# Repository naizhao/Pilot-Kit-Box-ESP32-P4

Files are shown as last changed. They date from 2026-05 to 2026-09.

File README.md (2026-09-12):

# Pilot Kit Box (ESP32-P4 Edition)

<p align="center">
  <strong>开源低成本飞行数据盒子与态势感知设备 | Open-source low-cost flight data box and situational-awareness device</strong><br>
  官方网站 / Official website: <a href="https://air.club">air.club</a><br>
  网页刷机 / Web flasher: <a href="https://updater.pilotkit.app">updater.pilotkit.app</a>
</p>

> ## ⚠️ 免责声明 / Disclaimer
>
> 本设备及其固件为**辅助信息工具**，未取得任何适航认证，**不得用作主用或备用
> 导航设备**，也不得用于正式的飞行活动。所显示的位置、高度、航向、交通、
> 导航台和气象等信息可能延迟、错误或缺失，且随时可能中断。一切飞行决策必须
> 以认证机载设备、官方航图与空管指令为准。使用者自行承担全部风险。
>
> This device and its firmware are an **auxiliary information tool only**.
> They are not airworthiness certified and **must not be used as a primary or
> backup navigation source**, nor in any operational flight activity. Position,
> altitude, heading, traffic, navaid and weather information may be delayed,
> incorrect, or missing, and may stop without warning. All flight decisions
> must be based on certified avionics, official charts, and ATC instructions.
> Use entirely at your own risk.

> **分支 `v4`。** 主机是 **Waveshare ESP32-P4-WIFI6-Touch-LCD-4.3** 一体板：
> ST7701 480×800 MIPI-DSI 面板以 PPA 旋转成 800×480 横屏，GT911 触摸，
> P4NRW32 + ESP32-C6。硬件目标是
> [`hardware/expansion-board-v4/`](hardware/expansion-board-v4/) 的 6 层集成
> 扩展板——以 HAT 方式直插载板 2×20 排母，把 1090/978 接收链、GNSS、IMU、
> 气压计和电源整合到一块板上，**自带 1090 接收链，不再需要 RTL-SDR dongle**。
> 每个硬件版本一个分支；`docs/jlc/lcd-2.4in-8pin/` 与下文 2.4 寸载板内容
> 保留为 v0.8.0 历史 PCB 参考，不代表本分支的当前接线。
>
> **Branch `v4`.** Host board: **Waveshare ESP32-P4-WIFI6-Touch-LCD-4.3**.
> The hardware target is the 6-layer integrated expansion board in
> [`hardware/expansion-board-v4/`](hardware/expansion-board-v4/), which stacks
> onto the carrier's 2×20 header and folds the 1090/978 receive chains, GNSS,
> IMU, barometer, and power onto one board — **no RTL-SDR dongle required**.
> One branch per hardware revision.

## 硬件版本与分支 / Hardware Versions & Branches

项目包含**硬件（扩展板）**与**软件（固件）**两条相互独立的版本线：

- **硬件**按板代走分支：`v1` → `v2` → `v3` → `v4`，每代一个分支；
- **固件**按发布标签走：`v0.5.0` / `v0.6.0` / `v0.8.0`（见 Releases），
  在任何硬件分支上发布，与板代无关。

The project has **two independent version lines**: the **hardware (expansion
boards)** evolves through branches `v1` → `v2` → `v3` → `v4` (one branch per
board generation), while the **firmware** releases via tags `v0.5.0` /
`v0.6.0` / `v0.8.0` (see Releases), cut from whichever hardware branch.

### 四代扩展板 / Four Generations

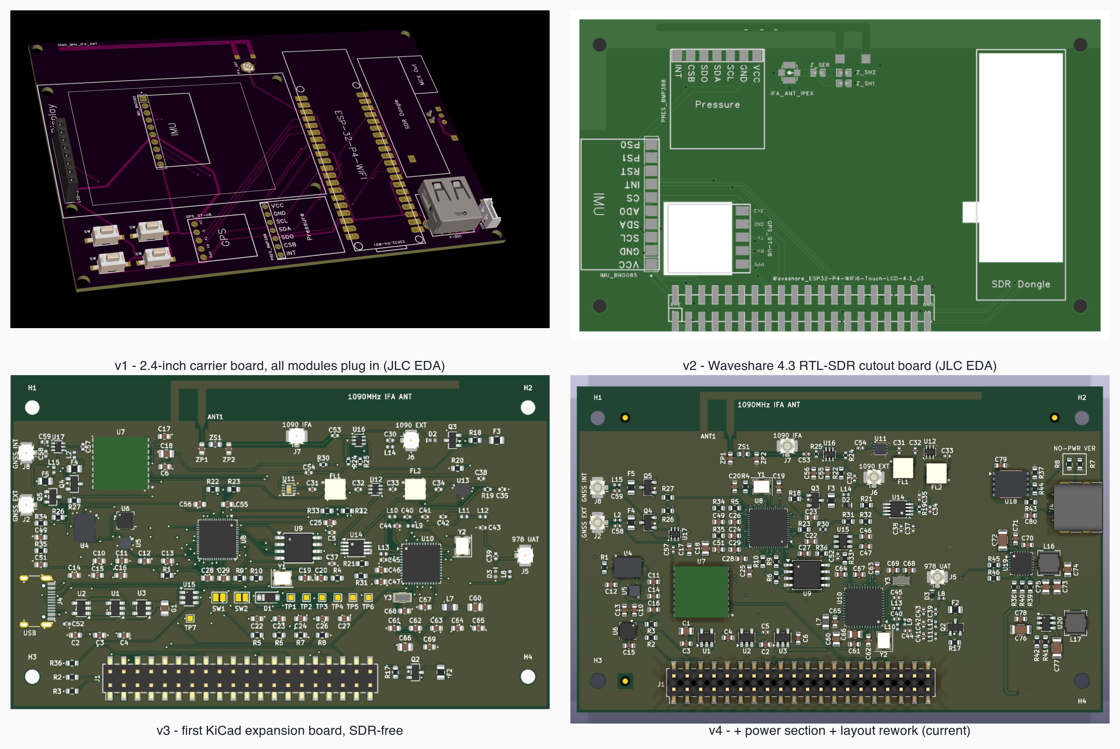
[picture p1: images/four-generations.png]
Pilot Kit Box 扩展板四代同堂：v1 2.4寸大板、v2 Waveshare 4.3 SDR RTL 镂空板、v3 首个 KiCad 完整扩展板、v4 加电源版


每个硬件版本一个分支，从旧到新 / One branch per hardware revision, oldest first:

| 分支 Branch | 板子 / Board | EDA | 说明 / Notes |
|---|---|---|---|
| [`v1`](https://github.com/naizhao/Pilot-Kit-Box-ESP32-P4/tree/v1) | 2.4 寸大板：所有模块插在板上，含板载 1090 天线版 / 2.4-inch carrier, all modules plug in, on-board 1090 antenna revision | 嘉立创 EDA | 与 `main` 同源（v0.8.0 时代）/ same lineage as `main` (v0.8.0 era) |
| [`v2`](https://github.com/naizhao/Pilot-Kit-Box-ESP32-P4/tree/v2) | 微雪 4.3 屏配套的 SDR RTL 镂空板 / RTL-SDR cutout board for the Waveshare 4.3 | 嘉立创 EDA | 归档：仅打样 Gerber + 说明，EDA 源不在 git / archive: fabrication Gerbers only, EDA sources not in git |
| [`v3`](https://github.com/naizhao/Pilot-Kit-Box-ESP32-P4/tree/v3) | 脱离 SDR 的完整扩展板（KiCad、expansion-board 命名起点）/ SDR-free integrated expansion board (KiCad, where the expansion-board naming starts) | KiCad | 归档：只维护 v3 硬件，不携带 v4 / archived: v3 hardware only |
| [`v4`](https://github.com/naizhao/Pilot-Kit-Box-ESP32-P4/tree/v4) | v3 + 电源部分 + 布局优化（当前硬件目标）/ v3 plus power section and layout rework (current target) | KiCad | **本分支 / this branch**；公开区只留最终结果 / public tree keeps final results only |

## 项目概览 / Overview

**Pilot Kit Box** 是一个开源、低成本、便携式的飞行数据盒子和航空态势感知设备，可与 [Pilot Kit](https://air.club) 深度结合使用，也可以作为独立设备运行。

如果你熟悉 Stratux、Sentry、Garmin GDL 系列或 uAvionix ping 这类便携式 ADS-B / 飞行数据盒子，可以把 Pilot Kit Box 理解成一个更开放、更低成本、可自己搭建和二次开发的替代方案。它面向飞行员、飞行学员、飞行爱好者以及通航开发者，用常见硬件完成飞行记录、姿态显示、周边交通接收和后续数据分析。

它的核心价值不是单纯“看天上有哪些飞机”，而是帮助用户低成本记录、理解和管理自己的飞行数据。它可以随飞机一起使用，记录每一次飞行中的关键数据，用于飞行日志、回放、分享和分析；也可以接收附近飞机公开广播的 ADS-B / Mode-S 信号，在本机屏幕上显示周边交通信息。

你可以把它理解成一个“飞行员自己的小型数据记录与接收盒子”：它既能独立工作，也能和 Pilot Kit 紧密结合；并已支持通过标准航空数据格式（GDL90 over BLE）与 Garmin Pilot、ForeFlight 等第三方 EFB 软件配合使用。

Pilot Kit Box can work as a standalone device or integrate closely with [Pilot Kit](https://air.club). If you know products such as Stratux, Sentry, Garmin GDL, or uAvionix ping, Pilot Kit Box is best understood as a more open, lower-cost, builder-friendly flight data and ADS-B box. It is intended for pilots, student pilots, aviation enthusiasts, and general-aviation developers who want local flight recording, attitude display, nearby traffic reception, and data they can later review or share.

The main point is not just watching aircraft overhead. Pilot Kit Box is meant to help users record, understand, and manage their own flying at a much lower cost. It can record each flight for logs, replay, sharing, and analysis; it can also receive public ADS-B / Mode-S broadcasts from nearby aircraft and show surrounding traffic on the built-in display.

Think of it as a pilot's own small flight data recorder and receiver: it can run independently, integrate tightly with Pilot Kit, and already speaks standard aviation data (GDL90 over BLE) for third-party EFB apps such as Garmin Pilot and ForeFlight.

## 使用场景 / Use Cases

Pilot Kit Box 的核心用途是：让普通飞行员、飞行学员和飞行爱好者，也能用较低成本拥有一个自己的飞行记录和态势感知盒子。

Pilot Kit Box is designed to give pilots, student pilots, and aviation enthusiasts an affordable personal flight recording and situational-awareness box.

- 记录自己的每一次飞行，为飞行日志、回放、分享和分析提供数据基础。<br>Record each flight as source data for logs, replay, sharing, and analysis.
- 在本机屏幕上显示姿态、航向、高度、速度、垂直速度等飞行状态信息。<br>Display flight state such as attitude, heading, altitude, speed, and vertical speed on the local screen.
- 接收附近飞机的 ADS-B / Mode-S 广播，显示周边交通、航班号、国家、航司、机型和注册号等信息。<br>Receive nearby ADS-B / Mode-S traffic and show callsign, country, airline, aircraft type, and registration when known.
- 在没有互联网的情况下，本地接收和记录航空数据，而不是依赖在线航班网站。<br>Receive and record aviation data locally without relying on online flight-tracking websites.
- 与 Pilot Kit 软件结合，把硬件采集到的数据用于更完整的飞行记录、回放、分析和分享体验。<br>Use captured device data with Pilot Kit for richer flight records, replay, analysis, and sharing.
- 作为通用飞行数据盒子继续扩展；GDL90 已通过 BLE 输出（Ownship / Traffic / Heartbeat / Raw），Wi-Fi GDL90 在路线图中，目标是连接 Garmin Pilot、ForeFlight 等 EFB。<br>Continue evolving as a general-purpose flight data box; GDL90 already ships over BLE (ownship / traffic / heartbeat / raw), with Wi-Fi GDL90 on the roadmap targeting EFBs such as Garmin Pilot and ForeFlight.
- 给通航、航电、嵌入式和 SDR 爱好者提供一个完整、开源、可学习的参考实现。<br>Provide a complete open-source reference for general aviation, avionics, embedded systems, and SDR builders.

## 为什么要做这个设备 / Why Build This

市面上已经有 Stratux、Sentry、Garmin GDL、uAvionix ping 等便携式 ADS-B 接收器、飞行记录盒子和通航辅助设备，但很多产品要么价格较高，要么生态相对封闭，要么不方便用户理解、修改和扩展内部的数据链路。

Pilot Kit Box 想解决的是这个问题：

- **低成本**：用 ESP32-P4、v3/v4 扩展板（自带 1090 接收链，无需 RTL-SDR dongle）、屏幕、IMU 和常见电源模块，做出一个普通用户也能负担的飞行数据盒子。
- **通用性**：它不是只能配合某一个 App 使用的封闭硬件；它可以独立使用，也可以面向标准航空数据接口继续扩展。
- **与 Pilot Kit 紧密结合**：Pilot Kit 可以充分利用 Box 采集的数据，提供更完整的飞行记录、回放、分析和分享能力。
- **本地记录**：飞行数据可以在设备本地记录，为飞行复盘和个人飞行档案提供基础。
- **态势感知**：除了记录自己的飞行，也能接收附近 ADS-B / Mode-S 交通，帮助理解周边空域情况。
- **开源透明**：从 SDR 接收、ADS-B 解码、状态聚合、屏幕显示到数据库维护，整个链路都可以检查、修改和复现。
- **可继续扩展**：它可以是一个低成本替代方案，也可以作为移动端、云端分析、EFB 集成、Wi-Fi GDL90 输出和硬件外壳迭代的平台。

Portable ADS-B receivers and flight data boxes already exist, including Stratux, Sentry, Garmin GDL, and uAvionix ping. Many of them are effective products, but they can be expensive, relatively closed, or hard for users to inspect, modify, and extend.

Pilot Kit Box focuses on:

- **Low cost**: ESP32-P4, the v3/v4 expansion board (its own 1090 MHz receive chain — no RTL-SDR dongle), display, IMU, and common power modules keep the hardware approachable.
- **General-purpose use**: it is not locked to one app; it can run on its own and already speaks standard aviation data interfaces (GDL90).
- **Tight Pilot Kit integration**: Pilot Kit can use Box data for richer flight records, replay, analysis, and sharing.
- **Local recording**: flight data can be recorded on the device for review and personal archives.
- **Situational awareness**: the same box can receive nearby ADS-B / Mode-S traffic and help users understand surrounding airspace.
- **Open implementation**: SDR reception, ADS-B decoding, state fusion, display rendering, and database maintenance are all inspectable and reproducible.
- **Room to grow**: it can be a low-cost alternative today and a platform for mobile apps, cloud analysis, EFB integration, Wi-Fi GDL90 output, and enclosure iterations later.

## 技术概览 / Technical Overview

当前 ESP32-P4 版本把传统依赖 Linux 板卡的 ADS-B 接收链路压缩到单片机 + RTOS 架构。1090 MHz 接收由 **v3/v4 扩展板**完成：板载接收链（QPL9547 LNA + TA0970A SAW + AD8313 对数检波 + TLV3501 比较器）把脉冲馈给 RP2040，RP2040 以 PIO+DMA 捕获双沿、重建 56/112-bit Mode-S 帧，再经 921600 UART 送 ESP32-P4 做 CRC 过滤、CPR 定位融合、飞机状态聚合，并通过 BLE GATT、串口以及 LittleFS / MicroSD 文件输出给移动端或调试工具。（早期 v1/v2 载板走 P4 原生 USB 2.0 HS 驱动 RTL-SDR dongle 的路径已退役，固件与组件树均不再包含该代码。）

The ESP32-P4 edition removes the Linux SBC from the ADS-B path. The 1090 MHz receive chain lives on the **v3/v4 expansion boards**: the onboard chain (QPL9547 LNA + TA0970A SAW + AD8313 log detector + TLV3501 comparator) feeds pulses to an RP2040, which captures dual edges via PIO+DMA, rebuilds 56/112-bit Mode S frames, and ships them to the ESP32-P4 over a 921600-baud UART for CRC filtering, CPR position fusion, and per-aircraft state aggregation, published over BLE GATT, serial output, and LittleFS or MicroSD logs. (The early v1/v2-carrier path — the P4 driving an RTL-SDR dongle over native USB 2.0 HS — is retired; neither the firmware nor the component tree still carries it.)

## 安全与适航边界 / Safety And Certification Boundary

Pilot Kit Box 是开源原型和态势感知设备，当前仓库没有 FAA、EASA、CAAC 或其他适航/TSO 认证。它不能作为主飞行仪表、备用飞行仪表、导航源或防撞系统使用；任何飞行决策必须以认证航电、机载仪表、目视观察和适用法规为准。

Pilot Kit Box is an open-source prototype and situational-awareness device. This repository does not represent FAA, EASA, CAAC, TSO, or other airworthiness certification. Do not use it as a primary flight instrument, backup flight instrument, navigation source, or collision-avoidance system; flight decisions must remain based on certified avionics, installed instruments, visual scan, and applicable regulations.

## 当前状态 / Current Status

截至 **2026-07-29**，当前 4.3 寸固件已经覆盖 ADS-B 接收与解码、BLE
GDL90 分发、GPS 定位与 RMC 授时、BMP388 气压高度、LittleFS/MicroSD
记录、ST7701 MIPI-DSI 横屏显示、GT911 触摸导航、交通雷达、ADS-B 列表、
实时诊断、本地航空识别数据库和 BNO085 姿态融合。

As of **2026-07-29**, the current 4.3-inch firmware includes ADS-B reception
and decode, BLE GDL90 distribution, GPS positioning and RMC time sync,
BMP388 barometric altitude, LittleFS/MicroSD recording, an ST7701 MIPI-DSI
landscape display, GT911 touch navigation, traffic radar, ADS-B list, live
diagnostics, local aviation identity databases, and BNO085 attitude fusion.

### `v0.8.0` 发布重点 / Release Highlights

- 新增 360° 交通雷达、PFD HSI 前方交通叠加和统一 own-ship 航向决策。<br>Adds the 360-degree traffic radar, forward-traffic HSI overlay, and unified own-ship heading selection.
- 新增 BMP388 气压高度/升降率、可调 QNH，以及可滚动实时 DIAG 页面。<br>Adds BMP388 altitude/vertical speed, adjustable QNH, and the scrollable live DIAG page.
- 增强 GT-U8 GPS/北斗诊断和 RMC 授时，并通过 BLE 输出 GDL90 Ownship Report；GPIO50 PPS 已被固件消费，用于时间锁定判定（fix 有效 + PPS <2 s + NMEA <5 s）；把该新鲜度接入生产时间服务仍是后续任务。<br>Expands GT-U8 GPS/BeiDou diagnostics, RMC time sync, and BLE GDL90 Ownship Report output; GPIO50 PPS is now consumed for the time-lock status (valid fix + PPS <2 s + NMEA <5 s); wiring that freshness into the production time service remains a follow-up.
- 新增 MicroSD 探测、Flash/MicroSD 日志切换、约 1 GiB 轮转保留和受保护格式化。<br>Adds MicroSD detection, Flash/MicroSD log selection, about 1 GiB rotation retention, and guarded formatting.
- 完成 2.4 寸载板、板载 1090 MHz IFA 天线、3D 打印外壳和面板原型实物验证。<br>Documents the fabricated 2.4-inch carrier, on-board 1090 MHz IFA antenna, printed enclosure, and faceplate prototype.

## 核心特性 / Features

| 功能 | Feature | 状态 / Status |
|---|---|---|
| ESP32-P4 + FreeRTOS 固件，无 Linux 启动链路 | ESP32-P4 + FreeRTOS firmware, no Linux boot chain | 已实现 / Implemented |
| RP2040 拓展板双沿捕获 1090 MHz ADS-B，921600 UART 送 P4 解码（USB RTL-SDR 路径已退役） | RP2040 add-on dual-edge capture of 1090 MHz ADS-B, raw frames to the P4 over 921600-baud UART (USB RTL-SDR path retired) | 已实现 / Implemented |
| `adsb_lnk` 任务：921600 UART 收 RP2040 帧、CRC 过滤后进 CPR/融合与记录链 | `adsb_lnk` task: RP2040 frames over 921600-baud UART, CRC-filtered into the CPR/fusion and recording chain | 已实现 / Implemented |
| dump1090 派生 Mode-S 解码、CRC 过滤、CPR 全球定位 | dump1090-derived Mode-S decode, CRC filtering, CPR global position decode | 已实现 / Implemented |
| 最多同时跟踪 64 个 ADS-B / Mode-S 目标，并聚合呼号、高度、位置、速度、垂直速度、应答机码和机型信息 | Tracks up to 64 ADS-B / Mode-S targets at once, aggregating callsign, altitude, position, velocity, vertical rate, squawk, and aircraft type | 已实现 / Implemented |
| UART、LittleFS / MicroSD 轮转文件、BLE raw ts-line 三路记录输出 | UART, rotating LittleFS/MicroSD files, and BLE raw ts-line output | 已实现 / Implemented |
| BLE GATT：GDL90 Ownship、Traffic、Heartbeat、Raw、Time Sync | BLE GATT: GDL90 Ownship, Traffic, Heartbeat, Raw, and Time Sync | 已实现 / Implemented |
| iOS Current Time Service 自动校时，Android/跨平台可写 Time Sync | iOS Current Time Service auto-sync, Android/cross-platform Time Sync writes | 已实现 / Implemented |
| GT-U8 GPS / 北斗定位、RMC 授时、GPS own-ship 兜底 | GT-U8 GPS/BeiDou positioning, RMC time sync, GPS own-ship fallback | 已实现；PPS 已接入时间锁定 / Implemented; PPS consumed for time-lock status |
| BMP388 气压高度和升降率，QNH 可调 | BMP388 barometric altitude and vertical speed with adjustable QNH | 已实现 / Implemented |
| ST7701 480×800 MIPI-DSI 面板，PPA 转为 800×480 横屏，双 DPI buffer | ST7701 480×800 MIPI-DSI panel, PPA-transformed to 800×480 landscape with dual DPI buffers | 已实现 / Implemented |
| G1000 风格 PFD：姿态、航向/HSI、高度带、GS/VS、ADS-B 数量 | G1000-style PFD: attitude, heading/HSI, altitude tape, GS/VS, ADS-B count | 已实现 / Implemented |
| 360° 交通雷达：航向朝上/北向上、2/5/10/20 NM、目标选择和相对高度 | 360° traffic radar: heading-up/north-up, 2/5/10/20 NM, target selection, relative altitude | 已实现 / Implemented |
| PFD HSI 前方交通叠加和后方目标计数 | Forward-traffic overlay and aft-target count on the PFD HSI | 已实现 / Implemented |
| ADS-B 列表页：ICAO、呼号、国家、ALT、SPD、HDG、VS、SQK、TYPE 和详情面板 | ADS-B list page: ICAO, callsign, country, ALT, SPD, HDG, VS, SQK, TYPE, and detail pane | 已实现 / Implemented |
| 本地航空识别数据库：航司 ICAO/IATA、运营人名称、ICAO24 国家、注册号、机型和型号 | Local aviation identity databases: airline ICAO/IATA, operator name, ICAO24 country, registration, type, and model | 已实现 / Implemented |
| BNO085 100 Hz 姿态融合、校准向导和导航网格长按“调平”持久化 | BNO085 100 Hz attitude fusion, calibration wizard, and persistent nav-grid Level action | 已实现 / Implemented |
| Settings / About / Diagnostics / Compass Calibration 中英文 UI，配置写入 NVS | English/Chinese Settings, About, Diagnostics, and Compass Calibration UI with NVS persistence | 已实现 / Implemented |
| Noto Sans SC 字形生成、中文 LCD 锐化曲线、英文硬像素路径 | Noto Sans SC glyph generation, sharpened CJK LCD alpha curve, crisp English bitmap path | 已实现 / Implemented |
| GT911 触摸 FAB 打开全屏导航网格直接切页（两页 10 项可翻页），FAB 可拖动记忆，详情页三路返回 | GT911 touch FAB opens a full-screen nav grid (10 items on two swipeable pages), remembers FAB position, and provides three detail-page back paths | 已实现 / Implemented |
| RP2040 链路健康监测：HELLO 心跳、链路停滞检测，诊断页显示收帧/坏 CRC | RP2040 link health: HELLO heartbeat and stalled-link detection; the diag page shows link rx/bad-CRC | 已实现 / Implemented |

## 硬件清单 / Hardware Bill of Materials

### 硬件预览 / Hardware Preview

| PFD / Primary Flight Display | ADS-B LIST / Aircraft List |
|---|---|
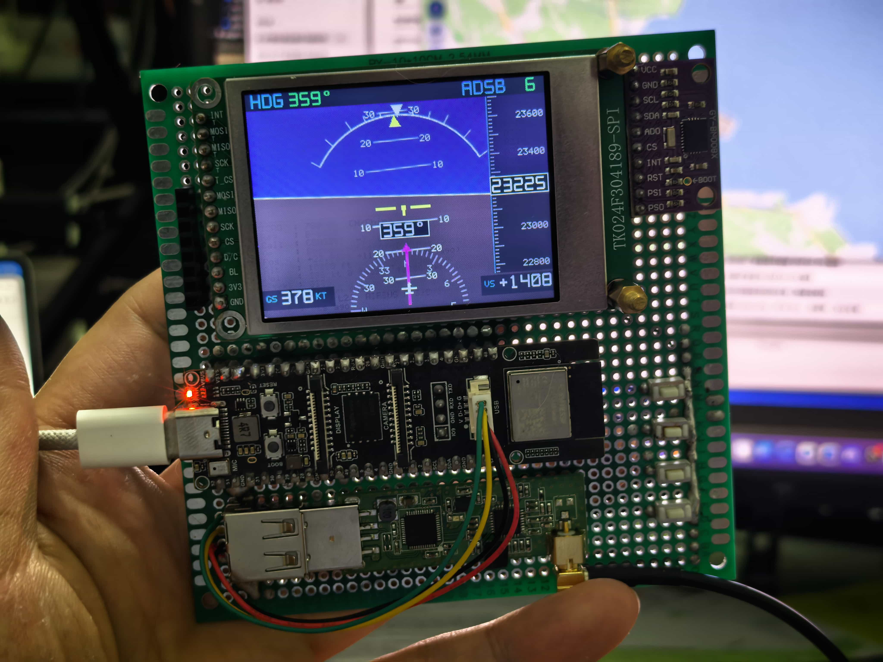
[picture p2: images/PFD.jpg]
Pilot Kit Box PFD hardware preview
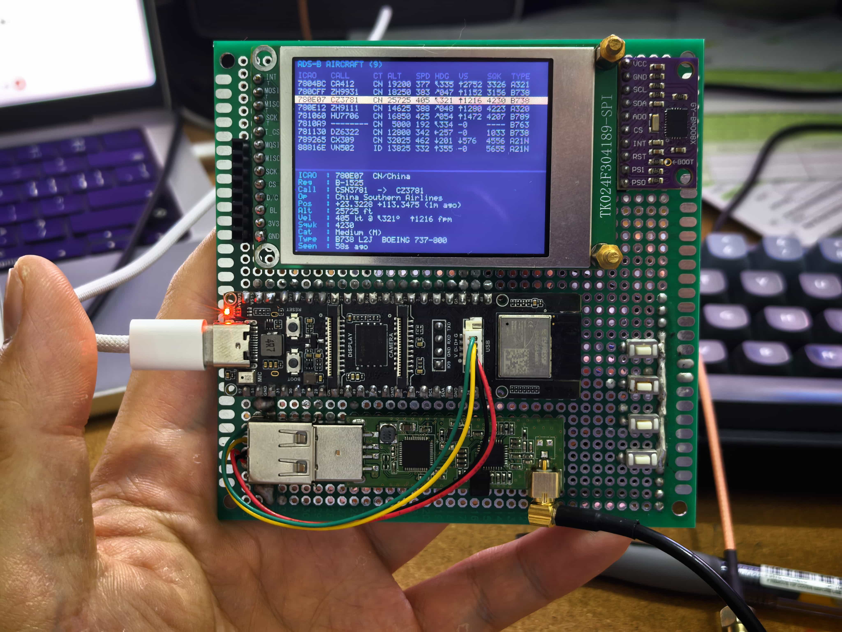
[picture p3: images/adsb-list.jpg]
Pilot Kit Box ADS-B list hardware preview
|  |  |

| 交通雷达 / Traffic Radar | 完整原型 / Finished Prototype |
|---|---|
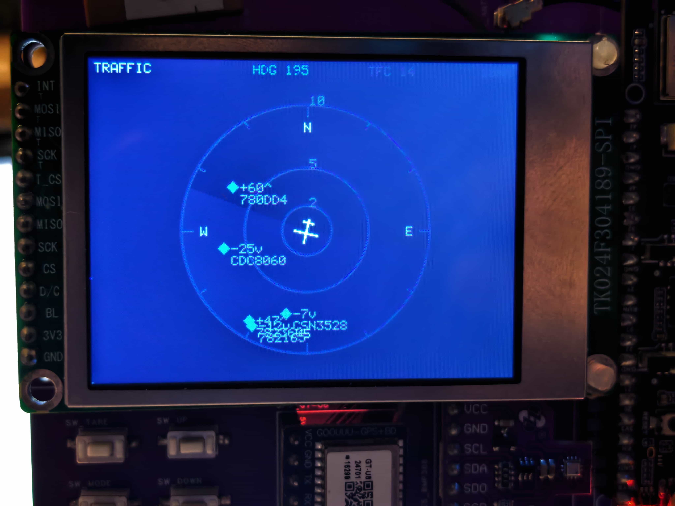
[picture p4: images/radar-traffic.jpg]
Pilot Kit Box traffic radar running on hardware
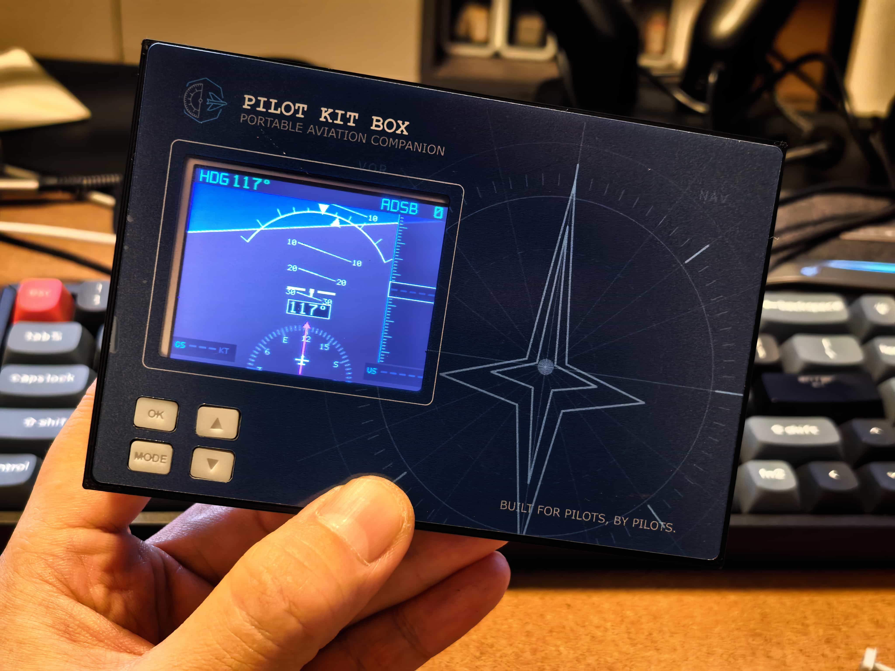
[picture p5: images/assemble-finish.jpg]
Finished Pilot Kit Box prototype with printed faceplate
|  |  |

### v1 载板与外壳实物 / v1 Carrier Board & Enclosure

以下 2.4 寸载板（**v1 大板**，嘉立创 EDA 绘制，见
[`v1` 分支](https://github.com/naizhao/Pilot-Kit-Box-ESP32-P4/tree/v1)）照片
与设计文件记录的是 v0.8.0 历史原型。它们不是当前 Rev1.2 4.3 寸板的装配或
接线指南。历史立创EDA 工程见
[`docs/jlc/lcd-2.4in-8pin/`](docs/jlc/lcd-2.4in-8pin/)。

The following 2.4-inch carrier photos and design files document the
**v1 board** (the legacy v0.8.0 prototype, drawn in JLC EDA — see the
[`v1` branch](https://github.com/naizhao/Pilot-Kit-Box-ESP32-P4/tree/v1)).
They are not assembly or wiring instructions for the current Rev1.2 4.3-inch
board. Legacy EasyEDA sources:
[`docs/jlc/lcd-2.4in-8pin/`](docs/jlc/lcd-2.4in-8pin/).

| 载板 3D · 正面 / PCB 3D Front | 载板 3D · 背面（电池面）/ PCB 3D Back (battery side) |
|---|---|
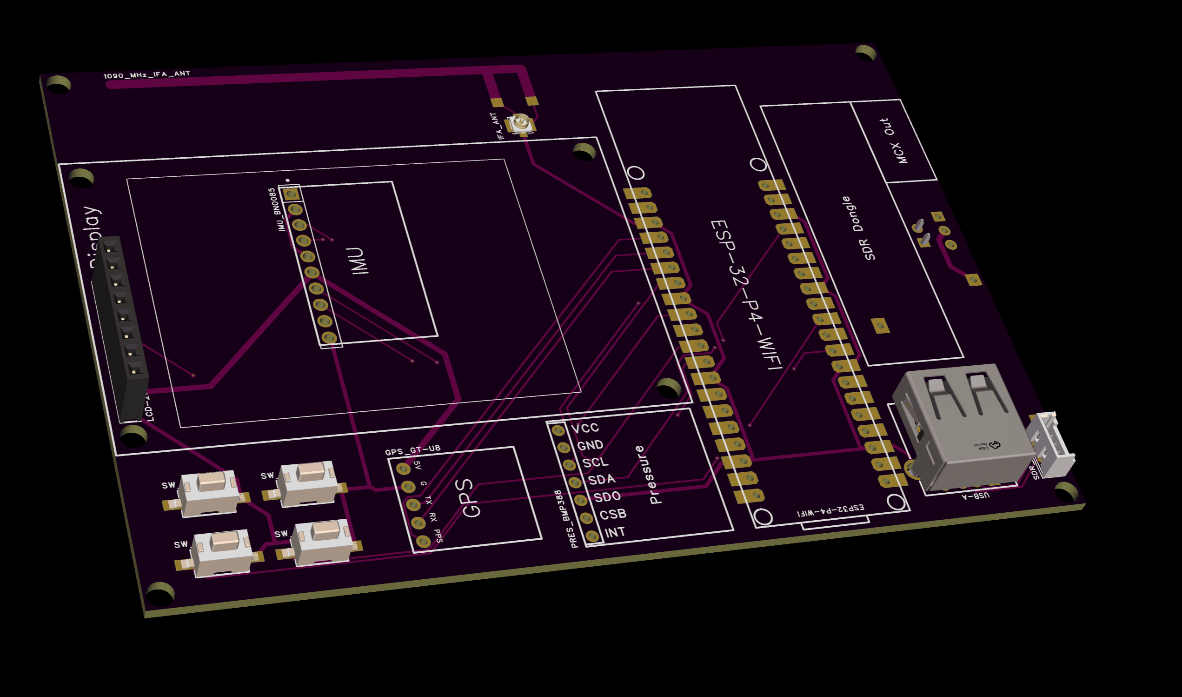
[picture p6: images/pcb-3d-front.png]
Pilot Kit Box carrier board 3D front
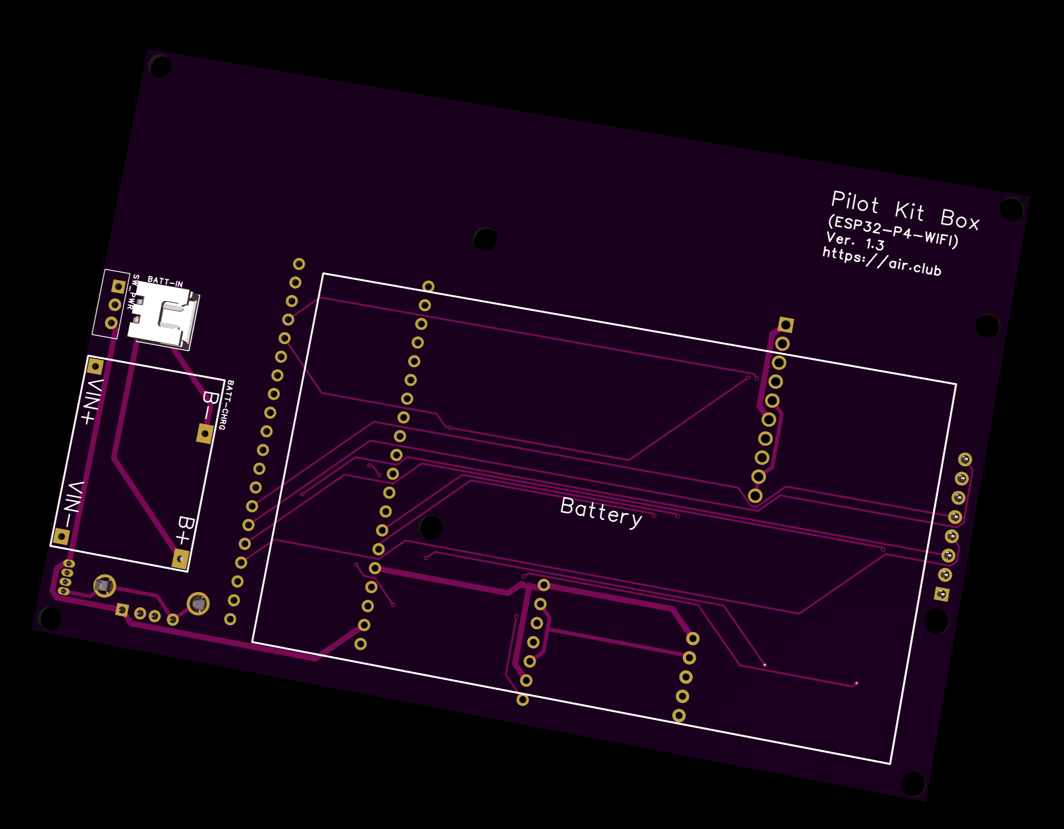
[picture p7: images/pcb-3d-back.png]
Pilot Kit Box carrier board 3D back, battery side
|  |  |

| 布线 · 顶层 / Routing Top | 布线 · 底层 / Routing Bottom |
|---|---|
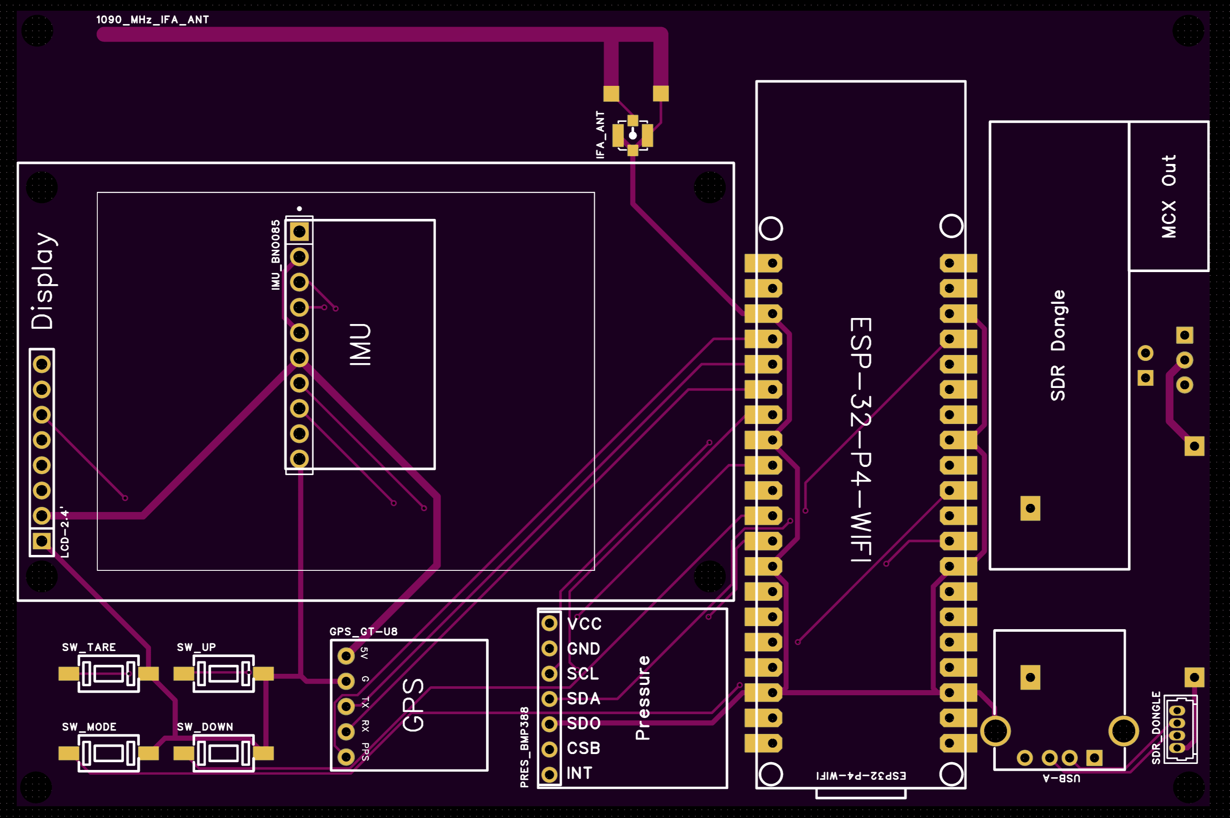
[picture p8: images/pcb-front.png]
Pilot Kit Box carrier board routing top
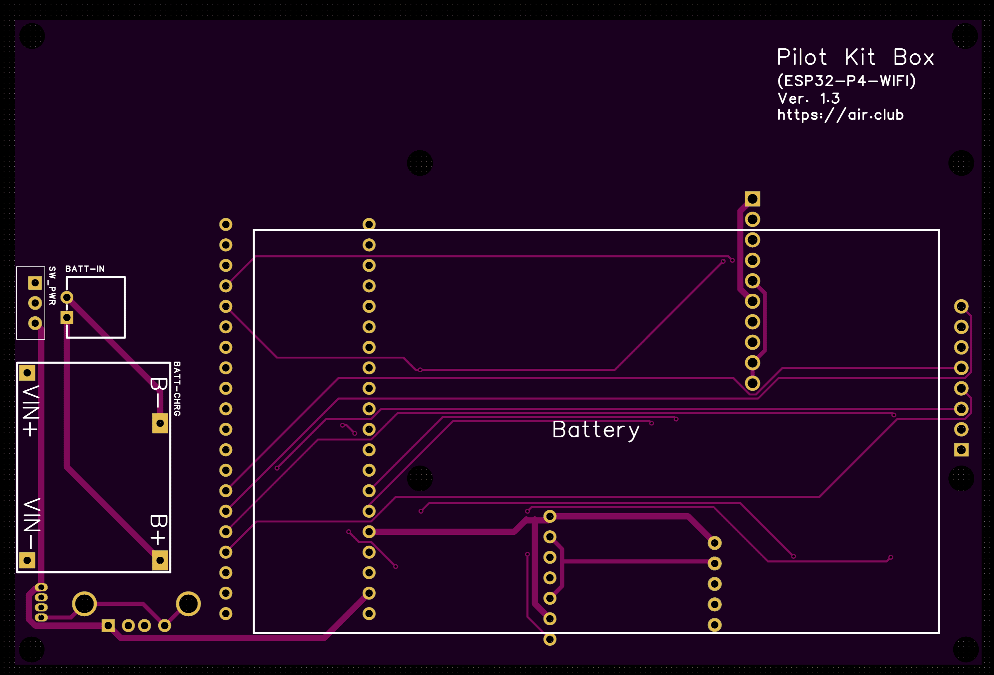
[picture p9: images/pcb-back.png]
Pilot Kit Box carrier board routing bottom
|  |  |

| 外壳面板 / Enclosure Faceplate | 外壳成品 / Enclosure |
|---|---|
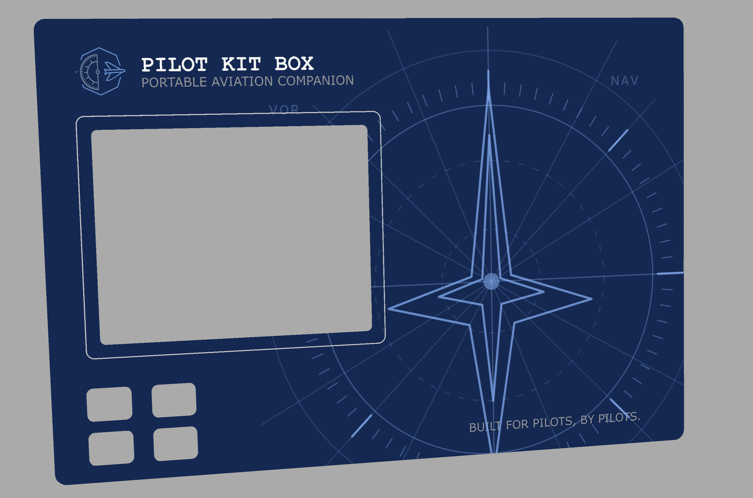
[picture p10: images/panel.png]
Pilot Kit Box enclosure faceplate
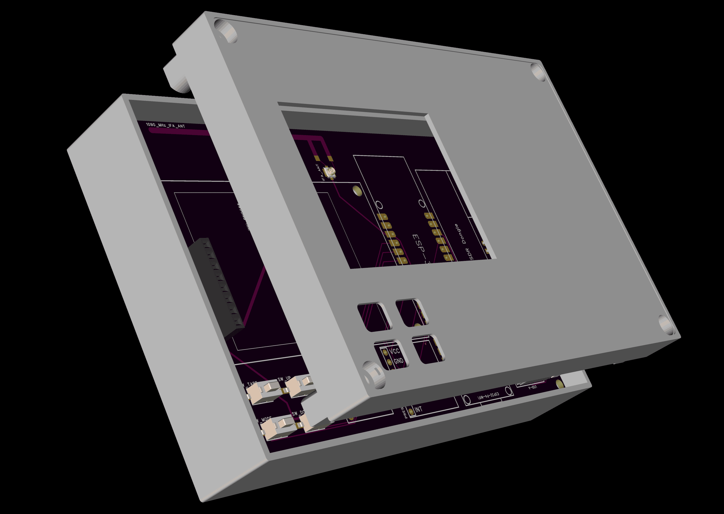
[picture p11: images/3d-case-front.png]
Pilot Kit Box enclosure with carrier board
|  |  |

### 实物打样与装配 / Fabrication & Assembly

| 载板实物 / Fabricated Carrier PCB | 载板装配 / Assembled Carrier |
|---|---|
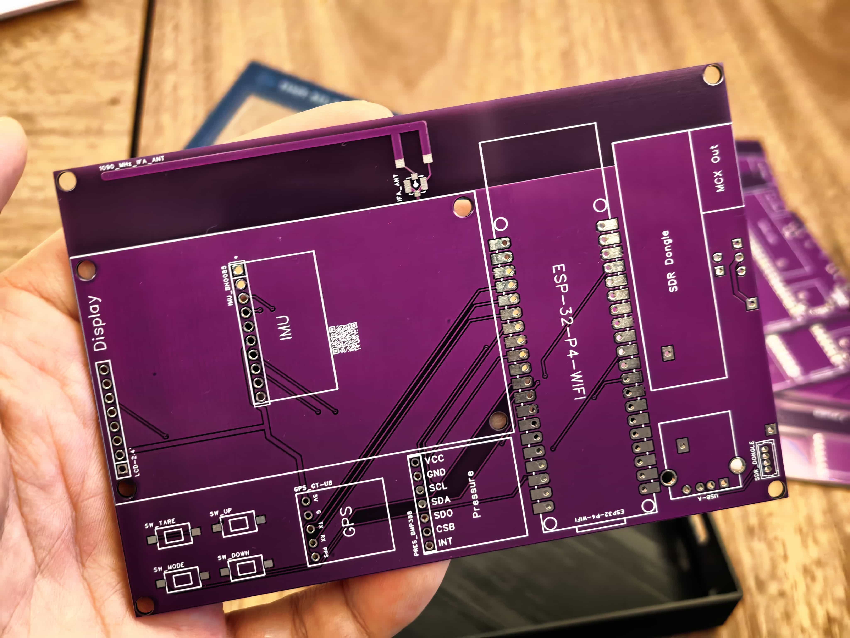
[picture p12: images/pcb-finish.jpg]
Fabricated Pilot Kit Box carrier PCB
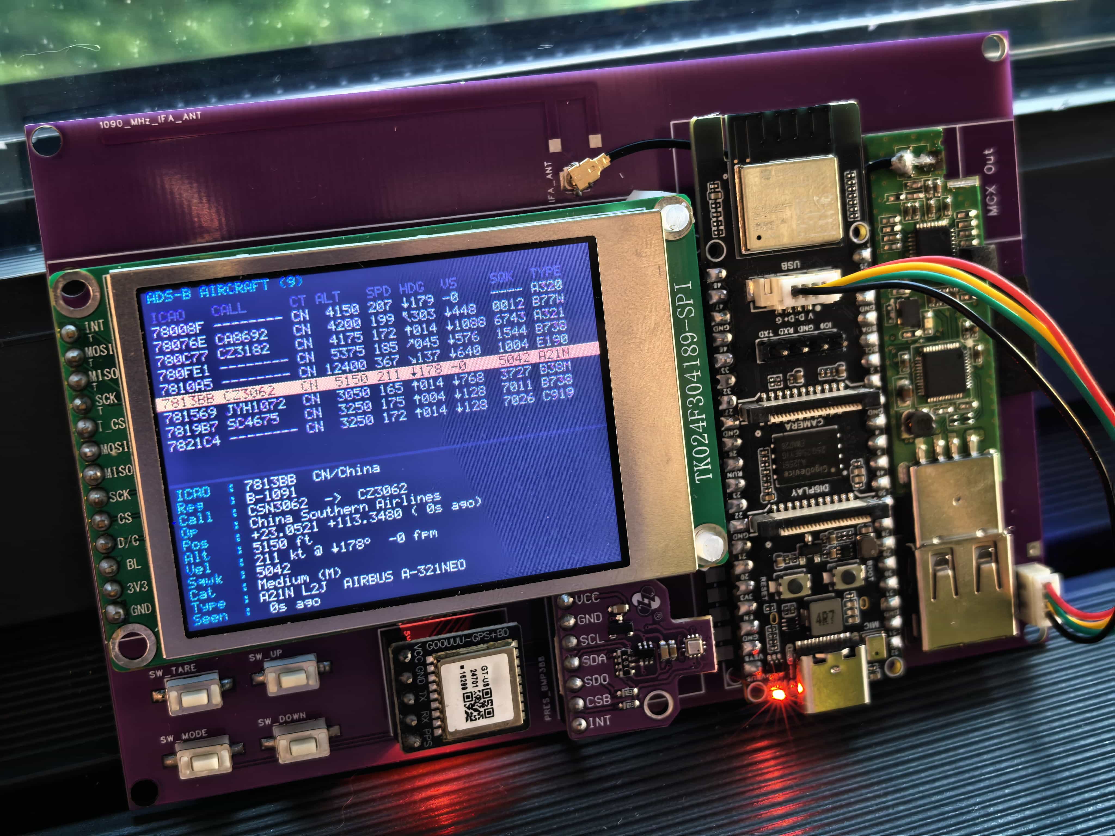
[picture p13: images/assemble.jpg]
Assembled Pilot Kit Box carrier with display and modules
|  |  |

| 3D 打印外壳 / Printed Enclosure | 面板装配完成 / Finished Faceplate Assembly |
|---|---|
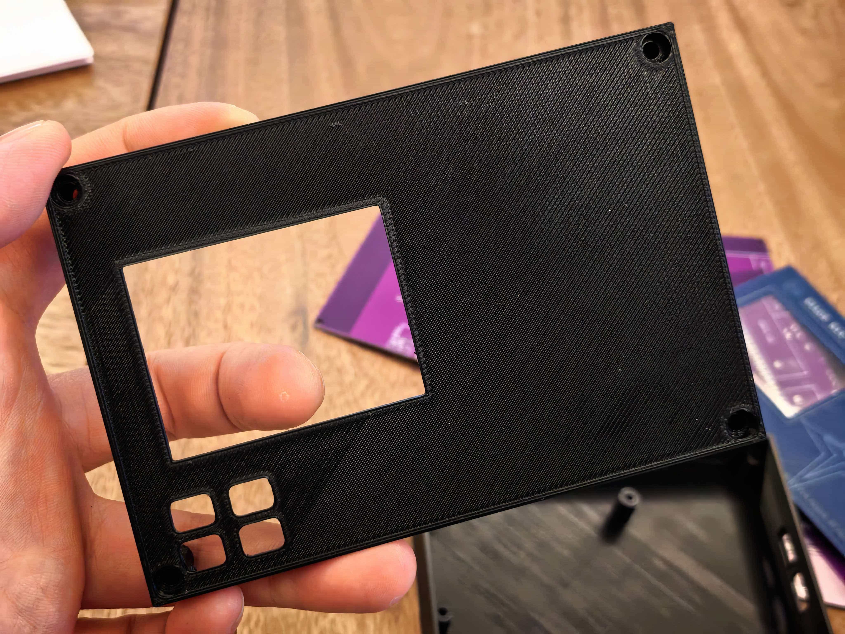
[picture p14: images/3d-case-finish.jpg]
3D printed Pilot Kit Box enclosure
|  | Completed Pilot Kit Box prototype |

### 必备硬件 / Required

| 硬件 | Hardware | 说明 / Notes |
|---|---|---|
| Waveshare ESP32-P4-WIFI6-Touch-LCD-4.3 | Waveshare ESP32-P4-WIFI6-Touch-LCD-4.3 | Rev1.2 一体板：ESP32-P4NRW32、32 MB NOR、32 MB PSRAM、ESP32-C6、ST7701 和 GT911。<br>Rev1.2 integrated board with ESP32-P4NRW32, 32 MB NOR, 32 MB PSRAM, ESP32-C6, ST7701, and GT911. |
| USB-C 数据线 | USB-C data cable | 用于 P4 烧录、串口监视和供电；必须是数据线。<br>Used for P4 flashing, serial monitoring, and power; it must support data, not charge-only. |
| 1090 MHz 前端：v3/v4 RP2040 扩展板 | 1090 MHz front-end: v3/v4 RP2040 expansion board | 板载接收链（QPL9547 LNA + TA0970A SAW + AD8313 + TLV3501）与 RP2040 解码，天线接扩展板天线接口（V4 为板载 ANT1）。<br>Onboard receive chain (QPL9547 LNA + TA0970A SAW + AD8313 + TLV3501) with RP2040 decode; the antenna connects to the expansion board's antenna port (V4: onboard ANT1). |
| RTL-SDR FC0013 USB Dongle + OTG 转接头（仅 v1/v2 历史） | RTL-SDR FC0013 USB dongle + OTG adapter (v1/v2 historical only) | 已退役路径的遗留硬件：USB RTL-SDR 支持已从固件与组件树移除，仅旧载板存量用户参考。<br>Legacy hardware of a retired path: USB RTL-SDR support has been removed from the firmware and component tree; kept for reference by legacy v1/v2-carrier users only. |
| 1090 MHz ADS-B 天线 | 1090 MHz ADS-B antenna | 接扩展板天线接口；实际接收距离强依赖天线位置和供电噪声。<br>Connects to the expansion board's antenna port; real-world range depends strongly on antenna placement and power noise. |
| GY-BN008X / BNO085 IMU 模块 | GY-BN008X / BNO085 IMU module | I2C0：SDA GPIO7、SCL GPIO8；RST GPIO28；INT GPIO34（轮询）；AD0 接 GND，地址 `0x4A`。<br>I2C0: SDA GPIO7, SCL GPIO8, RST GPIO28, INT GPIO34 (polled), AD0 grounded for `0x4A`. |
| GT-U8（ATGM336H）GPS/北斗模块 | GT-U8 (ATGM336H) GPS/BeiDou module | UART1 115200 8N1：P4 TX GPIO49 → 模块 RXD，模块 TXD → P4 RX GPIO51；GPIO50 PPS 已被固件消费（1 Hz 快照用于时间锁定状态，授时服务接线为后续任务）。<br>UART1 at 115200 8N1: P4 TX GPIO49 to module RXD, module TXD to P4 RX GPIO51; the GPIO50 PPS input is consumed by firmware (1 Hz snapshot feeds the time-lock status; time-service wiring remains a follow-up). |
| BMP388 气压计模块 | BMP388 barometer module | I2C0：SDA GPIO7、SCL GPIO8；SDO 接 GND，地址 `0x76`；INT 接 GPIO31 但固件轮询。提供气压高度与升降率。<br>I2C0: SDA GPIO7, SCL GPIO8, SDO grounded for `0x76`; INT wired to GPIO31 but the driver polls. Supplies pressure altitude and vertical speed. |

### 集成扩展板 V4.0（研发中）/ Integrated Expansion Board V4.0 (In Development)

| 正面 / Top | 背面 / Bottom |
|---|---|
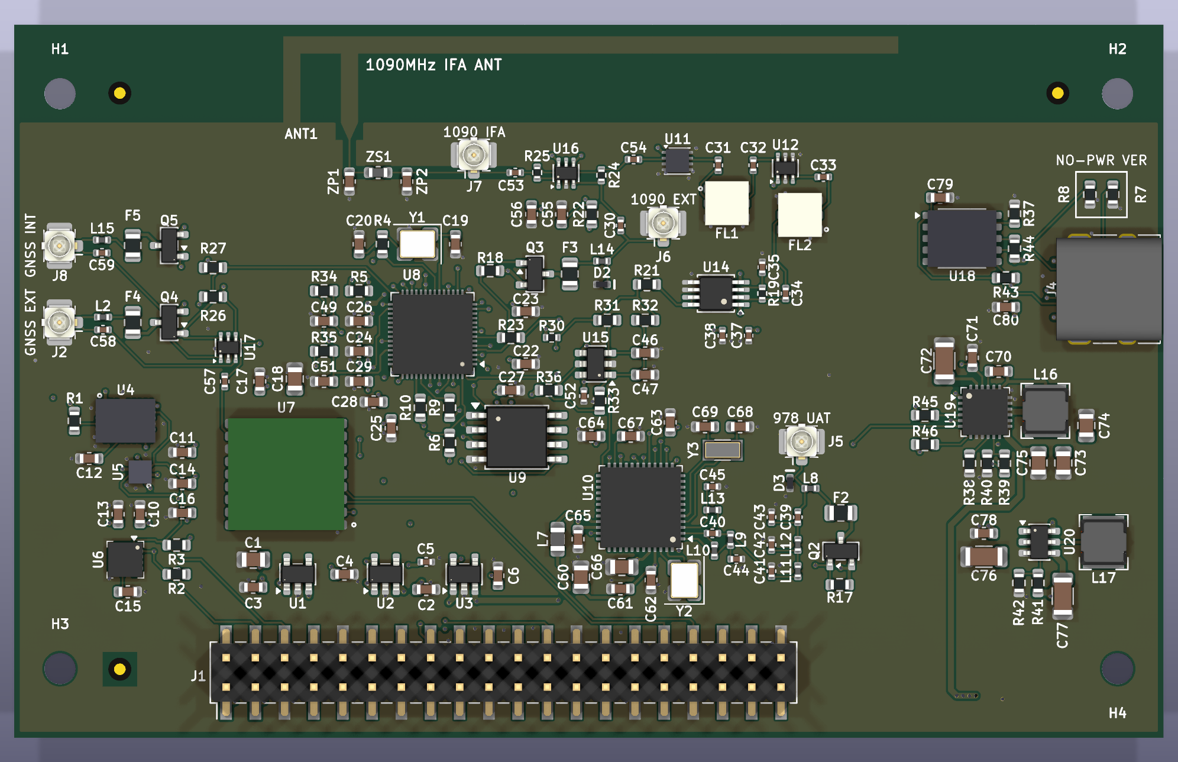
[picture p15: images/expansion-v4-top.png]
Pilot Kit avionics expansion board V4.0, top side
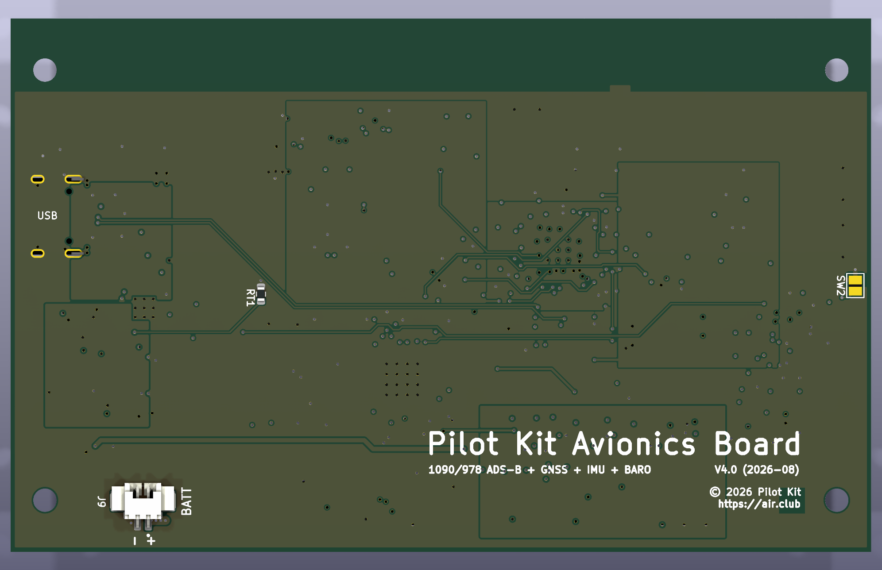
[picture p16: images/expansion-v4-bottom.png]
Pilot Kit avionics expansion board V4.0, bottom side
|  |  |

上面「必备硬件」里的 BNO085、GT-U8 和 BMP388 三个分立模块，正在被一块
**集成扩展板**取代。它以 HAT 方式直插 Waveshare 载板的 2×20 排母，
把接收链、传感器和电源整合到一块 6 层板上，并**自带 1090 MHz 接收链，
不再需要 RTL-SDR dongle**（该 USB 路径已随 v1/v2 载板退役，固件与组件树
均不再包含）。工程、文档与制造包在
[`hardware/expansion-board-v4/`](hardware/expansion-board-v4/)（该目录的
[README](hardware/expansion-board-v4/README.md) 是双语的）。

The three discrete modules listed under Required Hardware above (BNO085,
GT-U8, BMP388) are being replaced by a single **integrated expansion
board**. It stacks onto the Waveshare carrier's 2×20 header as a HAT and folds
the receive chains, sensors, and power into one 6-layer PCB — including its own
**1090 MHz receive chain, so no RTL-SDR dongle is needed** (that USB path is
retired along with the v1/v2 carriers; neither the firmware nor the component
tree still carries it).

| 项目 | Item | 规格 / Specification |
|---|---|---|
| 板框 / 层数 | Outline / layers | 100.1 × 62.1 mm，6 层（JLC06161H-3313），L1→In1 介质 0.0994 mm，50Ω 微带 0.15 mm<br>100.1 × 62.1 mm, 6 layers; 0.0994 mm L1→In1 dielectric, 0.15 mm 50Ω microstrip |
| 1090 MHz 接收 | 1090 MHz receive | QPL9547 LNA + TA0970A SAW + BGA2817 + AD8313 对数检波 + TLV3501 比较器 → RP2040 PIO 解码<br>QPL9547 LNA, TA0970A SAW, BGA2817, AD8313 log detector, TLV3501 comparator into an RP2040 PIO decoder |
| 978 MHz UAT | 978 MHz UAT | CC1312R1F3RGZR Sub-GHz 收发器 + 差分 LC 匹配<br>CC1312R1F3RGZR sub-GHz transceiver with differential LC matching |
| 天线 | Antennas | 板载 1090 IFA（PCB 铜箔，π 网络可调）+ 三个 U.FL 外接口（1090 / 978 / GNSS）<br>On-board 1090 IFA (PCB copper, tunable π network) plus three U.FL ports (1090 / 978 / GNSS) |
| 传感器 | Sensors | ATGM336H-6N-74 GNSS、BNO085 IMU、BMP388 气压计、QMC5883P 磁力计<br>ATGM336H-6N-74 GNSS, BNO085 IMU, BMP388 barometer, QMC5883P magnetometer |
| 电源（选贴）| Power (optional) | CH224K PD 诱骗 9V + SY6970 充电/电量计 + SY7069 升压 5V + 单节锂电<br>CH224K PD sink at 9V, SY6970 charger/fuel gauge, SY7069 5V boost, single-cell Li-po |
| 规模 | Scale | 177 个位置、386 个过孔（全部 ≥0.3 mm 钻孔）<br>177 placements, 386 vias (all ≥0.3 mm drill) |

**状态**：布局布线完成，DRC 零违例、未连通 0，Gerber/钻孔可导出；**尚未打样**。
板载 IFA 天线已落板但**未经实测调谐**，必须装盒后用 VNA 校准，
见 [`BOM_IFA_TUNING.md`](hardware/expansion-board-v4/BOM_IFA_TUNING.md)。

**Status**: layout and routing complete with zero DRC violations and zero
unconnected nets; Gerbers and drill files export cleanly. **Not yet fabricated.**
The on-board IFA antenna is laid out but **not empirically tuned** — it requires
VNA calibration in the final enclosure.

| 文档 | Document | 内容 / Contents |
|---|---|---|
| [`PINMAP.md`](hardware/expansion-board-v4/PINMAP.md) | 权威引脚/网络映射 / Authoritative pin and net map |
| [`ASSEMBLY.md`](hardware/expansion-board-v4/ASSEMBLY.md) | 手工贴片点位清单（脚本从板子生成）/ Hand-assembly placement list, generated from the board |
| [`CHECKLIST.md`](hardware/expansion-board-v4/CHECKLIST.md) | 按位号贴片核对表（另附 .xlsx/.pdf 打印版）/ Per-reference placement checklist (with printable .xlsx/.pdf) |
| [`VARIANTS.md`](hardware/expansion-board-v4/VARIANTS.md) | 带电源 / 不带电源两个选贴版本 / Powered and unpowered assembly variants |
| [`SELECTIVE_PLACEMENT.md`](hardware/expansion-board-v4/SELECTIVE_PLACEMENT.md) | 贴装分组与互斥规则（贴错会烧板）/ Placement groups and mutex rules |
| [`BOM_PURCHASE-zh_CN.md`](hardware/expansion-board-v4/BOM_PURCHASE-zh_CN.md) | 权威采购清单（脚本从网表生成）/ Authoritative purchasing list, generated from the netlist |
| [`BOM_IFA_TUNING.md`](hardware/expansion-board-v4/BOM_IFA_TUNING.md) | IFA 调谐备料与装盒 VNA 调试流程 / Antenna tuning kit and the in-enclosure VNA procedure |
| [`BASEBOARD_REF.md`](hardware/expansion-board-v4/BASEBOARD_REF.md) | 载板机械参数基准 / Mechanical reference for the Waveshare carrier |

以上文档均提供英文正名版与 `-zh_CN.md` 简体中文版；完整索引见
[`hardware/expansion-board-v4/README.md`](hardware/expansion-board-v4/README.md)。
Each ships as an English canonical file plus a `-zh_CN.md` Simplified-Chinese
counterpart; see the v4 README for the full index.

### 硬件成本参考 / Hardware Cost Reference

以 **v4 扩展板**为准（两片用量、含备损；完整料号与选型依据见
[`BOM_PURCHASE-zh_CN.md`](hardware/expansion-board-v4/BOM_PURCHASE-zh_CN.md)）：

| 项目 / Item | 金额 / Cost | 说明 / Notes |
|---|---:|---|
| 嘉立创 SMT 贴装（`full` 方案，2 片）<br>JLC SMT assembly (`full` profile, 2 boards) | **实付 ¥51.06**<br>**¥51.06 paid** | 46 种 / 126 件 / 252 焊点；工程费、焊盘费、换料费优惠券后为 0<br>46 parts / 126 placements; setup & fees waived by coupons |
| 手贴件：贵价射频 IC、电源 IC、B 面件等<br>Hand-placed: pricier RF/Power ICs, B-side parts | 另计<br>extra | 数量与料号见 `BOM_PURCHASE.md` 中未列入嘉立创 SMT 贴装（手贴）的行；按 `VARIANTS.md` 的选贴规则取用<br>see the hand-placed (non-SMT) rows in `BOM_PURCHASE.md`; quantities per `VARIANTS.md` |
| 6 层 PCB 打样（JLC06161H-3313，含盘中孔工艺）<br>6-layer PCB fab (JLC06161H-3313, via-in-pad) | 另计<br>extra | 叠层与阻抗依据 [`PCB_STACKUP_IMPEDANCE.md`](hardware/PCB_STACKUP_IMPEDANCE.md) / see stackup doc |
| 外壳 / Enclosure | 另计<br>extra | 3D 打印（嘉立创） / 3D printed (JLC) |

> 2026-07-31 之前的 2.4 寸载板（v1）时代旧成本表已随 **`v1` 分支**归档，可在
> 该分支的本文件历史中查阅。The legacy v1-era cost table is archived with the
> `v1` branch (see that branch's history of this file).

### 首次设置或选配 / Setup And Optional

| 硬件 | Hardware | 说明 / Notes |
|---|---|---|
| USB-UART 转接器 | USB-UART adapter | 每块新 Waveshare 板首次烧 ESP32-C6 hosted slave 固件时需要；详见 [`docs/hardware/c6_slave_firmware.md`](docs/hardware/c6_slave_firmware.md)。<br>Required once per fresh Waveshare board to flash the ESP32-C6 hosted slave firmware; see [`docs/hardware/c6_slave_firmware.md`](docs/hardware/c6_slave_firmware.md). |
| 杜邦线 / 短接线 | Jumper wires / shorting wire | 连接 IMU/GPS/BMP388，以及 C6 首次烧录时把 P1-3 IO9 短接到 GND。<br>Used for IMU/GPS/BMP388 wiring and shorting P1-3 IO9 to GND during first-time C6 flashing. |
| 5V 2A / 2.4A Type-C 口充电模块 | 5V 2A / 2.4A Type-C charging module | 电池供电版本使用；给系统提供稳定 5V 输入。<br>Used in battery-powered builds to provide a stable 5V system input. |
| 3.7V 10000mAh 锂电池 | 3.7V 10000mAh lithium battery | 便携版本的电源选项；容量可按外壳和续航目标调整。<br>Portable power option; capacity can be adjusted for enclosure size and endurance target. |
| 5 V 外部供电 | External 5 V power | 1090 MHz 接收链（LNA 偏置 + RP2040 扩展板）功耗数百 mA，电脑 USB 口供电不稳时建议使用更可靠供电。<br>The 1090 MHz receive chain (LNA bias + RP2040 expansion board) draws a few hundred mA; use a reliable 5V supply if a computer USB port is unstable. |
| 外壳、支架、屏蔽和固定件 | Enclosure, mounts, shielding, fixtures | 当前仓库主要维护固件和接线文档，机械结构可按实际安装补充。<br>This repository mainly maintains firmware and wiring docs; mechanical parts should be adapted to the actual installation. |

### 板载资源 / On-board Resources

- ESP32-C6-MINI-1 通过 SDIO 作为 Wi-Fi 6 / BLE 5 协处理器；当前固件使用 BLE。
- MicroSD 卡座已启用；设置页可在 10 MiB LittleFS 与 MicroSD 记录之间切换，并支持卡状态诊断和二次确认格式化。
- CH343P USB-UART 桥用于 P4 烧录和串口监视。
- ES8311 音频 codec、麦克风、扬声器功放为板载资源，当前航电路径尚未使用。

- The ESP32-C6-MINI-1 is connected over SDIO as the Wi-Fi 6 / BLE 5 co-processor; the current firmware uses BLE.
- The MicroSD slot is active; Settings can select 10 MiB LittleFS or MicroSD recording, with card diagnostics and guarded formatting.
- The CH343P USB-UART bridge handles P4 flashing and serial monitoring.
- The ES8311 codec, microphone, and speaker amplifier are on-board resources, not currently used by the avionics path.

## 目录结构 / Repository Structure

| 路径 | Path | 内容 / Contents |
|---|---|---|
| `firmware/` | `firmware/` | ESP-IDF v6.0.1 固件工程 / ESP-IDF v6.0.1 firmware project |
| `firmware/main/` | `firmware/main/` | 应用层 C 源码和编进固件的识别数据表（航司代码、ICAO24 国家段） / Application C sources and the identity tables compiled into the firmware (airline codes, ICAO24 countries) |
| `firmware/components/` | `firmware/components/` | 工程内组件（adsb_link 编解码、LCD 驱动等） / In-tree components (adsb_link codec, LCD drivers, …) |
| `firmware/scripts/` | `firmware/scripts/` | 字体、数据库和测试脚本 / Font, database, and test scripts |
| `hardware/expansion-board-v4/` | `hardware/expansion-board-v4/` | **当前硬件目标**：6 层集成扩展板 KiCad 工程、生成/校验脚本与装配文档 / **Current hardware target**: 6-layer integrated expansion board — KiCad project, generator/verification scripts, and assembly docs |
| `hardware/expansion-board-v3/` | `hardware/expansion-board-v3/` | 上一版 4 层扩展板（v3.2 已打样，已归档；仍用于固件调试）——见其 [README](hardware/expansion-board-v3/README.md) / Previous 4-layer expansion board (v3.2 fabricated, **archived**; still used for firmware debugging) — see its [README](hardware/expansion-board-v3/README.md) |
| `datafiles/` | `datafiles/` | SD 卡离线数据工作区：`data/` 机型库与航空数据 bin、`maps/` 底图包（内容不进 git，见 `datafiles/README.md`） / microSD offline data workspace: `data/` aircraft and aeronautical binaries, `maps/` basemap packs (contents gitignored, see `datafiles/README.md`) |
| `docs/` | `docs/` | 构建、协议、架构、用户和硬件文档 / Build, protocol, architecture, user, and hardware docs |
| `web/flasher/` | `web/flasher/` | ESP Web Tools 网页刷机页面 / ESP Web Tools web flasher |
| `tools/firmware_release/` | `tools/firmware_release/` | 固件发布打包工具 / Firmware release packaging tools |

## 航空识别数据库 / Aviation Identity Databases

盒子用三类本地识别数据库，把 ADS-B / Mode-S 中收到的 ICAO24 地址和呼号显示为更容易核对的航空信息。它们不是航班计划、航线、时刻表或实时联网数据。机型库放在 microSD 卡上（`/sdcard/aero/pk_actdb.bin`），更新只需把新文件拷进卡里，不用刷固件；航司代码表和 ICAO24 国家地址段仍编进固件镜像，随固件更新。

The box uses three local identity databases so ICAO24 addresses and ADS-B callsigns can be rendered as operationally useful aviation information. These are not flight-plan, route, timetable, or live network databases. The aircraft database lives on the microSD card (`/sdcard/aero/pk_actdb.bin`) and is refreshed by copying a new file onto the card — no reflash. The airline code table and ICAO24 country ranges are still compiled into the firmware image and ship with firmware updates.

| 数据库 | Database | 用途 / Purpose | 仓库位置 / Repository Location | 更新脚本 / Update Script |
|---|---|---|---|---|
| 飞机 ICAO24 数据库 | Aircraft ICAO24 database | ICAO24 -> 注册号、ICAO 机型代码、型号名称、Doc 8643 技术描述；当前快照约 574k 条记录、8.21 MB，随 SD 卡分发（`/sdcard/aero/pk_actdb.bin`），不再嵌入固件，开机后懒加载进 PSRAM，无卡时相关字段显示 `---`。<br>ICAO24 -> registration, ICAO type code, model name, and Doc 8643 descriptor; the current snapshot is about 574k records / 8.21 MB, shipped on the SD card (`/sdcard/aero/pk_actdb.bin`) rather than embedded in the firmware, and lazily loaded into PSRAM after boot; without a card those fields render as `---`. | `datafiles/data/pk_actdb.bin`（见 `datafiles/README.md`）, `firmware/main/aircraft_db.c`, `firmware/main/aircraft_db_reader.c`, `firmware/main/aircraft_db.h` | `firmware/scripts/gen_aircraft_db.py` |
| 航司代码表 | Airline code table | ADS-B 呼号前三位 ICAO 航司代码 -> IATA 代码和运营人名称，用于把 `CSN1234` 等显示为更常见的航班号形式。<br>ADS-B callsign ICAO prefix -> IATA code and operator name, used to render callsigns such as `CSN1234` in a more familiar form. | `firmware/main/airline_codes.c`, `firmware/main/airline_codes.h` | `firmware/scripts/gen_airline_codes.py --update-source` |
| ICAO24 国家地址段 | ICAO24 country ranges | ICAO24 地址段 -> ISO 3166-1 alpha-2 国家/地区代码和名称，用于 ADS-B LIST 的 CT 列和详情面板。<br>ICAO24 address range -> ISO 3166-1 alpha-2 country/region code and name for the ADS-B LIST CT column and detail pane. | `firmware/main/icao_country.c`, `firmware/main/icao_country.h` | `firmware/scripts/gen_icao_country.py` |

维护流程详见 / Maintenance workflow: [`docs/database_maintenance.md`](docs/database_maintenance.md) / [`docs/database_maintenance-zh_CN.md`](docs/database_maintenance-zh_CN.md)。

## 快速开始 / Quick Start

| 我想做什么 | What I want | English | 中文 |
|---|---|---|---|
| 从零安装、编译、烧录 | Set up, build, and flash from scratch | [`docs/BUILD.md`](docs/BUILD.md) | [`docs/BUILD-zh_CN.md`](docs/BUILD-zh_CN.md) |
| 用网页更新 ESP32-P4 固件 | Update ESP32-P4 firmware from browser | [updater.pilotkit.app](https://updater.pilotkit.app) | [updater.pilotkit.app](https://updater.pilotkit.app) |
| 发布维护者固件包 | Publish a maintainer firmware release | [`docs/firmware_update.md`](docs/firmware_update.md) | [`docs/firmware_update-zh_CN.md`](docs/firmware_update-zh_CN.md) |
| 更新扩展板 RP2040 固件（Release 附 UF2） | Update the RP2040 expansion-board firmware (UF2 shipped with releases) | [`docs/firmware_update.md`](docs/firmware_update.md) | [`docs/firmware_update-zh_CN.md`](docs/firmware_update-zh_CN.md) |
| 看运行时任务和数据流 | Understand runtime tasks and data flow | [`docs/architecture.md`](docs/architecture.md) | [`docs/architecture-zh_CN.md`](docs/architecture-zh_CN.md) |
| 调整 sdkconfig | Tune sdkconfig options | [`docs/configuration.md`](docs/configuration.md) | [`docs/configuration-zh_CN.md`](docs/configuration-zh_CN.md) |
| 集成移动端 BLE | Integrate a mobile BLE client | [`docs/ble_protocol.md`](docs/ble_protocol.md) | [`docs/ble_protocol-zh_CN.md`](docs/ble_protocol-zh_CN.md) |
| 维护航空识别数据库 | Maintain the aviation identity databases | [`docs/database_maintenance.md`](docs/database_maintenance.md) | [`docs/database_maintenance-zh_CN.md`](docs/database_maintenance-zh_CN.md) |
| 使用 4.3 寸触摸 UI 和 PFD | Use the 4.3-inch touch UI and PFD | [`docs/user_guide.md`](docs/user_guide.md) | [`docs/user_guide-zh_CN.md`](docs/user_guide-zh_CN.md) |
| 接 IMU、GPS、BMP388 或 J3 扩展（v1/v2 的 RTL-SDR 路径已退役） | Wire IMU, GPS, BMP388, or J3 expansion (v1/v2 RTL-SDR path retired) | [`docs/hardware/board_pinout.md`](docs/hardware/board_pinout.md) | [`docs/hardware/board_pinout-zh_CN.md`](docs/hardware/board_pinout-zh_CN.md) |
| 装配 / 复刻 V4 扩展板 | Assemble or replicate the V4 expansion board | [`hardware/expansion-board-v4/README.md`](hardware/expansion-board-v4/README.md) | 同左（各文档附 `-zh_CN.md` 中文版）/ same (each doc has a `-zh_CN.md` counterpart) |
| 首次烧 ESP32-C6 slave 固件 | Flash ESP32-C6 slave firmware once | [`docs/hardware/c6_slave_firmware.md`](docs/hardware/c6_slave_firmware.md) | [`docs/hardware/c6_slave_firmware-zh_CN.md`](docs/hardware/c6_slave_firmware-zh_CN.md) |
| 浏览全部文档语言覆盖 | Browse all docs and language coverage | [`docs/README.md`](docs/README.md) | [`docs/README-zh_CN.md`](docs/README-zh_CN.md) |

最短上手路径 / Minimal path:

```bash
# 1. 安装 ESP-IDF v6.0.1 / Install ESP-IDF v6.0.1
curl -L https://dl.espressif.com/dl/eim/eim-installer.sh | bash

# 2. 拉代码 / Clone the repository
git clone --recursive https://github.com/naizhao/Pilot-Kit-Box-ESP32-P4.git
cd Pilot-Kit-Box-ESP32-P4/firmware

# 3. 激活 IDF 并构建 / Activate IDF and build
source ~/.espressif/tools/activate_idf_v6.0.1.sh
./build.sh set-target esp32p4

# 3b. 选扩展板板系（默认 v4；v3 板必须改。小版本只是修订，看板号第一位）
#     Select the expansion board family (default v4; switch it for a v3 board)
#     ./build.sh menuconfig  ->  Pilot Kit Box  ->  Expansion board profile
./build.sh build

# 4. 烧录并监视 / Flash and monitor
./build.sh -p /dev/cu.usbmodem* flash monitor
```

> ⚠️ **板系默认是 v4。** 手上是 v3 板（V3.x）就必须在 `menuconfig` 里改过来——两个板系的传感器贴片角度不同，选错了 PFD 照样有姿态，只是横滚整体偏 90°，桌上看不出来。板号小版本只是修订，看第一位即可。切换与确认步骤见 [`docs/configuration.md`](docs/configuration.md) 第 1 节。
> The board profile defaults to the **v4** family. Switch it for a v3 board: the sensor mounting angles differ, and the wrong profile still renders a live attitude that is simply rolled by 90 degrees.

> 新板如果要启用 BLE，必须先给板载 ESP32-C6 烧一次 hosted slave 固件。If BLE is needed on a fresh board, flash the on-board ESP32-C6 hosted slave firmware once first. See [`docs/BUILD.md`](docs/BUILD.md) section 3.

## 已知限制 / Known Limits

- 当前 GT911 固件只使用第一个触点，未启用五点手势。
- BLE Device Information Service 尚未暴露固件版本；版本目前显示在 boot splash 和 ABOUT 页。
- GDL90 Heartbeat 的 `utc_ok` 位尚未随 GPS/BLE 校时状态更新；客户端应以时间戳值为准。
- Wi-Fi 分发、BLE 配置写特征和 OTA A/B 分区仍是后续工作。
- GDL90 Ownship Report 需要有效 GPS fix 或编译期配置的本机 ICAO；无有效位置时不会发送可信本机位置。
- GPIO50 PPS 已由固件消费：PPS GPIO 中断（1 Hz 快照）与时间锁定状态已实现；授时（settimeofday 级）接线仍为后续任务。
- 当前触摸 UI 没有旧 TARE 十秒工厂重置/DCD 擦除入口。

- The current GT911 firmware consumes only the first contact; five-point gestures are not enabled.
- BLE Device Information Service does not yet expose firmware version; the version is shown on the boot splash and ABOUT page.
- The GDL90 Heartbeat `utc_ok` bit does not yet follow GPS/BLE clock discipline; clients should use the timestamp value.
- Wi-Fi distribution, BLE configuration-write characteristics, and OTA A/B partitions remain future work.
- GDL90 Ownship Report requires a valid GPS fix or a compile-time own-ship ICAO; the firmware does not advertise a trustworthy own position without one.
- The GPIO50 PPS input is now consumed by firmware: a PPS GPIO interrupt (1 Hz snapshot) and the time-lock status are in place; time discipline at the settimeofday level remains a follow-up.
- The touch UI has no equivalent of the former ten-second TARE factory-reset/DCD-wipe gesture.

## 致谢 / Credits

- [`kvhnuke/esp32-rtl-sdr`](https://github.com/kvhnuke/esp32-rtl-sdr) — librtlsdr API 封装参考（历史：该路径已于 2026-09 移除）/ librtlsdr API wrapper reference (historical: that path was removed in 2026-09)
- [`XTR1984/xtrsdr`](https://github.com/XTR1984/xtrsdr) — ESP32 USB DMA 分包与吞吐调优参考（历史：该路径已于 2026-09 移除）/ ESP32 USB DMA transfer tuning reference (historical: that path was removed in 2026-09)
- dump1090 社区实现 — ADS-B / Mode-S 解码算法基础 / ADS-B / Mode-S decode algorithm foundation

## 开源协议 / License

MIT License — 完整条款见 [`LICENSE`](LICENSE)。
Full terms in [`LICENSE`](LICENSE).

硬件设计（`hardware/`）同样以 MIT 发布。其中的 KiCad 工程内嵌了 KiCad 官方库的
封装，那些库是 CC-BY-SA 4.0，但其例外条款明确允许由此制造的板子不受限制使用，
不会传染到你的硬件。

The hardware designs under `hardware/` are released under the same MIT terms.
The KiCad projects embed footprints from the KiCad standard libraries, which are
CC-BY-SA 4.0 with an exception explicitly permitting unrestricted use of boards
produced from them.

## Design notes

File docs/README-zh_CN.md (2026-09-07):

# Pilot Kit Box 文档索引

本目录采用统一语言约定：

- 默认 `*.md` 文档为英文。
- 简体中文译文使用 `-zh_CN.md` 后缀。

项目根目录 README 仍保留中英双语，因为它是公开入口页。`docs/` 下的详细文档按语言拆分，方便读者和工具稳定链接。这个约定适用于公开文档、内部说明和放在 `docs/` 下的计划文件。

## 快速入口

| 主题 | 英文 | 简体中文 | 适用读者 |
|---|---|---|---|
| 构建与烧录 | [`BUILD.md`](BUILD.md) | [`BUILD-zh_CN.md`](BUILD-zh_CN.md) | 首次构建固件的开发者 |
| 配置参考 | [`configuration.md`](configuration.md) | [`configuration-zh_CN.md`](configuration-zh_CN.md) | 固件定制 |
| 固件架构 | [`architecture.md`](architecture.md) | [`architecture-zh_CN.md`](architecture-zh_CN.md) | 固件开发者 |
| BLE 协议 | [`ble_protocol.md`](ble_protocol.md) | [`ble_protocol-zh_CN.md`](ble_protocol-zh_CN.md) | 移动端 / EFB 客户端开发者 |
| 数据库维护 | [`database_maintenance.md`](database_maintenance.md) | [`database_maintenance-zh_CN.md`](database_maintenance-zh_CN.md) | 固件维护者 |
| 用户指南 | [`user_guide.md`](user_guide.md) | [`user_guide-zh_CN.md`](user_guide-zh_CN.md) | 设备使用者 |
| 固件发布与网页刷写 | [`firmware_update.md`](firmware_update.md) | [`firmware_update-zh_CN.md`](firmware_update-zh_CN.md) | 维护者和终端用户 |
| 硬件资料索引 | [`hardware/README.md`](hardware/README.md) | [`hardware/README-zh_CN.md`](hardware/README-zh_CN.md) | 硬件搭建者 |
| 板卡引脚 | [`hardware/board_pinout.md`](hardware/board_pinout.md) | [`hardware/board_pinout-zh_CN.md`](hardware/board_pinout-zh_CN.md) | 硬件开发者 |
| ESP32-C6 slave 烧录 | [`hardware/c6_slave_firmware.md`](hardware/c6_slave_firmware.md) | [`hardware/c6_slave_firmware-zh_CN.md`](hardware/c6_slave_firmware-zh_CN.md) | BLE bring-up |
| 4.3 寸触摸 UX 规格 | [`ux/box-4.3-ux-spec.md`](ux/box-4.3-ux-spec.md) | [`ux/box-4.3-ux-spec-zh_CN.md`](ux/box-4.3-ux-spec-zh_CN.md) | UI / 固件界面实现者 |
| 扩展板 V4（当前硬件目标） | [`../hardware/expansion-board-v4/README.md`](../hardware/expansion-board-v4/README.md) | 同一文件（双语） | 装板 / 复刻者 |

## 当前功能基线

所有公开文档应与以下事实保持一致：

- 安全边界：Pilot Kit Box 不是经过适航认证的航电设备，文档不得把它写成主飞行仪表、备用仪表、导航源或防撞系统。
- 目标开发板是 **Waveshare ESP32-P4-WIFI6-Touch-LCD-4.3**。P4 负责 UI 和存储；
  1090 MHz 解码在扩展板的 RP2040 上；C6 负责 BLE。
- ADS-B 接收：**v3/v4 扩展板**自带 1090 MHz 接收链、由 RP2040 解码。v1/v2 时代
  的 USB RTL-SDR dongle 路径已于 2026-09 移除（历史细节见 git 历史）：当前固件
  只支持扩展板接收链。
- 识别数据库：ICAO24 飞机数据库随 microSD 卡分发，路径 `/sdcard/aero/pk_actdb.bin`（仓库内产物 `datafiles/data/pk_actdb.bin`，读取端 `firmware/main/aircraft_db.c`），更新是拷文件、不是刷固件；`firmware/main/airline_codes.c` 的航司代码表和 `firmware/main/icao_country.c` 的 ICAO24 国家地址段表仍编进固件。
- LCD 是 **4.3 寸 ST7701 480×800 MIPI-DSI 屏**，通过 PPA 作为 800×480 横屏使用；背光 GPIO26、复位 GPIO27、BL_EN GPIO33。
- GT911 触摸与其他设备共用 GPIO7/8 的 I²C0，复位 GPIO23；旧四实体键任务（`button_task.c`）已移出编译。
- IMU 是 **BNO085 / GY-BN008X**，I2C0 使用 GPIO7 / GPIO8，RST GPIO28，地址 `0x4A`；INT 接 GPIO34（J3 pin 28）但驱动轮询。GPIO20 是板载 BAT_ADC。
- 4.3 寸触摸 FAB 打开**全屏导航网格**直接切页：第 1 页 **PFD、交通、地图、
  列表、搜索、记录、工具**，第 2 页 **诊断、设置、关于**；网格底部动作条承载
  长按「调平」。旧的横向 dock 已废弃。
- GT-U8 GPS/北斗、BMP388 气压高度/升降率、交通雷达和 DIAG 实时诊断均已接入运行时；GPIO50 PPS 由固件消费于 GPS「时间锁定」状态（ISR 计数 + 1 Hz 快照判定），接入系统授时为后续任务。
- Settings 可调整语言、QNH、地图朝向、雷达量程和日志后端；MicroSD 支持插拔探测、容量状态和受保护格式化。
- Settings、About、Diagnostics、Compass Calibration 页面已有中英文固件 UI 字符串，配置保存到 NVS。

## 翻译维护规则

新增或更新 `docs/` 下的文档时：

1. 先写或更新英文默认文件。
2. 再新增或更新同路径、同文件名加 `-zh_CN.md` 后缀的简体中文版本。
3. 除非存在语言特定说明，否则两个版本的章节结构和命令示例保持对齐。
4. 面向用户的文档新增后，同步更新本文档索引和根目录 README。
5. 描述座舱相关行为时，必须明确安全和适航认证边界。

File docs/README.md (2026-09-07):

# Pilot Kit Box Documentation Index

This directory uses one language convention:

- The default `*.md` documents are English.
- Simplified Chinese translations use the `-zh_CN.md` suffix.

The root project README remains bilingual because it is the public landing page. Detailed documents under `docs/` are split by language so links are predictable for both readers and tooling. This convention applies to public docs, internal notes, and plan files that live under `docs/`.

## Quick Navigation

| Topic | English | Simplified Chinese | Audience |
|---|---|---|---|
| Build and flash | [`BUILD.md`](BUILD.md) | [`BUILD-zh_CN.md`](BUILD-zh_CN.md) | First-time firmware builders |
| Configuration | [`configuration.md`](configuration.md) | [`configuration-zh_CN.md`](configuration-zh_CN.md) | Firmware customisation |
| Firmware architecture | [`architecture.md`](architecture.md) | [`architecture-zh_CN.md`](architecture-zh_CN.md) | Firmware developers |
| BLE protocol | [`ble_protocol.md`](ble_protocol.md) | [`ble_protocol-zh_CN.md`](ble_protocol-zh_CN.md) | Mobile / EFB client developers |
| Database maintenance | [`database_maintenance.md`](database_maintenance.md) | [`database_maintenance-zh_CN.md`](database_maintenance-zh_CN.md) | Firmware maintainers |
| User guide | [`user_guide.md`](user_guide.md) | [`user_guide-zh_CN.md`](user_guide-zh_CN.md) | Device users |
| Firmware release and web flashing | [`firmware_update.md`](firmware_update.md) | [`firmware_update-zh_CN.md`](firmware_update-zh_CN.md) | Maintainers and end users |
| Hardware reference index | [`hardware/README.md`](hardware/README.md) | [`hardware/README-zh_CN.md`](hardware/README-zh_CN.md) | Hardware builders |
| Board pinout | [`hardware/board_pinout.md`](hardware/board_pinout.md) | [`hardware/board_pinout-zh_CN.md`](hardware/board_pinout-zh_CN.md) | Hardware developers |
| ESP32-C6 slave flashing | [`hardware/c6_slave_firmware.md`](hardware/c6_slave_firmware.md) | [`hardware/c6_slave_firmware-zh_CN.md`](hardware/c6_slave_firmware-zh_CN.md) | BLE bring-up |
| 4.3″ touch UX spec | [`ux/box-4.3-ux-spec.md`](ux/box-4.3-ux-spec.md) | [`ux/box-4.3-ux-spec-zh_CN.md`](ux/box-4.3-ux-spec-zh_CN.md) | UI / firmware UI implementers |
| Expansion board V4 (hardware target) | [`../hardware/expansion-board-v4/README.md`](../hardware/expansion-board-v4/README.md) | same file (bilingual) | Board builders / replicators |

## Current Feature Baseline

All public docs should match this baseline:

- Safety boundary: Pilot Kit Box is not certified avionics and must
  not be documented as a primary instrument, backup instrument,
  navigation source, or collision-avoidance system.
- Target board: **Waveshare ESP32-P4-WIFI6-Touch-LCD-4.3**. The P4 handles UI
  and storage; 1090 MHz decoding runs on the expansion board's RP2040; the C6
  handles BLE.
- ADS-B reception: the **v3/v4 expansion boards** carry an onboard 1090 MHz
  chain decoded by an RP2040. The v1/v2-era USB RTL-SDR dongle path was
  removed (2026-09); see git history for details — current firmware supports
  only the expansion-board chain.
- Identity databases: the ICAO24 aircraft database ships on the microSD card at `/sdcard/aero/pk_actdb.bin` (built into `datafiles/data/pk_actdb.bin`, read by `firmware/main/aircraft_db.c`) and is updated by copying a file, not by reflashing; the airline code table at `firmware/main/airline_codes.c` and the ICAO24 country table at `firmware/main/icao_country.c` are still compiled into the firmware.
- LCD: **4.3-inch ST7701 480x800 MIPI-DSI**, presented as 800x480 landscape through PPA rotation; backlight PWM GPIO26, reset GPIO27, BL_EN GPIO33.
- GT911 touch shares I2C0 on GPIO7/8 and uses GPIO23 reset. The legacy four-button task (`button_task.c`) is excluded from the build.
- IMU: **BNO085 / GY-BN008X**, I2C0 on GPIO7 / GPIO8, RST on GPIO28, address `0x4A`; INT is wired to GPIO34 (J3 pin 28) but the driver polls. GPIO20 is board-fixed BAT_ADC.
- The touch FAB opens the **full-screen nav grid** that directly selects
  **PFD, TRAFFIC, MAP, LIST, SEARCH, LOG, TOOLS** (page 1) and
  **DIAG, SETTINGS, ABOUT** (page 2); the grid's action bar carries the
  long-press Level action. The earlier horizontal dock is retired.
- Navigation and tare actions are exposed through the 4.3-inch touch UI; references to MODE/TARE tact buttons describe the legacy 2.4-inch carrier only.
- GT-U8 GPS/BeiDou, BMP388 altitude/vertical speed, the traffic radar, and live DIAG page are active runtime paths. GPIO50 PPS is consumed by firmware for the `time_locked` status (ISR count + 1 Hz snapshot); wiring it into the production time service remains a follow-up.
- Settings controls language, QNH, map orientation, radar range, and log backend; MicroSD supports insertion/removal detection, capacity status, and guarded formatting.
- Settings, About, Diagnostics, and Compass Calibration have English/Chinese firmware UI strings with configuration persisted through NVS.

## Translation Policy

When adding or updating a document under `docs/`:

1. Write or update the English default file first.
2. Add or update the Simplified Chinese counterpart with the same relative path and `-zh_CN.md` suffix.
3. Keep section names and command snippets aligned unless a language-specific note is necessary.
4. Update this index and the root README if the document is meant for users.
5. Keep safety and certification language explicit when documenting cockpit-facing behavior.

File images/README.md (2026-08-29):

# Image Assets

Chinese version: [`README-zh_CN.md`](README-zh_CN.md)

## 4.3″ Touchscreen UI (`ui-4.3-*.png`)

Rendered by the simulator, **pixel-identical to the real device** — the simulator compiles the very same drawing
modules used in the firmware (`firmware/main/pfd_*.c`, `pk_ui_nav.c`), not a separately drawn mock-up.

All are 800×480, the same as the panel's logical resolution, and can be used directly in the README and on the website.

| Image | Scene |
|---|---|
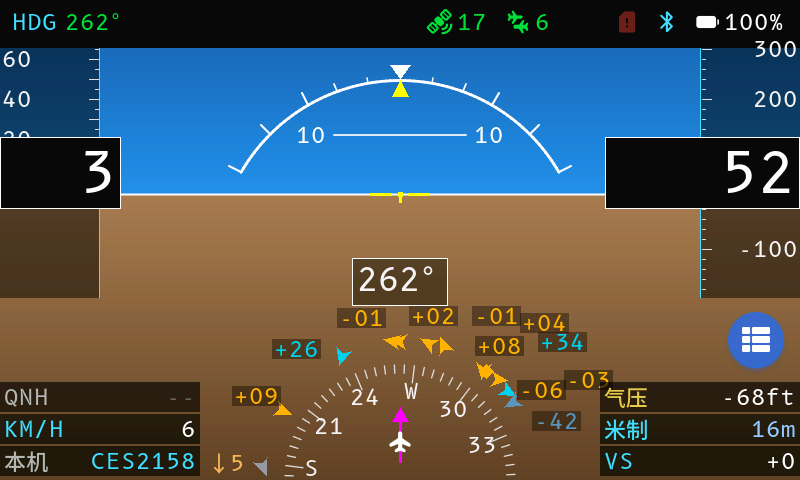
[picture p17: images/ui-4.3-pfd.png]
PFD home
|  | **PFD home**. Attitude indicator, left/right speed/altitude tapes, bottom HSI compass with traffic overlay, three info lines on each side |
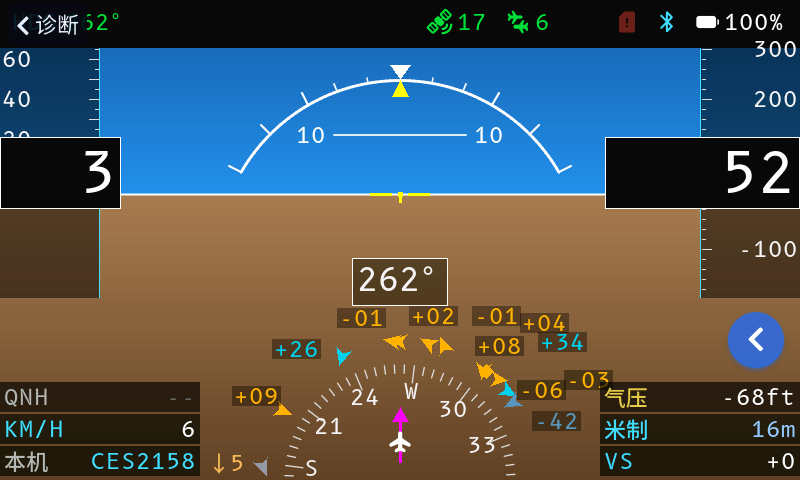
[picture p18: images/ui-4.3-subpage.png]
Subpage
|  | **Subpage**: top bar "← Diagnostics", FAB changes to ← as well |
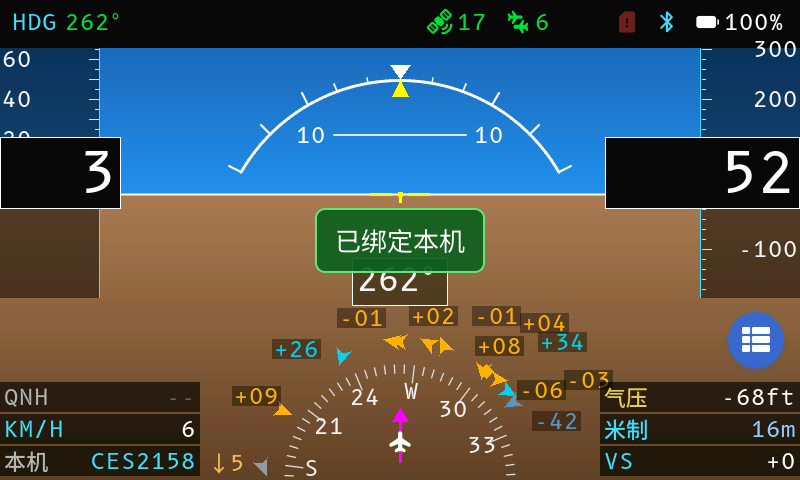
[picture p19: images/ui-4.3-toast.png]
Toast
|  | **Toast** notification, layered above all controls |
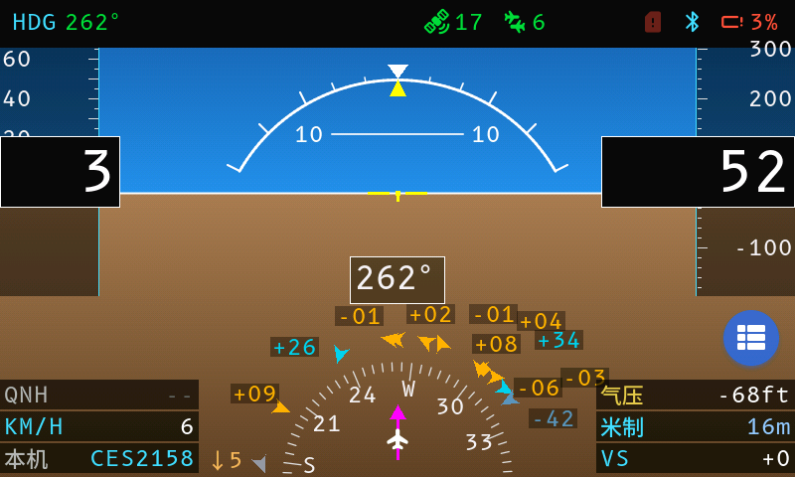
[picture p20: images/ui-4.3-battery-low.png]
Low battery
|  | **Low battery**: battery icon switches to alert and turns red along with the value |
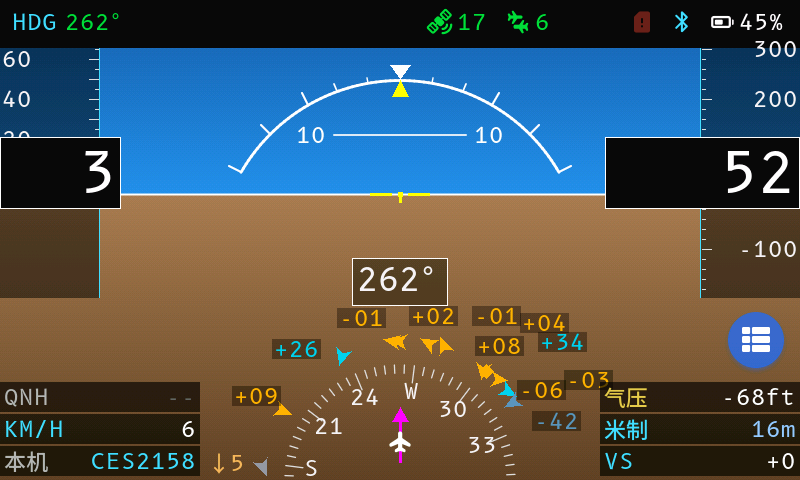
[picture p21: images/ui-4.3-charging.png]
Charging
|  | **Charging**: battery plays a frame-by-frame animation |
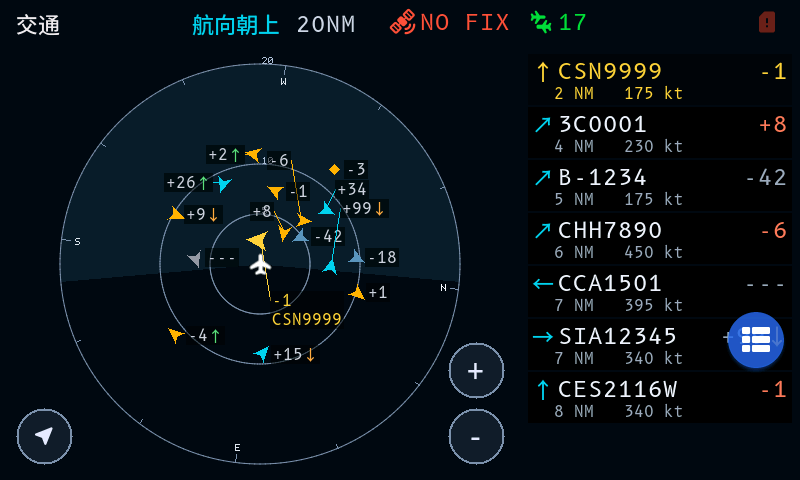
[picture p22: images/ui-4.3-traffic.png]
Traffic page
|  | **Traffic page normal state**: 360° radar + target list on the right |
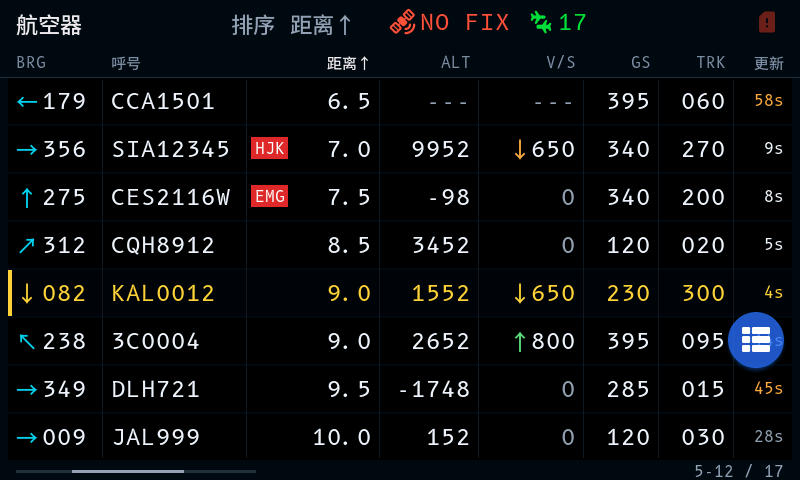
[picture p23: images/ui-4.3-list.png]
List board
|  | **List board normal state**: eight-column table, with threat-row highlighting and badges |
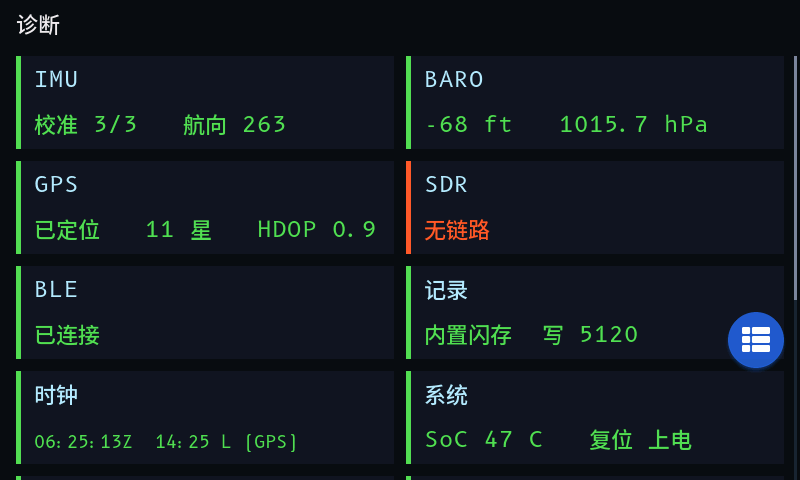
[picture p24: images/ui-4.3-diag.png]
|  | **Diagnostics overview normal state**: all eight subsystem cards green |
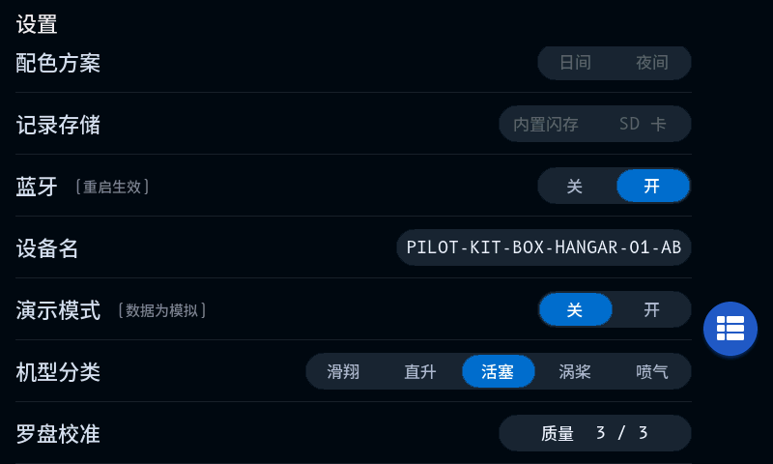
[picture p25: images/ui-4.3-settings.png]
Settings
|  | **Settings page bottom**: the demo mode row (off) |
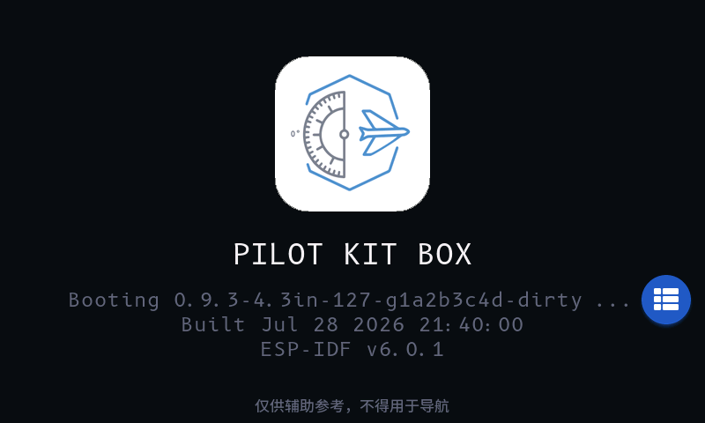
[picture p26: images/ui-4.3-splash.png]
Splash
|  | **Splash screen** (demo mode off) |

## Demo Mode (`demo-4.3-*.png`)

Demo mode swaps all four data sources for synthetic values, so the normal state can be verified on the real device
without peripherals attached. Its safety baseline is "if it is on, it must be visible", and the badge is drawn at the
control layer, independent of each page's drawing code — **the only way to prove the badge is on every page is to
capture every page**. Miss one page, and that page may lack the badge without anyone knowing. One set each for Chinese
and English: the badge is squeezed into the right end of the top bar, and each page has to yield width for it, while
English copy is much longer than Chinese.

| Image | Scene |
|---|---|
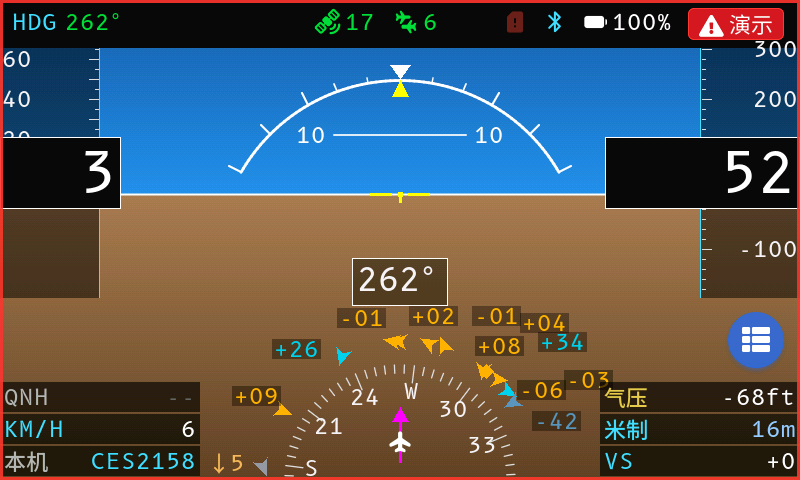
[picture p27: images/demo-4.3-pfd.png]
PFD
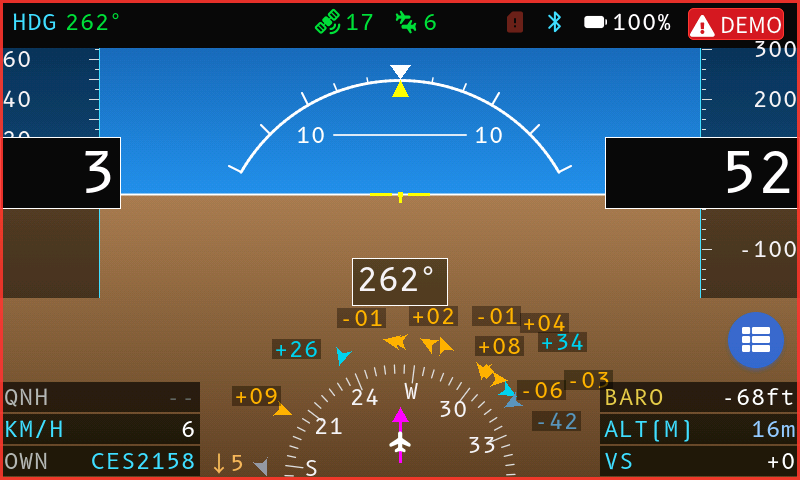
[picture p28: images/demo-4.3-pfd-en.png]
PFD English
|   | **PFD**: red-background ⚠ demo badge at the right end of the top bar + red frame around the whole screen; the status group shifts left to make room |
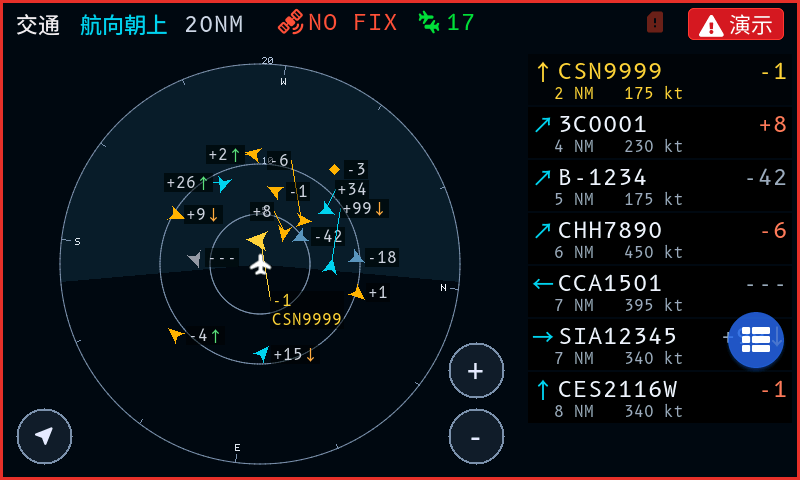
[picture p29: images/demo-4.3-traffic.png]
Traffic
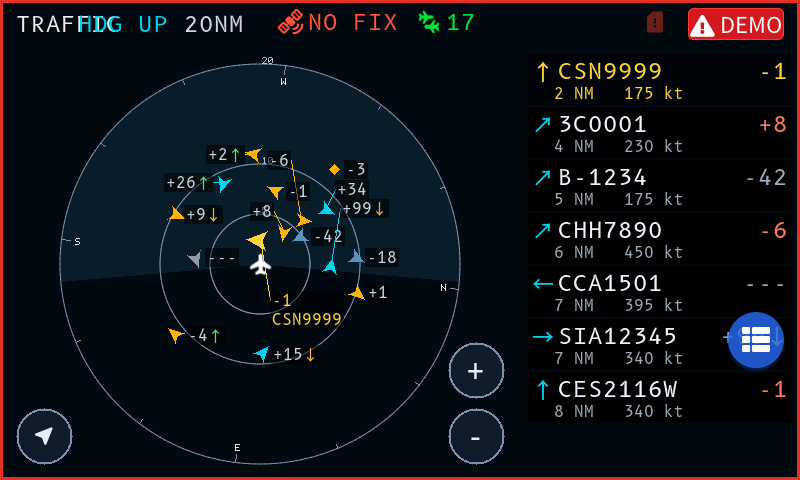
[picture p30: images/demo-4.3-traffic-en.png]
Traffic English
|   | **Traffic page**: heading/range shift left |
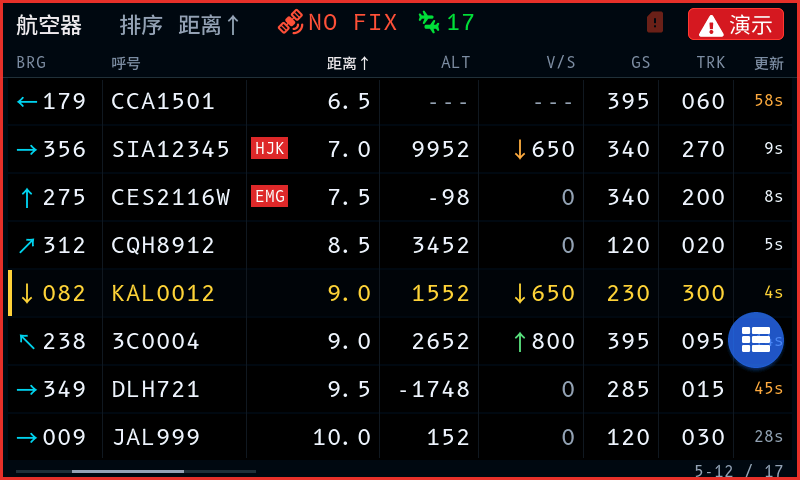
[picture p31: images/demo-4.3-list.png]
List board
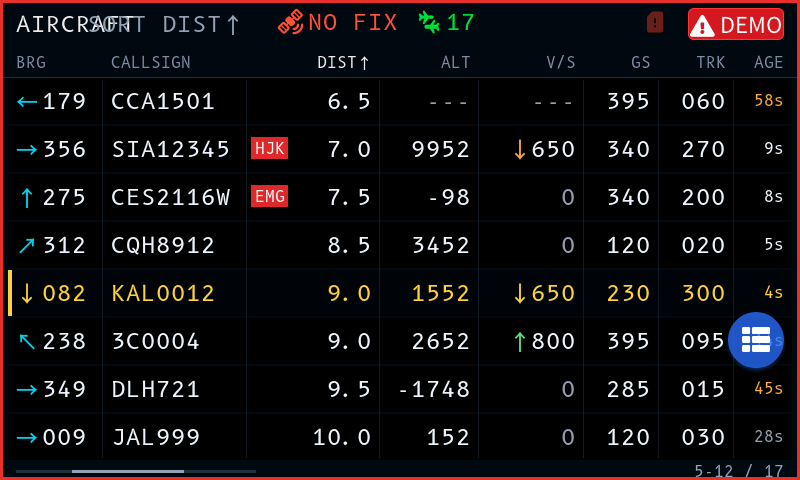
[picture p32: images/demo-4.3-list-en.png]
List English
|   | **List board**: sort hint and RESET shift left |
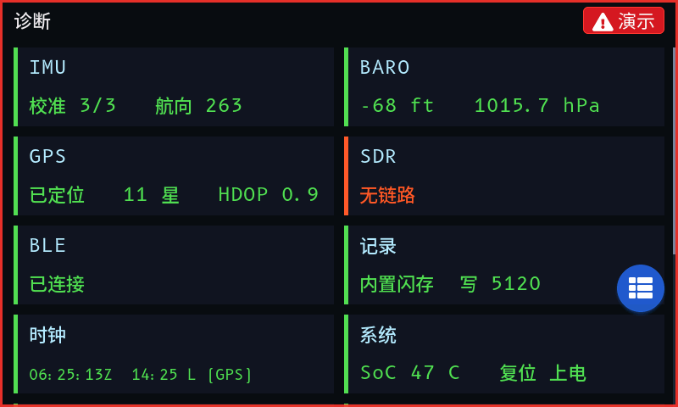
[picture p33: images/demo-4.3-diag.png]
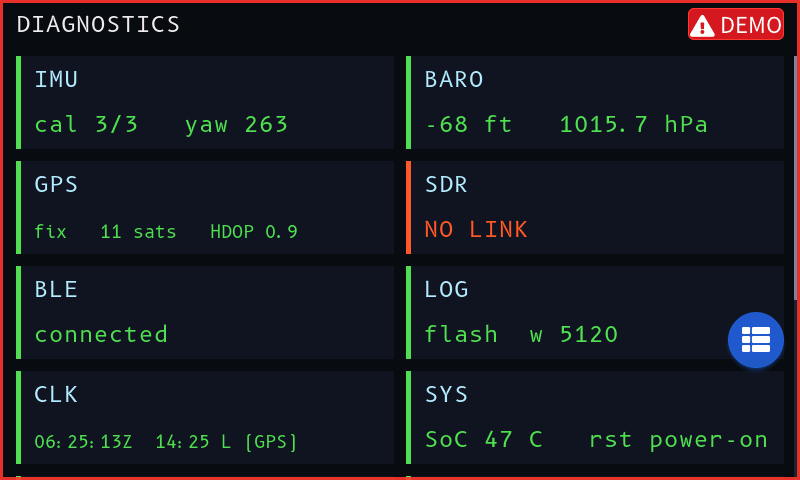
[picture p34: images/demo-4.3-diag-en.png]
Diagnostics English
|   | **Diagnostics**: the top bar only has the title at the top left; no yielding needed |
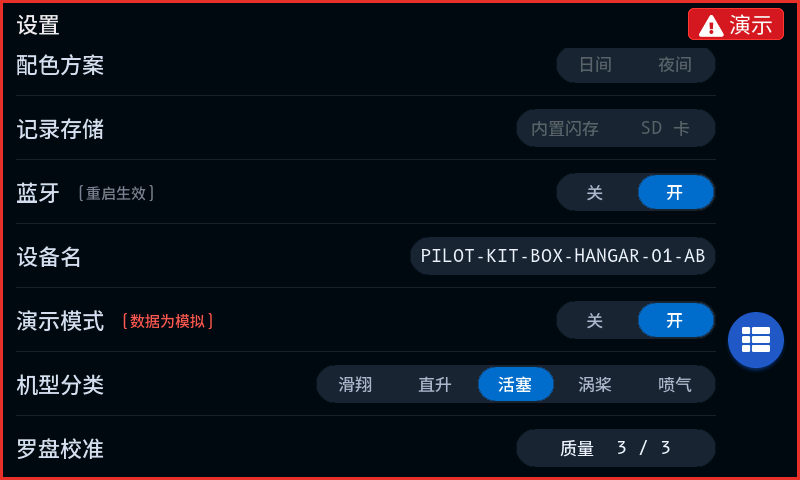
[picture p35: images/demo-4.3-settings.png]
Settings
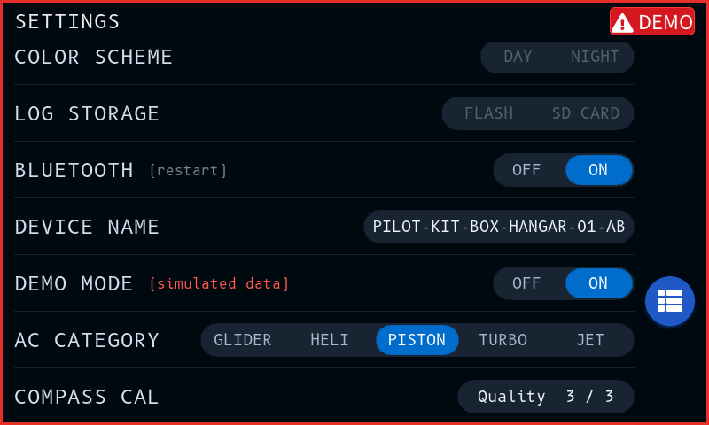
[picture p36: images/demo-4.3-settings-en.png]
Settings English
|   | **Settings page**: demo mode switch is "on", the small hint text turns red |
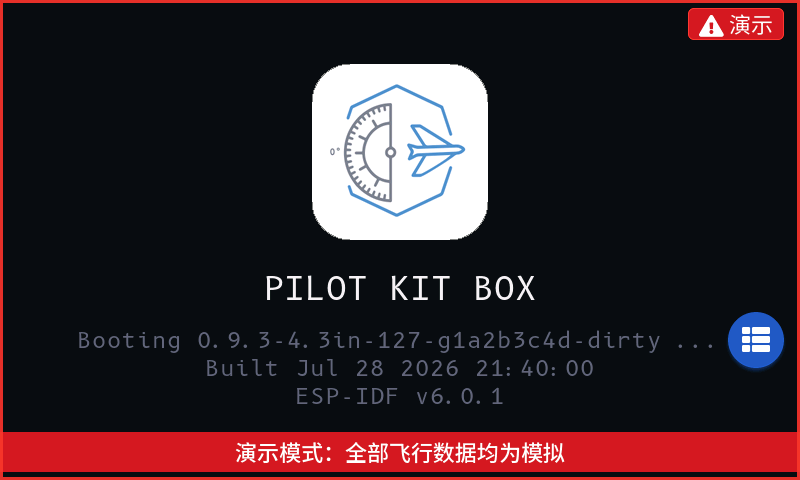
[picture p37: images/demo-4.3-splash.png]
Splash
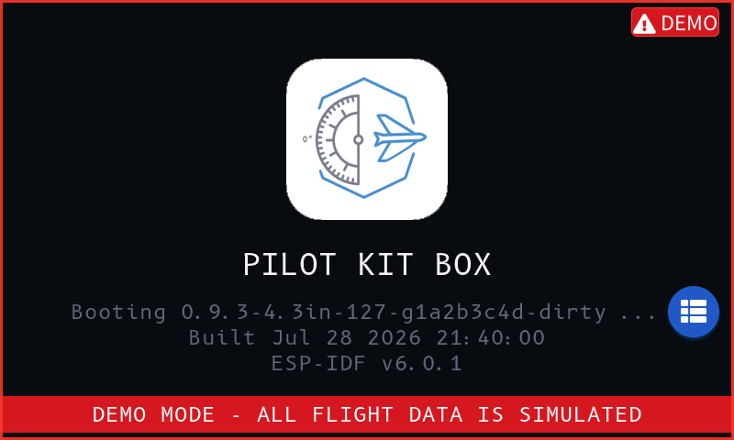
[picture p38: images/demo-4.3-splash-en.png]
Splash English
|   | **Splash screen**: red banner at the bottom. On the real device this screen renders before LVGL, so it has only the banner, no badge; the simulator draws both |

### Regenerating

```bash
python3 sim/capture.py            # all
python3 sim/capture.py --only dock  # dock-related only
```

After a UI change, re-run it once, then use `git diff --stat images/` to see which scenes were affected — unchanged
images are not recorded by git, while changed ones are obvious at a glance; it amounts to a lightweight visual
regression suite.

Scene definitions live in the `SCENES` table of `sim/capture.py`; each entry is just a set of simulator environment
variables.

> **The PFD home has no Chinese/English pair**: that screen consists entirely of internationally standardized
> symbols, numbers, and fixed abbreviations (HDG / KM/H / ALT / VS) — not a single i18n string — so both languages
> render byte-for-byte identical. This matches how ICAO standard instruments are not localized — language only
> affects text-driven screens such as navigation and settings.

## 2.4″ Version and Hardware (Remaining Files)

`PFD.jpg` / `radar-traffic.jpg` / `adsb-list.jpg` are **real photos** of the 2.4″ version;
`pcb-*` / `3d-case-*` / `assemble*` are hardware and assembly images.

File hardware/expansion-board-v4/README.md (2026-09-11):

# Pilot Kit Avionics Board V4.5

**Integrated ADS-B / GNSS / IMU expansion board for the Pilot Kit Box**
集成 ADS-B / GNSS / IMU 扩展板

<p align="center">
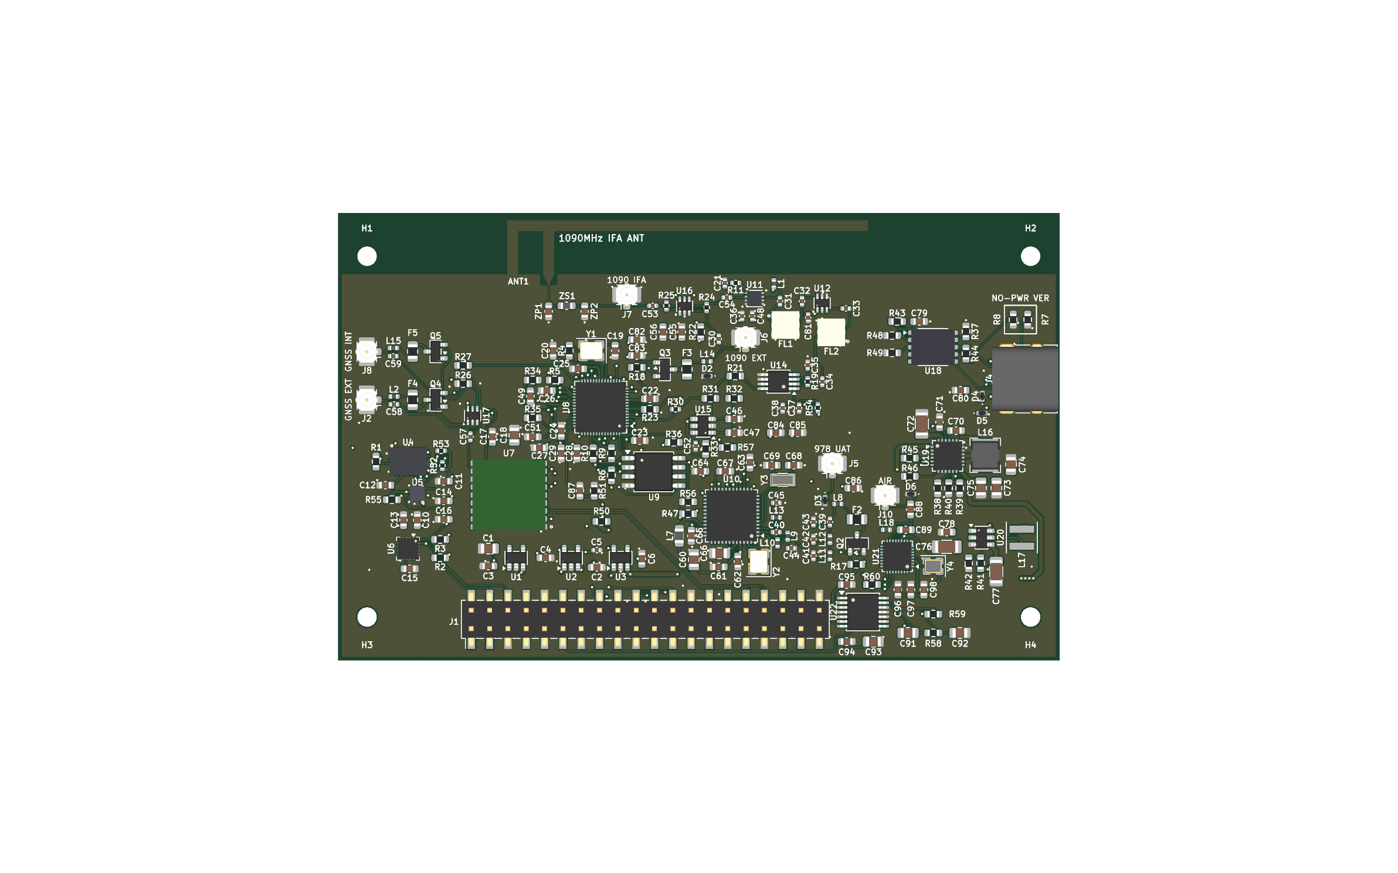
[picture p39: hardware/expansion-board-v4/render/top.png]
Expansion board V4.5 top side
  
</p>

A 6-layer, 100.1 × 62.1 mm HAT that stacks onto the Waveshare
ESP32-P4-WIFI6-Touch-LCD-4.3 carrier's 2×20 header. It replaces the four
discrete modules used by the current prototype (RTL-SDR dongle, BNO085,
GT-U8 GNSS, BMP388) with a single board — **including its own 1090 MHz
receive chain, so no RTL-SDR dongle is required.**

6 层、100.1 × 62.1 mm，以 HAT 方式直插微雪 ESP32-P4-WIFI6-Touch-LCD-4.3
载板的 2×20 排母，把现有原型的四个分立模块（RTL-SDR dongle、BNO085、
GT-U8 GNSS、BMP388）整合成一块板，**自带 1090 MHz 接收链，不再需要 dongle**。

---

## ⚠️ Status / 当前状态

> **V4.0 has been fabricated; V4.5 is the current manufacturing revision.**
> V4.5 carries forward the V4.3 electrical corrections and the V4.0 measured
> 50.0mm IFA geometry, and fixes GNSS active-antenna detection: the module's
> `VCC_RF` (U7.14) now feeds the two bias-tee PMOS sources instead of being
> left unconnected, so `$GPTXT` can report `ANTENNA OK/OPEN/SHORT`. It passes
> the automated schematic/PCB checks below, but this revision itself still
> requires physical bring-up. Owners of V4.0 boards must follow the internal
> rework record before powering the 1090 MHz chain.
>
> **V4.0 已经打样；V4.5 是当前制造版本。** V4.5 继承 V4.3 的电气修正和 V4.0
> 逐刀实测定型的 50.0mm IFA 几何，并修复 GNSS 有源天线检测：模块 `VCC_RF`(U7.14)
> 不再悬空，改为两路偏置 Tee PMOS 的源极电源，模块据此才能输出
> `ANTENNA OK/OPEN/SHORT`。V4.5 已通过下列原理图与 PCB 自动检查，但本版仍待
> 实物 bring-up。V4.0 实物在开启 1090 MHz 链路前必须先按
> 内部返修记录处理。

| | Status / 状态 |
|---|---|
| Schematic / 原理图 | ✅ Complete / 完成 |
| Layout & routing / 布局布线 | ✅ Complete — 0 DRC violations, 0 unconnected nets / 零违例、未连通 0 |
| Manufacturing files / 制造文件 | ✅ Gerber + drill export cleanly / 可正常导出 |
| **Fabrication / 打样** | ⚠️ V4.0 fabricated; V4.5 not yet fabricated / V4.0 已打样，V4.5 待打样 |
| **Bring-up / 上电验证** | ⚠️ V4.0 rework procedure prepared; V4.5 pending / V4.0 返修流程已就绪，V4.5 待验证 |
| **On-board IFA antenna / 板载 IFA 天线** | ✅ V4.0 per-cut measured 50.0mm geometry transferred / V4.0 逐刀实测 50.0mm 几何已回灌 |

**About the IFA antenna** — V4.5 uses the V4.0 physical-board result: a
**50.0mm copper outer envelope** (48.5mm radiating-arm centerline span), with
the matching network straight-through (`ZS1`=0R, `ZP1`/`ZP2`=DNP). The V4.0
board was trimmed cut-by-cut from 53.5mm and stopped at 50.0mm, where it
measured **1082.5MHz, SWR 1.09, 45+j0.5Ω** in the case with the battery
fitted. The same series yields a slope of **24–25 MHz/mm**. These values
validate the transferred geometry, but each new enclosure/material batch
still needs a VNA spot check. See [`BOM_IFA_TUNING.md`](BOM_IFA_TUNING.md).

板载 1090MHz 倒 F 天线采用 V4.0 实板逐刀定型结果：**铜箔外包络 50.0mm**（辐射臂
中心线跨度 48.5mm），匹配网络直通（`ZS1`=0R、`ZP1`/`ZP2`=DNP）。该板由 53.5mm
逐刀切短并在 50.0mm 停刀，装盒且装电池实测 **1082.5MHz、SWR 1.09、45+j0.5Ω**；
同一组序列给出斜率 **24–25MHz/mm**。
该结果用于 V4.5 回灌，但新外壳或板材批次仍应抽样用 VNA 复核。

---

## Specifications / 规格

| | |
|---|---|
| **Outline / Layers** | 100.1 × 62.1 mm, 6 layers |
| **Stackup** | Designed for 0.0994 mm L1→In1 (single-ply 3313); any 0.085–0.115 mm works as-is — see below |
| **Layer usage** | F.Cu signal · In1 solid GND (RF reference) · In2 signal · In3 3V3 plane · In4 solid GND · B.Cu signal |
| **1090 MHz RX** | QPL9547 LNA → TA0970A SAW → BGA2817 → AD8313 log detector → TLV3501 comparator → RP2040 PIO decoder |
| **978 MHz UAT** | CC1312R1F3RGZR sub-GHz transceiver, differential LC match |
| **Antennas** | On-board 1090 IFA + 3 × U.FL (1090 ext / 978 / GNSS), PMOS-switched bias tees |
| **GNSS** | ATGM336H-6N-74, switchable internal patch / external antenna; module `VCC_RF` (U7.14) feeds the bias tees for active-antenna detection |
| **Sensors** | BNO085 IMU (100 Hz fusion), BMP388 barometer, QMC5883P magnetometer |
| **Power** (optional) | CH224K USB-PD sink @9 V → SY6970 charger + fuel gauge → SY7069 5 V boost, single-cell Li-po |
| **Host interface** | 2×20 SMD header, HAT-style stacking onto the carrier |
| **Scale** | 207 placements, 436 vias (all ≥0.30 mm drill), 1599 track segments |

Two assembly variants — with and without the on-board power section.
See [`VARIANTS.md`](VARIANTS.md).
两个装配变体（带/不带板载电源），选贴规则见该文档。

<p align="center">
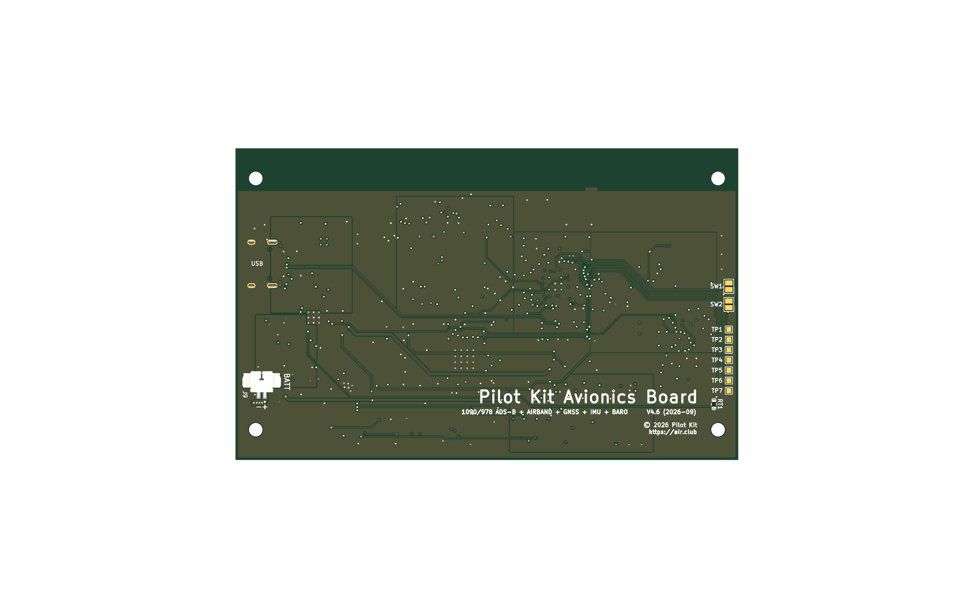
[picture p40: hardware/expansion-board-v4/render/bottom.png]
Expansion board V4.5 bottom side
  
</p>

---

## Documentation / 文档

Every board document ships in two languages: the English original
(`*.md`) and the Simplified-Chinese working notes (`*-zh_CN.md`) it was
authored in. Tables, part numbers, and net names are identical in both.

| Document | Contents | Lang |
|---|---|---|
| [`PINMAP.md`](PINMAP.md) | Authoritative pin and net map — the single source of truth for the schematic | EN / 中文 |
| [`VARIANTS.md`](VARIANTS.md) | Powered vs. unpowered assembly variants (inverted logic — read before ordering) | EN / 中文 |
| [`ASSEMBLY.md`](ASSEMBLY.md) | Hand-assembly placement list, generated from the board | EN / 中文 |
| [`ASSEMBLY_MAP-V4.6.pdf`](ASSEMBLY_MAP-V4.6.pdf) / [`ASSEMBLY_MAP-V4.6-zh_CN.pdf`](ASSEMBLY_MAP-V4.6-zh_CN.pdf) | Color-coded full-board assembly maps (placement semantics, three pages each) | PDF |
| [`SELECTIVE_PLACEMENT.md`](SELECTIVE_PLACEMENT.md) | Selective-placement groups and **mutex rules** — which parts must never be populated together | EN / 中文 |
| [`CHECKLIST.md`](CHECKLIST.md) | Per-reference BOM checklist for hand placement (also [.xlsx](CHECKLIST-V4.6.xlsx) / [.pdf](CHECKLIST-V4.6.pdf)) | EN / 中文 |
| [`BOM_PURCHASE-zh_CN.md`](BOM_PURCHASE-zh_CN.md) | Authoritative purchasing list, generated from the netlist | 中文 |
| [`BOM_IFA_TUNING.md`](BOM_IFA_TUNING.md) | Antenna tuning kit and the VNA procedure | EN / 中文 |
| [`BASEBOARD_REF.md`](BASEBOARD_REF.md) | Mechanical reference for the Waveshare carrier | EN / 中文 |

---

## Manufacturing package / 制造包

Pre-built packages live in [`release/`](release/):

| File | Use |
|---|---|
| `expansion-board-v4-gerber-JLC-V4.5-20260911.zip` | **Use this to order** — V4.4 plus the GNSS active-antenna detection fix (U7.14 VCC_RF feeds the bias tee), RS-274-X, 15 files |
| `expansion-board-v4-kicad-V4.5-20260911.zip` | Matching V4.5 source archive / further development. **Not accepted by the fab** |
| `expansion-board-v4-gerber-JLC-V4.4-20260904.zip` | ⚠️ Superseded by V4.5 — V4.4 did not wire U7.14 (VCC_RF), so the module always reported `ANTENNA OPEN`. Do not order |
| `expansion-board-v4-kicad-V4.4-20260904.zip` | ⚠️ Matching superseded V4.4 source archive — do not use |
| `expansion-board-v4-gerber-JLC-V4.3-20260902.zip` | ⚠️ Superseded by V4.4 before fabrication — old 53.5mm IFA outer envelope, do not order |
| `expansion-board-v4-kicad-V4.3-20260902.zip` | ⚠️ Matching superseded V4.3 source archive — do not use |
| `expansion-board-v4-gerber-JLC-V4.1-20260830.zip` | ⚠️ Superseded before the QPL9547 bias and power corrections — do not order |
| `expansion-board-v4-kicad-V4.1-20260830.zip` | ⚠️ Matching superseded V4.1 source archive — do not use |
| `expansion-board-v4-gerber-JLC-20260830.zip` | ⚠️ Superseded: electrically includes the ECO but carries the stale V4.0 silkscreen — do not order |
| `expansion-board-v4-kicad-20260830.zip` | ⚠️ Matching stale-V4.0 source archive — do not use as the release source |
| `expansion-board-v4-gerber-JLC-20260828.zip` | ⚠️ Superseded baseline — do not use for a new order. The GNSS antenna/bias topology itself was later verified correct and was not rewired |
| `expansion-board-v4-gerber-20260828.zip` | ⚠️ Older export in Gerber **X2** format — do not use |

### ⚠️ Three things that will ruin the board if set wrong

1. **Gerbers must be RS-274-X, not X2.** JLCPCB accepts neither KiCad project
   files nor Gerber X2. KiCad exports X2 by default, so the release package is
   regenerated with `--no-x2 --no-netlist`.
2. **Via solder-mask state comes from the file, not the order form.** JLCPCB,
   HQPCB and JiePei all state the same thing: *"if the file is Gerber, we
   process strictly per the file; this option has no effect"* — Gerber cannot
   tell a via from a component hole. This board ships 437 vias: 401 tented,
   36 exposed (all 36 inside pad mask openings, 28 of them thermal via-in-pad).
3. **`J4`'s four `SH` holes must NOT be resin-plugged.** They are ⌀0.60 mm
   plated *slots* (Excellon `G85`) that mechanically anchor the USB-C
   receptacle. Plug them and the connector will tear off after a few
   insertions. If you order resin-filled via-in-pad, exclude these explicitly
   in the order notes.

### Stackup: preferred, not mandatory

The 28 controlled-impedance RF nets are 0.15 mm wide, derived from an L1→In1
dielectric of **0.0994 mm (single-ply 3313 prepreg)**. You do **not** need that
exact stackup:

| Your fab's L1→In1 | Result | Action |
|---|---|---|
| **0.085 – 0.115 mm** | 45–55 Ω | Send as-is. Verified: JLCPCB `JLC06161H-3313`, JiePei `JP06161H-3313B2` |
| ~0.125 mm (single-ply 2116) | ≈57 Ω | Still fine — 0.02 dB mismatch loss |
| ~0.19 mm (single-ply 7628) | ≈70 Ω | Buildable — 0.12 dB mismatch loss, slightly lower 1090 sensitivity |

The longest RF run is 11.7 mm ≈ λ/13 at 1090 MHz, so mismatch never builds a
standing wave — every case above costs less than the 0.51 dB that an SWR of 2.0
would.

> 🔴 **The on-board IFA antenna, however, does need retuning for your laminate.**
> The 50.0 mm copper length is tied to JLCPCB's 3313 material. Measured on
> 2026-09-11: the same Gerber built by JiePei on `JP06161H-7628A1` resonated at
> **1062.5 MHz instead of 1085 MHz**, with SWR rising from 1.06 to 1.72 — the
> laminate's εr sets antenna resonance, and clearing all six copper layers removes
> the *copper*, not the 1.6 mm of FR-4 underneath. Trim 0.1–0.2 mm at a time using
> 11.5 MHz/mm as the slope, and judge in the enclosure. Irrelevant if you only use
> the external U.FL/SMA antenna.

Full numbers, per-vendor stackup tables and the mismatch-loss derivation:
[`PCB_STACKUP_IMPEDANCE.md`](../PCB_STACKUP_IMPEDANCE.md).

---

## What ships here / 这里交付什么

This directory carries the **results**: the KiCad project, the fabrication
package, and the assembly documents. Open `kicad/` in KiCad 10 to inspect or
modify the design; send `release/` straight to a board house.

本目录交付的是**结果**：KiCad 工程、制造文件包、装配文档。
要看或改设计，用 KiCad 10 打开 `kicad/`；要打板，把 `release/` 直接发板厂。

| Path | What it is |
|---|---|
| `kicad/` | Schematic + PCB source, openable and editable in KiCad 10 |
| `release/` | Gerber, drill, BOM and CPL — ready to send to a fab |
| `ASSEMBLY_MAP-V4.6.pdf` | Per-designator placement map with orientation and polarity |
| `CHECKLIST.md` | Line-by-line check sheet for hand assembly |
| `SELECTIVE_PLACEMENT.md` | Which designators must **not** simply be populated from the BOM |
| `BOM_PURCHASE-zh_CN.md` | Parts list with values, packages and selection constraints |

The board was generated and verified by an internal script chain rather than
hand-maintained, which is why the schematic, placement, routing, zones and
silkscreen are all internally consistent. Those generators are part of our
build process, not part of what this board is — they are not published.

板子由内部脚本链生成和校验，不是手工维护的，所以原理图、布局、布线、覆铜
和丝印彼此严格一致。那套生成器属于我们的构建过程，不是这块板本身，
因此不在公开范围内。

Requires KiCad 10 to open the project (it uses KiCad 10 file formats).
打开工程需要 KiCad 10（文件格式为 KiCad 10）。

---

## License / 许可

MIT, same as the parent repository — see the
[main README](../../README.md#开源协议--license).
与主仓库一致（MIT）。

The KiCad project embeds footprints from the KiCad standard libraries, which
are CC-BY-SA 4.0 with an exception explicitly permitting unrestricted use of
boards produced from them — so this does not impose copyleft on your hardware.
本工程内嵌了 KiCad 官方库的封装（CC-BY-SA 4.0，但其例外条款明确允许
由此制造的板子不受限制使用，不会传染到你的硬件）。

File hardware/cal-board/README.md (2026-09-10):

# VNA 校准 / 转接板（2 层 · 华秋免费打样档）

一块给 NanoVNA 用的板载 SOL 校准件 + U.FL/SMA 转接板。

    生成：~/Applications/KiCad/KiCad.app/Contents/Frameworks/Python.framework/Versions/Current/bin/python3 tools/gen_cal_board.py
    产物：kicad/cal-board.kicad_pcb        95 × 92 mm，2 层，1.6mm

## 为什么要做它

U.FL 没有现成的 SOL 校准件，校准面只能停在 VNA 的 SMA 口，**尾线（pigtail）
留在测量链路里**。2026-09-04 实测：V4.4 板 J6 读到 11.45pF，理论只有 1.6pF，
差 7 倍，一度以为板子坏了 —— 实际是尾线没被校准掉。

尾线对读数做**两件**事，只记住第一件就会误判：

| | 后果 |
|---|---|
| **相位旋转** | R/X 重新分配，X 过零的频率被挪动 |
| **损耗衰减** | \|Γ\| 被拉向圆心，**SWR 被压得偏乐观** |

同一根尾线（往返 0.55dB）：天线（|Γ|=0.04）SWR 1.083→1.089 可忽略；
开路线（|Γ|=0.885）SWR 10.84→**16.40**，压低了三分之一。

有了这块板，就能把尾线**真正校准进 VNA**，而不是事后补偿。
（软件补偿仍可用：`hardware/tools/vna_deembed.py`，只需一次尾线空接读数。）

## 板上有什么

```
┌─ 1) U.FL SOL ─────────────────────┬─ 3) THRU / adapters ─┐
│  J1 OPEN   J2 SHORT   J3 LOAD     │  J7─J8  UFL-SMA 7.5mm│
├─ 2) SMA SOL ──────────────────────┴──────────────────────┤
│  J4 OPEN   J5 SHORT   J6 LOAD                            │
│  J9─J10 UFL-UFL 3.5mm      J11─J12 SMA-SMA 14.0mm        │
└──────────────────────────────────────────────────────────┘
```

| 区 | 用途 |
|---|---|
| **① U.FL SOL** | **核心**。校准 `SMA母–IPEX` 这类尾线，校准面落在 U.FL 接触面上，与实际插 J6/J7 时完全一致 |
| **② SMA SOL** | 校准 `SMA母–SMA母` 尾线。**如果 NanoVNA 自带 SMA 校准件，这三组可以不焊** |
| **③ THRU / 转接** | U.FL↔SMA 转接、S21 归一化、验证线缆损耗 |

## 设计上的三个硬约束

**① 参考面必须一致 —— 这是校准板的命根子。**
Short/Open/Load 到连接器焊盘的距离必须相同，否则三者不在同一参考面，
解出来的误差模型是错的。本板做法是**零长度**：标准件直接贴在信号焊盘边上。

    OPEN   信号焊盘悬空（只有焊盘自身的边缘电容）
    SHORT  紧邻打 3 个过孔到底层地（多孔并联压低短路电感）
    LOAD   紧邻贴 2×100Ω 0402 并联（并联把寄生电感减半）

**② 走线长度分两档处理。**
1090MHz 在这个叠层上的波导波长是 150.4mm，**λ/20 = 7.5mm** 是分界：

| 组 | 走线 | 线宽 | 依据 |
|---|---|---|---|
| UFL-UFL | 3.45mm | 1.20mm | 电长度不足 9°，阻抗偏差可忽略 |
| UFL-SMA | 7.47mm | 1.20mm | 刚好卡进 λ/20 |
| SMA-SMA | 14.0mm | **2.40mm** | 超过 λ/20，须按 50Ω 走 |

⚠️ 2 层 1.6mm 板的 50Ω 线宽是 **2.692mm**（由嘉立创 2 层官方数据点
h=1.43/W=2.6916/50Ω 反标定 Dk=4.423 算得）。但 **SMA 垂直座四个地脚之间
只有 2.83mm 净空**，留 0.2mm 间距后最宽只能走 **2.43mm**。取 2.40mm（53.0Ω）
是这个几何硬限与阻抗之间的折中，不是随手写的数。

**③ 走线端点不能落在 U.FL 焊盘中心。**
U.FL 封装自带 `top_keepout` 规则区，其右边界离信号焊盘中心只有 0.535mm，
而走线端帽是圆的（半径 = 线宽/2）会伸进去。端点内缩 0.35mm，
既仍与焊盘重叠导通，又让端帽退出禁布区。

## 元件

| 位号 | 件 | 数量 | 备注 |
|---|---|---|---|
| J1–J3, J7, J9, J10 | U.FL 座 Hirose U.FL-R-SMT-1 | 6 | 与主板 J2/J5–J8 同款 |
| J4–J6, J8, J11, J12 | SMA 垂直四脚方法兰 | 6 | Amphenol 132134 兼容封装 |
| R1–R4 | 0402 100Ω ±1% | 4 | 每个 LOAD 用 2 个并联 = 50Ω |

⚠️ **没有采用那款「外螺内孔·偏脚·间距 1.7mm」板边座**：它的地脚间距与 KiCad
现成的 `SMA_Amphenol_132289_EdgeMount`（±4.25mm）对不上，仅凭商品图自制封装会
踩「换料必查焊盘图」那个坑。要加这款，需要先拿到**规格书或实测**法兰尺寸 /
脚宽 / 脚长 / 中心针直径。四脚方法兰款货源足、封装确定，先用它。

## 怎么用

**校准 U.FL 尾线**（把尾线纳入校准面）：

1. VNA 设好频段（如 950–1200MHz）
2. 尾线 SMA 端接 VNA PORT1，U.FL 端依次插 **J1(OPEN) → J2(SHORT) → J3(LOAD)**
3. 每插一个，在 NanoVNA 的 CAL 菜单里点对应项，最后 DONE + SAVE
4. 之后直接插主板的 J6/J7，读数就是板上真实值，**不用再 de-embed**

**验证**：校准后插 J1(OPEN)，Smith 图应落在最右（开路）；插 J2 落最左（短路）；
插 J3 落圆心（50Ω）。三者都对，校准才算成功。

## 已知误差源（不追求实验室级精度时可忽略）

自制标准件的寄生量未知，NanoVNA 会按理想件处理，因此存在残余误差：

| | 量级 @1090MHz | 影响 |
|---|---|---|
| OPEN 的焊盘边缘电容 | ~0.1pF → −j1460Ω | 相对理想开路（∞）偏一点 |
| SHORT 的过孔电感 | 3 孔并联约 0.3nH → +j2Ω | 相对理想短路（0Ω）偏一点 |
| LOAD 的电阻寄生 | 2×100Ω 并联后约 0.2nH | 高频略偏感性 |

对 1090MHz 单频点的用途足够。要更准就得买带 ADAPTER 定义的商用校准件。

## 制造

    2 层 · 1.6mm · 1oz · 绿油白字 · 最小线宽 1.20mm · 最小孔径 0.4mm
    尺寸 95 × 92mm（华秋免费档 10×10cm 以内）

工艺余量很大（最小线宽 1.2mm 远超 5/5mil 档），任何板厂的免费档都能做。

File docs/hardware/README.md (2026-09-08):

# Hardware reference — Waveshare ESP32-P4-WIFI6-Touch-LCD-4.3

Chinese version: [`README-zh_CN.md`](README-zh_CN.md)

This directory contains the authoritative local hardware references for the
current Pilot Kit Box target.

## Current board

| Item | Value |
|---|---|
| Board | Waveshare ESP32-P4-WIFI6-Touch-LCD-4.3, Rev1.2, SKU 33874 |
| Main SoC | ESP32-P4NRW32, 768 KB SRAM and 32 MB in-package PSRAM |
| External flash | GD25Q256EYIGR, 256 Mbit / 32 MB NOR |
| Wireless | ESP32-C6-MINI-1-N4 over 4-bit ESP-Hosted SDIO |
| Display | ST7701, 4.3-inch 480×800 IPS, 2-lane MIPI-DSI; 800×480 landscape UI |
| Touch | GT911, I²C GPIO7/8, reset GPIO23, interrupt resistor not fitted |
| P4 console | H1 USB-C `USB TO UART`, through CH343P |
| Native USB HS | Same nets on H2 USB-C `USB` and J3-27/25; the v1/v2-era RTL-SDR dongle path used these nets (retired in current firmware) |
| C6 download | P1 1×4 header `TX RX IO9 GND` |
| Expansion | J3 2×20 header; check the project pinout before wiring |

ESP32-P4 has no integrated radio. The current firmware starts ESP-Hosted on
the C6 before display initialization, then uses the C6 Bluetooth controller.

Official links:

- Documentation: <https://docs.waveshare.com/ESP32-P4-WIFI6-Touch-LCD-4.3>
- Resources: <https://docs.waveshare.com/ESP32-P4-WIFI6-Touch-LCD-4.3/Resources-And-Documents>
- Examples: <https://github.com/waveshareteam/ESP32-P4-WIFI6-Touch-LCD-4.3>

## Current Pilot Kit connections

| Module | Connection | Firmware status |
|---|---|---|
| RTL-SDR FC0013 | Carrier USB-A plug on J3-27/25 (native USB 2.0 HS), H2 left empty; on a bare board use H2 with a USB-C OTG adapter/hub instead | **Retired** (v1/v2 dongle path): firmware support removed — 1090 MHz receive now lives on the v3/v4 expansion board |
| ST7701 display | Board-fixed MIPI-DSI, 2 lanes at 500 Mbit/s | Integrated |
| GT911 touch | Board-fixed GPIO7/8, reset GPIO23; polled | Integrated, first contact only |
| BNO085 IMU | GPIO7/8, reset GPIO28, INT GPIO34, address 0x4A | Integrated, polled |
| BMP388 | GPIO7/8, INT wired to GPIO31 (carrier net `BARO_INT`) | Integrated, polled |
| GPS | P4 TX GPIO49, P4 RX GPIO51; optional PPS GPIO50 | UART/RMC integrated; PPS not implemented |
| ESP32-C6 | P4 GPIO14–19 SDIO, GPIO54 EN | Wi-Fi/BLE transport integrated |
| Audio / camera | Board hardware present | Not initialized by Pilot firmware |

## Documents

| File | Purpose |
|---|---|
| [`board_pinout.md`](board_pinout.md) / [`board_pinout-zh_CN.md`](board_pinout-zh_CN.md) | Complete J3, GPIO0–54, connector and Pilot wiring reference |
| [`pinmap_978.md`](pinmap_978.md) | RP2040 ↔ CC1312R Sub-GHz (978 MHz) pin fact sheet: SUBG_* nets, SPI1 verdict, cJTAG boundary, v3/v4 diff |
| [`c6_slave_firmware.md`](c6_slave_firmware.md) / [`c6_slave_firmware-zh_CN.md`](c6_slave_firmware-zh_CN.md) | One-time C6 slave flashing guide using P1 |
| [`ESP32-P4-WIFI6-Touch-LCD-4.3-schematic.pdf`](ESP32-P4-WIFI6-Touch-LCD-4.3-schematic.pdf) | **Board authority:** Rev1.2 schematic and assembly drawing |
| [`ESP32-P4-WIFI6-Touch-LCD-4.3-wiki.md`](ESP32-P4-WIFI6-Touch-LCD-4.3-wiki.md) | Offline official-resource digest and BSP parameters |
| [`ESP32-P4-WIFI6-Touch-LCD-4.3-dimensions.pdf`](ESP32-P4-WIFI6-Touch-LCD-4.3-dimensions.pdf) | Mechanical dimensions: 114.4 × 66.8 mm, 4 × M2.5 |
| [`ST7701-datasheet.pdf`](ST7701-datasheet.pdf) | Display-controller reference |
| [`GT911-datasheet.pdf`](GT911-datasheet.pdf) | Touch electrical and addressing reference |
| [`GT911-programming-guide.pdf`](GT911-programming-guide.pdf) | Touch report and register format |

`ESP32-P4-WIFI6-datasheet.pdf` is **not** the ESP32-P4 chip datasheet and is
not the 4.3-inch Rev1.2 schematic. It describes a different Waveshare
ESP32-P4-WIFI6 board and must not be used for this target's pin assignments.

## Expansion boards

| Board | Status | Entry point |
|---|---|---|
| Expansion board **V4** (6-layer integrated) | Current hardware target — layout complete, not yet fabricated | [`../../hardware/expansion-board-v4/README.md`](../../hardware/expansion-board-v4/README.md) (bilingual; every doc ships as EN + `-zh_CN.md`) |
| Expansion board **V3** (4-layer) | Archived (v3.2 fabricated; still used for firmware debugging) | [`../../hardware/expansion-board-v3/README.md`](../../hardware/expansion-board-v3/README.md) |

The previous 2.4-inch carrier and its four-button wiring remain historical
design sources under `docs/jlc/`; they are not the active board.

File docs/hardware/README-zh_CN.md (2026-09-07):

# 硬件参考 — 微雪 ESP32-P4-WIFI6-Touch-LCD-4.3

英文版：[`README.md`](README.md)

本目录保存 Pilot Kit Box 当前硬件目标的权威本地资料。

## 当前开发板

| 项目 | 值 |
|---|---|
| 开发板 | 微雪 ESP32-P4-WIFI6-Touch-LCD-4.3，Rev1.2，SKU 33874 |
| 主控 | ESP32-P4NRW32，768 KB SRAM、封装内 32 MB PSRAM |
| 外置 Flash | GD25Q256EYIGR，256 Mbit / 32 MB NOR |
| 无线 | ESP32-C6-MINI-1-N4，通过 4-bit ESP-Hosted SDIO 连接 |
| 显示 | ST7701，4.3 寸 480×800 IPS，2-lane MIPI-DSI；横屏 UI 800×480 |
| 触摸 | GT911，I²C GPIO7/8，复位 GPIO23，中断电阻默认未贴 |
| P4 调试口 | H1 USB-C `USB TO UART`，经 CH343P |
| 原生 USB HS | H2 USB-C `USB` 与 J3-27/25 同网；v1/v2 时代的 RTL-SDR dongle 路径走这组信号（当前固件已退役） |
| C6 下载口 | P1 1×4 排针 `TX RX IO9 GND` |
| 扩展口 | J3 2×20 排针；接线前必须核对项目 pinout |

ESP32-P4 本身没有无线电。当前固件先启动 C6 上的 ESP-Hosted，再初始化
显示，并通过 C6 使用蓝牙 controller。

官方链接：

- 文档：<https://docs.waveshare.com/ESP32-P4-WIFI6-Touch-LCD-4.3>
- 资料：<https://docs.waveshare.com/ESP32-P4-WIFI6-Touch-LCD-4.3/Resources-And-Documents>
- 例程：<https://github.com/waveshareteam/ESP32-P4-WIFI6-Touch-LCD-4.3>

## 当前 Pilot Kit 接线

| 模块 | 连接 | 固件状态 |
|---|---|---|
| RTL-SDR FC0013 | 载板 USB-A 插头走 J3-27/25（原生 USB 2.0 HS），H2 空置；裸板调试时改接 H2 加 USB-C OTG 转接头或 Hub | **已退役**（v1/v2 dongle 路径）：固件支持已移除——1090 MHz 接收现位于 v3/v4 扩展板 |
| ST7701 显示 | 板载固定 MIPI-DSI，2 lane @ 500 Mbit/s | 已集成 |
| GT911 触摸 | 板载 GPIO7/8、复位 GPIO23；轮询 | 已集成，当前只取第一触点 |
| BNO085 IMU | GPIO7/8、复位 GPIO28、INT GPIO34、地址 0x4A | 已集成，轮询 |
| BMP388 | GPIO7/8、INT 接 GPIO31（载板网络 `BARO_INT`） | 已集成，轮询 |
| GPS | P4 TX GPIO49、P4 RX GPIO51；可选 PPS GPIO50 | UART/RMC 已集成；PPS 未实现 |
| ESP32-C6 | P4 GPIO14–19 SDIO、GPIO54 EN | Wi-Fi/BLE 传输已集成 |
| 音频 / 摄像头 | 板上硬件具备 | Pilot 固件未初始化 |

## 文档

| 文件 | 用途 |
|---|---|
| [`board_pinout.md`](board_pinout.md) / [`board_pinout-zh_CN.md`](board_pinout-zh_CN.md) | 完整 J3、GPIO0–54、接口及 Pilot 接线参考 |
| [`c6_slave_firmware.md`](c6_slave_firmware.md) / [`c6_slave_firmware-zh_CN.md`](c6_slave_firmware-zh_CN.md) | 使用 P1 首次烧录 C6 slave |
| [`ESP32-P4-WIFI6-Touch-LCD-4.3-schematic.pdf`](ESP32-P4-WIFI6-Touch-LCD-4.3-schematic.pdf) | **板级最高依据：**Rev1.2 原理图和装配图 |
| [`ESP32-P4-WIFI6-Touch-LCD-4.3-wiki.md`](ESP32-P4-WIFI6-Touch-LCD-4.3-wiki.md) | 官方资料离线摘要及 BSP 参数 |
| [`ESP32-P4-WIFI6-Touch-LCD-4.3-dimensions.pdf`](ESP32-P4-WIFI6-Touch-LCD-4.3-dimensions.pdf) | 机械尺寸：114.4 × 66.8 mm，4 × M2.5 |
| [`ST7701-datasheet.pdf`](ST7701-datasheet.pdf) | 显示控制器参考 |
| [`GT911-datasheet.pdf`](GT911-datasheet.pdf) | 触摸电气和地址参考 |
| [`GT911-programming-guide.pdf`](GT911-programming-guide.pdf) | 触摸上报及寄存器格式 |

`ESP32-P4-WIFI6-datasheet.pdf` **不是** ESP32-P4 芯片 datasheet，也不是
4.3 寸 Rev1.2 原理图；它描述另一款微雪 ESP32-P4-WIFI6 板，不能用于本
目标的引脚分配。

## 扩展板

| 板卡 | 状态 | 入口 |
|---|---|---|
| 扩展板 **V4**（6 层集成） | 当前硬件目标——布局布线完成，尚未打样 | [`../../hardware/expansion-board-v4/README.md`](../../hardware/expansion-board-v4/README.md)（双语；每份文档均有 EN + `-zh_CN.md`） |
| 扩展板 **V3**（4 层） | 已归档（v3.2 已打样；仍用于固件调试） | [`../../hardware/expansion-board-v3/README.md`](../../hardware/expansion-board-v3/README.md) |

旧 2.4 寸载板及其四按键接线仅作为历史设计源保存在 `docs/jlc/`，不是当前
硬件。

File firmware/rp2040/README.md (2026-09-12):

# firmware/rp2040 — RP2040 扩展板固件（adsb1090）

1090 MHz 解调协处理器固件：PIO 沿捕获 + Mode-S 帧成形 + 与 P4 的 UART
链路。产物 `build/adsb1090.uf2`（实测 82432 B ≈ 80.5 KiB，BOOTSEL 拖放
烧录），烧录步骤见 `docs/firmware_update.md`。

## 构建

```bash
./build.sh
```

无参数全量构建；产物落在 `build/adsb1090.uf2`，末尾打印 sha256。要求：

- cmake >= 3.16、宿主 C/C++ 编译器（编译 picotool、pioasm 等宿主工具）；
- `arm-none-eabi-gcc` 在 PATH，**必须含 newlib**（pico-sdk 硬编码
  `--specs=nosys.specs`）：
  - 本机（macOS）：`brew install --cask gcc-arm-embedded`
    （实测 15.3.Rel1；brew formula 版不含 newlib，必编不过）；
  - CI（ubuntu-latest）：`apt-get install gcc-arm-none-eabi
    libnewlib-arm-none-eabi libstdc++-arm-none-eabi-newlib`
    （runner 镜像自带 cmake/python3）。
    注意版本偏移：apt 装的是 13.x，本机实测构建用的是 15.3.Rel1——
    首个 tag 构建后核对一次 CI 日志（UF2 大小/sha256 与本地产物对拍）。
- 首次构建需联网（tarball 均带 URL_HASH 完整性校验，取回后缓存在
  `build/` 下）。

## 依赖 pin（全部钉死在 CMakeLists.txt，唯一事实源）

| 依赖 | pin | 原因 |
|---|---|---|
| pico-sdk | 2.1.1 release tarball + URL_HASH | 版本可复现 |
| tinyusb | commit `86ad6e56`（pico-sdk 2.1.1 官方 submodule pin）tarball + URL_HASH | SDK 的 **tarball 不含 submodule**，SDK 2.1.1 亦不会自取；必须显式取回并钉在官方 submodule SHA 上 |
| picotool | 2.1.1 release tarball + URL_HASH | SDK 找不到已装 picotool 时会从 git **develop 分支**自取（GIT_TAG 不可 pin）；提前自建同版本并注册同名目标，把 SDK 的自取短路掉 |

注意：

- 本工程**不读** `PICO_SDK_PATH`（build.sh 会主动 unset 残留值）；
- `set_target_properties(... SUFFIX ".elf")` 是 picotool 2.1.1 的兼容
  quirk：它按扩展名识别输入文件，无后缀的默认产物名会被拒。

## 发布链

`build.sh` 同时服务于本地与 CI
（`.github/workflows/release-esp32p4-firmware.yml`）：tag 发布时把
`build/adsb1090.uf2` 拷到 `dist/site/firmware/rp2040/latest/`（刷机页
"latest" 直链）与 `dist/release/pilot-kit-box-rp2040-<version>.uf2`
（Release 资产）。RP2040 镜像与 P4 板型无关，只在完整构建
（`BUILD_IS_COMPLETE == 'true'`）时产出。

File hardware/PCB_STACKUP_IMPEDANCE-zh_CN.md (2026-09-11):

# PCB 叠层与阻抗速查（多厂对照 · 板级通用参考）

英文版：[`PCB_STACKUP_IMPEDANCE.md`](PCB_STACKUP_IMPEDANCE.md)

> 数据来源：各厂**官方阻抗计算器**的一手数据（嘉立创 2026-08-23、华秋与捷配
> 2026-09-04）。本文只记官方数据和从它反标定出来的量，公式推算值一律标注出处。
> 适用范围：`expansion-board-v3` / `v4` 以及后续所有板子。
>
> **本文原名 `JLC_STACKUP_IMPEDANCE`，2026-09-04 改为厂商中立的现名** ——
> 这是个开源工程，别人会拿去任意板厂打，只记一家的参数没有意义。

---

## 0. 四条规则（先看这个）

1. **外层微带阻抗只由 L1–L2 介质厚 h 和线宽决定**，跟总板厚、层数都没关系。
   同一根 0.34mm 线，4 层板上 51.5Ω，6 层板上只有 31.8Ω。
2. **线宽以官方计算器为准，不要用裸微带公式下结论。** 手算公式不含阻焊层，绿油拉高
   有效介电常数，算出来的线一律偏粗（本板这个量级偏 4.6%）。
3. **该锁的是「单张 3313」这个规格，不是某一家厂。**
   玻璃布型号（3313 / 2116 / 1080 / 7628）是行业标准，各家都有；
   变的是压合后的厚度。**换厂时按玻璃布型号找，比按厂名找有效。**
4. 🔴 **阻抗失配的代价比直觉小得多，先算再决定要不要为它花钱。**
   本板射频走线最长 11.7mm ≈ λ/13，短线上失配形不成驻波。
   偏 40% 的失配损耗只有 **0.12dB**——见 §5。
   **不要一看到"阻抗不匹配"就判定板子不能用。**

---

## 1. 50Ω 外层微带线宽速查

外层铜厚 1oz。**h = L1–L2 介质厚**。

| 叠层 | 层数 | 成品板厚 | 收费 | L1–L2 介质 | **h (mm)** | **官方 50Ω 线宽** |
|---|---|---|---|---|---|---|
| `JLC0216A` | 2 | 1.34~1.64mm | 通用 | 芯板 1.5mm 1/1OZ | **1.4300** | **2.6916mm** |
| `JLC04161H-7628` | 4 | 1.59mm ±10% | 通用 | 7628 RC49% 8.6mil | **0.2104** | **0.3586mm** |
| `JLC06161H-3313` | 6 | 1.54mm ±10% | **免费** | 3313 RC57% 4.2mil | **0.0994** | **0.1509mm** |
| `JLC06161H-1080C` | 6 | 1.56mm ±10% | 特殊加钱 | 1080 RC67% 3.3mil | **0.0764** | **0.1072mm** |

四行全部是官方计算器直接给出的正算结果（阻抗模式：单端阻抗·外层，L1 为阻抗层、
L2 为下参考层，阻值公差 0.5）。前三行来自本次三张截图，1080C 那行来自 `51849d0`。

### 1.1 六层 1.6mm：三家横向对照（2026-09-04 实测）

本板用的是**六层 1.6mm、外层 1oz、内层 0.5oz**。三家在这个规格下的全部叠层：

| 厂 | 叠层 | L1–L2 玻璃布 | **h (mm)** | 官方 50Ω 线宽 | 本板 0.15mm 实得 |
|---|---|---|---|---|---|
| 嘉立创 | `JLC06161H-3313`（免费） | 3313 ×1 | **0.0994** | 0.1509mm | **50.1Ω** ✅ |
| 捷配 | `JP06161H-3313B2`（+¥200 起） | 3313 ×1 | **0.091** | 0.136mm | **47.7Ω** ✅ |
| 华秋 | `06161HA3-1080` | 1080 ×1 | 0.077 | 4.26mil | 42.4Ω |
| 华秋 | `06161HA4-1080` | 1080 ×1 | 0.077 | 4.26mil | 42.4Ω |
| 华秋 | `06161HA5-2116` | 2116 ×1 | 0.125 | 7.78mil | 57.0Ω |
| 捷配 | `JP06161H-7628A1`（**免费**） | 7628 ×1 | 0.186 | ≈12.5mil | 70.1Ω |
| 华秋 | `06161HA2-7628H` | 7628H ×1 | 0.230 | 15.68mil | 77.2Ω |

华秋/捷配的数值取自各自官方阻抗计算器（华秋"阻抗匹配叠层工具"、捷配层压结构表）；
"本板 0.15mm 实得"一列是用 `tools/microstrip_z0.py` 按各家官方数据点反标定 Dk 后正算的，
与华秋计算器互校吻合（2116 档我们算 7.78mil，官方也是 7.78mil）。

> **同为「单张 3313」的两家，h 只差 8.5%（0.0994 vs 0.091）。**
> 这就是规则 3 的依据：按玻璃布型号找厂，比按厂名找有效。

### 1.2 本板的「叠层窗口」

固定 0.15mm 线宽时，阻抗落在 ±10%（45–55Ω）所需的 h 范围：

    h = 0.085 ~ 0.115 mm      ← 直接投，不用改任何文件

窗口外也**不是不能做**，只是阻抗偏离，代价见 §5。

    h < 0.085     阻抗偏低（1080 单张 0.077 → 42Ω）
    h > 0.115     阻抗偏高（2116 0.125 → 57Ω；7628 0.19 → 70Ω）

> 🔴 **勘误（2026-08-23，本次）**：`JLC06161H-3313` 这格此前记的是 **≈0.158mm**，
> 那是用等效 Dk 4.5 推算的，不是官方值。官方正算是 **0.1509mm**，推算值偏粗 4.6%。
> 详见 §3。

---

## 2. 三份叠层的完整层结构

### 2.1 JLC04161H-7628（4 层，通用，成品板厚 1.59mm ±10%）

内层铜厚 0.5oz，外层铜厚 1oz，总厚度范围 **1.43 ~ 1.74mm**。

| 层 | 材料 | 参数 | 厚度 (mil) | 厚度 (mm) |
|---|---|---|---|---|
| L1 | 铜箔 | 1oz | 1.38 | 0.0350 |
| | 半固化片 | 7628 RC49% 8.6mil | 8.28 | **0.2104** |
| L2 | 芯板铜 | 1.1mm H/HOZ 含铜 | 0.60 | 0.0152 |
| | 芯板介质 | | 41.93 | 1.0650 |
| L3 | 芯板铜 | | 0.60 | 0.0152 |
| | 半固化片 | 7628 RC49% 8.6mil | 8.28 | 0.2104 |
| L4 | 铜箔 | 1oz | 1.38 | 0.0350 |

求和 = 1.5862mm ✅ 与标称 1.59mm 一致。

### 2.2 JLC0216A（2 层，成品板厚 1.6mm 档）

外层铜厚 1oz，总厚度范围 **1.34 ~ 1.64mm**。

| 层 | 材料 | 参数 | 厚度 (mil) | 厚度 (mm) |
|---|---|---|---|---|
| L1 | 芯板铜 | 1.5mm 1/1OZ 含铜 | 1.18 | 0.0300 |
| | 芯板介质 | | 56.30 | **1.4300** |
| L2 | 芯板铜 | | 1.18 | 0.0300 |

求和 = 1.49mm ✅ 正好是厚度范围中值。

> ⚠️ 2 层的外层铜是芯板自带的 **0.0300mm**，不是另外三个叠层的 0.0350mm。
> 反标定 Dk 时别混用。

### 2.3 JLC06161H-3313（6 层，免费叠层，成品板厚 1.54mm ±10%）

**v3 / v4 当前在用的就是这个。** 内层 0.5oz，外层 1oz，总厚度范围 **1.38 ~ 1.69mm**。

| 层 | 材料 | 参数 | 厚度 (mil) | 厚度 (mm) |
|---|---|---|---|---|
| L1 | 铜箔 | 1oz | 1.38 | 0.0350 |
| | 半固化片 | 3313 RC57% 4.2mil | 3.91 | **0.0994** |
| L2 | 芯板铜 | 0.55mm H/H 不含铜 | 0.60 | 0.0152 |
| | 芯板介质 | | 21.65 | 0.5500 |
| L3 | 芯板铜 | | 0.60 | 0.0152 |
| | 半固化片 | 2116 RC54% 4.9mil | 4.28 | 0.1088 |
| L4 | 芯板铜 | 0.55mm H/H 不含铜 | 0.60 | 0.0152 |
| | 芯板介质 | | 21.65 | 0.5500 |
| L5 | 芯板铜 | | 0.60 | 0.0152 |
| | 半固化片 | 3313 RC57% 4.2mil | 3.91 | 0.0994 |
| L6 | 铜箔 | 1oz | 1.38 | 0.0350 |

求和 = 1.5384mm ✅ 与标称 1.54mm 一致。

> 这个叠层是**对称**的：L1–L2 和 L5–L6 都是 0.0994mm。所以底层（L6）走 50Ω 微带，
> 参考面取 L5，线宽同样是 0.1509mm。

---

## 3. 等效 Dk：为什么不能只记一个 4.5

材料标称 Dk 是 **4.1**，但官方计算器的行为等价于一个更高的 Dk——差值来自**阻焊层**
（绿油拉高有效介电常数，同阻抗需要更细的线）。用 Hammerstad-Jensen 裸微带公式
（`tools/microstrip_z0.py`）从每个官方数据点反解：

```
叠层                           h        W     官方Z0     反标定Dk
JLC0216A        2层      1.4300   2.6916  50.0000     4.423
JLC04161H-7628  4层      0.2104   0.3586  50.0000     4.517
JLC06161H-3313  6层      0.0994   0.1509  50.0000     4.725
JLC06161H-3313  6层      0.0994   0.3400  31.8238     4.540
JLC06161H-1080C 6层      0.0764   0.1072  50.0000     4.936
```

**等效 Dk 不是常数，它随介质变薄而升高**：4.42 → 4.52 → 4.73 → 4.94。

物理上讲得通：阻焊厚度是固定的（约 0.02mm），h 越薄，绿油在总介质里占的比重越大，
等效 Dk 就越高。同一叠层内也一样——6 层 3313 上宽线（0.34mm）反标定 4.54，窄线
（0.1509mm）反标定 4.73，因为窄线的边缘场更多走表面的绿油。

> 🔴 **这推翻了「等效 Dk 4.5 全局自洽」的旧结论。**
> 4.5 只在 h ≥ 0.2mm 时准（4 层误差 0.3%）。在 h ≈ 0.1mm 的薄介质上，它会把 50Ω
> 线算成 0.158mm，而官方是 0.1509mm——**偏粗 4.6%**。
> 用法修正为：**每个叠层单独反标定一次，跨叠层不要外推。**

### 3.1 板上实际用的 0.15mm 是多少欧

按本叠层自己的标定值 Dk = 4.725：

| 线宽 | Z₀ | 说明 |
|---|---|---|
| **0.1509mm** | **50.0Ω** | 官方严格解 |
| **0.15mm（板上实际值）** | **≈50.1Ω** | 偏差 0.3%，远在 ±10% 公差内 |
| 0.34mm | 31.8Ω | 4 层板的旧值，6 层上严重失配 |

**0.15mm 是对的，不用改。** 顺带更正一处：IFA 文档早期写的「50Ω → 0.1509mm」
本来就是官方值，昨天按 Dk 4.5 推的 0.158 才是偏的。

---

## 5. 阻抗失配到底值多少 dB（先算这个，再决定要不要花钱）

这一节是 2026-09-04 补的。在此之前本文把"阻抗控制"写成硬约束，
**但从来没人算过偏了到底损失多少**，导致一路把它当成换厂的拦路虎。

本板射频走线**最长 11.7mm**，1090MHz 在微带上 λ ≈ 152mm，所以最长的线也才
**λ/13（28° 电长度）**。短线上的失配来不及形成驻波：

| 线阻抗 | 偏差 | 反射系数 \|Γ\| | 失配损耗 |
|---|---|---|---|
| 42Ω | −16% | 0.087 | **0.033 dB** |
| 47.7Ω | −5% | 0.024 | 0.002 dB |
| 57Ω | +14% | 0.065 | **0.019 dB** |
| 70Ω | +40% | 0.167 | **0.12 dB** |
| 77Ω | +54% | 0.213 | **0.20 dB** |

对照：本项目反复引用的判据是「SWR 2.0 的失配损耗只有 0.51dB，从来不是主要矛盾」。
**上表所有数字都比它小。**

### 5.1 那真正该担心什么

不是传输线损耗，是**两个对端接阻抗敏感的器件**：

- **SAW 滤波器**（`FL1`/`FL2`）：通带形状、插损、带外抑制都依赖源/负载阻抗
- **LNA**（`U11`）：噪声匹配与稳定性看输入阻抗

但这两处的匹配是由它们**周围的匹配元件**（`C40`–`C44`、`L9`–`L15` 等）做的，
不是靠传输线特征阻抗。传输线只负责把信号从 A 送到 B。

### 5.2 🔴 板载 IFA 天线**会**受板材影响 —— 换厂必须重调

> **本节此前写的是「IFA 天线不受叠层影响」，那是错的，2026-09-11 被实测推翻。**
> 原来的理由是「天线区全 6 铜层镂空，下方没有参考面，谐振只由顶层铜箔几何决定」。
> **错在把「镂空」当成了「没有介质」——镂掉的是铜，板材还在。**
> 天线铜箔下面仍压着 1.6mm 的 FR4，**板材的 εr 直接决定谐振频率**。

**同一份 Gerber、两家厂、实测对照**（V4.4，全板只贴 ZS1+J7+J6 三件，从 J7 测）：

| 厂 / 叠层 | SWR 谷底频率 | 谷底 SWR | 板上阻抗（已 de-embed）|
|---|---|---|---|
| 嘉立创 `JLC06161H-3313` | **1085.0 MHz** | **1.055** | 51.47 + j2.28 Ω |
| 捷配 `JP06161H-7628A1` | **1062.5 MHz** | **1.717** | 39.28 + j21.75 Ω |

**频率低了 22.5MHz（2.07%），而且匹配也变差了。** 反推 εeff 高出 **4.28%**，
与「7628 玻璃布含量高于 3313 → 复合 εr 更高」完全一致
（玻璃纤维 εr≈6.1，树脂 εr≈3.2，布含量越高整体 εr 越高）。

**换算成天线长度：按 `board_meta.py` 那组切铜实测的 11.5 MHz/mm 斜率，
等效于天线长了约 2.0mm。** 要在捷配板上把它拉回 1085MHz，得再切掉约 2mm。

> 🔴 **给开源用户：`ARM_OUT = 50.000mm` 这个值绑定的是嘉立创 3313 板材，不是普适常数。**
> 换厂打板，IFA 大概率需要重新调。方法见
> `expansion-board-v4/BOM_IFA_TUNING-zh_CN.md`：每次切 0.1–0.2mm，
> 用 11.5 MHz/mm 估算切多少，**以装盒后的 VNA 实测为准**。
>
> 注意这跟 §5 讲的传输线失配是**两件独立的事**：传输线失配只值 0.1dB，
> 而天线失谐 22.5MHz 会让 SWR 从 1.06 掉到 1.72（失配损耗 0.55dB），
> 且偏离了 1090MHz 这个非调不可的工作频点。

---

## 6. 给开源用户：拿这个工程去别的板厂打

本工程是开源的，任何人可以在任意板厂制造。**不需要凑齐本文列的某一家叠层。**

**必需项**（不满足就做不出来）：

    6 层，成品板厚 1.6mm，外层铜厚 1oz，内层铜厚 0.5oz
    最小线宽/线距 5/5 mil，最小孔径 0.30mm
    叠层顺序 F.Cu / In1(GND) / In2(信号) / In3(3V3) / In4(GND) / B.Cu
    🔴 树脂塞孔 + 电镀盖帽（POFV / 盘中孔工艺）

🔴 **POFV 是必需项，不是可选项，而且 Gerber 表达不了它。**

板上 **108 个过孔落在焊盘内**，其中 EP 散热盘中孔最要命：
`U10`×16、`U19`×9、`U8`×7、`U18`×4。这些孔所在的焊盘**必须开阻焊窗**（要焊接），
所以「过孔塞油」那道工序根本碰不到它们 —— 只有盘中孔工艺能把它们填实镀平。
不做的话，回流时锡膏顺孔漏到背面，EP 焊不牢。

    阻焊状态（盖不盖油）   由 Gerber 的阻焊层决定   ← 「按文件生产」管的是这个
    填孔（塞不塞实）       由下单时勾的工序决定     ← Gerber 里没有对应图层

2026-09-11 两家实板对照证实了这个分界：嘉立创订单勾了「盘中孔=需要」，
EP 是整片可焊的金面；捷配只勾了「过孔塞油」，EP 上 16 个孔全是裸通孔。
**两家都没做错，是我们以为「Gerber 决定一切」。**

> **肉眼判据**：金属色（连续、可焊）= POFV 合格；油墨色 = 只盖了油；
> 看得见孔壁 = 什么都没做。

**关于板材 TG**：本项目不设 TG 要求，各厂默认值即可。实测两家默认给的是
**捷配 TG150（建滔）/ 嘉立创 TG135** —— 注意**免费档不一定给低 TG**，
以订单详情页的实际值为准，别照抄别人的经验。TG 影响的是制造与返修时的耐热
（无铅回流 255℃、多次返修），**不影响射频性能**；本板孔径比仅 5.33:1，
TG135 也在安全范围。

**可选项 —— 阻抗控制**（影响 1090MHz 灵敏度，不影响能否工作）：

    顶层 50Ω 单端，L1 参考 L2。本设计按 L1–L2 介质 0.0994mm
    （单张 3313 半固化片）反算，走线宽 0.15mm。

    · 板厂能提供 L1–L2 = 0.085~0.115mm 的叠层
      → 直接投，无需改动。已验证：嘉立创 JLC06161H-3313、捷配 JP06161H-3313B2
    · 只能提供更厚的介质（如单张 7628 ≈ 0.19mm）
      → 仍可制造。射频走线阻抗约 70Ω，失配损耗约 0.12dB，
        1090 灵敏度略降，其余功能不受影响
    · 🔴 **板载 IFA 天线需要按你的板材重调**（见 §5.2）。
      50.0mm 这个铜箔长度绑定的是嘉立创 3313 板材，不是普适常数。
      实测：同一份 Gerber 在捷配 7628A1 上谐振低了 22.5MHz、SWR 从 1.06 掉到 1.72。
      调法：每次切 0.1–0.2mm，按 11.5MHz/mm 估算，以装盒后 VNA 实测为准。
      只用外接天线（U.FL/SMA）的话可以忽略这条。

**海外用户速查**（详见 §8）：**没有一家海外厂的默认叠层落在窗口内**，
但这不重要——**PCBWay（0.1195 / 55Ω / 0.011dB）和 OSH Park（0.1107 / 约 57Ω /
0.022dB）直接投就行**。欧洲两家主流（Aisler / Multi-CB）统一是 0.230mm / 77Ω /
0.20dB，能用但明显偏离，其中只有 Multi-CB 可以走自定义叠层修正。
🔴 **ALLPCB 官网已停运，不要用。**

**换厂时真正会害死板子的不是阻抗，是下面这些**：

    ① 层序：内层靠文件名 In1..In4 表达。若 CAM 倒序识别，
       In2(信号) 与 In3(3V3 平面) 对调 = 整板报废。
       In1/In4 都是 GND，认反无害。**只有 In2/In3 这一对是致命的。**
    ② 表面处理：必须沉金 ENIG，不能选喷锡 HASL。判据是 pitch 不是"射频板"：
       本板 U8 = QFN-56 / 0.4mm pitch / 焊盘 0.200mm，另有三个 LGA
       （U4 BNO085、U5 BMP388、U6）。HASL 共面度 ±5~15µm，业界公认
       0.5mm pitch 以下不可用；ENIG 在 0.5µm~±2µm 量级。
       QFN 还有个特有失效：大 EP 上堆出的锡丘会把周边引脚顶离板面。
       ⚠️「无铅喷锡」比有铅更差（SAC305 表面张力更高），别因为免费就选。
    ③ 槽孔：J4 的 4 个 SH 是 0.60mm 槽宽 × 1.70/1.20mm 的**电镀槽孔**
       （Excellon G85），不是圆孔。做树脂塞孔时必须排除它们。
    ④ 盘中孔：28 个 EP 散热过孔落在锡膏开窗内，不塞孔就是 28 个漏斗，
       回流时锡膏顺孔流走。要么加钱塞孔，要么重出避让过孔的 F.Paste。

这四项的失败概率，**远高于 0.1dB 失配的任何风险**。别为了省几百块砍掉它们。

**关于「过孔盖油/开窗」**：嘉立创、华秋、捷配三家的下单页都写着同一句话——
**「若是 Gerber 文件格式一律按文件加工，此选项无效」**。原因是 Gerber
分不清过孔和插件孔。所以过孔的阻焊状态**完全由文件决定**，下单页那几个选项
（盖油/开窗）对我们无效。本工程文件中：437 个过孔，401 个盖油、36 个裸露
（36 个全部落在焊盘开窗内，其中 28 个是 EP 散热盘中孔）。

---

## 7. 玻璃布是跨厂的共同语言（2026-09-04 调研）

四种半固化片玻璃布型号是 IPC 标准，**家家都有**；变的只是压合后的厚度。
三家官方数据实测（6 层 / 1.6mm 规格）：

| 玻璃布 | 各厂实测 h (mm) | 出处 |
|---|---|---|
| **1080** | 0.077 / 0.070(料厚) | 华秋 HA3 / HA4；Eurocircuits PR1080 |
| **3313** | 0.091 / **0.0994** | 捷配 3313B2 / **嘉立创（免费档）** |
| **2116** | 0.1055 / 0.1088 / 0.1195 / 0.120(料厚) / 0.125 / 0.230(×2 张) | PCBWay 30%残铜 / 嘉立创 4 层用 / PCBWay 70%残铜 / Eurocircuits PR2116 / 华秋 HA5 / **Aisler 与 Multi-CB** |
| **7628** | 0.1785 / **0.186** / 0.180(料厚) / 0.195(料厚) / 0.2104 / 0.230 | PCBWay 50%残铜 / **捷配 7628A1（免费档）** / Eurocircuits PR7628 / 捷配 / 嘉立创 4 层 / 华秋 7628H |
| FR408HR | 0.1107 | OSH Park（**非 FR4**，Dk≈3.66） |

**同型号跨厂差 8~24%**，2116 甚至能差到 118%（有人压一张、有人压两张）。
所以"按玻璃布型号找厂"可行，但仍需逐家核对**实际压合厚度**，
而且要问清楚**压几张**——这是最容易翻车的一处。

> 有意思的是两家的**免费档正好分居两端**：
> 嘉立创免费 = 3313（0.0994），捷配免费 = 7628（0.186）。

### 7.1 以各玻璃布为设计基准时的容差窗口

`tools/microstrip_z0.py` 算，判据是阻抗落在 45–55Ω：

| 基准 | 典型 h | 50Ω 线宽 | h 容差窗口 | 窗口宽度 | 能覆盖 |
|---|---|---|---|---|---|
| 1080 | 0.077 | 0.108mm | 0.064–0.090 | 0.027 | 华秋 |
| **3313** | 0.095 | **0.142mm** | 0.081–0.111 | 0.030 | 嘉立创 + 捷配 |
| 2116 | 0.118 | 0.189mm | 0.101–0.136 | 0.035 | 嘉立创4层 + 华秋 |
| **7628** | 0.190 | **0.331mm** | 0.160–0.225 | **0.065** | 捷配免费 + 嘉立创4层 + 华秋 |

**相对窗口都是 ±15~17%，但绝对窗口随 h 变大。**
7628 基准的窗口有 0.065mm 宽，是 3313 的两倍多——**厚介质基准的厂商兼容性更好**。

### 7.2 当前板子没有加宽余量（实测）

想做"一份布局、按厂切换线宽"，前提是布局能容下更宽的线。**实测结论是不能。**

做法：在板文件副本上把 RF50 的 106 段真改宽，**重灌覆铜**，再跑 `kicad-cli pcb drc`
（真 DRC，不是估算）：

| RF 线宽 | 铜层违例 |
|---|---|
| **0.15mm（现状）** | **0** |
| 0.166mm | 0（理论极限） |
| 0.17mm | 3 |
| 0.19mm | 4 |
| 0.25mm | 21 |
| 0.32mm | 24 |
| 0.331mm（7628 真 50Ω） | 28 |

**加 0.02mm 就开始违例。** 三处卡点（KiCad 碰撞几何实测）：

    U11 pad6 (GND) ↔ LNA1_OUT   两段，现有间距 0.1580mm（规则 0.15）
    C41 pad2 (GND) ↔ SUBG_N3    一段，现有间距 0.1569mm

总余量只有 0.008mm，加宽时两侧各吃一半 → **线宽极限 ≈0.166mm**，与上表吻合。

> 🔴 **勘误（2026-09-04）**：这两个数此前记的是 0.1430 / 0.1419，**错了**。
> 自相矛盾之处很明显：小于间距规则 0.15mm 的话，现状就该报违例，而现状是 0 违例。
> 复核用 `SHAPE::Collide()` 二分求最小净间距，得 0.1580 / 0.1569。
> 旧值系统性偏小 0.0150mm。**结论方向不变**（余量仍然极小），但极限线宽从
> "0.164"改为 0.166mm。

技术实现本身不难——线宽是逐段存在 `internal/tools/ROUTES.json` 的第 7 个字段
（`[net, layer, x1,y1, x2,y2, width]`），脚本改一行即可。
**瓶颈在布局，不在工具。**

到 0.331mm 时故障已经是**全域性**的，不再是"三处卡点"：28 处违例散落在
FL1 / FL2 / U11 / U16 / U14 / U7 / C41 / L1 / D3 / L10 共 10 个器件上，
覆盖 1090、978、GNSS 三条链的每一级，最窄处压到 0.060mm。
根因是 0.5mm pitch 封装的相邻焊盘间隙本来就只有 0.22–0.25mm，
而一条 0.331mm 的线要出脚需要 0.331+0.15 = **0.481mm 通道，比引脚间隙还宽一倍**。

> ⚠️ **改线宽/改间距后跑 DRC，必须先重灌覆铜（`ZONE_FILLER.Fill()`）。**
> 不重灌的话走线是新的、铜皮是旧的，会凭空多出几十条假违例。
> 典型特征：大量数值相同、且正好等于 `原间距 − 单边加宽量`。
> 实测：0.17mm 不重灌 82 条 / 重灌后 3 条；0.331mm 不重灌 112 条 / 重灌后 28 条。

### 7.3 下一版建议：双基准设计

若要让这块板"一份设计投任意厂"，下一版重新布线时按下面两个基准来：

    基准 A（薄）3313  h≈0.095  线宽 0.142mm  → 嘉立创免费档、捷配指定档
    基准 B（厚）7628  h≈0.190  线宽 0.331mm  → 捷配免费档、华秋、多数海外厂

**射频走廊与 keepout 按基准 B 的 0.331mm 画**，两种宽度就都不违规，
出 Gerber 时切一个参数即可。代价：射频区占地比现在大一倍多。

---

## 8. 海外板厂（2026-09-04 调研）

开源工程的现实：国外用户会拿 Gerber 去他们本地的厂打。下表是各厂**官网一手数据**，
数值全部标注出处；未取得的一律写"未取得"，不用行业经验填。

| 厂 | 叠层 | 玻璃布 | **h (mm)** | 本板 0.15mm | 失配损耗 | 判断 |
|---|---|---|---|---|---|---|
| **PCBWay** | 6L/1.6mm **30% 残铜** | 2116 | **0.1055** | **51.8Ω** ✅ | 0.001dB | 窗口内 |
| **OSH Park** | 6-Layer（唯一） | **FR408HR** | **0.1107** | 53.2 ~ **57.6Ω** | 0.004~0.022dB | 可直接投 |
| **PCBWay** | 6L/1.6mm **70% 残铜**（本板默认落这档） | 2116 | **0.1195** | **55.3Ω** | 0.011dB | 可直接投 |
| **PCBWay** | 6L/1.6mm 50% 残铜 | 7628 | 0.1785 | 68.5Ω | 0.107dB | 可用 |
| **Aisler** | 6 Layer 1.6mm 35µm（唯一） | **2116 ×2** | **0.230** | **76.8Ω** | 0.198dB | 可用，改不了 |
| **Multi-CB** | Defined buildup `6L-01` | **2116 ×2** | **0.230** | **76.8Ω** | 0.198dB | 可用，可自定义规避 |
| **Multi-CB** | Variable buildup（默认） | 不固定 | **不保证** | 不可预测 | — | 🔴 射频板别用 |
| **Eurocircuits** | 6L 拼板（唯一预定义档） | 未取得 | **未取得** | — | — | 需询价 |
| **Seeed Fusion** | 6L/1.6mm | 未公开 | **未取得** | — | — | 需询价 |
| **NextPCB** | 6L 阻抗控制 | 备 7628/1080/**2313**/2116 | **未取得** | — | — | 需询价 |
| **ALLPCB** | — | — | — | — | — | 🔴 官网已停运 |

阻抗一列的算法与 §1.1 一致（`tools/microstrip_z0.py` 按官方数据点反标定 Dk 后正算），
**不是**按 h 插值。Aisler / Multi-CB 那两行是用它们**自己公布的"50Ω 需 395µm"**
反标定出等效 Dk 4.512 再正算的，与华秋在同一 h 上反标定的 4.467 只差 1%——
两条互不相干的路径互相印证。

### 8.1 三个必须单独说明的坑

**① PCBWay 的 h 跟着「内层残铜率」变，还会跳玻璃布。** 同一个
6L/1.6mm 规格下三套叠层，L1–L2 从 0.1055 到 0.1785 差近一倍，
玻璃布从 2116 跳到 7628。本板 L2 是完整地平面 → 残铜率高 → **默认落 70% 那档
（0.1195 / 55.3Ω）**，直接投即可。想更准就在备注里点名 30% 那档。
另外 PCBWay 6 层 **内层铜最薄只有 1oz，没有 0.5oz 选项**——§6 必需项里写的
"内层 0.5oz"在 PCBWay 不成立。

**② OSH Park 用的不是 FR4，别套本文的 Dk。** 板材是 ISOLA
FR408-HR（Dk≈3.66，本文其余各厂等效 Dk 在 4.47~4.73）。介质薄本该压低阻抗、
Dk 低又推高阻抗，两者反向抵消：按 FR4 等效 Dk 算是 53.2Ω，按 Dk 比例修正
（×√(4.3/3.66)=1.084）是 57.6Ω。**真值在这两个数之间，都在可接受区间内。**
OSH Park 不提供阻抗控制、不接受自定义叠层、**不做贴片**，只出裸板。

**③ Aisler 和 Multi-CB 的 6 层叠层完全相同**（2×2116 = 230µm、εr 4.25、
50Ω 需 395µm 线宽），数据来自两个互相独立的官网。这说明**欧洲小批量厂共用同一套
FR4 叠层规范**——欧洲用户直接投，拿到的基本都是 ~77Ω / 0.2dB。
其中只有 Multi-CB 允许走 Custom buildup 修正。

### 8.2 各厂的阻抗控制 / 自定义叠层 / 贴片

| 厂 | 阻抗控制 | 自定义叠层 | SMT | 备注 |
|---|---|---|---|---|
| PCBWay | 有（±10%，50Ω 及以下 ±5Ω） | **允许** | 有 | 6 层 74 个标准叠层 |
| OSH Park | **无** | **不允许** | **无** | $15/in²，含 3 片，12–21 日历日 |
| Aisler | 无正式服务，但公开叠层与 50Ω 线宽 | 不允许 | 有 | 6L/100×100mm 12 片 $360，13 工作日 |
| Multi-CB | 有，**额外收费** | **允许**（Custom） | 未见 | Defined buildup **免费**；⚠️ 只卖给企业/机构 |
| Eurocircuits | **有专门的 DEFINED IMPEDANCE pool**（1 片起、±10%） | 允许（Special，不在线出价） | 有 | 欧洲唯一有正规阻抗服务的 |
| Seeed Fusion | 报价器有勾选项 | 报价页无 | 有 | 6L/100×100mm 10 片 $336.51 |
| NextPCB | 有（4~20 层） | **允许** | 未取得 | 备料含 2313（注意不是 3313） |

### 8.3 未取得的数据，以及该问什么

Eurocircuits 的叠层数据在 Buildup Editor 里，**需注册登录**才看得到。
但从它官网公布的备料清单可以定下界：只有 **PR1080(70µm) / PR2116(120µm) /
PR7628(180µm)** 三种，且官网明写"我们几乎总是压两张 prepreg"。
**它没有 3313**，做不出 0.0994 那一档；最薄组合 2×PR1080 ≈ 0.140mm。
（这段是从备料清单推导，非实测，下单前必须问。）

问客服的原话，三家通用：

> For 6 layers / 1.6mm / 1oz outer: **what is the pressed dielectric thickness
> between L1 and L2, and which prepreg construction is used (how many plies)?**
> We need 50Ω single-ended microstrip on the outer layer at 0.15mm track width.

---

## 9. 复算工具

```bash
python3 hardware/tools/microstrip_z0.py                    # 官方数据点 + 反标定 Dk
python3 hardware/tools/microstrip_z0.py 0.15 0.0994 4.725  # W h Dk -> Z0
```

换厂/换叠层时的正确流程：

1. **先查该厂叠层的 L1–L2 厚度**，看落不落在 §1.2 的窗口（0.085~0.115mm）内。
   在窗口内 → 到此为止，文件不用动。
2. 不在窗口内 → **先按 §5 算失配代价**，再决定要不要改。
   0.1~0.2dB 的损失通常不值得为它重布整个射频区。
3. 真要改线宽：在该厂官方计算器上**正算**一次 50Ω 线宽（这个值直接用），
   不要拿别家的 Dk 外推。想在同一叠层里推别的阻抗，用 `solve_er()`
   从官方数据点反标定 Dk 再插值。
4. 改完线宽，**全仓库 grep 一遍旧值**——写死的副本已经害过我们五次
   （见 v3/v4 内部工程记录中的布线约束文件）。

> 🔴 **换叠层时最阴的一类隐患：以 h 为来历、但写死成数字的常量。**
> 它们不会报错，会**静默通过**，因为断言比的是那个写死的数字，不是 h。
>
> 已知一处：`route_ifa_feed.py` 的 `NO_CU_FLOOR = 0.30`，注释写明来历是
> **3 × 0.0994（3313 的三倍介质厚，微带边缘场衰减距离）**。换到 7628
> （h=0.186）后正确下限是 **0.558mm**，而当前 `NO_CU = 0.50` 已经不够——
> 断言却照样通过。后果是 IFA 馈线从纯微带变成半共面波导（地铜落在 2.7h 而非 5h）。
>
> 影响方向是**良性的**（共面地把 Z₀ 往下拉，反而更靠近 50Ω），
> 所以这不构成"不能投"，但抽检时别因为读数比纯微带模型好就怀疑测错了。
>
> **换叠层时，把所有"来历是 h 的倍数"的常量都找出来重算一遍。**

各厂官方计算器：

| 厂 | 入口 |
|---|---|
| 嘉立创 | <https://tools.jlc.com/#/impedanceCalculation> |
| 华秋 | <https://www.hqpcb.com/quote/impedance>（下单页「阻抗匹配叠层计算」同一个） |
| 捷配 | 计价页 →「叠层结构」→「更多层压结构」，点开每档看压合厚度 |

> ⚠️ 华秋计算器的「计算结果」一列是**调整线宽之后**达到的阻抗，
> 不是你输入的线宽的阻抗。要看的是**「线宽」**那一列（它给出的 50Ω 所需宽度）。
> 这一列容易看反。

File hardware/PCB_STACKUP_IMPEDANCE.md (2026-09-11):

# PCB Stackup & Impedance Quick Reference (Multi-Vendor · Board-Level General Reference)

Chinese version: [`PCB_STACKUP_IMPEDANCE-zh_CN.md`](PCB_STACKUP_IMPEDANCE-zh_CN.md)

> Data source: first-hand data from each vendor's **official impedance calculator**
> (JLCPCB 2026-08-23; HQPCB and JiePei 2026-09-04).
> This document records only official data and quantities back-solved from it; any formula-derived value is labeled with its source.
> Applies to: `expansion-board-v3` / `v4` and all subsequent boards.
>
> **This file was named `JLC_STACKUP_IMPEDANCE` until 2026-09-04, when it was renamed to be vendor-neutral** —
> this is an open-source project, people will fab it anywhere, and recording only one vendor's parameters is useless.

---

## 0. Four Rules (Read This First)

1. **Outer-layer microstrip impedance is set only by the L1–L2 dielectric thickness h and the trace width** —
   total board thickness and layer count are irrelevant. The same 0.34mm trace is 51.5Ω on a 4-layer board but only 31.8Ω on a 6-layer board.
2. **Take trace widths from the official calculator; never settle a value with the bare microstrip formula.** Hand-calc formulas omit the solder mask, and solder mask raises the
   effective Dk, so formula-derived traces always come out too wide (4.6% too wide at this board's scale).
3. **What you must pin down is the "single-ply 3313" spec, not a particular vendor.**
   Glass styles (3313 / 2116 / 1080 / 7628) are industry standards that every vendor carries;
   what differs is the pressed thickness. **When switching vendors, search by glass style, not by vendor name.**
4. 🔴 **Impedance mismatch costs far less than intuition suggests — do the math before spending money on it.**
   The longest RF trace on this board is 11.7mm ≈ λ/13; a mismatch on such a short line never builds a standing wave.
   A 40% impedance error costs only **0.12dB** — see §5.
   **Do not declare a board unusable just because the impedance does not match.**

---

## 1. 50Ω Outer-Layer Microstrip Trace Width Quick Reference

Outer-layer copper is 1oz. **h = L1–L2 dielectric thickness**.

| Stackup | Layers | Finished thickness | Fee | L1–L2 dielectric | **h (mm)** | **Official 50Ω trace width** |
|---|---|---|---|---|---|---|
| `JLC0216A` | 2 | 1.34~1.64mm | Standard | Core 1.5mm 1/1OZ | **1.4300** | **2.6916mm** |
| `JLC04161H-7628` | 4 | 1.59mm ±10% | Standard | 7628 RC49% 8.6mil | **0.2104** | **0.3586mm** |
| `JLC06161H-3313` | 6 | 1.54mm ±10% | **Free** | 3313 RC57% 4.2mil | **0.0994** | **0.1509mm** |
| `JLC06161H-1080C` | 6 | 1.56mm ±10% | Extra fee | 1080 RC67% 3.3mil | **0.0764** | **0.1072mm** |

All four rows are forward-calculation results given directly by the official calculator (impedance mode: single-ended impedance · outer layer, with L1 as the impedance layer and
L2 as the lower reference layer, impedance tolerance 0.5). The first three rows come from this batch of three screenshots; the 1080C row comes from `51849d0`.

> 🔴 **Erratum (2026-08-23, this update)**: the `JLC06161H-3313` cell previously recorded **≈0.158mm**,
> which was derived from an equivalent Dk of 4.5, not an official value. The official forward calculation gives **0.1509mm**; the derived value is 4.6% too wide.
> See §3 for details.

---

### 1.1 Six-layer 1.6mm: three vendors side by side (measured 2026-09-04)

This board is **6 layers, 1.6mm, 1oz outer, 0.5oz inner**. Every stackup the three vendors offer at that spec:

| Vendor | Stackup | L1–L2 glass | **h (mm)** | Official 50Ω width | This board's 0.15mm gives |
|---|---|---|---|---|---|
| JLCPCB | `JLC06161H-3313` (free) | 3313 ×1 | **0.0994** | 0.1509mm | **50.1Ω** ✅ |
| JiePei | `JP06161H-3313B2` (from ¥200) | 3313 ×1 | **0.091** | 0.136mm | **47.7Ω** ✅ |
| HQPCB | `06161HA3-1080` | 1080 ×1 | 0.077 | 4.26mil | 42.4Ω |
| HQPCB | `06161HA4-1080` | 1080 ×1 | 0.077 | 4.26mil | 42.4Ω |
| HQPCB | `06161HA5-2116` | 2116 ×1 | 0.125 | 7.78mil | 57.0Ω |
| JiePei | `JP06161H-7628A1` (**free**) | 7628 ×1 | 0.186 | ~12.5mil | 70.1Ω |
| HQPCB | `06161HA2-7628H` | 7628H ×1 | 0.230 | 15.68mil | 77.2Ω |

HQPCB/JiePei figures come from their own official calculators. The "0.15mm gives" column was
computed with `tools/microstrip_z0.py` after back-solving Dk from each vendor's official data
point, and cross-checks against HQPCB's calculator (we get 7.78mil for the 2116 case; so does theirs).

> **Two vendors, both "single-ply 3313", and h differs by only 8.5% (0.0994 vs 0.091).**
> That is the basis for Rule 3: search by glass style, not by vendor name.

### 1.2 This board's "stackup window"

With the trace width fixed at 0.15mm, the h range that keeps impedance within ±10% (45–55Ω):

    h = 0.085 ~ 0.115 mm      <- send as-is, no file changes

Outside the window is **not** unbuildable, the impedance just drifts; see §5 for the cost.

    h < 0.085     impedance low  (single-ply 1080, 0.077 -> 42Ω)
    h > 0.115     impedance high (2116 0.125 -> 57Ω; 7628 0.19 -> 70Ω)

---

## 2. Full Layer Structure of the Three Stackups

### 2.1 JLC04161H-7628 (4 layers, standard, finished thickness 1.59mm ±10%)

Inner-layer copper is 0.5oz and outer-layer copper is 1oz; total thickness range **1.43 ~ 1.74mm**.

| Layer | Material | Spec | Thickness (mil) | Thickness (mm) |
|---|---|---|---|---|
| L1 | Copper foil | 1oz | 1.38 | 0.0350 |
| | Prepreg | 7628 RC49% 8.6mil | 8.28 | **0.2104** |
| L2 | Core copper | 1.1mm H/HOZ with copper | 0.60 | 0.0152 |
| | Core dielectric | | 41.93 | 1.0650 |
| L3 | Core copper | | 0.60 | 0.0152 |
| | Prepreg | 7628 RC49% 8.6mil | 8.28 | 0.2104 |
| L4 | Copper foil | 1oz | 1.38 | 0.0350 |

Sum = 1.5862mm ✅ Matches the nominal 1.59mm.

### 2.2 JLC0216A (2 layers, finished thickness 1.6mm class)

Outer-layer copper is 1oz; total thickness range **1.34 ~ 1.64mm**.

| Layer | Material | Spec | Thickness (mil) | Thickness (mm) |
|---|---|---|---|---|
| L1 | Core copper | 1.5mm 1/1OZ with copper | 1.18 | 0.0300 |
| | Core dielectric | | 56.30 | **1.4300** |
| L2 | Core copper | | 1.18 | 0.0300 |

Sum = 1.49mm ✅ Exactly the midpoint of the thickness range.

> ⚠️ On the 2-layer board, the outer copper is the core's own **0.0300mm**, not the 0.0350mm of the other three stackups.
> Don't mix them when back-solving Dk.

### 2.3 JLC06161H-3313 (6 layers, the free stackup, finished thickness 1.54mm ±10%)

**This is the one v3 / v4 currently use.** Inner layers 0.5oz, outer layers 1oz; total thickness range **1.38 ~ 1.69mm**.

| Layer | Material | Spec | Thickness (mil) | Thickness (mm) |
|---|---|---|---|---|
| L1 | Copper foil | 1oz | 1.38 | 0.0350 |
| | Prepreg | 3313 RC57% 4.2mil | 3.91 | **0.0994** |
| L2 | Core copper | 0.55mm H/H without copper | 0.60 | 0.0152 |
| | Core dielectric | | 21.65 | 0.5500 |
| L3 | Core copper | | 0.60 | 0.0152 |
| | Prepreg | 2116 RC54% 4.9mil | 4.28 | 0.1088 |
| L4 | Core copper | 0.55mm H/H without copper | 0.60 | 0.0152 |
| | Core dielectric | | 21.65 | 0.5500 |
| L5 | Core copper | | 0.60 | 0.0152 |
| | Prepreg | 3313 RC57% 4.2mil | 3.91 | 0.0994 |
| L6 | Copper foil | 1oz | 1.38 | 0.0350 |

Sum = 1.5384mm ✅ Matches the nominal 1.54mm.

> This stackup is **symmetric**: both L1–L2 and L5–L6 are 0.0994mm. So a 50Ω microstrip on the bottom layer (L6),
> referencing L5, likewise uses a 0.1509mm trace width.

---

## 3. Equivalent Dk: Why a Single 4.5 Won't Do

The materials' nominal Dk is **4.1**, yet the official calculator behaves as if the Dk were higher — the difference comes from the **solder mask**
(solder mask raises the effective Dk, so the same impedance requires a narrower trace). Back-solving each official data point with the Hammerstad-Jensen bare microstrip formula
(`tools/microstrip_z0.py`):

```
叠层                           h        W     官方Z0     反标定Dk
JLC0216A        2层      1.4300   2.6916  50.0000     4.423
JLC04161H-7628  4层      0.2104   0.3586  50.0000     4.517
JLC06161H-3313  6层      0.0994   0.1509  50.0000     4.725
JLC06161H-3313  6层      0.0994   0.3400  31.8238     4.540
JLC06161H-1080C 6层      0.0764   0.1072  50.0000     4.936
```

**The equivalent Dk is not a constant — it rises as the dielectric gets thinner**: 4.42 → 4.52 → 4.73 → 4.94.

This is physically sound: solder mask thickness is fixed (about 0.02mm), so the thinner h is, the larger a share of the total dielectric the solder mask becomes,
and the higher the equivalent Dk. The same holds within one stackup — on the 6-layer 3313, a wide trace (0.34mm) back-solves to 4.54 while a narrow trace
(0.1509mm) back-solves to 4.73, because a narrow trace's fringe fields travel more through the surface solder mask.

> 🔴 **This overturns the old conclusion that "an equivalent Dk of 4.5 is globally self-consistent."**
> 4.5 is accurate only when h ≥ 0.2mm (0.3% error on the 4-layer). On a thin dielectric with h ≈ 0.1mm, it computes the 50Ω
> trace as 0.158mm while the official value is 0.1509mm — **4.6% too wide**.
> Corrected usage: **back-solve once per stackup, and never extrapolate across stackups.**

### 3.1 How Many Ohms Is the 0.15mm Actually Used on the Board

Using this stackup's own calibration value, Dk = 4.725:

| Trace width | Z₀ | Notes |
|---|---|---|
| **0.1509mm** | **50.0Ω** | Official exact solution |
| **0.15mm (actual board value)** | **≈50.1Ω** | 0.3% off, well within the ±10% tolerance |
| 0.34mm | 31.8Ω | Old 4-layer value; badly mismatched on 6 layers |

**0.15mm is correct — no change needed.** One related correction: the "50Ω → 0.1509mm" written early in the archived v3 antenna study (internal engineering notes)
was the official value all along; it was yesterday's 0.158, derived from Dk 4.5, that was off.

---

## 5. What an Impedance Mismatch Actually Costs (do this math first)

Added 2026-09-04. Before that, this document treated "impedance control" as a hard
constraint **without anyone ever computing how much a mismatch actually costs**, which
turned it into a phantom blocker whenever a vendor change came up.

The longest RF trace on this board is **11.7mm**; at 1090MHz, λ ≈ 152mm on microstrip,
so even the longest run is only **λ/13 (28° electrical length)**. A mismatch on a line
that short never builds a standing wave:

| Trace Z0 | Error | \|Γ\| | Mismatch loss |
|---|---|---|---|
| 42Ω | −16% | 0.087 | **0.033 dB** |
| 47.7Ω | −5% | 0.024 | 0.002 dB |
| 57Ω | +14% | 0.065 | **0.019 dB** |
| 70Ω | +40% | 0.167 | **0.12 dB** |
| 77Ω | +54% | 0.213 | **0.20 dB** |

For comparison, the criterion this project quotes repeatedly is "an SWR of 2.0 costs only
0.51dB of mismatch loss, it has never been the main problem." **Every number above is smaller than that.**

### 5.1 What actually deserves attention

Not transmission-line loss, but the **two devices that are sensitive to termination impedance**:

- **SAW filters** (`FL1`/`FL2`): passband shape, insertion loss and out-of-band rejection all depend on source/load impedance
- **LNA** (`U11`): noise match and stability depend on input impedance

But both are matched by their **surrounding matching components** (`C40`–`C44`, `L9`–`L15`),
not by the characteristic impedance of the trace. The trace only carries the signal from A to B.

### 5.2 🔴 The on-board IFA antenna **is** affected by the laminate — retune when changing fabs

> **This section previously claimed "the IFA antenna is unaffected by the stackup". That was
> wrong, and was disproven by measurement on 2026-09-11.** The old reasoning was "the antenna
> area is cleared on all 6 copper layers, so there is no reference plane and resonance depends
> only on top-layer geometry." **The error: "cleared" meant cleared of *copper*, not of
> *dielectric*.** There is still 1.6mm of FR-4 under the antenna trace, and **the laminate's
> εr sets the resonant frequency directly.**

**Same Gerber, two fabs, measured side by side** (V4.4, only ZS1+J7+J6 populated, probed at J7):

| Fab / stackup | SWR minimum | SWR at minimum | Impedance at board (de-embedded) |
|---|---|---|---|
| JLCPCB `JLC06161H-3313` | **1085.0 MHz** | **1.055** | 51.47 + j2.28 Ω |
| JiePei `JP06161H-7628A1` | **1062.5 MHz** | **1.717** | 39.28 + j21.75 Ω |

**22.5MHz lower (2.07%), and the match degraded too.** Back-solving gives an εeff **4.28%
higher**, consistent with 7628 carrying more glass than 3313 (glass εr≈6.1 vs resin εr≈3.2 —
more glass means higher composite εr).

**In trace length: using the 11.5 MHz/mm slope measured during the trim experiments in
`board_meta.py`, that is equivalent to the antenna being ~2.0mm too long.** Pulling it back
to 1085MHz on the JiePei board would require trimming roughly 2mm more.

> 🔴 **For open-source users: `ARM_OUT = 50.000mm` is tied to JLCPCB's 3313 laminate. It is
> not a universal constant.** Fabbing elsewhere will most likely require retuning the IFA.
> Procedure is in `expansion-board-v4/BOM_IFA_TUNING-zh_CN.md`: trim 0.1–0.2mm at a time,
> use 11.5 MHz/mm to estimate how much, and **judge by VNA measurement in the enclosure**.
>
> Note this is **independent of** the transmission-line mismatch discussed in §5: that
> mismatch costs only ~0.1dB, whereas a 22.5MHz antenna detune takes SWR from 1.06 to 1.72
> (0.55dB mismatch loss) and moves off 1090MHz, which is not a negotiable frequency.

---

## 6. For Open-Source Users: Fabbing This at Another Vendor

This project is open source and can be manufactured anywhere.
**You do not need to source one of the exact stackups listed here.**

**Required** (otherwise the board cannot be built):

    6 layers, 1.6mm finished thickness, 1oz outer copper, 0.5oz inner copper
    Minimum trace/space 5/5 mil, minimum hole 0.30mm
    Layer order: F.Cu / In1(GND) / In2(signal) / In3(3V3) / In4(GND) / B.Cu
    🔴 Resin-filled and plated-over vias (POFV / via-in-pad process)

🔴 **POFV is mandatory, not optional — and the Gerber cannot express it.**

**108 vias land inside pads** on this board; the thermal via-in-pads are the critical
ones: `U10`×16, `U19`×9, `U8`×7, `U18`×4. Those pads **must have solder-mask openings**
(they get soldered), so the "via tenting/plugging" step never touches them — only the
via-in-pad process can fill and plate them flat. Skip it and reflow paste drains through
the holes, leaving the exposed pads unsoldered.

    Solder-mask state (tented or not)   set by the Gerber's mask layer   <- "per file" covers this
    Hole fill (plugged or not)          set by the process you order     <- no Gerber layer exists

Confirmed 2026-09-11 by two real boards from the same Gerber: the JLCPCB order had
"via-in-pad: required" ticked and its exposed pads came back as continuous solderable
gold; the JiePei order only had "via plugging (ink)" and its 16 holes came back bare and
open. **Neither fab did anything wrong — we assumed the Gerber decided everything.**

> **Visual check:** metallic and continuous = POFV, good; ink-coloured (green/black) =
> tented only; barrel visible = nothing was done.

**On laminate Tg:** this project sets no Tg requirement — each fab's default is fine.
Measured defaults from the two orders: **JiePei Tg150 (KB) / JLCPCB Tg135**. Note that
**a free-tier order does not necessarily mean low Tg**; go by the actual value on your
order page rather than by someone else's experience. Tg governs heat resistance during
manufacturing and rework (255℃ lead-free reflow, repeated rework), **not RF
performance**; with an aspect ratio of only 5.33:1 here, Tg135 is well within range.

**Optional — impedance control** (affects 1090MHz sensitivity, not whether the board works):

    50Ω single-ended on the top layer, L1 referenced to L2. This design derives a
    0.15mm trace width from an L1–L2 dielectric of 0.0994mm (single-ply 3313 prepreg).

    · Your fab offers an L1–L2 of 0.085~0.115mm
      -> Send it as-is, no changes needed.
         Verified: JLCPCB JLC06161H-3313, JiePei JP06161H-3313B2
    · Your fab only offers a thicker dielectric (e.g. single-ply 7628 ~= 0.19mm)
      -> Still manufacturable. RF traces land around 70Ω, mismatch loss ~0.12dB,
         1090 sensitivity drops slightly, everything else is unaffected
    · 🔴 **The on-board IFA antenna must be retuned for your laminate** (see §5.2).
      The 50.0mm copper length is tied to JLCPCB's 3313 laminate, not a universal constant.
      Measured: the same Gerber on JiePei's 7628A1 resonated 22.5MHz lower, SWR 1.06 -> 1.72.
      Procedure: trim 0.1-0.2mm at a time, estimate with 11.5MHz/mm, judge by VNA
      measurement in the enclosure. Ignore this if you only use the external U.FL/SMA antenna.

**Quick guide for users outside China** (details in §8): **no overseas fab's default stackup
lands inside the window**, and that turns out not to matter — **PCBWay (0.1195 / 55Ω / 0.011dB)
and OSH Park (0.1107 / ~57Ω / 0.022dB) can simply be ordered as-is**. The two mainstream European
fabs (Aisler / Multi-CB) both press 0.230mm → 77Ω → 0.20dB: usable but clearly off, and only
Multi-CB can correct it via a custom buildup. 🔴 **ALLPCB's website is suspended — do not use.**

**What will actually ruin the board when changing vendors is not impedance:**

    (1) Layer order: inner layers are identified only by the In1..In4 filenames.
        If a CAM operator reverses them, In2 (signal) and In3 (3V3 plane) swap
        and the board is scrap. In1/In4 are both GND, so swapping those is harmless.
        **Only the In2/In3 pair is fatal.**
    (2) Surface finish: ENIG is mandatory, not HASL. The criterion is pitch,
        not "it's an RF board": U8 is a QFN-56 at 0.4mm pitch with 0.200mm
        pads, plus three LGAs (U4 BNO085, U5 BMP388, U6). HASL coplanarity
        is ±5–15µm and is widely held to be unusable below 0.5mm pitch;
        ENIG sits in the 0.5µm–±2µm range. QFNs have an extra failure mode:
        the solder dome on the large exposed pad lifts the perimeter leads
        off the board.
        ⚠️ Lead-free HASL is *worse* than leaded (SAC305 has higher surface
        tension) — don't pick it just because it's free.
    (3) Slots: J4's four SH holes are **plated slots** 0.60mm wide ×
        1.70/1.20mm long (Excellon G85), not round holes. Exclude them from
        any resin plugging.
    (4) Via-in-pad: 28 thermal vias sit inside paste apertures. Unplugged, they
        are 28 funnels that drain paste during reflow. Either pay for plugging,
        or re-issue an F.Paste that avoids the vias.

Each of these fails far more often than a 0.1dB mismatch ever will. Don't cut them to save money.

**On "via tenting / via opening"**: JLCPCB, HQPCB and JiePei all print the same sentence on
their order pages — **"if the file is Gerber format, we process strictly per the file; this
option has no effect"** — because Gerber cannot distinguish vias from component through-holes.
So via solder-mask state is **entirely determined by the file**. In this project: 437 vias,
401 tented and 36 exposed (all 36 fall inside pad mask openings; 28 of them are thermal
via-in-pad under exposed pads).

---

## 7. Glass Style Is the Cross-Vendor Common Language (surveyed 2026-09-04)

The four prepreg glass styles are IPC standards that **every vendor carries**; only the
pressed thickness differs. Measured from three vendors' official data (6-layer / 1.6mm):

| Glass style | Measured h per vendor (mm) | Source |
|---|---|---|
| **1080** | 0.077 / 0.070 (raw) | HQPCB HA3 / HA4; Eurocircuits PR1080 |
| **3313** | 0.091 / **0.0994** | JiePei 3313B2 / **JLCPCB (free tier)** |
| **2116** | 0.1055 / 0.1088 / 0.1195 / 0.120 (raw) / 0.125 / 0.230 (×2 plies) | PCBWay 30% residual / JLCPCB 4-layer / PCBWay 70% residual / Eurocircuits PR2116 / HQPCB HA5 / **Aisler and Multi-CB** |
| **7628** | 0.1785 / **0.186** / 0.180 (raw) / 0.195 (raw) / 0.2104 / 0.230 | PCBWay 50% residual / **JiePei 7628A1 (free tier)** / Eurocircuits PR7628 / JiePei / JLCPCB 4-layer / HQPCB 7628H |
| FR408HR | 0.1107 | OSH Park (**not FR4**, Dk≈3.66) |

**The same glass style varies 8–24% between vendors** — and 2116 spans 118%, because some
vendors press one ply and others press two. Searching by glass style works, but you still have
to check each vendor's actual pressed thickness **and ask how many plies** — that last part is
the easiest way to get burned.

> Note the two free tiers sit at opposite ends:
> JLCPCB free = 3313 (0.0994), JiePei free = 7628 (0.186).

### 7.1 Tolerance window for each glass style used as the design basis

Computed with `tools/microstrip_z0.py`; criterion is impedance landing in 45–55Ω:

| Basis | Typical h | 50Ω width | h tolerance window | Window width | Covers |
|---|---|---|---|---|---|
| 1080 | 0.077 | 0.108mm | 0.064–0.090 | 0.027 | HQPCB |
| **3313** | 0.095 | **0.142mm** | 0.081–0.111 | 0.030 | JLCPCB + JiePei |
| 2116 | 0.118 | 0.189mm | 0.101–0.136 | 0.035 | JLCPCB 4L + HQPCB |
| **7628** | 0.190 | **0.331mm** | 0.160–0.225 | **0.065** | JiePei free + JLCPCB 4L + HQPCB |

**Relative windows are all ±15–17%, but the absolute window grows with h.**
The 7628 basis gives a 0.065mm window — more than twice the 3313 basis.
**A thicker-dielectric basis is more vendor-portable.**

### 7.2 The current board has no widening headroom (measured)

"One layout, switch trace width per vendor" requires the layout to accommodate wider traces.
**Measured answer: it cannot.**

Method: on a copy of the board, actually widen all 106 RF50 segments, **refill the zones**,
then run `kicad-cli pcb drc` (real DRC, not an estimate):

| RF trace width | Copper violations |
|---|---|
| **0.15mm (current)** | **0** |
| 0.166mm | 0 (theoretical limit) |
| 0.17mm | 3 |
| 0.19mm | 4 |
| 0.25mm | 21 |
| 0.32mm | 24 |
| 0.331mm (true 50Ω on 7628) | 28 |

**Adding 0.02mm already produces violations.** Three blocking spots (measured with KiCad's
collision geometry):

    U11 pad6 (GND) <-> LNA1_OUT   two segments, current gap 0.1580mm (rule 0.15)
    C41 pad2 (GND) <-> SUBG_N3    one segment, current gap 0.1569mm

Total headroom is only 0.008mm, and widening consumes half of it on each side, so the
**width ceiling is ≈0.166mm** — consistent with the table above.

> 🔴 **Correction (2026-09-04):** these two gaps were previously recorded as 0.1430 / 0.1419.
> That was **wrong**, and self-contradictory: a gap below the 0.15mm clearance rule would make
> the current board report violations, yet the current board is clean. Re-measured by bisecting
> `SHAPE::Collide()` for the minimum clearance: 0.1580 / 0.1569. The old values were
> systematically 0.0150mm low. **The conclusion is unchanged** (headroom is still tiny), but the
> width ceiling moves from "0.164" to 0.166mm.

The implementation itself is trivial — width is stored per segment as field 7 of
`internal/tools/ROUTES.json` (`[net, layer, x1,y1, x2,y2, width]`), so a script can rewrite it.
**The bottleneck is the layout, not the tooling.**

At 0.331mm the failure is no longer three spots but **board-wide**: 28 violations spread across
ten components — FL1 / FL2 / U11 / U16 / U14 / U7 / C41 / L1 / D3 / L10 — hitting every stage of
all three chains (1090, 978, GNSS), with the tightest gap squeezed to 0.060mm. The root cause is
that 0.5mm-pitch packages only have 0.22–0.25mm between adjacent pads, while a 0.331mm trace
needs a 0.331 + 0.15 = **0.481mm channel to escape a pin — wider than the pin gap itself**.

> ⚠️ **After changing trace widths or clearances, refill the zones (`ZONE_FILLER.Fill()`)
> before running DRC.** Otherwise the traces are new but the copper pours are stale, and dozens
> of phantom violations appear. Telltale sign: many identical values, each exactly
> `original gap − half the width increase`. Measured: 0.17mm gives 82 violations without a
> refill vs 3 with; 0.331mm gives 112 vs 28.

### 7.3 Proposal for the next revision: dual-basis design

To make this board "one design, any fab", route the next revision against both:

    Basis A (thin)  3313  h~0.095  width 0.142mm  -> JLCPCB free tier, JiePei paid tier
    Basis B (thick) 7628  h~0.190  width 0.331mm  -> JiePei free tier, HQPCB, most overseas fabs

**Draw the RF corridors and keepouts to Basis B's 0.331mm**, and both widths become legal;
switching is then a single parameter at Gerber-export time. Cost: the RF area grows to roughly
twice its current footprint.

---

## 8. Overseas Fabs (surveyed 2026-09-04)

The reality of an open-source project: users abroad will take these Gerbers to their local fab.
Everything below is **first-party data from vendor documentation**, with sources cited. Anything
not obtained is marked "not obtained" rather than filled in from industry experience.

| Fab | Stackup | Glass | **h (mm)** | This board @0.15mm | Mismatch loss | Verdict |
|---|---|---|---|---|---|---|
| **PCBWay** | 6L/1.6mm, **30% residual copper** | 2116 | **0.1055** | **51.8Ω** ✅ | 0.001dB | in window |
| **OSH Park** | 6-Layer (only one) | **FR408HR** | **0.1107** | 53.2 – **57.6Ω** | 0.004–0.022dB | just order it |
| **PCBWay** | 6L/1.6mm, **70% residual** (this board's default) | 2116 | **0.1195** | **55.3Ω** | 0.011dB | just order it |
| **PCBWay** | 6L/1.6mm, 50% residual | 7628 | 0.1785 | 68.5Ω | 0.107dB | usable |
| **Aisler** | 6 Layer 1.6mm 35µm (only one) | **2116 ×2** | **0.230** | **76.8Ω** | 0.198dB | usable, not changeable |
| **Multi-CB** | Defined buildup `6L-01` | **2116 ×2** | **0.230** | **76.8Ω** | 0.198dB | usable, custom available |
| **Multi-CB** | Variable buildup (default) | varies | **not guaranteed** | unpredictable | — | 🔴 not for RF boards |
| **Eurocircuits** | 6L pooled (single predefined) | not obtained | **not obtained** | — | — | ask first |
| **Seeed Fusion** | 6L/1.6mm | not published | **not obtained** | — | — | ask first |
| **NextPCB** | 6L impedance-controlled | stocks 7628/1080/**2313**/2116 | **not obtained** | — | — | ask first |
| **ALLPCB** | — | — | — | — | — | 🔴 site suspended |

Impedances are computed the same way as §1.1 (`tools/microstrip_z0.py`, Dk back-solved from an
official data point, then forward-calculated) — **not** interpolated from h. The Aisler /
Multi-CB rows use **their own published "50Ω needs 395µm"** to back-solve an equivalent Dk of
4.512; HQPCB's independently back-solved Dk at the same h is 4.467, within 1%. Two unrelated
paths corroborating each other.

### 8.1 Three things that need calling out separately

**① PCBWay's h tracks the inner-layer residual copper ratio, and even switches glass style.**
Three stackups exist for the same 6L/1.6mm spec, with L1–L2 from 0.1055 to 0.1785 — nearly
double — and the glass jumping from 2116 to 7628. Layer 2 on this board is a solid ground plane,
so the residual ratio is high and it lands on the **70% tier (0.1195 / 55.3Ω)**. Just order it.
For precision, name the 30% tier in the order notes. Note also that PCBWay's 6-layer boards have
**1oz minimum inner copper — no 0.5oz option**, so the "0.5oz inner" listed under §6 mandatory
items does not hold at PCBWay.

**② OSH Park is not FR4; don't apply this document's Dk values.** The laminate is ISOLA FR408-HR
(Dk≈3.66, versus 4.47–4.73 equivalent Dk for every other vendor here). The thin dielectric pushes
impedance down while the low Dk pushes it up, partially cancelling: 53.2Ω using an FR4 equivalent
Dk, 57.6Ω after scaling by √(4.3/3.66) = 1.084. **The true value lies between, and both ends are
acceptable.** OSH Park offers no impedance control, no custom stackups, and **no assembly** —
bare boards only.

**③ Aisler and Multi-CB have identical 6-layer stackups** (2×2116 = 230µm, εr 4.25, 395µm for
50Ω), per two mutually independent vendor sites. European small-batch fabs evidently share one
FR4 stackup convention — so European users ordering as-is will land around 77Ω / 0.2dB. Only
Multi-CB lets you correct it via a Custom buildup.

### 8.2 Impedance control / custom stackup / assembly

| Fab | Impedance control | Custom stackup | SMT | Notes |
|---|---|---|---|---|
| PCBWay | Yes (±10%, ±5Ω at 50Ω and below) | **Yes** | Yes | 74 standard 6-layer stackups |
| OSH Park | **No** | **No** | **No** | $15/in², 3 copies, 12–21 calendar days |
| Aisler | No formal service, but publishes stackup and 50Ω width | No | Yes | 6L/100×100mm, 12 pcs $360, 13 working days |
| Multi-CB | Yes, **surcharge** | **Yes** (Custom) | Not offered | Defined buildup is **free**; ⚠️ sells to companies/institutions only |
| Eurocircuits | **Dedicated DEFINED IMPEDANCE pool** (from 1 pc, ±10%) | Yes (Special, not priced online) | Yes | The only European option with a proper impedance service |
| Seeed Fusion | Checkbox in the quoting tool | Not on the order page | Yes | 6L/100×100mm, 10 pcs $336.51 |
| NextPCB | Yes (4–20 layers) | **Yes** | Not obtained | Stocks 2313 (note: not 3313) |

### 8.3 What wasn't obtained, and what to ask

Eurocircuits' stackup data lives in their Buildup Editor, which **requires registration**. Their
published material list does bound it, though: only **PR1080 (70µm) / PR2116 (120µm) /
PR7628 (180µm)**, and their own documentation states they "almost always use two prepreg sheets".
**They stock no 3313** and cannot produce the 0.0994mm tier; the thinnest combination,
2×PR1080, is about 0.140mm. (That is derived from the material list, not measured — confirm
before ordering.)

The question to send, valid for all three:

> For 6 layers / 1.6mm / 1oz outer: **what is the pressed dielectric thickness between L1 and L2,
> and which prepreg construction is used (how many plies)?** We need 50Ω single-ended microstrip
> on the outer layer at 0.15mm track width.

---

## 9. Recalculation Tool

```bash
python3 hardware/tools/microstrip_z0.py                    # official data points + back-solved Dk
python3 hardware/tools/microstrip_z0.py 0.15 0.0994 4.725  # W h Dk -> Z0
```

Correct procedure when changing vendors or stackups:

1. **Look up that vendor's L1–L2 thickness first** and check it against the §1.2 window
   (0.085–0.115mm). Inside the window → stop here, no files change.
2. Outside the window → **compute the mismatch cost per §5 before deciding**. A 0.1–0.2dB loss
   is rarely worth re-routing an entire RF section.
3. If you really are changing trace width: **forward-calculate** the 50Ω width once in that
   vendor's own calculator and use that value directly. Don't extrapolate another vendor's Dk.
   To derive other impedances within the same stackup, back-solve Dk from an official data point
   with `solve_er()` and interpolate.
4. After changing trace widths, **grep the entire repo for the old value** — hardcoded copies
   have burned us five times already (see the v3/v4 internal layout-constraint notes).

> 🔴 **The nastiest class of hazard when changing stackups: constants whose provenance is h, but
> which are written down as a number.** They don't fail loudly — they pass silently, because the
> assertion compares against the hardcoded number rather than against h.
>
> One known instance: `NO_CU_FLOOR = 0.30` in `route_ifa_feed.py`, whose comment states its
> origin as **3 × 0.0994 (three dielectric thicknesses on 3313, the microstrip fringing-field
> decay distance)**. On 7628 (h=0.186) the correct floor is **0.558mm**, and the current
> `NO_CU = 0.50` is already insufficient — yet the assertion still passes. The effect is that the
> IFA feedline becomes a semi-coplanar waveguide rather than pure microstrip (ground copper at
> 2.7h instead of 5h).
>
> The direction of that effect is **benign** — coplanar ground pulls Z₀ down, i.e. closer to 50Ω
> — so it is not a reason to avoid ordering. But when spot-checking, don't be suspicious of a
> reading that beats the pure-microstrip model.
>
> **When changing stackups, find every constant whose provenance is a multiple of h and redo it.**

Official calculators:

| Fab | Entry point |
|---|---|
| JLCPCB | <https://tools.jlc.com/#/impedanceCalculation> |
| HQPCB | <https://www.hqpcb.com/quote/impedance> (same tool as the order page's stackup calculator) |
| JiePei | Quote page → "Stackup" → "More laminated structures", open each tier for pressed thickness |

> ⚠️ HQPCB's calculator shows, in the "result" column, the impedance achieved **after** it adjusts
> the trace width — not the impedance of the width you typed. Read the **"trace width"** column
> (the width it says you need for 50Ω). That column is easy to misread.

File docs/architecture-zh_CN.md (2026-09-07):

# Pilot Kit Box — 固件架构

英文版：[`architecture.md`](architecture.md)

本文描述当前 4.3 寸触摸版 ESP32-P4 固件的运行拓扑，包括 RP2040 UART
1090 链路、LittleFS / MicroSD / UART / BLE 输出、GT-U8
GPS NMEA/RMC、BMP388、BNO085，以及 PFD、交通、列表、设置、关于和诊断页面。

> 范围说明：当前接收路径是 **v3/v4 扩展板的 RP2040 UART 数据源**——1090 MHz
> 包络经 TLV3501 比较器整形，RP2040 以 PIO+DMA **双沿**捕获（双沿是 R11
> 融合串重建的前提：0→1 融合脉冲对只能靠沿对+脉宽重建），重建
> 56/112-bit Mode-S 帧，经 921600 波特 UART（UART2，P4 RX=46 / TX=32）
> 送入 `adsb_lnk` 任务，进入板上处理管线。捕获/解码细节见
> `firmware/rp2040`。早期的 RTL-SDR USB 数据源（v1/v2 载板与裸板方案）已于
> 2026-09 移除，不再画入拓扑图；历史细节见 git 历史。

## 总览

```mermaid
flowchart LR
    subgraph HW["硬件"]
        direction TB
        RP2040["RP2040（v3/v4 扩展板）\nTLV3501 比较器 → PULSES\nPIO 双沿捕获 + DMA 块队列\nmodes_edge：前导同步 + PPM 重建\n56/112-bit（不做 CRC——P4 裁决）"]
        C6["ESP32-C6-MINI-1\nWi-Fi 6 / BLE 5"]
        SDIO_C6["SDIO\nCLK=18 CMD=19\nD0..3=14..17\nRESET=54"]
        FLASH["32 MB Nor Flash\nfactory app 12 MiB"]
        SD["MicroSD slot\nSDMMC 4-bit\nCLK=43 CMD=44\nD0..3=39..42"]
        GPS["GT-U8 GPS/BDS\nUART1 P4 TX=49 P4 RX=51\nRMC 授时；PPS(50) 已消费（时间锁定状态）"]
        BARO["BMP388\nI²C0 addr 0x76\n轮询，INT=31 未用"]
        BNO["BNO085 IMU\nSDA=7 SCL=8\n轮询，RST=28 INT=34"]
        SCREEN["ST7701 MIPI-DSI\n原生 480×800\nPPA → 800×480\nRST=27 BL=26"]
        TOUCH["GT911 触摸\nI²C0 7/8\nRST=23"]
        BLE_PEER["iPad / iPhone\nPilot Kit app"]
    end

    subgraph P4["ESP32-P4NRW32"]
        direction TB
        subgraph T_LINK["adsb_lnk 任务 — CPU1 优先级 5"]
            UART_IN["UART2 RX=46 TX=32\n921600 8N1，adsb_link 协议 v1\n（256 字节分片读；对每个 HELLO 回帧，\n1 Hz HEALTH 上报）"]
            INGEST["modes_ingest\nMode-S 24-bit 校验和门（mode_s.c；\ncheck_crc=1，不做纠错；链路外层 CRC-16\n由 codec 负责）\nICAO / 高度 / CPR 提取"]
        end
        CPR["cpr_decode 全局定位\n（64 机 CPR 表）"]
        STATE["aircraft_state\n64 slots / 60 s 窗口\n（呼号/高度/位置/速度融合）"]
        DASH["1 Hz 看板\n（报文率/架数/链路态）"]
        DISPATCH["record_dispatch\n同步 fan-out"]
        UART["UART sink\nType-C CDC log"]
        FILE["file sink\nFlash: 1 MiB 轮转，目标 12 文件\nMicroSD: 16 MiB × 64"]
        BLE["BLE raw sink\nqueue"]
        GDL["GDL90 encoder\nHeartbeat + Traffic"]
        GATT["NimBLE GATT notify"]
        IMU["imu task\nBNO085 100 Hz"]
        UI["pfd task\nPFD / TRAFFIC / LIST\nSETTINGS / ABOUT / DIAG"]
    end

    RP2040 -- "UART 协议 v1\n921600" --> UART_IN
    UART_IN --> INGEST
    INGEST --> CPR --> STATE
    INGEST --> DISPATCH
    INGEST --> DASH
    DISPATCH --> UART
    DISPATCH --> FILE
    DISPATCH --> BLE
    STATE --> GDL --> GATT --> SDIO_C6 --> C6 --> BLE_PEER
    BNO --> IMU --> UI
    GPS --> UI
    BARO --> UI
    TOUCH --> UI
    SCREEN --> UI
    FLASH --> FILE
    SD --> FILE
```

## 任务表

| Task | CPU | 优先级 | 栈 | 职责 |
|---|---:|---:|---:|---|
| `usb_host_lib` / `sdr` / `dsp` | — | — | — | **已退役**（2026-09 随 v1/v2 USB RTL-SDR 接收链移除）：历史细节见 git 历史；解码/分发职责现位于 RP2040（`modes_edge`）+ `adsb_lnk`/modes_ingest 链。 |
| `adsb_lnk` | 1 | 5 | 8 KiB | 运行 RP2040 UART 链路（adsb_link codec @ 921600 波特，256 字节分片读）：把 RP2040 前端送来的 CRC 前置 Mode-S 帧喂进 modes_ingest（Mode-S 24-bit 校验，mode_s.c；check_crc=1，不做纠错），对每个 HELLO 回帧，并承接原 DSP 业务链（CPR/航迹/记录/1 Hz 看板）。RP2040 侧自身经 PIO+DMA 捕获双沿、用 modes_edge 解码 56/112-bit 帧；USB RTL-SDR 任务对（`usb_host_lib`/`sdr`）已退役；`adsb_link_task.c` 沿用 `dsp` TAG 保持日志检索连续。 |
| `rec_file` | 0 | 3 | 4 KiB | 文件写入任务；启动时按 NVS 设置选择 LittleFS 或 MicroSD，缺卡时回退 LittleFS，避免 DSP hot path 被存储写入阻塞。 |
| `gps` | 0 | 4 | 4 KiB | 解析 GT-U8 UART1 NMEA（RMC/GGA/GSV/TXT），维护 GPS/北斗定位、卫星/SNR、天线状态，并从 RMC 设置系统时间；GPIO50 PPS 已被固件消费（GPIO ISR 计数 + 自旋锁快照，1 Hz 采样进入时间锁定状态），授时（settimeofday 级）接线仍是后续任务。 |
| `imu` | 0 | 5 | 4 KiB | 以 100 Hz 读取 BNO085 Rotation Vector，应用软件 tare，提供给 PFD 和校准向导。 |
| `baro` | 0 | 4 | 4 KiB | 轻量独立任务：以 ~10 Hz 经 I²C0 轮询 BMP388，运行温度补偿气压→高度换算并计算升降率，结果写入 `g_baro_state`（QNH 可调）。 |
| `sd_detect` | 0 | 2 | 4 KiB | MicroSD 插拔探测：无卡时每 3 秒尝试挂载，已挂载时每 2 秒探活并刷新容量缓存。 |
| `pwr` | 0 | 3 | 4 KiB | `power_service` 背后的 1 Hz 电源轮询任务：SY6970（v4 powered，I²C 0x6A）与 ETA6098（载板 BAT_ADC/STAT）两个 backend 汇成带 stale 判定的公共快照，SY6970 过期自动回落 ETA6098；诊断页电池卡片与状态栏消费。 |
| `buttons` | — | — | — | 保留旧源码但 4.3 寸触摸板不启动该任务。 |
| `pfd` | 0 | 4 | 6 KiB | 把 PFD 与 UI 页面渲染到 800×480 逻辑 framebuffer。 |
| `nimble_host` | 0 | 4 | 4 KiB | NimBLE host 事件循环，通过 C6 的 SDIO / VHCI controller 处理 BLE。 |
| `ble_emit` | 0 | 3 | 6 KiB | 每秒快照 `aircraft_state`，发送 GDL90 Heartbeat 和 Traffic Report，同时发送 raw ts-line 队列。 |

## 内存预算

| 区域 | 大小 | 所有者 |
|---|---:|---|
| IQ ring buffer / URB pool / DSP 工作集 | 已释放 | **已退役**（2026-09 随 v1/v2 USB RTL-SDR 接收链移除）：历史细节见 git 历史；原占用的 PSRAM 现用于地图瓦片/字体/记录等其余工作集 |
| CPR table | 约 5 KiB | `cpr_decode.c` 中 64 架飞机的 CPR pairing 状态 |
| aircraft_state | 约 7 KiB | `aircraft_state.c` 中 64 slots，保存呼号、高度、位置、速度等 |
| 应用 framebuffer | 750 KiB | 800×480×16 bpp RGB565-swapped，位于 PSRAM |
| DPI framebuffer | 1.5 MiB | 两块 480×800×16 bpp 扫描缓冲，位于 PSRAM |
| file sink queue | 约 10 KiB | 256 × `file_record_t` |
| BLE raw queue | 约 5 KiB | 64 × 80 B raw ts-line |
| NimBLE host | 约 30 KiB | GATT DB、连接状态、事件循环等 |
| aircraft DB blob | 约 8.21 MiB PSRAM | `/sdcard/aero/pk_actdb.bin`，由 `aircraft_db.c` 懒加载进 PSRAM，用于 ICAO24 -> 机型/型号/注册号查询。已不再嵌入 flash；无卡时查询为空，拔卡即释放缓冲 |
| 航司/国家表 | 约 230 KiB + 小型 flash 表 | `airline_codes.c` 和 `icao_country.c`，生成式查找数据，用于呼号和国家显示 |

大块缓冲尽量放入 PSRAM，内部 768 KiB SRAM 留给 DMA-capable 分配、FreeRTOS 栈、ESP-Hosted 队列和 USB host descriptor。

## 故障隔离

```text
RP2040 捕获     -> 环满 DMA 停机（overrun 计数 + lost 标志）。重启前先复位
overrun/重启       PIO 状态机并清空 RX FIFO，重武装的首块带断点位——core1
                   先 modes_edge_reset 再喂，断点两侧的边沿不会拼成假帧。
                   停机窗口外的单沿丢失（RXSTALL）只损坏当前一帧，由解码
                   端自然判负丢弃。以上都进入 1 Hz HEALTH 的 ovr 计数。

链路停滞        -> RP2040 侧：core1 解码停滞 >5 s 由 core0 看门狗经链路
                   上报 ERROR(code=2)。P4 侧：曾 LINKED 后 >5 s 无合法帧
                   即判 STALLED（seq 断档/resync 按协议 v1 计数）；诊断页
                   显示链路状态。

File queue full -> file sink xQueueSend 失败，记录 drop；
                    ingest path 不等待 flash。

Storage write -> LittleFS / MicroSD 的 fwrite 或 rotation fopen 失败时记录错误；
                 UART 和 BLE sink 继续工作。MicroSD 拔出后探测任务会卸载，
                 但本次启动的文件后端不会动态切换，需重启后重新选择。

BLE peer drops -> NimBLE 处理断连；没有订阅者时 notify 被跳过；
                  重新连接后自动继续。
```

## 时间同步

固件没有持久化系统墙钟，上电时系统时间从 Unix epoch 0 开始。当前有三条
校时路径，按质量保护避免低质量来源覆盖高质量来源：

1. **GT-U8 RMC**：RMC 提供 UTC 日期时间，是首选来源。GPIO50 只是未来
   PPS 的可选接线预留；当前固件没有 PPS GPIO 输入或纪律环。
2. **iOS Current Time Service**：iOS 默认暴露 SIG 标准 CTS（UUID `0x1805`）。固件在 GAP CONNECT 后作为 GATT client 读取 `0x2A2B` 当前时间并调用 `settimeofday()`。
3. **自定义 Time Sync characteristic**：UUID `...0004`，客户端写入 8 字节 little-endian Unix epoch milliseconds。Android 和跨平台客户端推荐使用这一条。

校时前输出的 Mode-S frame 仍会进入所有 sink，只是 `ts_ms` 很小（接近开机以来毫秒数）。客户端可以识别并丢弃这些 pre-sync frame。

### 载板传感器（GPS / 气压 / microSD）

Pilot Kit 通过 UART 连接 GT-U8 GPS，通过 I²C0（`0x76`）连接 BMP388，
并使用 Rev1.2 板载 microSD 卡槽。GPIO50 可为未来 PPS 预留，但当前路径
未实现。各能力如何接入上面的架构：

- **GPS 授时**（`gps_task.c`）：GPS RMC UTC 设置 `settimeofday()`。**GPS 优先**，
  BLE 作备份；有覆盖保护，低质量源不会盖掉已校准好的 GPS 时间。设备无需手机即可
  自主校时，DIAG 显示系统时间、定位和卫星状态；当前没有 PPS 边沿时间修正。
- **GPS own-ship**（`gps_task.c`）：没有启用编译期 ADS-B 本机 ICAO 时作兜底。
  接入现有 `aircraft_state` own-ship 路径 + GDL90 ownship report。
- **BMP388 气压**（`baro_task.c`）：高度/升降率仅作**参考**显示（增压座舱内失真），不作权威高度；QNH 可在 SETTINGS 中调整。
- **microSD 记录后端**：Settings 可选 Flash / MicroSD，设置写入 NVS 并在下次启动生效。
  选择 MicroSD 但启动时未挂载会回退 LittleFS。Flash 按 1 MiB 轮转，文件数目标为 12，
  实际保留量受 10 MiB 分区限制；
  MicroSD 使用 16 MiB × 64 个文件（约 1 GiB），并支持受保护的 FAT32 格式化。

## 数据格式

所有 sink 对同一条 Mode-S frame 使用相同文本形状：

```text
1715432198765 *8D4CA1BD58C386435840BA1AD7CA;
^^^^^^^^^^^^^ ^^^^^^^^^^^^^^^^^^^^^^^^^^^^^^^
    ts_ms      AVR-format Mode-S hex payload
```

这也是 Pilot Kit 离线脚本和 BLE Raw characteristic 使用的格式。GDL90 encoder 是另一路结构化输出，供 EFB / 移动端消费。

## 关键架构选择

1. **1090 MHz 时序工作全部在 RP2040**：PIO + DMA 把双沿间隔收进硬件定时的块队列，捕获路径上没有 RTOS——P4 调度抖动不触碰脉冲时序。双沿是必要条件：0→1 融合脉冲对（R11）只能靠沿对+脉宽重建。
2. **单任务拥有 UART 链路**：`adsb_lnk` 是 P4 侧唯一的 codec 读取者；RP2040 侧只有 core0 发送循环发送。协议 v1 有严格的按发送方 seq、HELLO 握手与 1 Hz HEALTH。
3. **融合链不阻塞 I/O**：每一跳的背压都是有损且被计数的——P4 滞后时 RP2040 帧环丢帧（有计数），file/BLE sink 各自持有队列。解码/ingest 的前进不受 flash、BLE 对端或操作者行为影响。
4. **wire / disk / BLE raw 格式一致**：`<ts_ms> *<HEX>;` 贯穿串口、文件和 BLE Raw，降低调试和后处理成本。

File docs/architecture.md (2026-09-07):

# Pilot Kit Box — Firmware Architecture

Chinese version: [`architecture-zh_CN.md`](architecture-zh_CN.md)

Snapshot of the current 4.3-inch touch runtime topology, including ADS-B,
BLE, GPS NMEA/RMC, barometer, dual storage backends, local traffic UI,
diagnostics, IMU and i18n.

> Scope note: the receive path is the **RP2040 front-end over UART** (v3/v4
> expansion boards). The 1090 MHz envelope is shaped by a TLV3501 comparator;
> the RP2040 captures **both** edges via PIO+DMA — dual edges are load-bearing
> because fused 0→1 pulse pairs (R11) are only rebuildable from edge pairs +
> widths — decodes Mode S, and ships raw frames to the P4's `adsb_lnk` task
> at 921600 baud for CRC filtering and the on-device fusion chain. Capture /
> decode details live in `firmware/rp2040`. The v1/v2-era USB RTL-SDR source
> was removed in 2026-09 and is no longer diagrammed; see git history for
> details.

## Big picture

```mermaid
flowchart LR
    subgraph HW["Hardware"]
        direction TB
        RP2040["RP2040 (v3/v4 expansion board)\nTLV3501 comparator → PULSES\nPIO dual-edge capture + DMA block queue\nmodes_edge: preamble sync + PPM decode\n56/112-bit (no CRC — judged on the P4)"]
        C6["ESP32-C6-MINI-1\n(Wi-Fi 6 / BLE 5)"]
        SDIO_C6["SDIO bus\nCLK=18 CMD=19\nD0..3=14..17\nRESET=54"]
        FLASH["32 MB Nor Flash\nfactory app 12 MiB"]
        SD["MicroSD slot\nSDIO 3.0\nCLK=43 CMD=44\nD0..3=39..42"]
        GPS["GT-U8 GPS/BeiDou\nUART1 P4 TX=49 P4 RX=51\nRMC time; PPS(50) consumed (time-lock status)"]
        BARO["BMP388\nI²C0 addr 0x76\npolled; INT=31 unused"]
        BNO["BNO085 IMU\nI²C 7=SDA 8=SCL\npolled; RST=28 INT=34"]
        SCREEN["ST7701 MIPI-DSI\nnative 480×800\nPPA → 800×480\nRST=27 BL=26"]
        TOUCH["GT911 touch\nI²C0 7/8\nRST=23"]
        BLE_PEER["iPad / iPhone\nPilot Kit app"]
    end

    subgraph P4["ESP32-P4NRW32"]
        direction TB
        subgraph T_LINK["adsb_lnk task — CPU 1, prio 5"]
            UART_IN["UART2 RX=46 TX=32\n921600 8N1, adsb_link protocol v1\n(256-byte reads; replies to every\nHELLO, 1 Hz HEALTH to the RP2040)"]
            INGEST["modes_ingest\nMode-S 24-bit checksum gate\n(mode_s.c; check_crc=1, no error correction;\nthe outer link CRC-16 is the codec's job)\nICAO / alt / CPR extract"]
        end

        subgraph CHAIN["fusion chain (former dsp_task business)"]
            CPR["cpr_decode global position\n(64-aircraft CPR table)"]
            STATE["aircraft_state\n64 slots, 60 s fresh window\n(callsign/alt/pos/vel fusion)"]
            DASH["1 Hz dashboard\n(msgs/s, aircraft, link state)"]
            DISPATCH["record_dispatch\n(synchronous fan-out)"]
        end

        subgraph SINKS["sinks (registered at boot)"]
            direction LR
            SINK_UART["uart sink\nprintf line\n→ Type-C USB CDC"]
            SINK_FILE["file sink\nqueue → writer task"]
            SINK_BLE["ble sink\nraw ts-line → queue"]
        end

        subgraph T_FILE["rec_file task — CPU 0, prio 3"]
            FW["file append\nFlash: 1 MiB rotation, target 12\nMicroSD: 16 MiB × 64"]
        end

        subgraph T_BLE["ble_emit task — CPU 0, prio 3"]
            GDL["GDL90 encode\n• Heartbeat (1 Hz)\n• Traffic Report per aircraft"]
            GATT["NimBLE GATT notify\non Traffic / Heartbeat / Raw chars"]
        end
    end

    RP2040 -- "UART protocol v1\n921600 baud" --> UART_IN
    UART_IN --> INGEST
    INGEST --> CPR --> STATE
    INGEST --> DISPATCH
    INGEST --> DASH
    DISPATCH --> SINK_UART
    DISPATCH --> SINK_FILE
    DISPATCH --> SINK_BLE
    SINK_UART -.serial.-> EXT_PY["Pilot Kit\nadsb_to_track.py\n→ GPX/KML"]
    SINK_FILE --> T_FILE
    FW -.write.-> FLASH
    FW -.write.-> SD
    SINK_BLE -.queue.-> T_BLE
    STATE --> GDL
    GDL --> GATT
    GATT -- HCI over SDIO --> SDIO_C6
    SDIO_C6 <--> C6
    C6 -- BLE 5 --> BLE_PEER

    SD --> SINK_FILE
    GPS --> P4
    BARO --> P4
    BNO --> P4
    SCREEN --> P4
    TOUCH --> P4

```

## ASCII view (when the SVG render is unavailable)
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

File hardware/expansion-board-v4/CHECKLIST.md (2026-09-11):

# V4.6 BOM Verification Checklist (reference-designator order)

Chinese companion: [`CHECKLIST-zh_CN.md`](CHECKLIST-zh_CN.md)

> Generated from the authoritative schematic and PCB coordinates. Do not hand-edit.
> `Not placed` is authoritative: DNP parts, test pads, solder bridges, mounting holes, and PCB antennas do not receive components.

226 designators in total.

| ✓ | Designator | Value / Model | Footprint | Position (x, y) | Stage | Notes |
|---|---|---|---|---|---|---|
| ☐ | **C1** | 10uF | C_0805_2012Metric | (70.8, 96.5) | A Power |  |
| ☐ | **C2** | 1uF | C_0603_1608Metric | (85.9, 99.1) | A Power |  |
| ☐ | **C3** | 1uF | C_0603_1608Metric | (70.8, 98.9) | A Power |  |
| ☐ | **C4** | 1uF | C_0603_1608Metric | (78.7, 97.8) | A Power |  |
| ☐ | **C5** | 1uF | C_0402_1005Metric | (85.9, 96.7) | A Power |  |
| ☐ | **C6** | 1uF | C_0603_1608Metric | (92.1, 97.9) | A Power |  |
| ☐ | **C10** | 100nF | C_0603_1608Metric | (61.0, 92.6) | C Sensors + GNSS |  |
| ☐ | **C11** | 100nF | C_0603_1608Metric | (64.6, 87.2) | C Sensors + GNSS |  |
| ☐ | **C12** | 100nF | C_0603_1608Metric | (56.5, 87.7) | C Sensors + GNSS |  |
| ☐ | **C13** | 100nF | C_0603_1608Metric | (59.1, 92.6) | C Sensors + GNSS |  |
| ☐ | **C14** | 100nF | C_0603_1608Metric | (64.6, 89.9) | C Sensors + GNSS |  |
| ☐ | **C15** | 4.7uF | C_0603_1608Metric | (59.9, 99.3) | C Sensors + GNSS |  |
| ☐ | **C16** | 100nF | C_0603_1608Metric | (64.6, 92.5) | C Sensors + GNSS |  |
| ☐ | **C17** | 100nF | C_0603_1608Metric | (71.4, 81.0) | C Sensors + GNSS |  |
| ☐ | **C18** | 10uF | C_0805_2012Metric | (74.4, 80.8) | C Sensors + GNSS |  |
| ☐ | **C19** | 15pF C0G | C_0603_1608Metric | (88.4, 69.1) | B MCU + Flash |  |
| ☐ | **C20** | 15pF C0G | C_0603_1608Metric | (79.8, 69.1) | B MCU + Flash |  |
| ☐ | **C21** | 100pF | C_0402_1005Metric | (103.6, 59.7) | E 1090 Receive Chain |  |
| ☐ | **C22** | 100nF | C_0603_1608Metric | (93.2, 75.8) | B MCU + Flash |  |
| ☐ | **C23** | 100nF | C_0603_1608Metric | (91.8, 81.5) | B MCU + Flash |  |
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

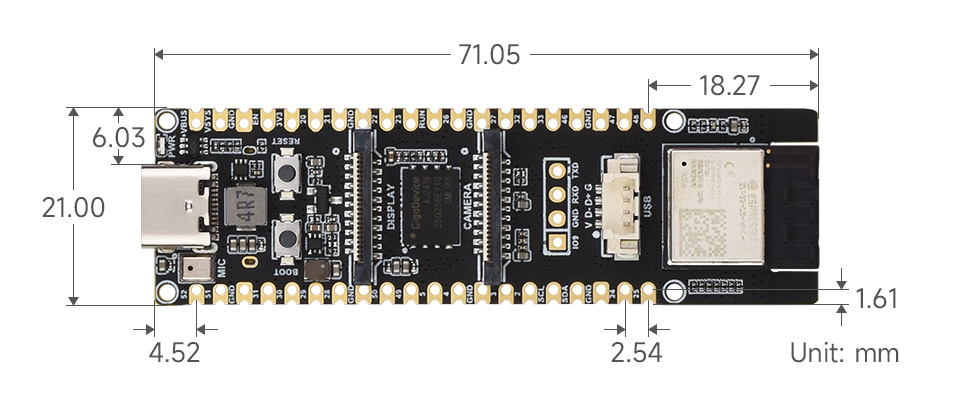
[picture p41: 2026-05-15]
docs/hardware/ESP32-P4-WIFI6-details-size.jpg

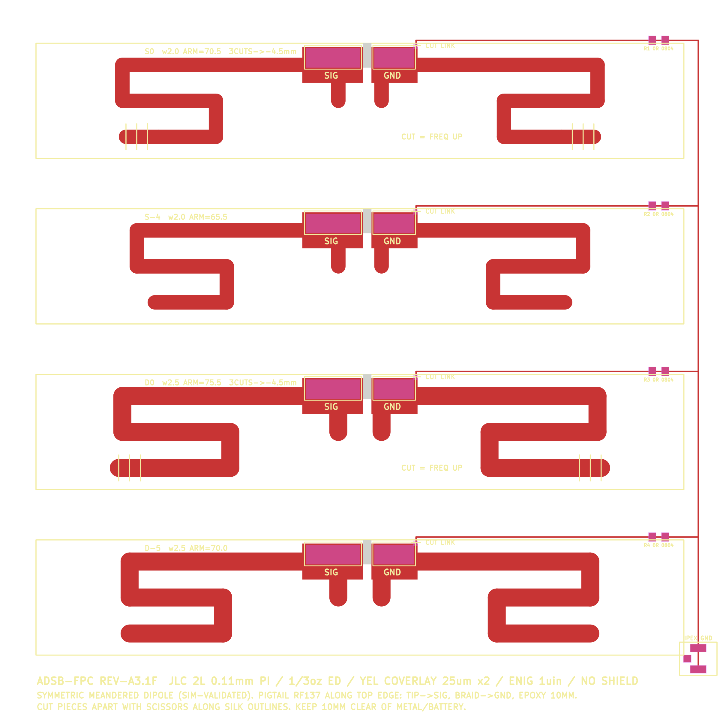
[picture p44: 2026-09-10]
hardware/fpc-antenna/connected-candidate-preview.svg.png

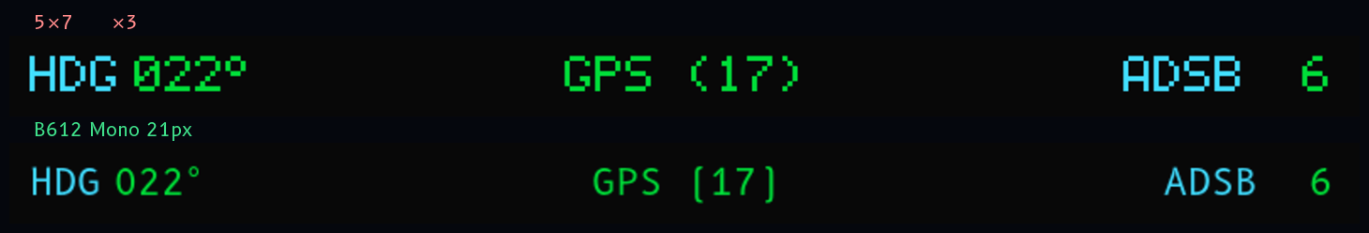
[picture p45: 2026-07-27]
docs/ux/preview-font-b612-ab.png

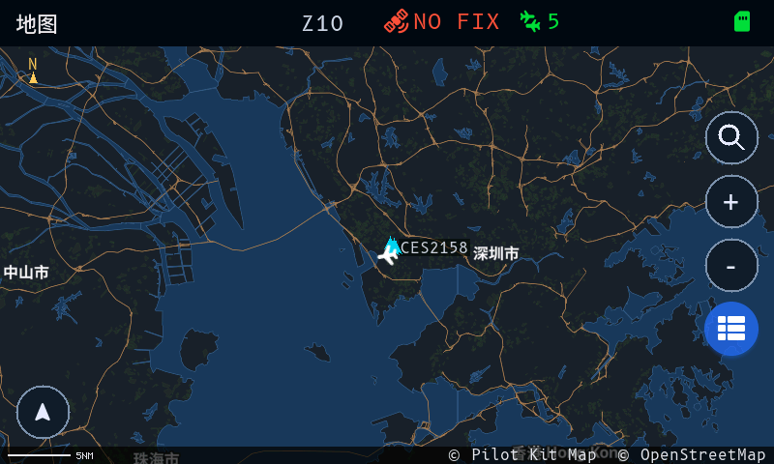
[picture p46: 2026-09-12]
images/ui-4.3-map-clump.png

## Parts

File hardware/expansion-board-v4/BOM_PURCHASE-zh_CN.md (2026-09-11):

# V4.6 采购清单（唯一权威版，从网表自动导出——不要手改）

> ⚠️ **本文件取代此前散落在设计文档 §7/§12/§13 的所有采购表格。**

> 网表变更后重跑 `gen_bom.py` 即可；脚本带断言，任何未归类的元件都会报错，不会漏项。

> **IFA**：50.0mm铜箔外包络（48.5mm中心线）已按V4.0实板装盒VNA结果定型；默认0R/DNP为本次实测直通状态。

共 222 个元件 / 102 个料号。

**库类型**：`基础✅` 免 ¥20 上机费且损耗由嘉立创承担；`扩展⚠️` 每种 ¥20（当前靠券减免，券没了就是真金白银）。本轮在用的扩展库料共 **27 种**，下次优化优先从这些里找基础库替代。`按值配料` 表示没指定料号，库类型由嘉立创匹配页当场决定——那些也要在匹配时留意。

| 采购 | 类别 | 值/规格 | 封装 | 数量 | 位号 | 推荐型号 | 立创料号 | 库 | 说明 |
|---|---|---|---|---|---|---|---|---|---|
| 🔴必买指定 | 低电容ESD | TPESD8L3.3 0.3pFtyp 0.5pFmax | D_0402_1005Metric | 5 | D2,D3,D4,D5,D6 | TECH PUBLIC TPESD8L3.3CT5G | C2830293 | 扩展⚠️ | D2/D3 天线口 + D4/D5 USB D+/D−，同一料号。Cj 0.3pF typ / 0.5pF max（TPESD8L3.3_OCR.pdf 实测表）；普通 5V ESD 管 Cj 20-50pF 会直接吃掉射频信号。双向、无极性 |
| 🔴必买指定 | 射频-978匹配 | 2.7pF | C_0402_1005Metric | 1 | C41 | 风华 0402CG2R7C500NT（C0G） | C1561 | 扩展⚠️ | ⚠️必须 C0G |
| 🔴必买指定 | 射频-978匹配 | 27nH | L_0402_1005Metric | 1 | L10 | muRata LQW15AN27NH00D（绕线 ±3% SRF3.5G） | C113111 | 扩展⚠️ | 备选 Sunltech SCW1005C27NJST C330864（±5% SRF3.5G 库存8872）、APV AHW1005C-27NJTF C6364690（±5% SRF2.48G） |
| 🔴必买指定 | 射频-978匹配 | 3.6pF | C_0402_1005Metric | 2 | C40,C44 | YAGEO AC0402CRNPO9BN3R6（C0G） | C5552081 | 扩展⚠️ | ⚠️必须 C0G/NP0，X7R 调不准匹配 |
| 🔴必买指定 | 射频-978匹配 | 6.2pF | C_0402_1005Metric | 1 | C42 | 风华 0402CG6R2C500NT（C0G） | C41744 | 扩展⚠️ | ⚠️必须 C0G |
| 🔴必买指定 | 射频-978匹配 | 6.8nH | L_0402_1005Metric | 2 | L11,L12 | muRata LQW15AN6N8G00D（绕线高Q） | C82919 | 扩展⚠️ | 国产替代 Sunltech SCW1005C6N8JST C330847 |
| 🔴必买指定 | 射频-978匹配 | 7.5nH | L_0402_1005Metric | 2 | L13,L9 | muRata LQW15AN7N5G00D（绕线高Q） | C82918 | 扩展⚠️ | 国产替代 Sunltech SCW1005C7N5JST C330848 |
| 🔴必买指定 | 射频-LNA偏置 | 3.32k | R_0402_1005Metric | 1 | R11 | 0402 3.32k ±1% | — | 按值配料 | QPL9547 pin1 Vbias；按原厂评估板值，禁止用 0Ω 直连 3V3_RF |
| 🔴必买指定 | 射频-LNA去耦 | 470pF C0G | C_0402_1005Metric | 1 | C81 | 0402 470pF C0G/NP0 ±5% | — | 按值配料 | BGA2817 pin1 专属 Cdec；贴近 U12，替代料必须锁 C0G/NP0 |
| 🔴必买指定 | 射频-LNA馈电扼流 | 18nH 0402CS-18NXGRW | L_0402_1005Metric | 1 | L1 | Coilcraft 0402CS-18NXGRW 或同等高 SRF 绕线 18nH | — | 按值配料 | QPL9547 pin7 漏极馈电；按原厂评估板 18nH，替代料必须核对 1090MHz 时仍为感性 |
| 🔴必买指定 | 射频-偏置扼流 | 100nH | L_0402_1005Metric | 3 | L14,L18,L8 | DDY WI0402IFR10KST-HF（绕线） | C18221115 | 扩展⚠️ | ⚠️SRF 1.4GHz。常见的叠层款 SRF 仅 600-700MHz，在 1090MHz 已变电容会把射频短到电源 |
| 🔴必买指定 | 射频-偏置扼流 | 33nH | L_0402_1005Metric | 2 | L15,L2 | APV AHW1005C-33NJTF（绕线） | C6807986 | 扩展⚠️ | ⚠️SRF 2.35GHz。GNSS 1575MHz 要求 SRF≥2GHz，叠层款不合格 |
| 🔴必买指定 | 射频-检波耦合 | 3pF | C_0402_1005Metric | 1 | C43 | 三环 TCC0402COG3R0C500AT（C0G） | C696883 | 扩展⚠️ | ⚠️必须 C0G |
| 🔴必买指定 | 射频-端接 | 52.3R | R_0402_1005Metric | 1 | R19 | YAGEO RC0402FR-0752R3L ±1% | C273696 | 扩展⚠️ | 必须 ±1%，不可用 51R±5% 代 |
| 🔴必买指定 | 射频-耦合/旁路 | 100pF C0G | C_0402_1005Metric | 5 | C31,C32,C33,C34,C35 | 风华 0402CG101J500NT（C0G） | C1546 | 基础✅ | C34/C35 决定 1090MHz 检波输入高通，必须锁 C0G/NP0 |
| 🔴必买指定 | 晶振 | 12MHz CL=10pF ABM8-272-T3 | Crystal_SMD_3225-4Pin_3.2x2.5mm | 1 | Y1 | Abracon ABM8-12.000MHZ-10-1-U-T3 / ABM8-272-T3 | — | 按值配料 | RP2040 主晶振，必须 CL=10pF；配 C19/C20=15pF C0G。🔴 别换成嘉立创基础库那颗 3225 的 12MHz（2026-09-04 在线核实）：封装一样、频率一样，但负载电容是本值的两倍，配上去频率会偏，而 USB 只容 ±2500ppm。换晶振必须连 C19/C20 一起重算 |
| 🔴必买指定 | 晶振负载 | 15pF C0G | C_0603_1608Metric | 2 | C19,C20 | 三星 CL10C150JB8NNNC（C0G） | C1644 | 基础✅ | 配 ABM8-272-T3(CL=10pF)，C19/C20 必须同值 |
| 🔴必买指定 | 电源-PD | CH224K | CH224K_ESSOP-10 | 1 | U18 | CH224K | C970725 | 扩展⚠️ | PD 诱骗 9V；4-22V 输入 |
| 🔴必买指定 | 电源-充电 | SY6970 | QFN-24-1EP_4x4mm_P0.5mm_EP2.6x2.6mm_ThermalVias | 1 | U19 | SY6970QCC | C5357542 | ? | 5A 充电 + I2C 电量计，1.5MHz |
| 🔴必买指定 | 电源-升压 | SY7069 | TSOT-23-6 | 1 | U20 | SY7069ADC | 淘宝（立创未见） | ? | 同步升压 5V，I_LIM 3.0A |
| 🔴必买指定 | 电源-升压电感 | 4.7uH XEL4030-472MEC | L_Coilcraft_XxL4030 | 1 | L17 | Coilcraft XEL4030-472MEC | — | 按值配料 | SY7069 功率电感；替代料必须复核 Isat、Irms、DCR、温升和封装 |
| 🔴必买指定 | 电源-电容 | 22uF 16V X5R | C_1206_3216Metric | 1 | C77 | 1206 22uF 16V X5R/X7R | — | 按值配料 | SY7069 输出储能；必须标 16V，并核对 5V DC bias 下有效容值 |
| 🔴必买指定 | 电源-电感 | 1uH | L_Bourns-SRN4018 | 1 | L16 | 1uH SRN4018 Isat>=5A | — | 按值配料 | SY6970 开关电感，配 1.5MHz |
| 🔴必买指定 | 连接器 | MX1.25WT-2P BAT | MX1.25WT-2P_1x02-1MP_P1.25mm_Horizontal | 1 | J9 | MX1.25 卧贴 1.25WT-2P | — | 按值配料 | 电池座；MP 1.8x2.4/外缘距 7.50，与 PicoBlade 不通用 |
| 🟡有推荐 | CC1312R DCDC | 6.8uH | L_0805_2012Metric | 1 | L7 | TDK MLZ2012N6R8LT000 | C82157 | 扩展⚠️ | ⚠️全站 0805 里只有它 DCR<300mΩ 且 Isat≥100mA（250mΩ/110mA，刚压线） |
| 🟡有推荐 | PD输入储能 | 1uF 25V | C_0603_1608Metric | 1 | C80 | SAMSUNG CL10A105KB8NNNC | C15849 | 基础✅ | C80 挂 USB_VBUS；PD 诱骗后是 9V，耐压必须 ≥25V。基础库，2 片总成本 ¥0.14，库存千万级 |
| 🟡有推荐 | PMOS 高边开关 | AO3401A | SOT-23 | 4 | Q2,Q3,Q4,Q5 | AOS AO3401A（原厂，基础库） | C15127 | ? | **嘉立创基础库**：损耗0/最小贴装0，买 8 颗就够，免 ¥20 上机费。有券时 UMW C347476 的料费更低（¥2.04 vs ¥4.77） |
| 🟡有推荐 | U.FL 座 | U.FL_1090_EXT(经尾线转SMA) | U.FL_Hirose_U.FL-R-SMT-1_Vertical | 1 | J6 | 聚兴泰 AIPEX-1 | C41432122 | 扩展⚠️ | IPEX1 板端内针 50Ω / DC~6GHz / VSWR1.3。**规格书标注 3 PADS TYPE**，焊盘与板上 U.FL_Hirose_U.FL-R-SMT-1_Vertical 完全匹配（跨距4.00/间距1.90/2.20×1.05）。4 个：1090外接/978/GNSS外接/GNSS内置patch。外接的两个另配 U.FL→SMA 尾线。⚠️ 换牌子必须核对焊盘数——四焊盘款（如品赞 C5299419）会多一脚悬空 |
| 🟡有推荐 | U.FL 座 | U.FL_978 | U.FL_Hirose_U.FL-R-SMT-1_Vertical | 1 | J5 | 聚兴泰 AIPEX-1 | C41432122 | 扩展⚠️ | IPEX1 板端内针 50Ω / DC~6GHz / VSWR1.3。**规格书标注 3 PADS TYPE**，焊盘与板上 U.FL_Hirose_U.FL-R-SMT-1_Vertical 完全匹配（跨距4.00/间距1.90/2.20×1.05）。4 个：1090外接/978/GNSS外接/GNSS内置patch。外接的两个另配 U.FL→SMA 尾线。⚠️ 换牌子必须核对焊盘数——四焊盘款（如品赞 C5299419）会多一脚悬空 |
| 🟡有推荐 | U.FL 座 | U.FL_GNSS_EXT(经尾线转SMA) | U.FL_Hirose_U.FL-R-SMT-1_Vertical | 1 | J2 | 聚兴泰 AIPEX-1 | C41432122 | 扩展⚠️ | IPEX1 板端内针 50Ω / DC~6GHz / VSWR1.3。**规格书标注 3 PADS TYPE**，焊盘与板上 U.FL_Hirose_U.FL-R-SMT-1_Vertical 完全匹配（跨距4.00/间距1.90/2.20×1.05）。4 个：1090外接/978/GNSS外接/GNSS内置patch。外接的两个另配 U.FL→SMA 尾线。⚠️ 换牌子必须核对焊盘数——四焊盘款（如品赞 C5299419）会多一脚悬空 |
| 🟡有推荐 | U.FL 座 | U.FL_IFA_TEST(π后调试口) | U.FL_Hirose_U.FL-R-SMT-1_Vertical | 1 | J7 | 聚兴泰 AIPEX-1 | C41432122 | 扩展⚠️ | IPEX1 板端内针 50Ω / DC~6GHz / VSWR1.3。**规格书标注 3 PADS TYPE**，焊盘与板上 U.FL_Hirose_U.FL-R-SMT-1_Vertical 完全匹配（跨距4.00/间距1.90/2.20×1.05）。4 个：1090外接/978/GNSS外接/GNSS内置patch。外接的两个另配 U.FL→SMA 尾线。⚠️ 换牌子必须核对焊盘数——四焊盘款（如品赞 C5299419）会多一脚悬空 |
| 🟡有推荐 | U.FL 座 | U.FL_VHF(经尾线转SMA) | U.FL_Hirose_U.FL-R-SMT-1_Vertical | 1 | J10 | 聚兴泰 AIPEX-1 | C41432122 | 扩展⚠️ | IPEX1 板端内针 50Ω / DC~6GHz / VSWR1.3。**规格书标注 3 PADS TYPE**，焊盘与板上 U.FL_Hirose_U.FL-R-SMT-1_Vertical 完全匹配（跨距4.00/间距1.90/2.20×1.05）。4 个：1090外接/978/GNSS外接/GNSS内置patch。外接的两个另配 U.FL→SMA 尾线。⚠️ 换牌子必须核对焊盘数——四焊盘款（如品赞 C5299419）会多一脚悬空 |
| 🟡有推荐 | U.FL 座 | U.FL→内置patch | U.FL_Hirose_U.FL-R-SMT-1_Vertical | 1 | J8 | 聚兴泰 AIPEX-1 | C41432122 | 扩展⚠️ | IPEX1 板端内针 50Ω / DC~6GHz / VSWR1.3。**规格书标注 3 PADS TYPE**，焊盘与板上 U.FL_Hirose_U.FL-R-SMT-1_Vertical 完全匹配（跨距4.00/间距1.90/2.20×1.05）。4 个：1090外接/978/GNSS外接/GNSS内置patch。外接的两个另配 U.FL→SMA 尾线。⚠️ 换牌子必须核对焊盘数——四焊盘款（如品赞 C5299419）会多一脚悬空 |
| 🟡有推荐 | USB VBUS分压 | 30k | R_0603_1608Metric | 1 | R50 | UNI-ROYAL 0603WAF3002T5E | C22984 | 基础✅ | R50 上臂。基础库，2 片总成本 ¥0.07；R51 下臂 10k 用现有元件本 |
| 🟡有推荐 | USB-C | USB-C_16P | USB_C_Receptacle_HRO_TYPE-C-31-M-12 | 1 | J4 | HRO TYPE-C-31-M-12 | — | 按值配料 | RP2040 刷机口 |
| 🟡有推荐 | VBUS分压滤波 | 10nF C0G | C_0603_1608Metric | 1 | C87 | 0603 10nF C0G/NP0 25V以上 | — | 按值配料 | C87，USB_VBUS_SENSE 对地。**自己贴**：C0G 仅扩展库有，1 颗不值 ¥20 上机费。🔴 反例：基础库 C57112 是 **X7R**（2026-09-04 在线核实），别拿它换 |
| 🟡有推荐 | 储能 | 22uF | C_0805_2012Metric | 2 | C60,C66 | Samsung CL21A226MAQNNNE（基础库） | C45783 | ? | 25V ±20% X5R。**嘉立创基础库**，免 ¥20 上机费。25V 比原设计的 16V 更高，向上兼容；±20% 对储能电容够用（X5R 在直流偏压下本就掉一半容值） |
| 🟡有推荐 | 去耦 | 100nF | C_0603_1608Metric | 27 | C10,C11,C12,C13,C14,C16…(27) | 国巨 CC0603KRX7R9BB104（基础库） | C14663 | ? | **嘉立创基础库**，买 38 颗免上机费。有券时 Venkel C3834556 料费更低（¥1.79 vs ¥3.08） |
| 🟡有推荐 | 射频开关 | XA17-G4K | SOT-363_SC-70-6 | 2 | U16,U17 | 信路达 XA17-G4K | C513494 | 扩展⚠️ | 单一料号，不列双源。SOT-363 很小，建议多备 3 颗 |
| 🟡有推荐 | 晶振 | 32.768kHz FC-135 | Crystal_SMD_3215-2Pin_3.2x1.5mm | 1 | Y3 | EPSON Q13FC13500004 | C32346 | 基础✅ |  |
| 🟡有推荐 | 晶振 | 48MHz ABM8W-7pF | Crystal_SMD_3225-4Pin_3.2x2.5mm | 1 | Y2 | Abracon ABM8W-48.0000MHZ-7-D1X-T3 | C6732653 | 扩展⚠️ | CC1312R 主晶振，7pF 负载 |
| 🟡有推荐 | 晶振负载 | 18pF | C_0603_1608Metric | 3 | C68,C69,C89 | 三星 CL10C180JB8NNNC（基础库） | C1647 | 基础✅ | 配 Y3 Q13FC13500004(FC-135) 的 CL=12.5pF → C=(12.5−3)×2=19pF 取标称 18pF。两颗必须同值，⚠️必须 C0G |
| 🟡有推荐 | 检波器电源RC | 10R | R_0402_1005Metric | 1 | R54 | UNI-ROYAL 0402WGF100JTCE（±5%） | C25077 | 基础✅ | R54，3V3_RF → AD8313 VPOS 的隔离电阻。基础库，2 片总成本 ¥0.04 |
| 🟡有推荐 | 源端阻尼 | 33R | R_0603_1608Metric | 1 | R57 | UNI-ROYAL 0603WAF330JT5E | C23140 | 基础✅ | R57，TLV3501 输出串阻（P2-10）。基础库，2 片总成本 ¥0.03 |
| 🟡有推荐 | 电源-REGN储能 | 4.7uF(带电源版) | C_0603_1608Metric | 1 | C71 | Samsung CL10A475KO8NNNC | C19666 | 基础✅ | C71：CHG_REGN 去耦，仅带电源版贴；不带电源版随 U19 整组不贴 |
| 🟡有推荐 | 电源-变体电阻 | 5.1k DNP(带电源版) | R_0603_1608Metric | 2 | R7,R8 | 0603 5.1k 1% | — | 按值配料 | R7/R8：带电源版不贴；不带电源版必须贴，两种变体不得混装 |
| 🟡有推荐 | 电源-热敏 | NCP18XH103F03RB 10k NTC | R_0603_1608Metric | 1 | RT1 | Murata NCP18XH103F03RB / TDK NTCG163JF103FT1 / 国产 0603 10K 1% | — | 按值配料 | **必须是贴片 NTC，不是普通电阻**。电池用 3M 胶直接贴 B 面、无间隙，插件玻璃头放不下。B25/85=3428K 与 datasheet 的 103AT-2(3435K) 差 0.2%，分压电阻 R39/R40 不用改 |
| 🟡有推荐 | 电源-电容 | 10uF | C_1206_3216Metric | 1 | C72 | 1206 10uF 25V X5R/X7R | — | 按值配料 | SY6970 PMID，手册明确要求 10µF；接 9V 侧**耐压必须 25V**，并核对所选料在 9V DC bias 下的有效容值 |
| 🟡有推荐 | 电源-电容 | 22uF | C_1206_3216Metric | 1 | C76 | 1206 22uF 10V X5R/X7R | — | 按值配料 | 其余 SYS/BAT 储能位；核对工作电压下有效容值 |
| 🟡有推荐 | 电源-电容 | 47nF | C_0603_1608Metric | 1 | C70 | 0603 47nF 25V X7R | — | 按值配料 | SY6970 BST 自举 |
| 🟡有推荐 | 电源-电阻 | 150k | R_0603_1608Metric | 1 | R42 | 0603 150k 1% | — | 按值配料 | FB 下分压；470k/150k → 4.96V |
| 🟡有推荐 | 电源-电阻 | 180R | R_0603_1608Metric | 1 | R38 | 0603 180R 1% | — | 按值配料 | SY6970 R_ILIM；K_ILIM=360A·Ω → 2A |
| 🟡有推荐 | 电源-电阻 | 31.6k | R_0603_1608Metric | 1 | R40 | 0603 31.6k 1% | — | 按值配料 | NTC 分压下臂（E96 最近值） |
| 🟡有推荐 | 电源-电阻 | 470k | R_0603_1608Metric | 1 | R41 | 0603 470k 1% | — | 按值配料 | SY7069 FB 上分压 |
| 🟡有推荐 | 电源-电阻 | 5.62k | R_0603_1608Metric | 1 | R39 | 0603 5.62k 1% | — | 按值配料 | NTC 分压上臂（E96 最近值） |
| 🟡有推荐 | 电阻 | 10k | R_0402_1005Metric | 2 | R52,R53 | UNI-ROYAL 0402WGF1002TCE（基础库） | C25744 | 基础✅ | R52/R53，BNO085 ENV 上拉。基础库，2 位号 2 片总成本 ¥0.08 |
| 🟡有推荐 | 磁力计储能 | 4.7uF | C_0603_1608Metric | 1 | C15 | Samsung CL10A475KO8NNNC | C19666 | 基础✅ | 低 ESR，QMC5883P 要求 |
| 🟡有推荐 | 自恢复保险丝 | 6V/200mA | Fuse_0805_2012Metric | 4 | F2,F3,F4,F5 | 金瑞 JK-SMD0805-020-30V | C516070 | 扩展⚠️ | Ih=200mA，30V 耐压，$0.031，库存 60 万 |
| 🟡有推荐 | 隔直/旁路 | 100pF | C_0402_1005Metric | 11 | C21,C30,C36,C38,C39,C45…(11) | 风华 0402CG101J500NT（C0G，基础库） | C1546 | 基础✅ | 隔直非匹配位，技术上 X7R 也够用（1090MHz 阻抗 1.46Ω，全路径实算差 0.13dB）。这里锁 C1546 是因为它属**基础库**：单价 ¥0.0271 且免 ¥20 上机费，比按值配到扩展库更省，C0G 是顺带白拿的。2026-09-04 在线核实。自己贴则用现有元件本即可 |
| 🟢通用/元件本 | IFA 匹配-串联 | 0R 串 | L_0603_1608Metric | 1 | ZS1 | 默认0R直通；调试时换值 | — | 按值配料 | 备1-30nH；HFSS首轮可从3.6nH起扫。⚠️量产件Q变化后必须复测 |
| 🟢通用/元件本 | IFA 匹配-并联 | DNP 并-天线侧 | C_0603_1608Metric | 1 | ZP1 | 调试用，值上板实测确定 | — | 按值配料 | 0603便于换值；备C0G 0.5-12pF。默认DNP，HFSS首轮也保持DNP |
| 🟢通用/元件本 | IFA 匹配-并联 | DNP 并-电台侧 | C_0603_1608Metric | 1 | ZP2 | 调试用，值上板实测确定 | — | 按值配料 | 默认DNP；按完整六层rev2 HFSS目标处约20.97Ω结果，首轮可从3.3pF起扫，并备3.6/3.9pF，最终以装盒VNA为准 |
| 🟢通用/元件本 | 储能 | 10uF | C_0805_2012Metric | 8 | C1,C18,C73,C74,C75,C91…(8) | 任意 10uF X5R 0805 | — | 按值配料 | 用元件本 |
| 🟢通用/元件本 | 去耦 | 100nF | C_0402_1005Metric | 2 | C37,C52 | 任意 100nF X7R | — | 按值配料 | 用元件本 |
| 🟢通用/元件本 | 去耦 | 1uF | C_0402_1005Metric | 2 | C48,C5 | 任意 1uF X5R | — | 按值配料 | 用元件本 |
| 🟢通用/元件本 | 实验跳线 | 0R DNP(旁路外接) | R_0402_1005Metric | 1 | R24 | 0R（默认不贴） | — | 按值配料 | 拆开关后硬跳外接支路，做「有开关 vs 无开关」灵敏度对比 |
| 🟢通用/元件本 | 实验跳线 | 0R DNP(旁路板载) | R_0402_1005Metric | 1 | R25 | 0R（默认不贴） | — | 按值配料 | 同上，硬跳板载 IFA |
| ✅已有 | DNP-检波器上拉 | 1k DNP | R_0402_1005Metric | 1 | R30 | 不采购/不贴 | — | 按值配料 | R30 必须 DNP：RF_DET_OUT 与 3V3_RF 之间不得直流相连 |
| ✅已有 | DNP-比较器输出 | 1k DNP | R_0603_1608Metric | 1 | R36 | 不采购/不贴 | — | 按值配料 | R36 必须 DNP，避免 3V3_RF 与 3V3_DIG 通过上拉直流相连 |
| ✅已有 | USB 串阻 | 27R | R_0603_1608Metric | 2 | R10,R9 | 0603 电阻本 27R | — | 按值配料 | 用现有元件本 |
| ✅已有 | 上/下拉 | 10k | R_0603_1608Metric | 19 | R1,R17,R18,R26,R27,R32…(19) | 0603 电阻本 10k | — | 按值配料 | 用现有元件本 |
| ✅已有 | 上拉 | 4.7k | R_0603_1608Metric | 2 | R2,R3 | 0603 电阻本 4.7k | — | 按值配料 | 用现有元件本 |
| ✅已有 | 主芯片 | AD8313ARMZ | MSOP-8_3x3mm_P0.65mm | 1 | U14 | AD8313ARMZ | — | 按值配料 | §7 清单已下单 |
| ✅已有 | 主芯片 | ATGM336H-6N-74 | ATGM336H_LCC-18 | 1 | U7 | ATGM336H-6N-74 | — | 按值配料 | §7 清单已下单 |
| ✅已有 | 主芯片 | BGA2817 | SOT-363_SC-70-6 | 1 | U12 | BGA2817 | — | 按值配料 | §7 清单已下单 |
| ✅已有 | 主芯片 | BMP388 | BMP388_LGA-10 | 1 | U5 | BMP388 | — | 按值配料 | §7 清单已下单 |
| ✅已有 | 主芯片 | BNO085 | BNO085_LGA-28 | 1 | U4 | BNO085 | — | 按值配料 | §7 清单已下单 |
| ✅已有 | 主芯片 | CC1312R1F3RGZR | QFN-48-1EP_7x7mm_P0.5mm_EP5.15x5.15mm | 1 | U10 | CC1312R1F3RGZR | — | 按值配料 | §7 清单已下单 |
| ✅已有 | 主芯片 | ME6211C33M5 | SOT-23-5 | 1 | U1 | ME6211C33M5 | — | 按值配料 | §7 清单已下单 |
| ✅已有 | 主芯片 | QMC5883P | LGA-16_3x3mm_P0.5mm | 1 | U6 | QMC5883P | — | 按值配料 | §7 清单已下单 |
| ✅已有 | 主芯片 | QPL9547TR7 | DFN-8-1EP_2x2mm_P0.5mm_EP0.86x1.55mm | 1 | U11 | QPL9547TR7 | — | 按值配料 | §7 清单已下单 |
| ✅已有 | 主芯片 | RP2040 | QFN-56-1EP_7x7mm_P0.4mm_EP3.2x3.2mm | 1 | U8 | RP2040 | — | 按值配料 | §7 清单已下单 |
| ✅已有 | 主芯片 | TA0970A | TA0970A_SMD3838-6 | 2 | FL1,FL2 | TA0970A | — | 按值配料 | §7 清单已下单 |
| ✅已有 | 主芯片 | TLV3501(TOKMAS) | SOT-23-6 | 1 | U15 | TLV3501(TOKMAS) | — | 按值配料 | §7 清单已下单 |
| ✅已有 | 主芯片 | TPS7A2033PDBVR | SOT-23-5 | 2 | U2,U3 | TPS7A2033PDBVR | — | 按值配料 | §7 清单已下单 |
| ✅已有 | 主芯片 | W25Q128JVSIQ | SOIC-8_5.3x5.3mm_P1.27mm | 1 | U9 | W25Q128JVSIQ | — | 按值配料 | §7 清单已下单 |
| ✅已有 | 主芯片-航空射频 | BK4819QN32SC | QFN-32-1EP_4x4mm_P0.4mm_EP2.65x2.65mm | 1 | U21 | BK4819QN32SC（博通 Beken） | 淘宝 | ? | **库存 10 颗**（每板 1 颗 → 够 10 块板，全套里最少的一种）。18–660MHz 收发器，只用接收；PAOUT 不接、PA 不使能（RX-only） |
| ✅已有 | 分压/下拉 | 100k | R_0603_1608Metric | 1 | R33 | 0603 电阻本 100k | — | 按值配料 | 用现有元件本 |
| ✅已有 | 去耦 | 1uF | C_0603_1608Metric | 11 | C2,C28,C29,C3,C4,C6…(11) | 0603 电容本 1uF X5R | — | 按值配料 | 用现有元件本 |
| ✅已有 | 对插排针 | J3_HAT_2x20_SMD排针 | PinHeader_2x20_P2.54mm_Vertical_SMD | 1 | J1 | 2×20 2.54mm 贴片排针 | — | 按值配料 | ✅用户已有（实测 51mm 长 / 贴片脚 2.85 / 配合板间距 7.0） |
| ✅已有 | 旁路 | 100pF | C_0603_1608Metric | 3 | C55,C56,C88 | 0603 电容本 100pF | — | 按值配料 | 用现有元件本 |
| ✅已有 | 晶振-航空参考 | 26MHz TCXO <=2.5ppm | Crystal_SMD_2520-4Pin_2.5x2.0mm | 1 | Y4 | Epson TG-5006CG-12H（2520） | 淘宝 | ? | **库存 20 颗**（每板 1 颗 → 够 20 块板）。BK4819 要求参考 ≤±2.5ppm；输出削峰正弦，需交流耦合进 XI |
| ✅已有 | 板载1090天线 | IFA_1090 | ANT_IFA_1090MHz | 1 | ANT1 | PCB 铜箔（无器件） | — | 按值配料 | 50.0mm铜箔外包络（48.5mm中心线）已落PCB；V4.0实板装盒1082.5MHz、SWR 1.09；不占BOM |
| ✅已有 | 测试点 | TestPoint | TestPoint_Pad_1.0x1.0mm | 7 | TP1,TP2,TP3,TP4,TP5,TP6…(7) | PCB 焊盘，无器件 | — | 按值配料 | 不采购 |
| ✅已有 | 滤波 | 1nF | C_0603_1608Metric | 1 | C51 | 0603 电容本 1nF | — | 按值配料 | 用现有元件本 |
| ✅已有 | 滤波 | 200pF | C_0603_1608Metric | 1 | C47 | 0603 电容本 200pF | — | 按值配料 | 用现有元件本 |
| ✅已有 | 滤波 | 3pF | C_0603_1608Metric | 1 | C46 | 0603 电容本 3pF | — | 按值配料 | 用现有元件本 |
| ✅已有 | 短接焊盘 | BOOTSEL短接焊盘 | SolderJumper-2_P1.3mm_Open_Pad1.0x1.5mm | 1 | SW2 | PCB 焊盘，无器件 | — | 按值配料 | 同上 |
| ✅已有 | 短接焊盘 | RESET短接焊盘 | SolderJumper-2_P1.3mm_Open_Pad1.0x1.5mm | 1 | SW1 | PCB 焊盘，无器件 | — | 按值配料 | 镊子短接，不采购 |
| ✅已有 | 跳线 | 0R | R_0603_1608Metric | 7 | R21,R22,R23,R37,R48,R49…(7) | 0603 电阻本 0R | — | 按值配料 | 用现有元件本 |
| ✅已有 | 限流/偏置 | 1k | R_0603_1608Metric | 3 | R31,R4,R43 | 0603 电阻本 1k | — | 按值配料 | 用现有元件本 |
| ✅已有 | 音频ADC | PCM1808PWR | TSSOP-14_4.4x5mm_P0.65mm | 1 | U22 | PCM1808PWR（TI） | C55513 | ? | **库存 20 颗**（每板 1 颗 → 够 20 块板）。24bit/96kHz 立体声 ADC，SNR99dB，无 I²C（避免与载板 ES7210 0x40 冲突） |

## 扩展库料清单（17 种，每种 ¥20 上机费）

> 券能减免上机费，但券不是永远有。下次优化按这张表逐个找基础库替代——
> 换掉一种就少 ¥20，比在料费上省几毛有效得多。
> 替换后必须重新核对**型号编码**（如 `1002`=10kΩ、`5102`=5.1kΩ），
> 搜索是模糊匹配，返回的第一条不一定是要的值。

| 立创料号 | 值/规格 | 位号 |
|---|---|---|
| `C113111` | 27nH | L10 |
| `C1561` | 2.7pF | C41 |
| `C18221115` | 100nH | L8,L14,L18 |
| `C273696` | 52.3R | R19 |
| `C2830293` | TPESD8L3.3 0.3pFtyp 0.5pFmax | D2,D3,D4,D5,D6 |
| `C41432122` | U.FL_1090_EXT(经尾线转SMA) / U.FL_978 / U.FL_GNSS_EXT(经尾线转SMA) / U.FL_IFA_TEST(π后调试口) / U.FL_VHF(经尾线转SMA) / U.FL→内置patch | J2,J5,J6,J7,J8,J10 |
| `C41744` | 6.2pF | C42 |
| `C513494` | XA17-G4K | U16,U17 |
| `C516070` | 6V/200mA | F2,F3,F4,F5 |
| `C5552081` | 3.6pF | C40,C44 |
| `C6732653` | 48MHz ABM8W-7pF | Y2 |
| `C6807986` | 33nH | L2,L15 |
| `C696883` | 3pF | C43 |
| `C82157` | 6.8uH | L7 |
| `C82918` | 7.5nH | L9,L13 |
| `C82919` | 6.8nH | L11,L12 |
| `C970725` | CH224K | U18 |

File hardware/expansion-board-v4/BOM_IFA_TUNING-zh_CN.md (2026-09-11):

# V4.5 板载 1090MHz IFA 复核与调试备料单

英文版：[`BOM_IFA_TUNING.md`](BOM_IFA_TUNING.md)

> 用途：复核已按50.0mm实测定型的v4板载1090MHz IFA，并为外壳或板材变化保留可选匹配备料。
> 本表是独立调试备料单，不替代整板 [`BOM_PURCHASE.md`](BOM_PURCHASE.md)。
>
> 当前工程事实：ZP1/ZP2 为 0603 并联位，ZS1 为 0603 串联位，J7 为 U.FL 调试口，
> C53 为0402 100pF。J7位于π网络之后、C53之前。VNA测量的必要条件是**后级路径断路**，
> 不是C53本身一律DNP。V4.0实测板已贴C53，但U17等后级元件未贴，因此没有形成负载通路，
> C53与本次读数无关。

## 1. 先明确装配状态

| 状态 | ZP1（天线侧并联） | ZS1（串联） | ZP2（电台侧并联） | J7 | C53 | 用途 |
|---|---:|---:|---:|---:|---:|---|
| **V4.4默认 / V4.0实测状态** | DNP | **0R** | DNP | 贴 | **100pF** | 外包络50.0mm；实测板因U17等后级未贴而保持断路，从J7测量有效 |
| **后级已贴通的校准板** | DNP | **0R** | DNP | 贴 | **DNP或以其它方式隔离** | 单独测天线前必须断开后级；不贴C53只是隔离方法之一，并非无条件要求 |
| **历史HFSS首轮起点（已被实测取代）** | DNP | 3.6nH | 3.3pF | 贴 | 后级断路 | 约50.230mm中心线长度的打板前预测；仅保留为异常批次扫值备选，不是V4.4默认值 |
| **外壳/板材变更后的复调状态** | 实测决定 | 实测决定 | 实测决定 | 可保留 | **100pF** | 仅在新量产组合相对V4.0基线出现稳定偏移时使用 |

> **DNP = 不贴。** 量产基线是直通，不是3.6nH/3.3pF。V4.0天线切到**铜箔外包络50.0mm、
> 中心线跨度48.5mm**后，1090MHz装盒实测SWR 1.09、45+j0.5Ω；出盒实测
> SWR 1.09、45+j0.5Ω。

### 实板实测 + 跨厂对照（2026-09-11）

两块板都**只贴 ZS1(0R)、J7、J6 三个件**、后级断路，从 J7 测。同一份 Gerber、
同一根 U.FL 尾线、同一次校准，**唯一变量是板厂**。IFA 几何 V4.4→V4.5 未变，
本组数据对两版都有效。

| | **嘉立创 `JLC06161H-3313`** | **捷配 `JP06161H-7628A1`** |
|---|---|---|
| L1–L2 介质 | 3313 ×1，h≈0.0994mm | 7628 ×1，h≈0.186mm |
| **SWR 谷底频率** | **1085.0 MHz** | **1062.5 MHz** |
| **谷底 SWR** | **1.055** | **1.717** |
| 谷底阻抗（含尾线）| 52.54 + j0.43 Ω | 59.90 + j26.18 Ω |
| 谷底阻抗（**de-embed 后**）| **51.47 + j2.28 Ω** | **39.28 + j21.75 Ω** |

**50.0mm 定型值在嘉立创板上复现成功** —— 谷底 1085MHz、SWR 1.055，与 V4.0 装盒
实测的 1082.5MHz / SWR 1.09 一致，53.5mm 逐刀切到 50.0mm 那轮实验闭环完成。

> 🔴 **但换到捷配就失谐了：低 22.5MHz、SWR 从 1.055 掉到 1.717。**
> 原因是板材 εr 不同（反推 εeff 高 4.28%），**不是捷配做错了**。
> 详见 `hardware/PCB_STACKUP_IMPEDANCE-zh_CN.md` §5.2 ——
> 那一节此前写「天线不受叠层影响」是错的，**镂掉的是铜，板材还在**。
>
> 要在捷配板上拉回 1085MHz，按 11.5 MHz/mm 需再切约 **2.0mm**（50.0 → 约 48.0mm）。
> **这个修正量只对捷配的板材成立，换别家要重新测。**

**这批数据踩过的四个坑，测之前先看：**

> ⚠️ **判中心频率要找 SWR 曲线的谷底，不要在目标频率上读数。** 本次就差了 5MHz：
> 把 M1 停在 1090 读到 SWR 1.083，而真正的谷底在 1085、SWR 1.051。
>
> ⚠️ **别用「Smith 图何时穿实轴」判频率** —— 那个判据被尾线污染了。
> SWR 曲线的谷底位置则不受尾线影响，是可靠的。
>
> ⚠️ **U.FL 尾线必须 de-embed**（`hardware/tools/vna_deembed.py`）。
> **先测一次尾线空接的开路读数**作为参考，换线或重新校准都要重测。
> 本次尾线：9.984 − j115.2Ω，往返损耗 0.55dB。
> 尾线不仅旋转阻抗，**对严重失配的负载还会把 SWR 压得偏乐观**
> （同批 J6 开路线：读数 SWR 10.8，实际 16.4）。
>
> ⚠️ **出盒 ≠ 装盒。** 上表是裸板值。外壳会把谐振往下拉，装盒后落到 1080 附近
> 属正常。**最终验收以装盒值为准。**
>
> 📏 **测量重复性约 2%**（同一根尾线两次测嘉立创 J6 的板上电抗：−j38.50 vs −j39.27）。
> 小于这个量的差异不要当成结论。

## 2. 首装默认料

| 采购 | 类别 | 值/规格 | 封装 | 建议采购量 | 对应位号 | 供应商/料号 | 说明 |
|---|---|---|---|---:|---|---|---|
| 🔴必买 | 默认直通 | 0R，跳线电阻 | 0603 | 20 | ZS1 | 通用0603 0R | 基线状态使用；优先选低寄生、额定值普通的厚膜0R即可 |
| 🔴必买 | HFSS 起点 | 3.6nH，RF 高 Q 电感 | 0603 | 20 | ZS1 | **Murata LQW18AN3N6C00D**；或同规格Coilcraft 0603HP-3N6XJRW | Murata该档SRF 6GHz、Q(min) 25；1090MHz余量足够。整盒换值尽量保持同一系列 |
| 🔴必买 | HFSS 起点 | 3.3pF，C0G/NP0 | 0603 | 20 | ZP2 | **Murata GRM1885C1H3R3BA01D** | 50V、C0G、±0.1pF；ZP1首轮保持DNP |
| 🔴必买 | 调试接口 | 50Ω U.FL 板端座 | U.FL_Hirose_U.FL-R-SMT-1_Vertical 兼容封装 | 3 | J7 | 聚兴泰 AIPEX-1 **C41432122**（三焊盘）；原厂 Hirose U.FL-R-SMT-1(80) C88374 亦可 | 1颗首装、2颗备损；必须用三焊盘款。品赞 C5299419 是四焊盘封装，与本板不兼容 |
| 🟢元件本 | 接收链隔直 | 100pF | 0402 | 20 | C53 | 任意100pF，**X7R即可** | 后级本来断路时VNA测量可保留；后级已贴通时需隔离。**不必买C0G**，理由见下 |

> **C53 为什么不用 C0G**（2026-08-28 与 [`BOM_PURCHASE.md`](BOM_PURCHASE.md) 对齐）：
> 本表原来把 C53 列为「🔴必买 C0G」，跟整板采购清单的「🟢通用，X7R 即可」冲突。
> 复核后按 X7R 走——**C53 是隔直电容，不是匹配元件**，被第 5 节「所有匹配电容
> 统一 C0G」那条顺手划进去了。它在 1090MHz 的阻抗只有
> `1/(2π·1090MHz·100pF) = 1.46Ω`，X7R 容值漂 ±15% 也只到 1.7Ω；
> `BOM_PURCHASE.md` 实算全路径只差 **0.13dB**。
> C53本身也不会凭空形成终端：U17等后级元件未贴时，C53后方仍是断路，这正是V4.0的实测状态。
> ZP1/ZP2/ZS1才是匹配位；ZP1/ZP2若贴电容仍必须使用C0G/NP0。

## 3. 匹配替换料

采购时尽量让同一类元件来自**同一厂商、同一 RF 系列**。不同系列即使标称值相同，Q、
SRF、焊盘寄生也可能不同；换厂或换系列后必须复测。

### 3.1 ZS1 串联电感盒

| 采购 | 值范围 | 封装 | 每档建议数量 | 供应商/料号 | 强制规格 | 说明 |
|---|---|---|---:|---|---|---|
| 🔴核心档 | 2.7 / 3.0 / 3.3 / **3.6** / 3.9 / 4.3 / 4.7 / 5.1 / 5.6 / 6.2nH | 0603 | 10 | 首选Murata **LQW18AN_00**同系列；3.6nH见上表 | RF高Q；SRF≥2.0GHz，优选≥2.5GHz；容差≤±5% | 覆盖当前3.6nH预测值及相邻换料；每一档下单前仍需按具体料号核对SRF/Q |
| 🟡扩展低档 | 1.0 / 1.2 / 1.5 / 1.8 / 2.2nH | 0603 | 10 | 待选型 | 同上 | 实测只需较小串联电抗时使用 |
| 🟡扩展高档 | 6.8 / 7.5 / 8.2 / 9.1 / 10nH | 0603 | 10 | 待选型 | 同上；逐值核对SRF，不接受只写“RF电感”而无曲线/参数 | 实测阻抗显著偏离HFSS时扩大搜索范围 |

> 不建议盲买到 30nH：电感值越大，SRF通常越低。在1090MHz附近接近或越过SRF后，器件已不再
> 表现为电感。若确实需要10nH以上，必须先核对该具体料号在1090MHz处仍为感性并有足够Q，再单独补购。

### 3.2 ZP1/ZP2 并联电容盒

| 采购 | 值范围 | 封装 | 每档建议数量 | 供应商/料号 | 强制规格 | 说明 |
|---|---|---|---:|---|---|---|
| 🔴核心档 | 2.2 / 2.4 / 2.7 / 3.0 / **3.3** / 3.6 / 3.9 / 4.3 / 4.7 / 5.1pF | 0603 | 20 | 首选Murata **GRM1885C1H…BA01D**同系列；3.3pF见上表 | **C0G/NP0**；容差优选±0.1pF或±5%；额定电压≥25V | 覆盖3.411pF理想值及相邻换料；ZP1、ZP2可共用；各电容值对应的完整料号不同，须逐项按官方选型表确认 |
| 🟡扩展低档 | 0.5 / 0.6 / 0.7 / 0.8 / 1.0 / 1.2 / 1.5 / 1.8pF | 0603 | 20 | 待选型 | **C0G/NP0**；优选±0.1pF | 小电容档寄生占比高，务必保持系列一致 |
| 🟡扩展高档 | 5.6 / 6.2 / 6.8 / 7.5 / 8.2 / 9.1 / 10 / 12pF | 0603 | 20 | 待选型 | **C0G/NP0**；容差≤±5%；额定电压≥25V | 实测显著偏离HFSS时扩大搜索范围 |

## 4. 测试连接件与耗材

| 采购 | 类别 | 规格 | 建议采购量 | 供应商/料号 | 用途/注意事项 |
|---|---|---|---:|---|---|
| 🔴必买 | VNA连接线 | 50Ω U.FL插头 → SMA公头，短柔性同轴线 | 3 | 待选型 | 1条测量、2条备损；选定长度后固定用同一条线，反复弯折会改变读数 |
| 🟡建议 | SMA转接/延长 | 50Ω SMA公母转接件或柔性测试线 | 1套 | 待选型 | 减少NanoVNA端口受力；使用后应把校准面/端口延伸纳入测量流程 |
| 🔴必买 | 助焊剂 | 免洗、适合0603/0402返修 | 1支 | 待选型 | 降低反复换料造成的焊盘损伤；调完后清洁残留并复测 |
| 🔴必买 | 焊锡丝 | 约0.3mm细锡丝 | 1卷 | 待选型 | 用于0603/0402手工换料和铜箔恢复实验 |
| 🔴必买 | 吸锡带 | 约0.8–1.0mm | 1卷 | 待选型 | 清理ZP1/ZP2/ZS1/C53焊盘，避免堆锡改变射频寄生 |
| 🟡仅返修 | 切削刀片 | 尖头刻刀/手术刀替换刀片 | 1盒 | 待选型 | V4.4已回灌50.0mm实测几何；只有外壳/板材变更后受控复调时才每次切0.1–0.2mm |
| 🟡建议 | 铜箔恢复料 | 无胶裸铜箔，厚约0.03–0.05mm，宽度≥1.5mm | 1份 | 待选型 | 仅用于切过头后的实验恢复和确认方向；最终量产长度应回写PCB铜箔，不把粘贴铜箔当量产方案 |
| 🟡建议 | 固定耗材 | 与量产一致的绝缘胶带/泡棉/螺丝 | 1套/样机 | 待选型 | 装盒位置和金属螺丝会改变谐振，调试时必须使用与量产一致的装配状态 |

## 5. 下单与分装要求

1. 0603电感、0603电容必须按数值保留原编带和标签，禁止拆成无标识散料混放。
2. 电感下单前逐个核对数据表：封装是0603、1090MHz处仍为感性、SRF满足本表要求，并有Q或阻抗曲线。
3. **匹配位**（ZP1/ZP2）的电容统一购买 C0G/NP0，不要用 X5R/X7R 替代。
   ⚠️ 这条只管 ZP1/ZP2——`C53` 是隔直不是匹配，X7R 即可（见第 2 节表下的说明）。
4. 优先下单“核心档”；预算允许再买扩展档。若只做一块样机，核心档已覆盖当前HFSS预测附近的主要换料范围。
5. 建议用带格子的防静电样品盒分装，并按“器件类型 + 标称值 + 厂商系列”标记，防止3.3pF/3.3nH混淆。

已核实的型号依据：Murata `LQW18AN3N6C00D` 为1608/0603、3.6nH、SRF 6GHz；
Murata `GRM1885C1H3R3BA01D` 为0603、3.3pF、50V、C0G、±0.1pF；
（`C53` 原列的 Murata `GRM1555C1H101JA01D` 已改为「任意 100pF X7R」，见第 2 节）；
Hirose `U.FL-R-SMT-1(80)` 为50Ω直立SMT插座、最高8GHz。若采购平台上的标题与这些参数冲突，
以制造商完整料号和数据表为准，不按商品简称替代。

## 6. 最短调试顺序

1. 核实成品铜箔外包络为50.0mm；ZS1贴0R、ZP1/ZP2不贴，J7贴U.FL。
2. 确认C53后方接收路径断路。U17等后级未贴时C53可保留；后级已贴通时再隔离该路径。
3. **先测一次尾线空接的开路读数**（U.FL 端什么都不接），记下 R/X —— 这是本次校准的
   de-embed 参考，换线或重新校准都要重测。
4. 从J7接VNA，先出盒测，再按量产状态装入屏幕、TF卡座、电池和螺丝齐全的整机测。
5. **扫频找 SWR 曲线的谷底**，记录谷底频率与该处复阻抗，同上表基线比较。
   复阻抗先跑 `hardware/tools/vna_deembed.py` 去掉尾线；
   **不要在 1090MHz 上直接读数当中心频率**（会差几 MHz），也不要用
   「Smith 图何时穿实轴」判频率（被尾线污染）。
   不要只为追最深单点谷而切铜或套用历史HFSS料值。
6. 只有外壳/板材变更造成稳定的批次偏移时，才按每次0.1–0.2mm受控切短，并视需要使用π网络。
   **换板厂属于「板材变更」**，按 11.5MHz/mm 估算切多少（捷配 7628A1 实测需约 2.0mm）。
7. 做1090报文数量、距离和噪声底A/B；VNA匹配不能代替辐射效率验证。

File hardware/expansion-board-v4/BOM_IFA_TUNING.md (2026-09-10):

# V4.5 Onboard 1090MHz IFA Verification and Tuning Spares List
Chinese version: [`BOM_IFA_TUNING-zh_CN.md`](BOM_IFA_TUNING-zh_CN.md)

> Purpose: verify the measured 50.0mm v4 onboard 1090MHz IFA, and keep optional matching-network spares for enclosure or laminate changes.
> This list is an independent tuning spares list and does not replace the full-board [`BOM_PURCHASE.md`](BOM_PURCHASE.md).
>
> Current engineering facts: ZP1/ZP2 are 0603 shunt positions, ZS1 is a 0603 series position, J7 is the U.FL tuning port,
> C53 is a 0402 100pF. J7 sits after the π network and before C53. The VNA requirement is that the **downstream path be open**,
> not that C53 itself must always be DNP. On the measured V4.0 board C53 was populated while U17 and other downstream parts
> were unpopulated, so no load path existed and C53 did not affect the result.

## 1. First, clarify the assembly states

| State | ZP1 (antenna-side shunt) | ZS1 (series) | ZP2 (radio-side shunt) | J7 | C53 | Purpose |
|---|---:|---:|---:|---:|---:|---|
| **V4.4 nominal / V4.0 measured state** | DNP | **0R** | DNP | Populated | **100pF** | 50.0mm outer envelope; valid J7 isolation on the measured board because U17 and the remaining downstream path were unpopulated/open |
| **Calibration board with populated downstream chain** | DNP | **0R** | DNP | Populated | **DNP or otherwise isolated** | Open the downstream path before measuring the antenna independently; DNP C53 is one isolation method, not an unconditional requirement |
| **Historical HFSS first-round starting point (superseded)** | DNP | 3.6nH | 3.3pF | Populated | Open downstream | Pre-board prediction for a roughly 50.230mm centerline length; retained only as a contingency sweep point, not the V4.4 default |
| **Alternative enclosure/material retune** | Decided by measurement | Decided by measurement | Decided by measurement | May keep | **100pF** | Use only if a new production stack systematically moves away from the V4.0 measured baseline |

> **DNP = not populated.** The production baseline is straight-through, not 3.6nH/3.3pF. The V4.0 antenna trimmed to a
> **50.0mm copper outer envelope / 48.5mm centerline span**, trimmed cut-by-cut from
> 53.5mm and stopped at 50.0mm. In the case with the battery fitted it measured
> **1082.5MHz, SWR 1.09, 45+j0.5Ω**; with the case open (battery still fitted) the
> reading drifts over 1080–1090MHz. The same series gives a slope of 24–25MHz/mm.

## 2. Default parts for the first build

| Purchase | Category | Value/Spec | Footprint | Suggested Qty | Ref Des | Supplier/Part No. | Notes |
|---|---|---|---|---:|---|---|---|
| 🔴Must-buy | Default pass-through | 0R jumper resistor | 0603 | 20 | ZS1 | Generic 0603 0R | Used in the baseline state; any generic thick-film 0R with low parasitics and ordinary ratings is fine |
| 🔴Must-buy | HFSS starting point | 3.6nH, RF high-Q inductor | 0603 | 20 | ZS1 | **Murata LQW18AN3N6C00D**; or same-spec Coilcraft 0603HP-3N6XJRW | For this value Murata gives SRF 6GHz, Q(min) 25; ample margin at 1090MHz. When swapping values across the whole set, keep the same series as much as possible |
| 🔴Must-buy | HFSS starting point | 3.3pF, C0G/NP0 | 0603 | 20 | ZP2 | **Murata GRM1885C1H3R3BA01D** | 50V, C0G, ±0.1pF; keep ZP1 DNP in the first round |
| 🔴Must-buy | Tuning interface | 50Ω U.FL board-end receptacle | Footprint compatible with U.FL_Hirose_U.FL-R-SMT-1_Vertical | 3 | J7 | Juxingtai AIPEX-1 **C41432122** (three-pad); original Hirose U.FL-R-SMT-1(80) C88374 also works | 1 for first build and 2 spares. Use a three-pad part; Pinzan C5299419 has four pads and does not match this PCB footprint |
| 🟢Parts bin | Receive-chain DC block | 100pF | 0402 | 20 | C53 | Any 100pF, **X7R is fine** | May remain populated during VNA measurement if the downstream path is already open; otherwise isolate the path. **No need to buy C0G**; reasoning below |

> **Why C53 does not need C0G** (aligned with [`BOM_PURCHASE.md`](BOM_PURCHASE.md) on 2026-08-28):
> This list originally marked C53 as "🔴Must-buy C0G", which conflicted with the full-board purchase list's "🟢General, X7R is fine".
> After review, X7R stands — **C53 is a DC-blocking capacitor, not a matching component**; it was swept in by §5's "all matching
> capacitors uniformly C0G" rule. Its impedance at 1090MHz is only
> `1/(2π·1090MHz·100pF) = 1.46Ω`, and even with X7R capacitance drifting ±15% it only reaches 1.7Ω;
> the `BOM_PURCHASE.md` full-path calculation shows a difference of just **0.13dB**.
> C53 also does not create a termination by itself: with U17 and the remaining downstream parts unpopulated, the line after C53 is open.
> That was the actual V4.0 measurement state. ZP1/ZP2/ZS1 are the matching positions; any capacitor used at ZP1/ZP2 must still be C0G/NP0.

## 3. Matching replacement parts

When purchasing, keep each class of component from **the same vendor and the same RF series** as much as possible. Even with identical nominal values, different series can differ in Q,
SRF and pad parasitics; after changing vendor or series, re-measurement is mandatory.

### 3.1 ZS1 series inductor set

| Purchase | Value Range | Footprint | Suggested Qty per Step | Supplier/Part No. | Mandatory Spec | Notes |
|---|---|---|---:|---|---|---|
| 🔴Core tier | 2.7 / 3.0 / 3.3 / **3.6** / 3.9 / 4.3 / 4.7 / 5.1 / 5.6 / 6.2nH | 0603 | 10 | Prefer the same Murata **LQW18AN_00** series; for 3.6nH see the table above | RF high-Q; SRF≥2.0GHz, ≥2.5GHz preferred; tolerance ≤±5% | Covers the current 3.6nH prediction and adjacent swaps; before ordering each value, still verify SRF/Q against the specific part number |
| 🟡Extended low tier | 1.0 / 1.2 / 1.5 / 1.8 / 2.2nH | 0603 | 10 | To be selected | Same as above | Used when measurements call for only a smaller series reactance |
| 🟡Extended high tier | 6.8 / 7.5 / 8.2 / 9.1 / 10nH | 0603 | 10 | To be selected | Same as above; verify SRF value by value — listings that say only "RF inductor" without curves/parameters are not accepted | Expand the search when the measured impedance deviates significantly from HFSS |

> Blind-buying up to 30nH is not advised: the larger the inductance, the lower the SRF usually is. Near or past SRF around 1090MHz, the device no longer
> behaves as an inductor. If values above 10nH are truly needed, first verify that the specific part number is still inductive at 1090MHz with sufficient Q, then buy it separately.

### 3.2 ZP1/ZP2 shunt capacitor set

| Purchase | Value Range | Footprint | Suggested Qty per Step | Supplier/Part No. | Mandatory Spec | Notes |
|---|---|---|---:|---|---|---|
| 🔴Core tier | 2.2 / 2.4 / 2.7 / 3.0 / **3.3** / 3.6 / 3.9 / 4.3 / 4.7 / 5.1pF | 0603 | 20 | Prefer the same Murata **GRM1885C1H…BA01D** series; for 3.3pF see the table above | **C0G/NP0**; tolerance ±0.1pF or ±5% preferred; rated voltage ≥25V | Covers the 3.411pF ideal value and adjacent swaps; ZP1 and ZP2 can share; the full part number differs per capacitance value and must be confirmed item by item against the official selection table |
| 🟡Extended low tier | 0.5 / 0.6 / 0.7 / 0.8 / 1.0 / 1.2 / 1.5 / 1.8pF | 0603 | 20 | To be selected | **C0G/NP0**; ±0.1pF preferred | Parasitics dominate in the small-capacitance tiers, so keeping the series consistent is essential |
| 🟡Extended high tier | 5.6 / 6.2 / 6.8 / 7.5 / 8.2 / 9.1 / 10 / 12pF | 0603 | 20 | To be selected | **C0G/NP0**; tolerance ≤±5%; rated voltage ≥25V | Expand the search when measurements deviate significantly from HFSS |

## 4. Test connectors and consumables

| Purchase | Category | Spec | Suggested Qty | Supplier/Part No. | Purpose/Cautions |
|---|---|---|---:|---|---|
| 🔴Must-buy | VNA cable | 50Ω U.FL plug → SMA male, short flexible coax | 3 | To be selected | 1 for measuring, 2 spares for damage; once a length is chosen, stick to the same cable — repeated bending changes readings |
| 🟡Advised | SMA adapter/extension | 50Ω SMA male-female adapters or flexible test leads | 1 set | To be selected | Reduces stress on the NanoVNA port; once used, fold the calibration plane/port extension into the measurement procedure |
| 🔴Must-buy | Flux | No-clean, suitable for 0603/0402 rework | 1 pc | To be selected | Reduces pad damage from repeated component swaps; after tuning, clean residues and re-measure |
| 🔴Must-buy | Solder wire | Fine solder, about 0.3mm | 1 spool | To be selected | For hand-swapping 0603/0402 parts and copper-foil restoration experiments |
| 🔴Must-buy | Solder wick | About 0.8–1.0mm | 1 spool | To be selected | Clean the ZP1/ZP2/ZS1/C53 pads; avoid solder buildup changing RF parasitics |
| 🟡Service only | Cutting blades | Pointed hobby knife/scalpel replacement blades | 1 box | To be selected | V4.4 already contains the measured 50.0mm geometry; cut only during a controlled retune for a changed enclosure/material, 0.1–0.2mm at a time |
| 🟡Advised | Copper foil restoration stock | Adhesive-free bare copper foil, about 0.03–0.05mm thick, width ≥1.5mm | 1 sheet | To be selected | Only for experimental restoration after over-cutting and for confirming direction; the final production length must be written back into the PCB copper — attached foil is not a production solution |
| 🟡Advised | Assembly consumables | Insulating tape/foam/screws identical to production | 1 set/prototype | To be selected | In-enclosure placement and metal screws change the resonance; tuning must use the same assembly state as production |

## 5. Ordering and storage requirements

1. 0603 inductors and 0603 capacitors must keep their original tape and labels sorted by value; splitting them into unlabeled loose mixes is forbidden.
2. Before ordering each inductor, check its datasheet one by one: 0603 footprint, still inductive at 1090MHz, SRF meeting this table's requirements, plus a Q or impedance curve.
3. Capacitors for the **matching positions** (ZP1/ZP2) are purchased uniformly as C0G/NP0; do not substitute X5R/X7R.
   ⚠️ This rule covers ZP1/ZP2 only — `C53` is DC blocking, not matching, so X7R is fine (see the note under the §2 table).
4. Order the "core tiers" first; buy the extended tiers if the budget allows. For a single prototype, the core tiers already cover the main swap range around the current HFSS prediction.
5. Store parts in compartmented anti-static sample boxes labeled by "component type + nominal value + vendor series" to prevent confusing 3.3pF/3.3nH.

Verified model basis: Murata `LQW18AN3N6C00D` is 1608/0603, 3.6nH, SRF 6GHz;
Murata `GRM1885C1H3R3BA01D` is 0603, 3.3pF, 50V, C0G, ±0.1pF;
(the Murata `GRM1555C1H101JA01D` originally listed for `C53` has been changed to "any 100pF X7R", see §2);
Hirose `U.FL-R-SMT-1(80)` is a 50Ω vertical SMT receptacle rated to 8GHz. If a purchasing platform's listing title conflicts with these parameters,
defer to the manufacturer's full part number and datasheet, not the abbreviated product name.

## 6. Shortest tuning sequence

1. Verify the manufactured copper outer envelope is 50.0mm and fit ZS1=0R with ZP1/ZP2 DNP; populate J7 for the VNA.
2. Confirm that the receive path after C53 is open. C53 may remain populated when the downstream parts are absent; otherwise isolate the path.
3. Measure at J7 first out of the case and then in the complete production enclosure, including the display, TF-card socket, battery and screws.
4. At 1090MHz record SWR and complex impedance and compare with the V4.0 baseline above. Do not trim or populate the historical HFSS parts merely to deepen one dip.
5. Only if a changed enclosure/material causes a repeatable batch-level shift, retune in controlled 0.1–0.2mm steps and use the π network as needed.
6. Run an over-the-air A/B on 1090 message count, range and noise floor; VNA matching alone does not verify radiation efficiency.

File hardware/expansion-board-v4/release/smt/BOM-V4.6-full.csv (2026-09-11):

Comment | Description | Designator | Footprint | LibRef | Pins | Quantity | 编号
100nF 50V X7R ±10% | 去耦 | C10,C11,C12,C13,C14,C16,C17,C22,C23,C24,C25,C26,C27,C49,C61,C62,C63,C64,C65,C82,C83,C85,C86,C94,C95,C96,C98 | 0603 |  |  |  | C14663
10kΩ ±1% 100mW | 贴片电阻 | R1,R5,R6,R17,R18,R26,R27,R32,R34,R35,R44,R45,R46,R47,R51,R55,R56,R58,R59 | 0603
100pF 50V C0G ±5% | 隔直/旁路 / 射频-耦合/旁路 | C21,C30,C31,C32,C33,C34,C35,C36,C38,C39,C45,C53,C54,C57,C58,C59 | 0402 |  |  |  | C1546
1uF 25V X7R ±10% | 贴片电容 | C2,C3,C4,C6,C28,C29,C67,C78,C79,C84,C97 | 0603
10uF 25V X5R ±10% | 贴片电容 | C1,C18,C73,C74,C75,C91,C92,C93 | 0805
0Ω 跳线电阻 1/10W | 贴片电阻 | R21,R22,R23,R37,R48,R49,R60 | 0603
IPEX1 板端内针 50Ω 6GHz | U.FL 座 | J2,J5,J6,J7,J8,J10 | SMD |  |  |  | C41432122
ESD 3.3V Cj 0.3pF typ | 低电容ESD | D2,D3,D4,D5,D6 | 0402 |  |  |  | C2830293
自恢复保险丝 6V 200mA | 自恢复保险丝 | F2,F3,F4,F5 | 0805 |  |  |  | C516070
AO3401A | PMOS 高边开关 | Q2,Q3,Q4,Q5 | SOT-23 |  |  |  | C15127
100nH | 射频-偏置扼流 | L8,L14,L18 | 0402 |  |  |  | C18221115
18pF 50V C0G ±5% | 晶振负载 | C68,C69,C89 | 0603 |  |  |  | C1647
100pF 50V C0G ±5% | 贴片电容 | C55,C56,C88 | 0603
1kΩ ±1% 100mW | 贴片电阻 | R4,R31,R43 | 0603
6.8nH | 射频-978匹配 | L11,L12 | 0402 |  |  |  | C82919
4.7uF 16V X5R ±10% | 磁力计储能 / 电源-REGN储能 | C15,C71 | 0603 |  |  |  | C19666
射频开关 SPDT 20MHz~4GHz | 射频开关 | U16,U17 | SOT-363 |  |  |  | C513494
1uF 16V X5R ±10% | 贴片电容 | C5,C48 | 0402
4.7kΩ ±1% 100mW | 贴片电阻 | R2,R3 | 0603
10k | 电阻 | R52,R53 | 0402 |  |  |  | C25744
7.5nH | 射频-978匹配 | L9,L13 | 0402 |  |  |  | C82918
100nF 25V X7R ±10% | 贴片电容 | C37,C52 | 0402
27Ω ±1% 100mW | 贴片电阻 | R9,R10 | 0603
3.6pF | 射频-978匹配 | C40,C44 | 0402 |  |  |  | C5552081
15pF 50V C0G ±5% | 晶振负载 | C19,C20 | 0603 |  |  |  | C1644
33nH | 射频-偏置扼流 | L2,L15 | 0402 |  |  |  | C6807986
3pF 50V C0G ±0.25pF | 贴片电容 | C46 | 0603
2.7pF | 射频-978匹配 | C41 | 0402 |  |  |  | C1561
33R | 源端阻尼 | R57 | 0603 |  |  |  | C23140
47nF 50V X7R ±10% | 贴片电容 | C70 | 0603
22uF 25V X5R ±10% | 贴片电容 | C76 | 1206
1nF 50V X7R ±10% | 贴片电容 | C51 | 0603
32.768kHz FC-135 无源晶振 | 无源晶振 2脚 | Y3 | SMD3215-2P |  |  |  | C32346
180Ω ±1% 100mW | 贴片电阻 | R38 | 0603
0Ω 跳线电阻 1/10W | 贴片电阻 | ZS1 | 0603
470kΩ ±1% 100mW | 贴片电阻 | R41 | 0603
6.2pF | 射频-978匹配 | C42 | 0402 |  |  |  | C41744
52.3Ω ±1% 62.5mW | 射频-端接 | R19 | 0402 |  |  |  | C273696
100kΩ ±1% 100mW | 贴片电阻 | R33 | 0603
30k | USB VBUS分压 | R50 | 0603 |  |  |  | C22984
3pF | 射频-检波耦合 | C43 | 0402 |  |  |  | C696883
1uF 25V | PD输入储能 | C80 | 0603 |  |  |  | C15849
150kΩ ±1% 100mW | 贴片电阻 | R42 | 0603
200pF 50V C0G ±5% | 贴片电容 | C47 | 0603
48MHz ABM8W-7pF 无源晶振 | 无源晶振 4脚 | Y2 | SMD3225-4P |  |  |  | C6732653
5.62kΩ ±1% 100mW | 贴片电阻 | R39 | 0603
PCM1808PWR | 音频ADC | U22 | other |  |  |  | C55513
27nH | 射频-978匹配 | L10 | 0402 |  |  |  | C113111
10R | 检波器电源RC | R54 | 0402 |  |  |  | C25077
31.6kΩ ±1% 100mW | 贴片电阻 | R40 | 0603

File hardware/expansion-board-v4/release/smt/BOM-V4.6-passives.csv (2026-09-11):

Comment | Description | Designator | Footprint | LibRef | Pins | Quantity | 编号
100nF 50V X7R ±10% | 贴片电容 | C10,C11,C12,C13,C14,C16,C17,C22,C23,C24,C25,C26,C27,C49,C61,C62,C63,C64,C65,C82,C83,C85,C86,C94,C95,C96,C98 | 0603
10kΩ ±1% 100mW | 贴片电阻 | R1,R5,R6,R17,R18,R26,R27,R32,R34,R35,R44,R45,R46,R47,R51,R55,R56,R58,R59 | 0603
1uF 25V X7R ±10% | 贴片电容 | C2,C3,C4,C6,C28,C29,C67,C78,C79,C84,C97 | 0603
100pF 50V C0G ±5% | 贴片电容 | C21,C30,C36,C38,C39,C45,C54 | 0402
1kΩ ±1% 100mW | 贴片电阻 | R4,R31,R43 | 0603
1uF 16V X5R ±10% | 贴片电容 | C5,C48 | 0402
4.7kΩ ±1% 100mW | 贴片电阻 | R2,R3 | 0603
100nF 25V X7R ±10% | 贴片电容 | C37,C52 | 0402
27Ω ±1% 100mW | 贴片电阻 | R9,R10 | 0603
4.7uF 16V X5R ±10% | 贴片电容 | C15 | 0603
47nF 50V X7R ±10% | 贴片电容 | C70 | 0603
1nF 50V X7R ±10% | 贴片电容 | C51 | 0603
180Ω ±1% 100mW | 贴片电阻 | R38 | 0603
470kΩ ±1% 100mW | 贴片电阻 | R41 | 0603
100kΩ ±1% 100mW | 贴片电阻 | R33 | 0603
150kΩ ±1% 100mW | 贴片电阻 | R42 | 0603
200pF 50V C0G ±5% | 贴片电容 | C47 | 0603
5.62kΩ ±1% 100mW | 贴片电阻 | R39 | 0603
31.6kΩ ±1% 100mW | 贴片电阻 | R40 | 0603

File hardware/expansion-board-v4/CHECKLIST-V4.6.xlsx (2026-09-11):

贴 | 位号 | 值 / 型号 | 封装 | 位置 (x, y) | 阶段 | 备注
 | C1 | 10uF | C_0805_2012Metric | 70.8, 96.5 | A 电源
 | C2 | 1uF | C_0603_1608Metric | 85.9, 99.1 | A 电源
 | C3 | 1uF | C_0603_1608Metric | 70.8, 98.9 | A 电源
 | C4 | 1uF | C_0603_1608Metric | 78.7, 97.8 | A 电源
 | C5 | 1uF | C_0402_1005Metric | 85.9, 96.7 | A 电源
 | C6 | 1uF | C_0603_1608Metric | 92.1, 97.9 | A 电源
 | C10 | 100nF | C_0603_1608Metric | 61.0, 92.6 | C 传感器 + GNSS
 | C11 | 100nF | C_0603_1608Metric | 64.6, 87.2 | C 传感器 + GNSS
 | C12 | 100nF | C_0603_1608Metric | 56.5, 87.7 | C 传感器 + GNSS
 | C13 | 100nF | C_0603_1608Metric | 59.1, 92.6 | C 传感器 + GNSS
 | C14 | 100nF | C_0603_1608Metric | 64.6, 89.9 | C 传感器 + GNSS
 | C15 | 4.7uF | C_0603_1608Metric | 59.9, 99.3 | C 传感器 + GNSS
 | C16 | 100nF | C_0603_1608Metric | 64.6, 92.5 | C 传感器 + GNSS
 | C17 | 100nF | C_0603_1608Metric | 71.4, 81.0 | C 传感器 + GNSS
 | C18 | 10uF | C_0805_2012Metric | 74.4, 80.8 | C 传感器 + GNSS
 | C19 | 15pF C0G | C_0603_1608Metric | 88.4, 69.1 | B MCU + Flash
 | C20 | 15pF C0G | C_0603_1608Metric | 79.8, 69.1 | B MCU + Flash
 | C21 | 100pF | C_0402_1005Metric | 103.6, 59.7 | E 1090 接收链
 | C22 | 100nF | C_0603_1608Metric | 93.2, 75.8 | B MCU + Flash
 | C23 | 100nF | C_0603_1608Metric | 91.8, 81.5 | B MCU + Flash
 | C24 | 100nF | C_0603_1608Metric | 80.9, 80.2 | B MCU + Flash
 | C25 | 100nF | C_0603_1608Metric | 83.2, 71.6 | B MCU + Flash
 | C26 | 100nF | C_0603_1608Metric | 78.9, 74.6 | B MCU + Flash
 | C27 | 100nF | C_0603_1608Metric | 77.9, 82.5 | B MCU + Flash
 | C28 | 1uF | C_0603_1608Metric | 83.1, 83.3 | B MCU + Flash
 | C29 | 1uF | C_0603_1608Metric | 80.9, 83.3 | B MCU + Flash
 | C30 | 100pF | C_0402_1005Metric | 102.8, 67.5 | E 1090 接收链
 | C31 | 100pF C0G | C_0402_1005Metric | 111.3, 62.2 | E 1090 接收链
 | C32 | 100pF C0G | C_0402_1005Metric | 114.3, 62.2 | E 1090 接收链
 | C33 | 100pF C0G | C_0402_1005Metric | 120.4, 63.2 | E 1090 接收链
 | C34 | 100pF C0G | C_0402_1005Metric | 117.1, 73.4 | E 1090 接收链
 | C35 | 100pF C0G | C_0402_1005Metric | 115.1, 71.1 | E 1090 接收链
 | C36 | 100pF | C_0402_1005Metric | 106.0, 64.3 | E 1090 接收链
 | C37 | 100nF | C_0402_1005Metric | 113.9, 77.0 | E 1090 接收链
 | C38 | 100pF | C_0402_1005Metric | 111.6, 77.0 | E 1090 接收链
 | C39 | 100pF | C_0402_1005Metric | 118.2, 92.8 | D 978 收发
 | C40 | 3.6pF | C_0402_1005Metric | 110.7, 94.2 | D 978 收发
 | C41 | 2.7pF | C_0402_1005Metric | 115.9, 97.5 | D 978 收发
 | C42 | 6.2pF | C_0402_1005Metric | 115.9, 95.2 | D 978 收发
 | C43 | 3pF | C_0402_1005Metric | 115.9, 92.8 | D 978 收发
 | C44 | 3.6pF | C_0402_1005Metric | 112.8, 96.5 | D 978 收发
 | C45 | 100pF | C_0402_1005Metric | 110.7, 90.2 | D 978 收发
 | C46 | 3pF | C_0603_1608Metric | 104.9, 78.5 | E 1090 接收链
 | C47 | 200pF | C_0603_1608Metric | 104.9, 80.4 | E 1090 接收链
 | C48 | 1uF | C_0402_1005Metric | 107.4, 64.3 | E 1090 接收链
 | C49 | 100nF | C_0603_1608Metric | 76.7, 75.4 | E 1090 接收链
 | C51 | 1nF | C_0603_1608Metric | 77.0, 81.0 | E 1090 接收链
 | C52 | 100nF | C_0402_1005Metric | 99.6, 82.3 | E 1090 接收链
 | C53 | 100pF | C_0402_1005Metric | 93.6, 62.9 | E 1090 接收链 | J7测IFA要求后级断路；U17等未贴时C53可保留
 | C54 | 100pF | C_0402_1005Metric | 103.9, 61.7 | E 1090 接收链
 | C55 | 100pF | C_0603_1608Metric | 97.6, 66.5 | E 1090 接收链
 | C56 | 100pF | C_0603_1608Metric | 95.0, 66.5 | E 1090 接收链
 | C57 | 100pF | C_0402_1005Metric | 68.3, 81.0 | C 传感器 + GNSS
 | C58 | 100pF | C_0402_1005Metric | 57.7, 76.5 | C 传感器 + GNSS
 | C59 | 100pF | C_0402_1005Metric | 57.6, 69.8 | C 传感器 + GNSS
 | C60 | 22uF | C_0805_2012Metric | 99.3, 98.0 | D 978 收发
 | C61 | 100nF | C_0603_1608Metric | 102.7, 99.1 | D 978 收发
 | C62 | 100nF | C_0603_1608Metric | 105.4, 98.3 | D 978 收发
 | C63 | 100nF | C_0603_1608Metric | 107.1, 84.6 | D 978 收发
 | C64 | 100nF | C_0603_1608Metric | 100.2, 85.8 | D 978 收发
 | C65 | 100nF | C_0603_1608Metric | 99.0, 94.7 | D 978 收发
 | C66 | 22uF | C_0805_2012Metric | 102.9, 97.2 | D 978 收发
 | C67 | 1uF | C_0603_1608Metric | 103.6, 85.8 | D 978 收发
 | C68 | 18pF | C_0603_1608Metric | 113.2, 85.0 | D 978 收发
 | C69 | 18pF | C_0603_1608Metric | 110.1, 85.0 | D 978 收发
 | C70 | 47nF | C_0603_1608Metric | 135.7, 80.2 | A 电源
 | C71 | 4.7uF(带电源版) | C_0603_1608Metric | 133.4, 79.0 | A 电源
 | C72 | 10uF | C_1206_3216Metric | 130.9, 79.2 | A 电源
 | C73 | 10uF | C_0805_2012Metric | 141.3, 88.1 | A 电源
 | C74 | 10uF | C_0805_2012Metric | 143.3, 84.9 | A 电源
 | C75 | 10uF | C_0805_2012Metric | 139.1, 88.1 | A 电源
 | C76 | 22uF | C_1206_3216Metric | 134.4, 96.3 | A 电源
 | C77 | 22uF 16V X5R | C_1206_3216Metric | 141.2, 99.7 | A 电源
 | C78 | 1uF | C_0603_1608Metric | 134.4, 94.2 | A 电源
 | C79 | 1uF | C_0603_1608Metric | 130.6, 65.0 | A 电源
 | C80 | 1uF 25V | C_0603_1608Metric | 136.3, 74.6 | A 电源
 | C81 | 470pF C0G | C_0402_1005Metric | 115.2, 64.5 | E 1090 接收链
 | C82 | 100nF | C_0603_1608Metric | 91.4, 67.5 | B MCU + Flash
 | C83 | 100nF | C_0603_1608Metric | 91.4, 69.8 | B MCU + Flash
 | C84 | 1uF | C_0603_1608Metric | 110.7, 80.5 | B MCU + Flash
 | C85 | 100nF | C_0603_1608Metric | 113.7, 80.5 | B MCU + Flash
 | C86 | 100nF | C_0603_1608Metric | 121.4, 88.1 | B MCU + Flash
 | C87 | 10nF C0G | C_0603_1608Metric | 83.5, 88.5 | B MCU + Flash
 | C88 | 100pF | C_0603_1608Metric | 129.3, 91.1 | G 航空波段 AIRBAND
 | C89 | 18pF | C_0603_1608Metric | 128.7, 93.9 | G 航空波段 AIRBAND
 | C91 | 10uF | C_0805_2012Metric | 129.0, 108.2 | G 航空波段 AIRBAND
 | C92 | 10uF | C_0805_2012Metric | 136.2, 108.2 | G 航空波段 AIRBAND
 | C93 | 10uF | C_0805_2012Metric | 124.2, 109.4 | G 航空波段 AIRBAND
 | C94 | 100nF | C_0603_1608Metric | 120.5, 109.4 | G 航空波段 AIRBAND
 | C95 | 100nF | C_0603_1608Metric | 120.5, 101.5 | G 航空波段 AIRBAND
 | C96 | 100nF | C_0603_1608Metric | 127.6, 102.2 | G 航空波段 AIRBAND
 | C97 | 1uF | C_0603_1608Metric | 129.4, 102.2 | G 航空波段 AIRBAND
 | C98 | 100nF | C_0603_1608Metric | 131.2, 102.2 | G 航空波段 AIRBAND
 | R1 | 10k | R_0603_1608Metric | 55.2, 84.5 | C 传感器 + GNSS
 | R2 | 4.7k | R_0603_1608Metric | 64.1, 97.8 | C 传感器 + GNSS
 | R3 | 4.7k | R_0603_1608Metric | 64.1, 95.2 | C 传感器 + GNSS
 | R4 | 1k | R_0603_1608Metric | 82.0, 69.1 | B MCU + Flash
 | R5 | 10k | R_0603_1608Metric | 80.0, 73.2 | B MCU + Flash
 | R6 | 10k | R_0603_1608Metric | 87.9, 86.4 | B MCU + Flash
 | R7 | 5.1k DNP(带电源版) | R_0603_1608Metric | 145.6, 64.8 | 不贴（DNP）
 | R8 | 5.1k DNP(带电源版) | R_0603_1608Metric | 143.6, 64.8 | 不贴（DNP）
 | R9 | 27R | R_0603_1608Metric | 87.9, 83.3 | B MCU + Flash
 | R10 | 27R | R_0603_1608Metric | 85.3, 83.3 | B MCU + Flash
 | R11 | 3.32k | R_0402_1005Metric | 105.1, 59.7 | E 1090 接收链
 | R17 | 10k | R_0603_1608Metric | 121.8, 98.7 | D 978 收发
 | R18 | 10k | R_0603_1608Metric | 91.4, 71.4 | E 1090 接收链
 | R19 | 52.3R | R_0402_1005Metric | 115.1, 73.4 | E 1090 接收链
 | R21 | 0R | R_0603_1608Metric | 105.0, 72.6 | E 1090 接收链
 | R22 | 0R | R_0603_1608Metric | 100.3, 66.5 | E 1090 接收链
 | R23 | 0R | R_0603_1608Metric | 93.2, 77.2 | E 1090 接收链
 | R24 | 0R DNP(旁路外接) | R_0402_1005Metric | 101.1, 63.1 | 不贴（DNP）
 | R25 | 0R DNP(旁路板载) | R_0402_1005Metric | 95.5, 62.9 | 不贴（DNP）
 | R26 | 10k | R_0603_1608Metric | 67.3, 73.7 | C 传感器 + GNSS
 | R27 | 10k | R_0603_1608Metric | 67.3, 71.1 | C 传感器 + GNSS
 | R30 | 1k DNP | R_0402_1005Metric | 96.8, 77.2 | 不贴（DNP）
 | R31 | 1k | R_0603_1608Metric | 101.6, 75.7 | E 1090 接收链
 | R32 | 10k | R_0603_1608Metric | 104.9, 75.7 | E 1090 接收链
 | R33 | 100k | R_0603_1608Metric | 100.9, 82.7 | E 1090 接收链
 | R34 | 10k | R_0603_1608Metric | 77.0, 73.2 | E 1090 接收链
 | R35 | 10k | R_0603_1608Metric | 77.0, 78.4 | E 1090 接收链
 | R36 | 1k DNP | R_0603_1608Metric | 96.5, 81.8 | 不贴（DNP）
 | R37 | 0R | R_0603_1608Metric | 137.0, 66.4 | A 电源
 | R38 | 180R | R_0603_1608Metric | 133.1, 88.2 | A 电源
 | R39 | 5.62k | R_0603_1608Metric | 136.2, 88.2 | A 电源
 | R40 | 31.6k | R_0603_1608Metric | 134.6, 88.2 | A 电源
 | R41 | 470k | R_0603_1608Metric | 139.1, 98.6 | A 电源
 | R42 | 150k | R_0603_1608Metric | 137.4, 98.6 | A 电源
 | R43 | 1k | R_0603_1608Metric | 127.5, 65.0 | A 电源
 | R44 | 10k | R_0603_1608Metric | 137.0, 69.5 | A 电源
 | R45 | 10k | R_0603_1608Metric | 129.2, 84.0 | A 电源
 | R46 | 10k | R_0603_1608Metric | 129.2, 86.5 | A 电源
 | R47 | 10k | R_0603_1608Metric | 98.5, 91.7 | D 978 收发
 | R48 | 0R | R_0603_1608Metric | 126.8, 67.0 | A 电源
 | R49 | 0R | R_0603_1608Metric | 126.8, 69.4 | A 电源
 | R50 | 30k | R_0603_1608Metric | 86.5, 92.8 | B MCU + Flash
 | R51 | 10k | R_0603_1608Metric | 85.5, 88.5 | B MCU + Flash
 | R52 | 10k | R_0402_1005Metric | 64.4, 85.0 | C 传感器 + GNSS
 | R53 | 10k | R_0402_1005Metric | 64.3, 83.0 | C 传感器 + GNSS
 | R54 | 10R | R_0402_1005Metric | 116.5, 77.0 | E 1090 接收链
 | R55 | 10k | R_0603_1608Metric | 57.4, 89.8 | C 传感器 + GNSS
 | R56 | 10k | R_0603_1608Metric | 98.5, 90.0 | D 978 收发
 | R57 | 33R | R_0603_1608Metric | 104.0, 82.5 | E 1090 接收链
 | R58 | 10k | R_0603_1608Metric | 132.5, 108.2 | G 航空波段 AIRBAND
 | R59 | 10k | R_0603_1608Metric | 132.5, 105.6 | G 航空波段 AIRBAND
 | R60 | 0R | R_0603_1608Metric | 124.0, 101.5 | G 航空波段 AIRBAND
 | L1 | 18nH 0402CS-18NXGRW | L_0402_1005Metric | 110.4, 59.8 | E 1090 接收链
 | L2 | 33nH | L_0402_1005Metric | 57.7, 75.4 | C 传感器 + GNSS
 | L7 | 6.8uH | L_0805_2012Metric | 97.3, 94.7 | D 978 收发
 | L8 | 100nH | L_0402_1005Metric | 119.3, 90.3 | D 978 收发
 | L9 | 7.5nH | L_0402_1005Metric | 112.3, 94.8 | D 978 收发
 | L10 | 27nH | L_0402_1005Metric | 110.9, 95.7 | D 978 收发
 | L11 | 6.8nH | L_0402_1005Metric | 118.2, 97.5 | D 978 收发
 | L12 | 6.8nH | L_0402_1005Metric | 118.2, 95.2 | D 978 收发
 | L13 | 7.5nH | L_0402_1005Metric | 110.7, 92.2 | D 978 收发
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

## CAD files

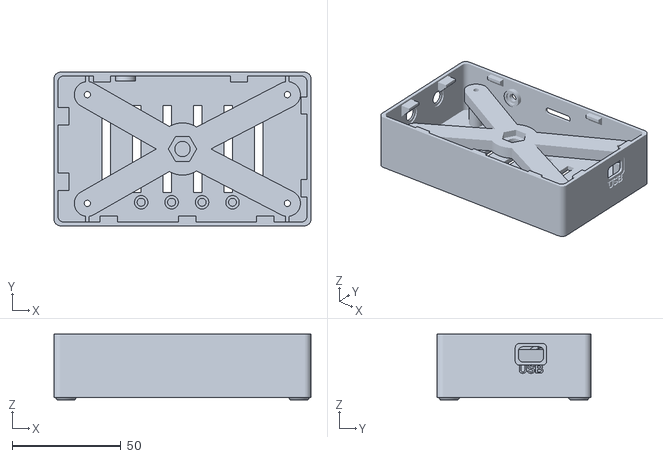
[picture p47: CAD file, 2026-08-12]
docs/jlc/lcd-4.3in/3d-case/pilot-kit-box-43-base_v2.stl
118.2 x 70.7 x 30.4

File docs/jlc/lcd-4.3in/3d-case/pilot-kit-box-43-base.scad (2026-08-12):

// =============================================================
// Pilot Kit Box — 4.3" 触摸屏版 3D 打印底座（盒体）v2
// =============================================================
// 结构：单件薄壁盒体，全部自顶部装配（无底盖）。
//
// 紧固链（自下而上，底座不埋螺母）：
//   M2.5 螺丝从底面沉孔穿入 → 打印套筒柱（φ2.9 通孔）
//   → 扩展板安装孔 → 跨过 HAT 对接造成的悬空段（stack_h−铜柱长）
//   → 锁进挂在微雪板下的 3.8 铜柱。
//   堆叠实测：微雪板 → HAT母3.5+HAT公3.5（板间距 7.0）→ 扩展板；
//   铜柱 3.8 悬空 3.2。建议螺丝上套 3.2 隔套（或换 7mm 铜柱）再锁紧，
//   否则拧紧力矩会压在 HAT 排针上。
//
// 减料设计：
//   - 内腔按【玻璃轮廓】而非 PCB 轮廓，四周到板边 ≥3.8mm，
//     SD 卡座 / SMA 线柱等板边突出物不会顶墙
//   - 玻璃仅靠周圈薄支撑舌托住（螺丝已锁死整叠，只需扣住）
//   - 底板条栅镂空，侧壁 1.8；开孔处仅外沉 0.5、余厚 1.3
//
// 打印提示：底面 4 个外凸脚（免贴胶），意味着底面悬空 foot_h，
//   切片开「仅打印板支撑」或接受底面轻微垂丝（朝下不可见）。
//   沉孔配盘头/沉头 M2.5（圆柱头太高会露出底面）。
//
// 坐标系（俯视，屏朝上，原点 = 屏板 X-/Y- 角）：
//   X+ = USB 壁（H1 Type-C，玻璃悬出 3.7）
//   X- = SMA 壁（无板载元件，玻璃悬出 8.2，内侧留 8.6 给螺母/线柱）
//   Y+ = SD 卡槽 + RESET/BOOT/POWER 按键壁
//   Y- = 40PIN 边（不开孔）
//
// 尺寸来源：
//   - 微雪 dimensions.pdf（20260411）：玻璃 114.4×66.8，
//     PCB 102.5×60，孔距 92×50 M2.5，厚 11.15（玻璃 1.6/板下净空 4）
//   - 扩展板 docs/jlc/lcd-4.3in/pcb（实读）：100×60，
//     4 孔 φ2.6 @ (4,5)/(96,5)/(4,55)/(96,55)，孔距同 92×50
//
// 实测记录（2026-07-31 卡尺，一切以玻璃为基准）：
//   - H1：座顶距玻璃顶边 20 / 座底距底边 37 → 中心 y=38.5 ✓与推导吻合
//   - SD：右缘距玻璃右(H1侧) 45 / 左缘距左 53 → 中心=玻璃左+61.2，深 9.0
//   - POWER：中心距玻璃左 31，深 8.5；BOOT +39 / RESET +47
//   - 悬出方向实测定性确认：USB 侧小、C6 侧大（量值保持图纸链
//     3.7/8.2/3.4，总和闭合 114.4/66.8；卡尺读数 2/7/2 疑似量到
//     显示模组边框，每边系统性少 ~1.4）
//   （深度=玻璃外表面到器件中心）
// ⚠ 仍待实测：
//   1. glass_ov_xm/xp —— 玻璃悬出方向。一个量法定乾坤：H1 座端面
//      距玻璃右边缘的缩进 ≈2.4 → 当前假设对；≈6.9 → 对调两参数
//   2. stack_h —— 两板对插实际间距（= 铜柱长度）
//   3. sma_y / sma_z —— 面板 SMA 孔位（自定）
// =============================================================

/* ---------- 输出选择 ---------- */
part = "print";       // "print" 盒体+按键销连筋一体（下单用这个）
                      // "box" 仅盒体 / "plungers" 仅按键销 / "section" X 剖面
align_origin = true;  // true = 输出平移到包围盒角点(0,0,0)，方便量尺；
                      // 内部坐标系不变（原点=屏板 X-/Y- 角）

/* ---------- 打印公差 ---------- */
fit_glass = 0.10;     // 玻璃四周单边间隙。9600 树脂实测：模型 115.2x67.68
                      // 印出 115.4~115.6 x 67.6~67.9，即 X 向偏大 0.2~0.4、
                      // Y 向 -0.08~+0.22。取 0.1 是让最坏一档(Y 偏小 0.08)
                      // 仍有 0.12 总间隙；取 0 会装不进去。
$fn = 64;

/* ---------- 屏组件（微雪板）---------- */
glass_l = 114.4;  glass_w = 66.88; glass_t = 1.0;  glass_r = 2.5;  // 玻璃实测 114.4×66.88，厚+背胶 1.0
scr_pcb_l = 102.5;  scr_pcb_w = 60.0;  scr_pcb_t = 1.6;
scr_under = 4.0;                       // 屏板下方元件净空
scr_glass_gap = 11.15 - glass_t - scr_pcb_t - scr_under;  // 3.95
glass_ov_xm = 8.2;    // 玻璃悬出：X-（非 USB 侧）
glass_ov_xp = 3.7;    // 玻璃悬出：X+（USB 侧）
glass_ov_y  = (glass_w - scr_pcb_w) / 2;                  // 3.4
// 方位约定（面朝屏幕，PCB 在后）：左=C6 侧(X-)，右=USB H1/H2 侧(X+)，
// 顶=SD/按键边(Y+)。开孔位一律以玻璃边缘实测值标注。
glass_left = -glass_ov_xm;     // 玻璃左边缘 x（内部坐标）
glass_bot  = -glass_ov_y;      // 玻璃下(40PIN)边缘 y

/* ---------- 扩展板 ---------- */
exp_t = 1.6;
hole_dx = 92;  hole_dy = 50;           // 安装孔距（两板一致）

/* ---------- 高度链（自内底面起）---------- */
floor_t = 2.4;        // 底板厚（含沉孔）
bat_h   = 11.0;       // 电池仓净高 = 套筒柱高（电池 9.5 + 余量 1.5，首装宽松）
stack_h    = 7.0;     // 实测：HAT 母 3.5 + HAT 公 3.5 对接 = 板间距 7.0
pillar_len = 3.8;     // 挂在微雪板下的铜柱长；悬空 = stack_h - pillar_len = 3.2

/* ---------- 壁与柱 ---------- */
wall_t     = 1.8;
boss_d     = 7.0;
screw_d    = 2.9;     // M2.5 通孔
cb_d       = 5.6;     // 底面沉孔（圆柱头/盘头）
cb_depth   = 1.4;
corner_r   = 3.0;
slot_r     = 2.0;     // 开孔圆角上限（原自动取 min(w,h)/2，孔成胶囊形）

lbl_pwr  = "PWR";
lbl_sd   = "SD";
lbl_usb  = "USB";     // H1 = USB TO UART；想标 UART 改这里
lbl_sma  = ["GPS", "ADS-B"];   // 对应 sma_y 的两个孔，顺序可对调

/* ---------- 玻璃支撑舌 ---------- */
tab_w = 8;            // 舌宽
tab_t = 1.5;          // 舌厚（垂直方向）
tab_p = 2.8;          // 自内壁面伸出量
tab_p_left = 5.0;     // 左(C6)侧加深：该侧玻璃悬出最大，多托一点

/* ---------- 电池 ----------
   955465 软包（65×54×9.5）自由平放，上被扩展板压住、周围是柱子，
   不做定位挡墙。注意躲开扩展板底面 x≥76 的 SDR 悬垂区。 */

/* ---------- USB H1（X+ 壁）---------- */
h1_y     = glass_bot + 41.25;  // 量尺 y=43.20（距玻璃下边 41.25）
usb_w    = 11.5;  usb_h = 7.0; // 直插穿墙孔：公头包胶(宽11)整体穿入，
                               // 实测插满时包胶面与玻璃边平齐，故不做外沉槽
usb_glass_d = 9.35;            // 量尺 z=19.80
usb_rec  = [14.5, 10];         // 外侧圆角浅沉槽：四周统一 1.5 边框
usb_zoff = glass_t + scr_glass_gap + scr_pcb_t - usb_glass_d;  // -2.35
rec_depth = 0.5;               // SD 外沉深度（1.8 壁余厚 1.3）

/* ---------- 按键（Y+ 壁）：只开 POWER ---------- */
// 实测：中心=玻璃左+31(POWER) / +39(BOOT) / +47(RESET)
btn_power_x = glass_left + 31;     // 22.8，离 SD 最远
btns        = [btn_power_x];       // 需要 RESET 时加 glass_left+47
btn_d       = 4.1;                 // 导孔（配打印按压销）
btn_glass_d = 8.85;                // 量尺 z=20.30
btn_rec_d   = 8.0;                 // 外侧圆形浅凹（深 rec_depth）
btn_zoff    = glass_t + scr_glass_gap + scr_pcb_t - btn_glass_d;
btn_key_depth = 3.2;               // 键帽面到玻璃边缘。两次实测标定：
                                   // ① 旧件销尾静止凸 1.95/触发 1.51 → 行程 0.44
                                   // ② 旧件销总长 7.80 预压按键，削到 7.65 正常
                                   // 回代旧几何（法兰止位 64.84）得键帽 y≈60.25，
                                   // 即距玻璃边 3.2。原假设 4.0 偏深 0.8。
// 防倾斜：原来导向孔只剩 0.8mm（壁 1.8 减去 1.0 深沉窝），销子能歪 26°。
// 改为内壁加一段导向套，导向长度 = wall_t + btn_bore_in，法兰退到套内沉腔止位。
btn_boss_d  = 9.0;                 // 导向套外径（沉腔 6.6 外留 1.2 壁厚）
btn_guide   = 2.3;                 // 导向套自内壁面伸入长度（末端离键帽 1.1）
btn_bore_in = 0.95;                // 其中做导向孔的前段（其余为法兰沉腔）
btn_pkt_d   = 6.6;                 // 法兰沉腔直径（法兰 6.2，留 0.4 活动量）
pl_shaft_d  = 3.7;                 // 按压销杆径
pl_flange_d = 6.2;  pl_flange_t = 1.0;
pl_nose     = 1.0;                 // 顶鼻：够长才不会按到底时法兰撞屏板边缘
pl_proud    = 1.2;                 // 静止时销尾高出外壁量（原 2.0 太凸）
n_plungers  = 4;                   // 一体打印的按键销数量（1 用 2 备）

/* ---------- SD 卡槽（Y+ 壁）---------- */
sd_cx    = glass_left + 59;    // 50.8。实测：卡座中心=玻璃左+59
sd_w     = 16.0;  sd_h = 3.5;
sd_glass_d = 9.35;             // 量尺 z=19.80
sd_zoff  = glass_t + scr_glass_gap + scr_pcb_t - sd_glass_d;      // -1.85
sd_rec   = [22, 8];            // 外侧圆角沉槽（深 rec_depth）
sd_notch = 10;                 // 指甲槽宽（圆角，贯穿余壁）

/* ---------- SMA ×2（X- 壁，面板式穿墙）---------- */
sma_y = [19, 41];     // 两孔中心 y
sma_z = 19;           // 孔中心高（自内部坐标系底面；盒子变矮后下调留口沿余量）
sma_d = 6.4;          // 面板 SMA 螺纹穿孔
sma_cb_d = 9.5;  sma_cb_dp = 0.6;   // 内侧沉窝：留平面好上螺母
sma_rec_d = 9.45; sma_rec_dp = 0.5;  // 外侧圆凹：卡垫片（深度按垫片厚度调）

/* ---------- 1/4"-20 云台转接板（外挂盒底，与 4 颗底部螺丝共用）----------
   载荷路径：云台螺柱自板底旋入 → 螺母坐在板内六角腔 → 腔底实体承拉。
   螺母腔开口朝上，装到盒底后被盒体外底面封住，螺母跑不掉。
   打印时用断颈筋悬在盒内，一个文件一个价；装配前掰下来。 */
mount_plate = true;
mp_t        = 6.0;    // 板厚
mp_nut_af   = 11.3;   // 1/4-20 螺母对边（标准 11.11 + 0.2 装配间隙）
mp_nut_t    = 3.4;    // 螺母腔深：配 3.2 薄螺母。换 5.56 标准螺母则改 5.8，
                      // 同时 mp_t 加到 8.5、螺丝加长 2.5
mp_stud_d   = 7.0;    // 云台螺柱过孔（φ6.35 + 间隙）
mp_arm_w    = 12;     // 臂宽
mp_pad_d    = 12;     // 螺丝端圆盘直径
mp_hub_d    = 24;     // 中央凸台直径
mp_cb_d     = 5.6;  mp_cb_dp = 1.4;   // 板底沉孔（容螺丝头）
mp_z        = 16;     // 打印时悬在盒内的高度
mp_tab      = 1.6;    // 断颈连接筋截面（斜口钳剪断）

/* ---------- 底面 ---------- */
foot_d = 8;  foot_h = 1.2;  foot_inset = 5.5;  // 外凸脚，高过螺丝头余量
lighten = true;       // 底板条栅镂空（6 条均布，兼顾透气与省料）
slat_w  = 4;
slat_xs = [14, 28, 42, 56, 70, 84];   // 关于板中心 x=51.25 大致对称
slat_y0 = 10;  slat_y1 = 50;

/* =============================================================
   派生尺寸（勿直接改）
   ============================================================= */
gx0 = -glass_ov_xm;             gx1 = scr_pcb_l + glass_ov_xp;
gy0 = -glass_ov_y;              gy1 = scr_pcb_w + glass_ov_y;

cav_x0 = gx0 - fit_glass;  cav_x1 = gx1 + fit_glass;   // 内腔=玻璃轮廓
cav_y0 = gy0 - fit_glass;  cav_y1 = gy1 + fit_glass;

box_x0 = cav_x0 - wall_t;  box_x1 = cav_x1 + wall_t;
box_y0 = cav_y0 - wall_t;  box_y1 = cav_y1 + wall_t;
box_l = box_x1 - box_x0;   box_w = box_y1 - box_y0;

z_exp_bot = floor_t + bat_h;
z_exp_top = z_exp_bot + exp_t;
z_scr_bot = z_exp_top + stack_h;          // 屏板底面
z_glass_b = z_scr_bot + scr_pcb_t + scr_glass_gap;
box_h     = z_glass_b + glass_t;          // 口沿与玻璃面齐平

hx0 = (scr_pcb_l - hole_dx) / 2;          // 5.25
hy0 = (scr_pcb_w - hole_dy) / 2;          // 5.0
boss_xy = [[hx0, hy0], [hx0 + hole_dx, hy0],
           [hx0, hy0 + hole_dy], [hx0 + hole_dx, hy0 + hole_dy]];

echo(str("盒体外形: ", box_l, " x ", box_w, " x ", box_h, " mm"));
echo(str("扩展板底面 z=", z_exp_bot, "  屏板底面 z=", z_scr_bot,
         "  玻璃底 z=", z_glass_b));
mp_cx = (box_x0 + box_x1) / 2;
mp_cy = (box_y0 + box_y1) / 2;
assert(mp_t - mp_nut_t >= 2.0, "转接板螺母腔下方肉太薄：加大 mp_t 或减小 mp_nut_t");
echo(str("云台板: ", mp_t, " 厚  1/4-20 螺母腔 对边", mp_nut_af, " 深", mp_nut_t,
         "  腔底承拉肉 ", mp_t - mp_nut_t,
         "  装板后总高 ", box_h + mp_t,
         "  螺丝需 ≈ ", mp_t - mp_cb_dp + floor_t + bat_h + exp_t
                        + (stack_h - pillar_len) + 3));
echo(str("螺丝参考长度 ≈ ",
         floor_t - cb_depth + bat_h + exp_t + (stack_h - pillar_len) + 3,
         " mm（含悬空 ", stack_h - pillar_len, " + 旋入铜柱 3）"));
assert(z_glass_b > z_scr_bot, "高度链错误");
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

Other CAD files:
docs/jlc/lcd-4.3in/3d-case/pilot-kit-box-43-base_v2.obj

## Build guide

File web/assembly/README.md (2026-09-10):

# 贴片助手

手工贴片时对着屏幕走：按料分组推进，当前位号在焊盘图上高亮，顶部显示这种料的
参数和还剩几个，空格标记已贴并跳下一个。

## 打开

页面要从 http 打开（浏览器会拦本地文件的跨源读取，直接双击 html 会看不到数据）：

```
cd <仓库根目录>
python3 -m http.server 8000
```

然后开 <http://localhost:8000/web/assembly/>。

## 操作

| 键 | 作用 |
|---|---|
| <kbd>空格</kbd> | 标记已贴 → 跳下一个 |
| <kbd>Enter</kbd> / <kbd>A</kbd> | **整组一键已贴**——这一种料剩下的全标上，然后跳下一组 |
| <kbd>Z</kbd> | 撤销上一次批量操作 |
| <kbd>←</kbd> / <kbd>Backspace</kbd> | 退回上一个，**同时取消它的已贴标记**（按错了才会退回） |
| <kbd>→</kbd> | 只往下走，不标记 |
| <kbd>S</kbd> | 跳过这个件（缺料时用），不计入已贴 |
| <kbd>F</kbd> | 翻面 |
| <kbd>0</kbd> | 复位视图 |
| <kbd>Tab</kbd> | 焊接表，逐个手动打勾／取消 |

## 整组一键已贴

一次用钢网刷完一种料、或者事后补记时用。三个入口：<kbd>Enter</kbd>、右侧
「整组已贴 N」按钮、焊接表每组组头的「整组打勾」。

**只标这一组里还没贴的**，标完弹一条绿色回执告诉你动了几个。
<kbd>Z</kbd> 撤销时也**只回滚这次标的那些**——之前手动勾过的不会被一起清掉。
一下标 23 个如果误触又回不去，代价太大，所以这条是硬要求。

鼠标滚轮缩放，拖拽平移，点板上的件或右侧位号可直接跳过去。
进度存在浏览器 localStorage 里，按版本分开，关掉再开还在。

顶部一行是**分类导航**（芯片／连接器／电感／电容／电阻…），每类带进度。
贴完电容直接点「电阻」，跳到那一类第一个还没贴的件，不用一路按空格穿过去。

## 换料卡

切到**新的一种料**时中间弹一次，告诉你去料盒拿什么：

```
        换 料
     10k   [0603]
     备料 17 颗
     C25804  电阻
```

只在换料时弹——每个位号都弹就成了噪音，而换料是唯一需要离开板子的时刻。
中途跳回贴过一半的组时按**还要贴几颗**算，不是组的总数，照总数备料会多拿。
按任意键立即消失（按键说明料已到手），否则 4.5 秒淡出；信息不会丢，
顶栏和板上 tips 一直显示着同样的内容。

## 介质

0402 的 100pF C0G 和 100pF X7R 外观完全一样，混在桌上分不回来，而 `C34`/`C35`
决定 1090MHz 检波输入高通、**必须锁 C0G/NP0**。所以介质单独做成粗体实底标签，
排在规格后面第一位，三档三色：

| | |
|---|---|
| <kbd>C0G</kbd> 青 | 含 NP0，统一显示成 C0G |
| <kbd>X7R</kbd> 蓝 | |
| <kbd>X5R</kbd> 紫 | |

介质取自 BOM 的**型号**字段，不是材质列——材质列是要求下限，型号才是实际配的料。
两者不同时会写一句「要求 X7R，配的是 C0G（向上兼容）」，因为两个介质代号并排
出现看着像数据打架。

## 一组 = 一盘料

分组键是**立创料号**，不是规格字符串。BOM 里同一个料号常按用途拆成好几行：

- `C1546` 拆成「100pF」（11 个隔直位）和「100pF C0G」（5 个射频位）→ 合成 16 个一组
- `C41432122` 那款 U.FL 座按 5 个射频口拆成 5 行 → 合成 1 组
- `C21189` 的 `ZS1` 在 PCB 上挂 `L_0603_1608Metric`（π 网络那位置可贴 0R 或电感），
  其余 0R 挂 `R_0603_1608Metric` → 同尺寸同料号，合成 7 个一组

合并后组标题只取公共前缀（`100pF`、`U.FL`），**每个位号自己的用途留在位号旁边**——
U.FL 那 5 个是不同天线口，接错就是接错天线。采购等级取最严的一档，
免得「必买指定」被合并成「已有」。

尺寸一致性用焊盘包络判断（≤1.5 倍），不用封装名——名字会因用途而不同。
把 0402 和 0603 合成一盘料是真错误，脚本和契约测试都会当场失败。

## 颜色

| | |
|---|---|
| 琥珀色 + 方框 | 当前要贴的件 |
| 蓝色 | 同一种料的其他位置（这种料还要贴哪几个） |
| 绿色 | 已贴 |
| 暗铜色 | 其他件 |
| 很淡 | 在另一面 |

B 面件会自动翻面并弹提示——不翻板照着正面图贴，会贴到镜像对称的位置上。

## 采购批次

`~/Downloads/BOM_采购清单*.xlsx` 里**一个工作表就是一批料**（采购清单 / 补 /
补2 / …）。换料卡和顶栏会显示「第 N 批」，直接去翻对应那袋。

**这是个人采购数据（含采购量、已购状态），单独输出到 `data/batches.json`
并已 gitignore，不进仓库。** 缺这个文件网页照常工作，只是不显示批次。
文件名会变成 `(2)`、`(3)`……脚本取 mtime 最新的那个，不写死。

匹配用三级判据，可靠的优先：

| 判据 | 说明 |
|---|---|
| **位号** | 采购表「规格要求」列里直接写了 `C73/C74/C75`，最强证据 |
| **料号** | 立创料号，**必须交叉验证封装**——这张表的料号列栽过跟头（2026-08-29 核出 7 处错位） |
| **规格 + 封装** | 归一化后比对 |

位号匹配也会查封装：位号是手写的，写错一个数字就会把人指到另一盘料上
（0402 和 0603 的 100pF 外观一样，拿错看不出来）。只在两边都是 4 位数字
尺寸码时才判冲突——全量比对会把电感那种「4x4mm 一体成型」vs `L_Bourns-SRN4018`
的正确匹配全部误杀。冲突时降级到下一级判据并在生成时打印警告。

匹配不上的显示「未在采购表中（多半是库存已有）」——**留白会被当成不用管**。
v4 有 28 组没匹配上，核对过：它们在采购表里根本不存在，11 个是 BOM 标注
「已有」的库存料。

## 数据从哪来

```
gen_assembly_web.py
├── .kicad_pcb                焊盘轮廓、元件外框、板框、坐标、旋转、DNP  ← 现读，永不过期
├── BOM_MASTER.csv (v4)       同料分组、材质、耐压、料号、备注
├── BOM_PURCHASE.md (v3)      同上
└── SELECTIVE_PLACEMENT.md    电源变体的选贴规则（脚本内硬编码，带断言）
```

几何一律从 PCB 当场算，不读 `render/` 下的 svg/png——那是某次导出的快照，
会比 PCB 旧，拿它当底图高亮框会指到旧位置上，而且看起来完全正常。

**改板后要重跑**（必须用 KiCad 自带的 Python，系统 python3 没有 pcbnew）：

```
~/Applications/KiCad/KiCad.app/Contents/Frameworks/Python.framework/Versions/Current/bin/python3 \
    hardware/tools/gen_assembly_web.py
```

页脚显示源 PCB 的日期，跟仓库里的 `.kicad_pcb` 对不上就是该重跑了。

产物契约由 `hardware/test_assembly_web_contract.py` 把关（跑在系统 python3 上）：
电源变体不能贴反、DNP 件不能混进列表、焊盘不能跑到板外。

```
/usr/bin/python3 -m unittest hardware.test_assembly_web_contract
```

## 排序

三级，按「找料成本 → 工艺 → 核对」排：

1. **元件大类**（芯片 → 连接器 → 滤波器 → 晶振 → 电感 → 二极管 → 晶体管 →
   保险丝 → 热敏 → 电容 → 电阻 → …）。手边一盒电容就一次贴完所有电容，
   不用贴两个就去翻电阻盒。大类之间仍守先大后小，大件先上板。
2. **段内按封装从大到小**（1206 → 0805 → 0603 → 0402）。工艺原则退到二级但
   仍然生效：大件对位要反复调整，周围先摆了 0402 会被镊子碰歪；逐个热风吹时
   吹外围也会掀翻已贴的小件。
3. **组内按位号升序**（D2 → D3 → D4 → D5），且**按数字比不按字符串比**，
   否则会排成 R1 R10 R11 R2，对着清单核对时看着像漏了一堆。

分类不能用 BOM 的「类型」列：两块板口径完全不同（v4 写元件类型、v3 写用途），
而且 v4 有 31 类、v3 有 37 类，做导航跟没有一样。改用**位号前缀**推导，
从 PCB 现读，跨板一致；认不出前缀的位号会让脚本当场失败，不会静默消失。

分类的粒度跟「一盘料」对齐——`ZS1` 是 0R 电阻用在 π 网络位，它和 `R21` 是
同一盘料（C21189），所以归在「电阻」里，特殊用途由位号旁的 use 标注表达。
按位号各自归类会让它单独成「匹配网络」，把电阻段劈成两截。

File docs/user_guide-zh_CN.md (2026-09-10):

# Pilot Kit Box — 用户指南

英文版：[`user_guide.md`](user_guide.md)

本文描述当前 **4.3 寸触摸板**。旧 2.4 寸四按键载板只是
`docs/jlc/` 下的历史硬件。

## 安全边界

Pilot Kit Box 是态势感知和开发设备，不是经过适航认证的飞行仪表、导航源、
备用仪表或防撞系统。所有飞行决策必须以批准的仪表、程序、目视观察和适用
法规为准。

## 1. 板上控制与接口

| 控制 / 接口 | 日常用途 |
|---|---|
| Key3 **POWER** | 短按开机；长按约两秒关机 |
| Key1 **RESET** | 重启 ESP32-P4 |
| Key2 **BOOT** | 进入下载模式的维护按键，不是 UI 按键 |
| H1 `USB TO UART` | P4 烧录、供电和串口日志 |
| H2 `USB` | 原生 USB 2.0 HS OTG，与 J3-27/25 同网。当前固件不使用：曾占用该口的 v1/v2 RTL-SDR dongle 路径已退役——1090 MHz 接收链现位于扩展板上 |
| 触摸屏 | 全部页面导航和用户操作 |

旧 `button_task.c` 已不参与当前固件编译。Rev1.2 板上没有 MODE、TARE、UP、
DOWN 四个应用按键。

## 2. 触摸导航

屏幕边缘常驻一个悬浮按钮（FAB）。

- 点击 **☰** 打开全屏导航网格。
- 第 1 页：**PFD、交通、地图、列表、搜索、记录、工具**；第 2 页：**诊断、
  设置、关于**。记录和工具是置灰占位（页面尚未实现），点击无响应。
- 左右滑动翻页；在第 1 页继续右滑可直接关闭网格。网格六秒无操作自动收起，
  也可点动作条的「关闭」。
- 长按 FAB 约 200 ms 后拖动；它会吸附到左/右边缘，侧边和纵向位置保存到 NVS。
- 进入诊断详情页后，FAB 变为 **←**；点击它、标题栏返回或向右滑动均可返回。
- 当前 GT911 驱动只读取第一触点，请单指操作。

### 调平姿态仪

打开导航网格，长按底部动作条的**调平**一秒。固件会捕获当前姿态基准并保存
到 NVS。短点只会提示“长按 1 秒调平地平仪”。

触摸 UI 没有旧 TARE 按钮的十秒工厂重置 / DCD 擦除入口。不要继续照旧
四按键说明操作。

## 3. 首次启动与罗盘校准

BNO085 校准质量持续为 0 时，屏幕会自动出现全屏“画 8 字”向导。

1. 远离扬声器、电机、笔记本、手机和大型钢制物体。
2. 握稳设备，缓慢画 8 字，并让设备经过多个不同姿态；不要只绕单轴旋转。
3. 持续到精度至少达到 2 且保持稳定，向导会自动退出；点“稍后再说”可跳过。
4. 把已安装设备放到正常水平姿态，打开导航网格，长按“调平”一秒。

BNO085 会在设备运动时持续修正磁场校准。调平保存的是 Pilot Kit 软件姿态
参考，与 BNO085 内部校准状态不是一回事。

安装变换由**扩展板板系**决定，不再是一个手工填的常量：v3 与 v4 两个板系把 IMU
贴在相差 90° 的角度上，固件按构建时选的板型自动使用对应变换。两版都假定盒子
竖立、屏幕面向飞行员、J1 排针边朝下。

**如果你的板子是 v3 板系（V3.x），构建时必须把板系切过去**（默认是 v4，切法见
[`docs/configuration.md`](configuration.md) 第 1 节）。选错板型的症状是地平仪
横滚整体偏 90°——照样有姿态、照样跟着动，桌上不容易看出来。开机串口日志里
`imu: board profile v3|v4` 那一行可以确认烧的是哪一版。

单靠调平无法修复错误的轴向映射：调平只是笼住地平仪，不改变轴的对应关系。

## 4. 主要页面

| 页面 | 内容与操作 |
|---|---|
| **PFD** | 姿态、俯仰/坡度、航向/HSI、地速、气压高度/升降率、GPS 和交通状态 |
| **交通** | 360° 交通雷达；点击量程/方向控件和目标查看选择或详情 |
| **地图** | 离线底图 + 航空叠加层（机场/导航台/FIX）；点符号进入详情页 |
| **列表** | 已跟踪飞机表；点击表头排序，拖动滚动，点击行展开详情抽屉 |
| **搜索** | 在本地航空数据库中检索机场、导航台和 FIX；可打开详情或在地图上显示 |
| **设置** | 语言、QNH、地图方向、量程、日志后端、演示模式和 MicroSD 格式化 |
| **关于** | 项目版本、构建信息和硬件摘要 |
| **诊断** | SDR（ADS-B 链路）、BLE、GPS、IMU、气压计、电池、存储等实时卡片；点击卡片进入详情。电池卡片按电源后端呈现：v4 powered 板报 SY6970 充电状态，其余回落载板 ETA6098 电压采样（百分比为电压估算，非电量计） |

网格中的**记录**和**工具**是置灰占位，对应页面尚未实现。网格只切换一级
页面；详情页不会再出现第二套导航网格。

### 存储设置

选择 MicroSD 日志后端后，下次启动才生效。启动时没有可用卡会在本次启动
回退到 LittleFS。格式化采用五秒内二次确认；当前日志正在写卡时会拒绝格式化。

### 演示模式（全部数据为模拟）

**设置 → 演示模式 → 开**。打开后，姿态、GPS、气压和 ADS-B 目标**全部**换成
固件内置的一套合成数据，与真实传感器是否接上无关；关掉立即恢复真实数据，
不需要重启。

用途是没接外设时在真机上核对各页的正常态版面与交互——出厂状态下 IMU、
气压计、GPS、SDR 都没装，每一页都是降级态，正常态的版面在真机上根本看不到。

> ⚠️ **屏上读到的一切都不是真的。** 演示模式与飞行无关，任何情况下都不要
> 在飞行中打开。

**怎么看出它开着**（三处，都关不掉）：

| 位置 | 表现 |
|---|---|
| 每一页顶栏右上角 | 红底白字的 **⚠ 演示** 徽标 |
| 整屏四周 | 一圈红框 |
| 开机画面 | 底部一条红色横幅「演示模式：全部飞行数据均为模拟」 |

徽标画在控件层、压在所有页面之上，没有单独的开关——**不存在「只要假数据、
不要标识」这种状态**。开机横幅是单独画的一份：演示模式会跨重启存活（存在
NVS），而开机画面早于控件层，用户重新上电时必须被单独告知一次。

**GDL90 输出**：演示模式下盒子**停发**所有 Ownship / Traffic 报文，只保留
心跳（且 GPS-valid 位强制为 0）。手机 App 上的表现是「设备在线、无 GPS、
无目标」。原因见 [`ble_protocol-zh_CN.md`](ble_protocol-zh_CN.md) §6.5：GDL90
的线上格式里没有「这是模拟数据」这一位，App 端无法区分真假目标，所以只能
不发。落盘的 ADS-B 记录同样不受影响——合成目标从来没有进过解码器和融合表。

**不会自动退出**：没有超时。让模式在用户不知情时自己变回去，比一直保持演示
态更危险（航空人因里典型的 mode confusion）。展会上连开一天是正常用法。
要退出就去设置页把它关掉。

## 5. 外接模块行为

- **ADS-B 接收：**v3/v4 扩展板自带完整 1090 MHz 接收链，板载 RP2040 以
  双沿捕获解码 Mode-S 帧，帧经 J3 排针上的 921600 波特 UART 送 P4，无需
  dongle。v1/v2 时代的 USB RTL-SDR 路径已退役：固件不再在载板 USB-A
  （J3-27/25）或 H2 上枚举 dongle；两者同网，至多只占用其一。H1 不是
  SDR 数据口，P1 也不是 USB。
- **BNO085：**当前驱动轮询地址 `0x4A`；INT 已接 GPIO34，但固件未使用。
- **BMP388：**当前驱动轮询地址 `0x76`；INT 已接 GPIO31，但固件未使用。
- **GPS：**UART1 使用 P4 TX GPIO49、P4 RX GPIO51，115200 8N1；时间来自
  NMEA RMC；GPIO50 PPS 已被固件消费、用于 `time_locked` 判定（fix 有效
  + PPS <2 s + NMEA <5 s）；把该新鲜度接入生产时间服务仍是后续任务。
- **BLE：**新板需要经 P1 一次性烧录 C6 ESP-Hosted slave。参见
  [`hardware/c6_slave_firmware-zh_CN.md`](hardware/c6_slave_firmware-zh_CN.md)。

## 6. 常见问题

| 现象 | 检查 |
|---|---|
| 无画面或无背光 | 确认供电稳定，复位后通过 H1 查看显示日志 |
| 触摸无响应 | 确认 GT911 在 `0x5D` 或 `0x14` 被识别；出厂 TP_INT 开路，固件使用轮询 |
| 触摸旋转或偏移 | 确认日志为逻辑 800×480、PPA 顺时针 90° |
| 航向响应错误 | 先核对 IMU 实际安装方向，再画 8 字校准并执行调平 |
| 交通页没有本机位置 | 把 GPS 天线移到开阔天空下等待定位 |
| 没有 ADS-B 帧 | 确认 v3/v4 扩展板已装上；在 P4 串口日志中查 `dsp`/`adsb` 标签（RP2040 UART 链路，921600 波特，J3 排针） |
| MicroSD 仍提示重启 | 保持卡插入并重启；缺卡或坏卡会回退 LittleFS |
| BLE 不广播 | 完成 C6 一次性烧录，并检查 ESP-Hosted 是否在 DSI 前启动 |

接口脚号和电气注意事项见
[`hardware/board_pinout-zh_CN.md`](hardware/board_pinout-zh_CN.md)。

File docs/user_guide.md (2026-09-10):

# Pilot Kit Box — user guide

Chinese version: [`user_guide-zh_CN.md`](user_guide-zh_CN.md)

This guide describes the current **4.3-inch touch board**. The previous
2.4-inch four-button carrier is historical hardware under `docs/jlc/`.

## Safety boundary

Pilot Kit Box is a situational-awareness and development device, not a
certified flight instrument, navigation source, backup instrument or
collision-avoidance system. Use approved instruments, procedures, visual
scan and applicable regulations for every flight decision.

## 1. Board controls and ports

| Control / port | Daily use |
|---|---|
| Key3 **POWER** | Short press to power on; hold about two seconds to power off |
| Key1 **RESET** | Restart the ESP32-P4 |
| Key2 **BOOT** | Service control for download mode; not a UI key |
| H1 `USB TO UART` | P4 flashing, power and serial monitor |
| H2 `USB` | Native USB 2.0 HS OTG, same nets as J3-27/25. Unused by the current firmware: the RTL-SDR dongle path that used this port (v1/v2 era) is retired — the 1090 MHz receive chain now lives on the expansion board |
| Touchscreen | All page navigation and user actions |

The legacy `button_task.c` is not compiled into the current firmware. There are no
MODE, TARE, UP or DOWN application buttons on the Rev1.2 board.

## 2. Touch navigation

A floating action button (FAB) stays near one screen edge.

- Tap **☰** to open the full-screen navigation grid.
- Page 1: **PFD**, **Traffic**, **Map**, **List**, **Search**, **Log**,
  **Tools**; page 2: **Diag**, **Setup**, **About**. Log and Tools are greyed
  placeholders (the pages are not implemented yet) and do not respond to taps.
- Swipe left/right to flip grid pages, or keep swiping right on page 1 to
  close the grid. The grid also closes after six seconds idle, or from the
  action bar's **Close** button.
- Hold the FAB for about 200 ms and drag it. It snaps to the left or right
  edge, and its side and vertical position are saved in NVS.
- On a diagnostic detail page, the FAB becomes **←**. Use it, the title-bar
  back control, or a right swipe to return.
- The current GT911 driver uses the first contact only. Use one finger.

### Level the attitude display

Open the navigation grid and hold **Level** in the bottom action bar for one
second. The firmware captures the current attitude reference and persists it
to NVS. A short tap only displays
“Hold 1 s to level the horizon.”

This touch UI does not expose the old ten-second factory-reset/DCD-wipe
gesture. Do not follow instructions written for the former TARE button.

## 3. First start and compass calibration

If BNO085 calibration quality remains zero, a full-screen figure-eight guide
appears automatically.

1. Move away from speakers, motors, laptops, phones and large steel objects.
2. Hold the device securely and make slow figure-eight motions through several
   orientations, rather than spinning around one axis.
3. Continue until accuracy reaches at least 2 and remains stable. The guide
   then closes automatically; **Later** dismisses it without calibrating.
4. Put the installed unit in its normal level pose, open the navigation grid
   and hold **Level** for one second.

BNO085 continuously refines its magnetic calibration while the unit moves.
Leveling stores the Pilot Kit software attitude reference; it is separate
from the BNO085 internal calibration state.

The mounting transform follows the **expansion board profile** rather than a
hand-entered constant. The v3 and v4 board families mount the IMU 90 degrees apart, and the
firmware applies the transform for whichever profile the image was built for.
Both assume the enclosure standing upright with the display facing the pilot
and the J1 header edge downward.

**If your board is in the v3 family (V3.x), select that profile at build time** — the default is
V4.3. See the first section of [`configuration.md`](configuration.md). The
symptom of a wrong profile is an artificial horizon rolled by 90 degrees: it
still moves and still looks live, which is easy to miss on a bench. The boot
log line `imu: board profile V3.9|V4.3` identifies the flashed image.

Leveling cannot correct a wrong axis mapping; it only cages the horizon.

## 4. Main pages

| Page | What it shows and how to use it |
|---|---|
| **PFD** | Attitude, pitch and bank, heading/HSI, ground speed, barometric altitude/vertical speed, GPS and traffic status |
| **Traffic** | 360° traffic radar; touch range/orientation controls and targets for selection/detail |
| **Map** | Offline basemap with an aviation overlay (airports, navaids, fixes); tap a symbol for its detail page |
| **List** | Tracked-aircraft table; tap headers to sort, drag to scroll and tap a row to open its detail drawer |
| **Search** | Search the local aviation databases for airports, navaids and fixes; open details or show one on the map |
| **Setup** | Language, QNH, map orientation, range, log backend, demo mode and MicroSD formatting controls |
| **About** | Project version, build information and hardware summary |
| **Diag** | Live SDR (ADS-B link), BLE, GPS, IMU, barometer, battery, storage and other subsystem cards; tap a card for detail. The battery card follows the power backend: SY6970 charger state on powered v4 boards, ETA6098 carrier voltage sampling otherwise (percentage is voltage-estimated, not a coulomb count) |

**Log** and **Tools** are greyed placeholders in the grid; those pages are
not implemented yet. The grid switches top-level pages only; detail pages
never show a second navigation grid.

### Storage setting

Selecting MicroSD as the log backend takes effect at the next boot. If no
usable card is present, logging falls back to LittleFS for that boot.
Formatting uses a two-step, five-second confirmation and is refused while
the active logger is writing to the card.

### Demo mode (all data is simulated)

**Setup → DEMO MODE → ON**. While it is on, attitude, GPS, barometer and
ADS-B traffic are **all** replaced by a synthetic data set built into the
firmware, whether or not the real sensors are attached. Turning it off
restores the real sensors immediately — no reboot needed.

It exists so the normal-state layout and interactions can be reviewed on a
real unit with no peripherals attached. Out of the box the IMU, barometer,
GPS and SDR are all absent, so every page renders its degraded state and the
normal-state layout is never visible on hardware.

> ⚠️ **Nothing on screen is real.** Demo mode has no in-flight use. Never
> turn it on in flight.

**How you can tell it is on** (three places, none of them defeatable):

| Where | What you see |
|---|---|
| Top-right of every page | A red **⚠ DEMO** badge |
| Screen edge | A red frame around the whole display |
| Boot splash | A red banner: "DEMO MODE - ALL FLIGHT DATA IS SIMULATED" |

The badge is drawn on the widget layer above every page and has no separate
switch — there is **no state in which you get the fake data without the
marking**. The boot banner is drawn separately because demo mode survives a
reboot (it is stored in NVS) and the splash runs before the widget layer
exists, so the user must be told again on every power-up.

**GDL90 output**: while demo mode is on the box **stops sending** all
Ownship / Traffic reports and emits only the heartbeat, with the GPS-valid
bit forced to 0. On the phone this reads as "receiver online, no GPS, no
traffic". The reasoning is in [`ble_protocol.md`](ble_protocol.md) §6.5:
GDL90 has no "this is simulated" bit on the wire, so an EFB cannot tell fake
traffic from real traffic, and the only safe option is not to send it.
On-disk ADS-B recordings are unaffected — synthetic targets never enter the
decoder or the fusion table.

**No auto-exit**: there is no timeout. Having the mode change back without
the user noticing is more dangerous than staying in demo mode (classic mode
confusion). Running all day at a trade show is a legitimate use. To leave,
turn it off in Setup.

## 5. External-module behavior

- **ADS-B receive:** the v3/v4 expansion board carries the full 1090 MHz
  receive chain and an RP2040 that captures dual edges and decodes Mode-S
  frames; frames reach the P4 over a 921600-baud UART on the J3 header. No
  dongle is needed. The v1/v2-era USB RTL-SDR path is retired: firmware no
  longer enumerates a dongle on the carrier USB-A (J3-27/25) or H2, which
  share the same nets — at most one may be occupied. H1 is not an SDR data
  path and P1 is not USB.
- **BNO085:** current driver polls address `0x4A`; INT is wired to GPIO34 but
  unused by firmware.
- **BMP388:** current driver polls address `0x76`; INT is wired to GPIO31 but
  unused by firmware.
- **GPS:** UART1 uses P4 TX GPIO49 and P4 RX GPIO51 at 115200 8N1. Time comes
  from NMEA RMC; GPIO50 PPS is consumed by firmware for the `time_locked`
  status (valid fix + PPS <2 s + NMEA <5 s) — wiring that freshness into the
  production time service remains a follow-up.
- **BLE:** a new board needs the C6 ESP-Hosted slave image flashed once through
  P1. See [`hardware/c6_slave_firmware.md`](hardware/c6_slave_firmware.md).

## 6. Troubleshooting

| Symptom | Check |
|---|---|
| No image or backlight | Confirm stable power; reset the board; inspect the display logs through H1 |
| Touch does not respond | Confirm GT911 is detected at `0x5D` or `0x14`; the factory board uses polling because TP_INT is open |
| Touch is rotated or offset | Confirm the firmware reports logical 800×480 and PPA 90° clockwise |
| Heading does not react correctly | Check the physical IMU mounting first, then run figure-eight calibration and Level |
| Traffic says no own position | Move the GPS antenna to open sky and wait for a fix |
| No ADS-B frames | Confirm the v3/v4 expansion board is fitted; check P4 serial logs for the `dsp`/`adsb` tags (RP2040 UART link, 921600 baud on J3) |
| MicroSD selection still says reboot | Leave the card inserted and reboot; absent/bad cards fall back to LittleFS |
| BLE never advertises | Complete the one-time C6 slave flash and check ESP-Hosted startup before DSI |

For connector pin numbers and electrical cautions, use
[`hardware/board_pinout.md`](hardware/board_pinout.md).

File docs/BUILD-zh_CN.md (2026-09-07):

# 构建与烧录指南

英文版：[`BUILD.md`](BUILD.md)

本文档面向**第一次接触 ESP32-P4 / Pilot Kit Box 项目**的开发者，从零开始一步步带你完成：

1. 安装编译环境 (ESP-IDF v6.0.1)
2. 拉取源码
3. 配置 + 编译固件
4. 通过 H1 `USB TO UART` 烧录到 Waveshare ESP32-P4-WIFI6-Touch-LCD-4.3
5. 第一次（可选）烧录板载 ESP32-C6 协处理器的 esp_hosted slave 固件，启用蓝牙

如果你是经验丰富的 ESP-IDF 用户，可以直接跳到第 5 节看具体 `idf.py` 命令；如果你是第一次接触这个项目，请按顺序读完。

---

## 0. 先决条件 / Prerequisites

### 硬件 / Hardware

| 必备 | 描述 |
|---|---|
| **Waveshare ESP32-P4-WIFI6-Touch-LCD-4.3** | P4NRW32 + C6 一体板，板载 4.3 寸 ST7701 DSI 屏、GT911 触摸、32 MB Flash 与 32 MB PSRAM。 |
| **USB-C 数据线** | 用于供电、烧录、串口监视。注意是数据线，不是只能充电的线。 |
| **macOS / Linux / Windows 主机** | 任何能装 ESP-IDF 的开发机。本文以 **macOS** 为主要示例，Linux 步骤几乎一样，Windows 下用 PowerShell + 安装包路径会略有差异，在每一步会标注。 |

### 选配（启用对应功能时需要）

| 选配硬件 | 用途 | 对应功能 |
|---|---|---|
| RTL-SDR FC0013 USB dongle（仅 v1/v2 历史） | 已退役路径（2026-09 移除，历史细节见 git 历史）：固件不再支持 USB dongle 接收，1090 MHz 接收链在 v3/v4 扩展板上 | —（历史） |
| BNO085 IMU 模块 | 姿态融合 | PFD 姿态显示 |
| USB-UART 转接器 (CP2102 / FTDI / CH340 任一即可) | 烧录 C6 hosted slave 固件 | BLE bring-up |

### 软件 / Software prerequisites

- **Git** 2.20+
- **Python 3.10+**（使用 [ServBay](https://servbay.com) 安装或 IDF Manager 自带）
- **CMake 3.16+**（IDF Manager 自带）
- **Ninja**（IDF Manager 自带）

---

## 1. 安装 ESP-IDF v6.0

> ⚠️ **必须用 ESP-IDF v6.0.x**。v5.x 不支持本项目用到的若干 component-manager 包；v7+（如果未来发布）我们尚未验证。

推荐用 **Espressif Installation Manager (eim)**，对新人最友好：

### macOS / Linux — Espressif Installation Manager 方式

1. **下载并运行 eim**（官方安装器）：
   ```bash
   # macOS / Linux 都可
   curl -L https://dl.espressif.com/dl/eim/eim-installer.sh | bash
   ```
   或者去 https://dl.espressif.com/dl/eim/ 下载图形化版本。

2. 安装时选择：
   - **IDF version**: `v6.0.1`
   - **Target**: `all`（或至少勾上 `esp32p4` 和 `esp32c6`）
   - **Install path**: 接受默认 `~/.espressif`

3. 安装会下载约 1.5 GB（toolchain + Python venv + 工具）。等它跑完，最后会生成一个 activation 脚本：
   ```
   ~/.espressif/tools/activate_idf_v6.0.1.sh
   ```

4. **激活环境**（每次开新终端都要做一次）：
   ```bash
   source ~/.espressif/tools/activate_idf_v6.0.1.sh
   ```
   激活后 `idf.py --version` 应输出 `ESP-IDF v6.0.1`。如果嫌每次都 source 麻烦，把这一行加到 `~/.zshrc` / `~/.bashrc`。

### Windows — Espressif IDE installer

1. 去 https://dl.espressif.com/dl/esp-idf/ 下载 ESP-IDF Windows Installer。
2. 安装时选 v6.0.1。
3. 桌面会生成 "ESP-IDF v6.0.1 PowerShell" 快捷方式。**所有 `idf.py` 命令都在这个 PowerShell 里跑**，普通 PowerShell 不行。

### 验证安装

激活环境后，跑：

```bash
idf.py --version
```

应该看到：

```
ESP-IDF v6.0.1
```

如果看到 `idf.py: command not found`，说明环境没激活，回到上面 source 那一步。

---

## 2. 拉取源码

```bash
# 选一个你喜欢的目录
cd ~/repos

git clone https://github.com/naizhao/Pilot-Kit-Box-ESP32-P4.git
cd Pilot-Kit-Box-ESP32-P4
```

### 子模块说明

仓库曾经把 RTL-SDR 驱动（`firmware/components/esp32-rtl-sdr/`，v1/v2 载板
USB 数据路径）作为 submodule 管理；该路径已退役，子模块已随退役代码一并
删除。现在仓库**没有任何 submodule**，直接 `git clone` 即可，不需要
`--recursive`。

### 目录结构速览

```
Pilot-Kit-Box-ESP32-P4/
├── docs/
│   ├── BUILD.md                        ← 你正在读的
│   ├── architecture.md                 ← 任务/数据流/内存图
│   ├── ble_protocol.md                 ← BLE GATT 服务规范（给 Pilot Kit App 团队）
│   ├── configuration.md                ← sdkconfig 配置参考
│   └── hardware/
│       ├── README.md                   ← 硬件资料索引
│       ├── board_pinout.md             ← Waveshare 板 GPIO 全表
│       ├── c6_slave_firmware.md        ← C6 hosted slave 烧录指南
│       └── ESP32-P4-WIFI6-datasheet.pdf
├── firmware/                           ← ESP-IDF 工程根
│   ├── CMakeLists.txt
│   ├── sdkconfig.defaults              ← 默认配置（项目级）
│   ├── partitions.csv                  ← 自定义分区表
│   ├── main/                           ← 应用层源码
│   └── components/                     ← （原 esp32-rtl-sdr submodule 已随退役路径删除）
└── README.md
```

---

## 3. 新板首次设置：烧 ESP32-C6 hosted slave 固件（**一次性**）

> ✅ **BLE 已经全链路跑通**（`CONFIG_PK_BLE_ENABLED=y` 是默认值）。每块全新的 Waveshare ESP32-P4-WIFI6-Touch-LCD-4.3 第一次用都要做这一步——出厂的 C6 上面跑的是工厂 AT 命令固件，跟我们 P4 上的 ESP-Hosted / NimBLE host 协议对不上。**这一步耗时 ~30 分钟、每块板只做一次**，做完之后 C6 的 hosted slave 固件**永久驻留**（除非你重新烧 AT 固件覆盖），所有后续 P4 固件迭代都不再碰 C6。
>
> **能不能跳过？** 可以，但 BLE 就不能用。如果你**确定不要 BLE**（比如只做 ADS-B 数据路径开发、没买 USB-UART 转接器、跑 CI），跳到 Section 4 之前先做：
>
> ```bash
> cd firmware
> idf.py menuconfig
> # → Pilot Kit Box → 取消 [*] Initialise BLE GATT server at boot
> ```
>
> 然后再做 Section 4 编译。**不关 BLE 又跳过这一节**的话 P4 固件第一次启动就会 `abort()`（vhci_drv 找不到 C6 时强制 abort，没有 graceful degrade）。

### 所需器材

| 必备 | 描述 |
|---|---|
| **USB-UART 转接器** | CP2102 / FTDI FT232 / CH340 / CH343 都行，输出 3V3 TTL |
| **3 根杜邦线（母对公）** | 转接器 ↔ P1 上的 TX / RX / GND |
| **1 段回形针 / 短线** | 板内短接 IO9 到任意 GND（让 C6 进 download mode）|

### 接线（板子背面的 4-pin P1 下载排针）

| P1 pin | 板上标注 | 接到 |
|---|---|---|
| 1 | C6_TXD | 转接器的 RX |
| 2 | C6_RXD | 转接器的 TX |
| 3 | C6_IO9 | **板内** 短接到任意 P4 GND 针脚（C6 download mode strap，烧完再拔） |
| 4 | GND | 转接器的 GND |

P1-3 (IO9) **不接**转接器信号 —— 它只需要在烧录期间被板内短到 GND
就行，跟 USB-UART 之间没有信号关系。

### 准备 C6 slave 固件二进制

两条路，选一条：

**(A) 最快路径 ——用 esphome 预编译好的二进制**（推荐，省 ~10 分钟，跟我们自己编译的功能完全等价）：

```bash
curl -L -o firmware/network_adapter_esp32c6.bin \
    https://esphome.github.io/esp-hosted-firmware/v2.12.7/network_adapter_esp32c6.bin
# sha256: ee7c546eb726ba92aa583448969c05f378a0deae5b3556699122761b7a595f51
```

**(B) 自己编译 slave**（如果你想改 slave config）：

```bash
# 复制本仓库 vendored 的 slave 工程到外面（slave 的 partitions.esp32c6.csv
# 会跟 P4 工程的 partitions.csv 冲突，必须在仓库外构建）
cp -R firmware/managed_components/espressif__esp_hosted/slave ~/hosts/c6_slave
cd ~/hosts/c6_slave

source ~/.espressif/tools/activate_idf_v6.0.1.sh
export PATH="$IDF_PATH/tools:$PATH"   # eim 的 activate 不会加这条
idf.py set-target esp32c6
# sdkconfig.defaults.esp32c6 已经包含正确的 SDIO + BLE controller 配置，
# 默认开 CONFIG_ESP_SDIO_HOST_INTERFACE=y + CONFIG_BT_LE_HCI_INTERFACE_USE_RAM=y，
# 不需要再 menuconfig。
idf.py build
# 产物：build/network_adapter.bin (~1.2 MB)
```

### 烧录步骤（**顺序很重要**）

**关键点**：P1 只有 UART 与 IO9，没有引出 C6 的 RESET。要进 download
mode 只能“启动时 IO9 拉低”——这要求 C6 在 IO9 已经短接到 GND 的状态下
**冷启动**。同时还得防止 P4 在烧 C6 期间通过 GPIO54 干扰 C6，所以也要
让 P4 进 download mode 站着不动。Rev1.2 上 GPIO54 经 R34 0 Ω 直连 C6
EN，没有反相器或电平转换器。

按这个顺序：

1. **断开所有电源**：拔掉 H1 `USB TO UART`，板子完全不通电。

2. **接 3 根杜邦线**（按 [§3 接线表](#接线板子背面的-4-pin-p1-下载排针)）：UART 转接器 RX→P1-1、TX→P1-2、GND→P1-4。

3. **板内短接 IO9 → GND**：回形针 / 短跳线，P1-3 短到板上任意 P4
   GND 针脚。IO9 不接 UART 控制信号。

4. **先把 UART 转接器插上电脑**。此时只有转接器通电（电脑 USB → 转接器），P4 板还没电。`ls /dev/cu.usbserial-*` 应该看到设备出现（macOS 上类似 `/dev/cu.usbserial-0001`，CP2102/CH340 各家命名不同）。

5. **按住板子正面的 BOOT 按钮不放**。

6. **保持按住 BOOT** 的同时，把 H1 插上电脑给板子上电。这一瞬间发生的事：
   - P4 看到 BOOT 是低电平 → 进 download mode、不会跑我们的固件，于是 GPIO54 浮空（不会去乱 reset C6）
   - C6 看到 IO9 是低电平（你的短接）→ 进 download mode、停在 ROM bootloader 等命令

7. **松开 BOOT 按钮**（已经上电完成、strap 已锁存，松开没影响）。

8. **运行项目烧录脚本**。它会每 1 秒自动探测串口、校验镜像，并用已经
   真机验证过的 115200 baud / no-reset 序列写入。串口出现后只启动一次
   esptool，避免 USB-UART 被反复打开时出现 macOS `termios EINVAL`：

   ```bash
   firmware/tools/flash_c6_hosted.sh --port /dev/cu.usbserial-XXXX

   # 连续烧多块：每块成功后拔出 USB-UART，脚本会自动等待下一块
   firmware/tools/flash_c6_hosted.sh --batch
   ```

   脚本等待期间不要求按 Enter；不接硬件时可先用 `--check-only` 校验
   ESP-IDF 环境与镜像。它会强制设置 `ESP_IDF_VERSION=6.0`，避免
   ESP-Hosted Kconfig 回退到 H2/SPI。

   （路径 A 只烧 app 一个 bin；路径 B 还要加上 bootloader + partition table，详见
   [`docs/hardware/c6_slave_firmware.md`](hardware/c6_slave_firmware.md) §4。）

   看到 `Hash of data verified.` 即烧录成功。

9. **断电收线**：
   - 拔掉 H1（断开整板电源）
   - 拔掉 IO9 ↔ GND 短接（不拔的话下次上电 C6 又会进 download mode）
   - 杜邦线可以留着也可以拆，下次烧 C6 还能用

10. **重新插上 H1**。C6 这次 IO9 是高电平了，正常引导执行 hosted slave 固件；P4 也正常引导执行我们的固件。验证日志里能看到：

    ```
    I (xxxx) transport: Identified slave [esp32c6]
    I (xxxx) ble_gatt: advertising as "Pilot Kit Box-XXXXXX"
    ```

详细分步说明 + 故障排查见 [`docs/hardware/c6_slave_firmware.md`](hardware/c6_slave_firmware.md)。

---

## 4. 配置（多数情况下用默认即可）

### 设置目标芯片

第一次构建前必须告诉 ESP-IDF 目标芯片：

```bash
cd Pilot-Kit-Box-ESP32-P4/firmware
idf.py set-target esp32p4
```

这一步会生成 `sdkconfig` 文件（基于 `sdkconfig.defaults`）。**如果之前已经存在 `sdkconfig`，建议先改名备份再重新生成**：

```bash
[ -f sdkconfig ] && mv sdkconfig sdkconfig.backup-$(date +%Y%m%d-%H%M)
idf.py set-target esp32p4
```

### 选扩展板板型（**唯一一个必须自己确认的选项**）

```bash
./build.sh menuconfig
#   -> Pilot Kit Box -> Expansion board profile
```

**默认是 v4 板系。** 手上是 **v3** 板就必须改过来（看板号第一位，v3.x 都用 v3 固件，小版本只是修订）——两个板系的传感器贴片角度不同
（U4 差 90°，且 U4 与 U5/U6 转向相反），选错了 PFD 照样出姿态、照样跟着动，只是横滚整体
偏 90°，桌上看不出来。

非交互改法（`sdkconfig` 不进 git，只影响你本地）：

```bash
sed -i '' 's/^# CONFIG_PK_BOARD_PROFILE_V3 is not set$/CONFIG_PK_BOARD_PROFILE_V3=y/' sdkconfig
sed -i '' 's/^CONFIG_PK_BOARD_PROFILE_V4=y$/# CONFIG_PK_BOARD_PROFILE_V4 is not set/' sdkconfig
```

编完确认编的是哪一版：`grep PK_BOARD_PROFILE build/config/sdkconfig.h`；
烧完看开机日志 `imu: board profile v3|v4: q_body_fix = …` 那一行。
细节见 [`docs/configuration.md`](configuration.md) 第 1 节。

### 关键配置项（已在 sdkconfig.defaults 写好，无需手动改）

如果你只是要把固件跑起来，**这一节可以跳过**。完整的配置参考见 [`docs/configuration.md`](configuration.md)。

- `CONFIG_IDF_TARGET="esp32p4"` — 目标芯片
- `CONFIG_ESPTOOLPY_FLASHSIZE_32MB=y` — Waveshare 板有 32 MB Nor flash
- `CONFIG_PARTITION_TABLE_CUSTOM=y` + `CONFIG_PARTITION_TABLE_CUSTOM_FILENAME="partitions.csv"` — 使用自定义分区表（含 10 MiB LittleFS 区；另支持可选 MicroSD 文件后端）
- `CONFIG_ESP32P4_SELECTS_REV_LESS_V3=y` + `CONFIG_ESP32P4_REV_MIN_100=y` — **针对 v1.x silicon 的 Waveshare 板**。IDF v6.0 默认编 v3.1+ 目标，而当前 Waveshare 出货的 P4 多是 v1.3 silicon，不打开这两个开关会出现：
  ```
  A fatal error occurred: 'bootloader/bootloader.bin' requires chip revision
  in range [v3.1 - v3.99] (this chip is revision v1.3).
  ```
- `CONFIG_BT_ENABLED=y` + `CONFIG_BT_CONTROLLER_DISABLED=y` + ESP_HOSTED SDIO 引脚 — BLE 走 C6 协处理器

### 想改配置？

```bash
idf.py menuconfig
```

会弹出终端 UI，可以浏览所有 Kconfig 选项。常见调整见 [`docs/configuration.md`](configuration.md)。

---

## 5. 编译

```bash
cd firmware
idf.py build
```

**第一次编译大约 5–15 分钟**（取决于网速 + CPU）：

- IDF Component Manager 会从 https://components.espressif.com 下载约 50 MB 依赖包
  （`espressif/usb`, `espressif/esp_hosted`, `joltwallet/littlefs` 等）
- 编译大约 1,200 个 .c 文件成 .o 文件再链接

**之后增量编译只需 5–30 秒**（取决于改了哪个文件）。

编译成功后会看到：

```
Project build complete. To flash, run:
 idf.py flash
or
 idf.py -p PORT flash
or
 ...

pilot_kit_box.bin binary size 0x2c93b0 bytes. Smallest app partition is 0xc00000 bytes. 0x936c50 bytes (76%) free.
```

产物位于 `firmware/build/`：
- `bootloader/bootloader.bin` — 二级 bootloader (~23 KiB)
- `partition_table/partition-table.bin` — 分区表 (~3 KiB)
- `pilot_kit_box.bin` — 主固件 (~2.9 MB；8 MB 机型库搬到 SD 卡之前是 ~11.5 MB)

### 扩展板 RP2040 固件（独立工程，可选）

v3/v4 扩展板上的 RP2040（1090 MHz 解码协处理器）是独立芯片、跑独立固件，
**不是** ESP-IDF 工程：进入 `firmware/rp2040/` 跑 `./build.sh` 构建。工具链
要求、依赖 pin 与注意事项见
[`../firmware/rp2040/README.md`](../firmware/rp2040/README.md)；烧录/恢复走
BOOTSEL 拖放，步骤见 [`firmware_update-zh_CN.md`](firmware_update-zh_CN.md)。

---

## 6. 连接板子 + 找到串口

### 接线

把 USB-C 数据线一端接 H1、也就是丝印为 `USB TO UART` 的 Type-C 口，
另一端接电脑。

> H1 走 CH343P USB-UART 桥。1090 MHz 数据链路走 UART 而不是 USB：v3/v4
> 扩展板的 RP2040 解码后经 UART2（P4 RX=46 / TX=32，921600 波特）送入 P4。
> 旧的 RTL-SDR USB 路径（P4 原生 USB 2.0 HS）已退役，固件不再支持。
> P1 是 C6 下载排针，不是 USB。

### 找串口

#### macOS

```bash
ls -la /dev/cu.usbmodem*
```

应该能看到类似：
```
/dev/cu.usbmodem5B7B0255751
```

后面那一串数字是设备的序列号，每块板子不一样。**记住完整路径**，下面要用。

如果什么都没看到：
- 检查 USB 线是不是数据线（不是充电线）
- 换一个 USB 端口（最好是机器直插，别经过 hub）
- macOS 弹窗问 "Allow USB device" 时点允许

#### Linux

```bash
ls -la /dev/ttyACM* /dev/ttyUSB*
```

通常是 `/dev/ttyACM0` 或 `/dev/ttyUSB0`。可能需要把当前用户加进 `dialout` 组：

```bash
sudo usermod -aG dialout $USER
# 注销后重新登录才生效
```

#### Windows

打开「设备管理器」→「端口 (COM 和 LPT)」，看到 "USB Serial Device (COMx)" 或 "CH343 (COMx)"。记下 `COMx`。

---

## 7. 烧录 P4 + 串口监视

### 一键搞定

```bash
cd Pilot-Kit-Box-ESP32-P4/firmware
source ~/.espressif/tools/activate_idf_v6.0.1.sh   # 每个新终端都要

# macOS / Linux：
idf.py -p /dev/cu.usbmodem5B7B0255751 flash monitor

# Windows：
idf.py -p COM3 flash monitor
```

这条命令做了 4 件事：
1. 把 bootloader、partition table、应用三个 bin 烧到指定串口
2. esptool 自动通过 DTR/RTS 让 P4 进入 download 模式
3. 烧完后自动复位
4. 启动串口监视，显示 boot log + 运行时日志

**首次烧录约 1-2 分钟**（写入 ~1 MB 数据 + 校验）。之后增量烧录只烧应用分区，~30 秒。

### 退出串口监视

按 `Ctrl-]`（macOS 是 `Control + ]`）。

### 如果 `Failed to connect` / 自动复位失败

某些 USB-C 数据线 / 转接器不支持 DTR/RTS 控制。手动进入 download 模式：

1. **按住** BOOT 按钮（板子上有标注，靠近 Type-C 口）
2. **短按一下** RESET 按钮
3. **松开** BOOT
4. 重新跑 `idf.py flash`

如果还是不行，看下面的「常见问题」。

### 只烧录不监视

```bash
idf.py -p <PORT> flash
```

### 只监视不烧录

```bash
idf.py -p <PORT> monitor
```

### 擦除 flash（恢复出厂）

```bash
idf.py -p <PORT> erase-flash
```

⚠️ 这会**抹掉 LittleFS 上存的所有 ADS-B 历史数据**。

---

## 8. 看到什么算成功

烧完后，串口应该有类似这样的开机日志（**没接任何外设的空板** + 已完成 Section 3 的 C6 烧录情况）：

```
I (1559) pilot_kit:   Pilot Kit Box (ESP32-P4) boot
I (1564) pilot_kit:   Free internal heap at boot: 350371 B
I (1612) record_sink: registered sink 'uart' (1 total)
I (1615) record_sink: registered sink 'ble_raw' (2 total)
I (1620) pk_sd:       no microSD card at boot (will keep probing)      ← 没插卡时正常
I (3236) rec_file:    LittleFS mounted at /storage: 32/10240 KiB used   ← 第一次启动会自动格式化 LittleFS
I (3470) record_sink: registered sink 'file_littlefs' (3 total)
I (3472) rec_file:    logging ADS-B to /storage/pilot_kit_ts_1.txt (rotate every 1024 KiB, keep 12 files)
I (3474) pilot_kit:   ADS-B sinks ready (UART + file at /storage)
I (3486) dsp:         adsb_link_task running (UART2 rx=46 tx=32 921600 baud)   ← 1090 链路 = 扩展板 RP2040 UART
I (3617) display:     ST7701 DSI ready: logical 800x480 -> PPA 90 CW -> native 480x800, 2 DPI buffers, app framebuffer 750 KiB PSRAM
E (4401) imu:         enable_rotation_vector: ESP_ERR_INVALID_RESPONSE         ← 预期（没接 BNO085）
W (4402) pilot_kit:   IMU init failed (ESP_ERR_INVALID_RESPONSE) — PFD will run without attitude
I (4405) pfd:         pfd_task running (G1000 landscape)
I (4417) pilot_kit:   PFD render task running
I (4490) transport:   Identified slave [esp32c6]
I (4510) vhci_drv:    Host BT Support: Enabled | BT Transport Type: VHCI
I (4520) ble_gatt:    NimBLE host task running
I (4530) ble_gatt:    GDL90 emitter task running
I (4540) ble_gatt:    BLE address 8c:fd:49:0b:5a:8a type=0
I (4550) ble_gatt:    advertising as "Pilot Kit Box-0B5A8A"
I (4560) main_task:   Returned from app_main()
I (5439) pfd:         PFD 32 FPS  | roll= +0.00 pitch= +0.00 yaw=  0.00 ...    ← 1Hz FPS 心跳
... (PFD FPS 心跳每秒一行；`dsp: link rx/s ...` 1Hz 链路心跳只在有帧进来时出现，空台架保持安静)
```

**关键确认点**：

| 看到这条 | 说明 |
|---|---|
| `Pilot Kit Box (ESP32-P4) boot` | 主应用启动正常 |
| `Found 32MB PSRAM device` + `Speed: 200MHz` | PSRAM 32 MB 起来了（之前在 1.5 节里看到）|
| `Reserving pool of 128K of internal memory for DMA/internal allocations` | DMA 内部内存预留 OK |
| `LittleFS mounted` | 存储分区 OK |
| `adsb_link_task running (UART2 rx=46 tx=32 921600 baud)` | 1090 MHz RP2040 UART 链路任务就绪 |
| `Returned from app_main()` | 所有初始化完成 |
| `PFD 30+ FPS` 周期出现 | 显示渲染管线 OK |
| `IMU init failed` | 预期（没接 BNO085） |
| `advertising as "Pilot Kit Box-XXXXXX"` | BLE 起来了，手机能扫到（XXXXXX = 本机 C6 MAC 后 3 字节） |

> 💡 **跳过 Section 3 的情况**（没烧 C6 hosted slave）：`PK_BLE_ENABLED` 改成 `n` 之后，上面 `advertising as ...` 那行会换成 `BLE disabled at build time (CONFIG_PK_BLE_ENABLED=n) — UART + file sinks only`。其他都一样。

### 接外设的预期

| 操作 | 预期 |
|---|---|
| 装 v3/v4 扩展板（1090 MHz） | `dsp: adsb_link_task running (UART2 rx=46 tx=32 921600 baud)`；有脉冲进来后出现 1Hz `dsp: link rx/s ...` 行，DIAG 飞机列表开始出现周边目标 |
| 给 4.3 寸一体板上电 | 800×480 全屏显示 Pilot Kit boot splash，最少停留约 3 秒 → 显示 PFD |
| 装 GT-U8 GPS | DIAG 更新 GPS/北斗卫星、SNR、天线状态和系统时间；定位后 TRAFFIC 获得本机位置 |
| 装 BMP388 | PFD / DIAG 显示压力、QNH 修正高度和升降率 |
| 插入 FAT32 MicroSD | DIAG 显示容量；Settings 把 LOG 改成 MICROSD 并重启后，日志写入 `/sdcard` |
| 接 BNO085 模块到 I²C0 + INT/RST | 串口出现 `imu: rpy = +1.23 / -0.45 / 187.66 (acc=3 valid=98)` 周期更新，晃动板子时 PFD 的 horizon 跟着翻 |
| C6 刷完 hosted slave 固件（见第 3 节） | 串口 `ble_gatt: advertising as "Pilot Kit Box-XXXXXX"`，手机 BLE 扫描器按 `Pilot Kit Box-` 前缀过滤能看到 |

---

## 9. 常见问题 / Troubleshooting

### `A fatal error occurred: 'bootloader/bootloader.bin' requires chip revision in range [v3.1 - v3.99]`

**原因**：IDF v6.0 默认编 P4 ECO5 (v3.1+) 目标，但你板上的 P4 是 v1.x silicon。

**修复**：检查 `firmware/sdkconfig.defaults` 里是否有：
```
CONFIG_ESP32P4_SELECTS_REV_LESS_V3=y
CONFIG_ESP32P4_REV_MIN_100=y
```
没有的话加上，然后：
```bash
cd firmware
[ -f sdkconfig ] && mv sdkconfig sdkconfig.bad-rev-$(date +%Y%m%d-%H%M)
idf.py build
```
重新烧。

### 启动早期 `HS_MP: mempool create failed: no mem` panic

**原因**：ESP-Hosted 在 `__libc_init_array()` 阶段（main 之前）调用 SDIO mempool 初始化，需要约 47 KiB DMA-capable 内部 RAM。如果默认 SDIO queue（20×1536）+ 默认 SPIRAM reserve（32 KiB）+ PSRAM 未启用三个条件中任一不满足，allocator 凑不出连续内存。

**修复**：sdkconfig.defaults 已经包含修复（PSRAM 启用、SDIO queue 缩到 8、reserve 增到 128 KiB）。如果你改过这些配置导致问题复发，恢复以下默认：
```
CONFIG_SPIRAM=y
CONFIG_SPIRAM_MODE_HEX=y
CONFIG_SPIRAM_SPEED_200M=y
CONFIG_SPIRAM_USE_MALLOC=y
CONFIG_SPIRAM_MALLOC_RESERVE_INTERNAL=131072
CONFIG_ESP_HOSTED_SDIO_TX_Q_SIZE=8
CONFIG_ESP_HOSTED_SDIO_RX_Q_SIZE=8
```

### 启动早期 `spi_mempool_create spi_drv.c:141 (buf_mp_g)` panic

**症状**：开机几乎立即崩溃，串口出现：
```
E (1534) HS_MP: mempool create failed: no mem
assert failed: spi_mempool_create spi_drv.c:141 (buf_mp_g)
```
然后栈展开里看到 `bus_init_internal at spi_drv.c:302` ← 注意这里是 **SPI**，跟上一节的 SDIO 看起来像但**根因完全不同**。

**根因**：ESP-Hosted 把 co-processor 当成 **ESP32-H2 走 SPI transport** 而不是预期的 **ESP32-C6 走 SDIO**。后果是 SPI 队列默认要 20×1536 B 内部 RAM，凑不出 → assert。

为什么 H2/SPI 替代了 C6/SDIO？因为 ESP-IDF v6.0.1 不再把 `ESP_IDF_VERSION` 环境变量塞进 Kconfig build env（只塞 `IDF_VERSION`），但 `managed_components/espressif__esp_wifi_remote/Kconfig` 仍然写着：

```kconfig
orsource "./Kconfig.idf_v$ESP_IDF_VERSION.in"
```

变量为空 → `Kconfig.idf_v6.0.in` silently 不加载 → `SLAVE_IDF_TARGET_ESP32C6` 选项不存在 → `ESP_HOSTED_CP_TARGET_ESP32C6` 因 `depends on SLAVE_IDF_TARGET_ESP32C6` 而隐藏 → choice 唯一未隐藏的 H2 选项被默认选中 → H2 默认走 SPI → 崩溃。

**快速识别**：看 `firmware/sdkconfig` 是否含：
```
CONFIG_ESP_HOSTED_CP_TARGET_ESP32H2=y          ← 错的
CONFIG_ESP_HOSTED_GPIO_SLAVE_RESET_SLAVE=12    ← 应该是 54
# CONFIG_ESP_HOSTED_SDIO_HOST_INTERFACE is not set
```

如果是，说明踩到了。

**修复**：

1. 备份再删 `sdkconfig`：
   ```sh
   cd firmware
   mv sdkconfig sdkconfig.broken-$(date +%Y%m%d-%H%M)
   ```

2. **设 `ESP_IDF_VERSION=6.0`** 后再 reconfigure：
   ```sh
   ESP_IDF_VERSION=6.0 idf.py reconfigure
   ```

   或更省事 —— 用项目自带的 `firmware/build.sh` wrapper，它自动设这个 env：
   ```sh
   ./build.sh reconfigure
   ./build.sh build
   ./build.sh -p /dev/cu.usbserial-XXX flash monitor
   ```

3. 检查 `sdkconfig` 现在写的是 C6/SDIO：
   ```sh
   grep -E "ESP_HOSTED_CP_TARGET_ESP32C6|ESP_HOSTED_SDIO_HOST_INTERFACE|ESP_HOSTED_GPIO_SLAVE_RESET_SLAVE=54" sdkconfig
   ```
   全部要在输出里。

**为什么不在应用层做"容错"绕过？** 这个 panic 发生在 `__libc_init_array`（C++ 全局构造器阶段），早于 `app_main()`，连 ESP_LOG 之外的应用代码都没机会跑。`CONFIG_PK_BLE_ENABLED` 那个 guard 只挡得住 `ble_gatt_init()` 这种 main-time 调用，挡不住 esp_hosted 的全局构造器。这是**配置层 bug**，应用层无解。

### `assert failed: vApplicationGetTimerTaskMemory` 启动期 panic

**原因**：内部 RAM 紧张到连 FreeRTOS timer task 的 8 KiB 栈都凑不出。通常是大型静态数组占了 `.bss` 内部段。

**修复**：把大数组（>1 KiB）的 `static` 声明加 `EXT_RAM_BSS_ATTR`（在 `esp_attr.h`）把它们丢到 PSRAM `.ext_ram.bss` 段。本仓库 `pfd.c` 和 `ble_gatt.c` 的 64 槽 `aircraft_t` 表已经这样处理。需要 `CONFIG_SPIRAM_ALLOW_BSS_SEG_EXTERNAL_MEMORY=y`。

### `assert failed: hci_h4_frame_start hci_h4.c` 启动期 panic

**原因**：NimBLE 默认走 H4 UART HCI（GPIO 4/5 @ 921600 baud）找 BT controller。我们的 controller 在 C6 上通过 SDIO 接出来，不是 UART。NimBLE 在 GPIO 4/5 上收到的全是垃圾，hci_h4 解码 assert。

**修复**：`CONFIG_BT_NIMBLE_TRANSPORT_UART=n` 已在 sdkconfig.defaults。这样 NimBLE 会自动用 esp_hosted 提供的 VHCI transport。

### `ble_transport_ll_init` 处 `ESP_ERROR_CHECK` 导致 abort

**原因**：ESP-Hosted 的 `transport_drv_reconfigure()` 在 C6 没有响应（没刷 hosted slave 固件）时返回失败；vhci_drv.c 第 154 行用 `ESP_ERROR_CHECK()` 包裹这个返回值，强制 abort。

**修复**：先按 [§3](#3-新板首次设置烧-esp32-c6-hosted-slave-固件一次性) 烧 C6 hosted slave 固件。已经烧过、还出这个错，再核对 GPIO54 / SDIO pin / 复位极性（`CONFIG_ESP_HOSTED_SDIO_RESET_ACTIVE_HIGH=y` 是实机验证过的唯一正确值）。如果暂时不想接 C6，跑：`idf.py menuconfig → Pilot Kit Box → [ ] Initialise BLE GATT server at boot`，或直接编辑 `sdkconfig` 把 `CONFIG_PK_BLE_ENABLED` 改成 `n` 再编。

### CMD5 `sdmmc_init_ocr: send_op_cond returned 0x107` 然后 reboot loop

**原因**：P4 host 发了 SDIO CMD5 但 C6 没正确响应（具体是
`INVALID_RESPONSE`，CRC 错或者根本没回）。项目实机验证要求 ESP-Hosted
使用 `RESET_ACTIVE_HIGH`；Rev1.2 原理图同时确认 P4 GPIO54 经 R34 0 Ω
直连 C6 EN，板上没有 inverter / level shifter，不能再用反相器解释该
软件选项。

**修复**：sdkconfig.defaults 已经设置 `CONFIG_ESP_HOSTED_SDIO_RESET_ACTIVE_HIGH=y`。如果你改过这一项，恢复默认即可（该板复位线为高有效，已实机验证，常见嫌疑如 SDIO 时钟、pull-up、LDO 都已排除）。

### `BLE_HS_ETIMEOUT_HCI (controller unresponsive)` 反复打印

**原因**：SDIO transport 已经起来（你能看到 `transport: Identified slave [esp32c6]`），但 C6 的 BT controller 没有 enable。ESP-Hosted-MCU 的 slave **不会**在 boot 时自动启 BT controller —— host 要先通过 RPC 显式调用 `esp_hosted_bt_controller_init()` + `esp_hosted_bt_controller_enable()`，再 `nimble_port_init()`。如果你 fork 了 `ble_gatt.c` 删掉了这两步，HCI 命令就会全部 timeout。

**修复**：恢复 `ble_gatt.c::ble_gatt_init()` 里的 connect → init → enable → nimble_port_init 顺序，参照 `managed_components/.../examples/host_nimble_bleprph_host_only_vhci/main/main.c`。

### Task "pfd" / "ble_emit" Stack protection fault

**原因**：栈太小放不下大型局部数组（`aircraft_t scratch[64]` ≈ 4.5 KiB on 4 KiB stack）。

**修复**：本仓库已经把这两个数组改成 `static EXT_RAM_BSS_ATTR`（PSRAM BSS），并把任务栈从 4 KiB 提到 6 KiB。如果你新加自己的渲染或采样任务，遵循同样的约定。

### `Failed to connect to ESP32-P4: Wrong boot mode detected`

esptool 自动复位失败。手动按 BOOT + RESET（见第 6 节末尾）。

### `nimble_port_init` 这一步串口卡住不动

C6 没有 hosted slave 固件。本仓库我们已经把 `ble_gatt_init()` 放在 `main()` 最后一步，所以**前面 LCD / PFD / 存储都会正常起来**。如果你 100% 不想用 BLE，可以临时关掉：

```bash
idf.py menuconfig
# → Component config → Bluetooth → 取消 [*] Bluetooth
```

或回到第 3 节烧 C6 slave 固件。

### `LittleFS mount failed`

99% 是分区表没烧。重跑：
```bash
idf.py -p <PORT> erase-flash
idf.py -p <PORT> flash
```

### MicroSD 已插入但日志仍写 Flash

日志后端只在启动时选择。确认卡是 FAT32，在 Settings 把 `LOG` 改为
`MICROSD` 后重启。启动时卡未挂载成功会自动回退 LittleFS；可在 DIAG
查看 MicroSD 容量和当前 `LOG` 后端。若要格式化卡，先把 LOG 切回 Flash
并重启，再在 `FORMAT SD` 行 5 秒内按两次 UP 或 DOWN 确认。

### 1090 MHz 链路没有 ADS-B 目标

RTL-SDR USB 路径已退役（仅 v1/v2 历史载板，当前固件不再枚举 dongle）。
1090 MHz 接收需要 v3/v4 扩展板：确认扩展板已插好在载板 2×20 排母上，
DIAG 的 ADS-B 链路卡片没有显示 `NO_LINK` / `PROTO_MISMATCH`。

### 编译时 `idf.py: command not found`

环境没激活。每次开新终端跑：
```bash
source ~/.espressif/tools/activate_idf_v6.0.1.sh
```

### 编译时 `Component "espressif/esp_hosted" not found`

Component manager 没下载。手动触发：
```bash
cd firmware
idf.py reconfigure
```
如果还是不行：
```bash
[ -d managed_components ] && mv managed_components managed_components.backup-$(date +%Y%m%d-%H%M)
idf.py reconfigure
```

### 想要清空中间产物重新编

```bash
idf.py fullclean
```

会清掉 `build/` 和 `managed_components/`。下次 build 又要重新下载依赖。如果只想清掉 build 缓存保留依赖：
```bash
idf.py clean
```

### 编译太慢

启用 ccache 大幅提速：
```bash
brew install ccache    # macOS
idf.py --ccache build
```

把 `--ccache` 加到环境变量：
```bash
echo 'export IDF_CCACHE_ENABLE=1' >> ~/.zshrc
```

---

## 10. 日常开发循环

修改代码 → 立即查看效果的最快流程：

```bash
# 终端 1，常驻 ESP-IDF 环境
cd firmware
source ~/.espressif/tools/activate_idf_v6.0.1.sh

# 改完代码后
idf.py -p /dev/cu.usbmodem5B7B0255751 flash monitor
```

`flash monitor` 是连写命令，编译 + 烧录 + 启监视一气呵成。增量编译 + 烧 ~30 秒一轮。

退出 monitor 用 `Ctrl-]`，重新进只 monitor 不烧：
```bash
idf.py -p <PORT> monitor
```

---

## 11. 参与贡献

- 改了 `firmware/` 下任何 `.c` / `.h` / `CMakeLists.txt` / `sdkconfig.defaults`：直接发 PR
- 加了新 doc：放 `docs/` 下，并在本文档 + `README.md` 加链接
- 加了新硬件支持：更新 `docs/hardware/board_pinout.md` + 创建对应章节

详细的代码规范见 [`docs/architecture.md`](architecture.md)。

---

## 12. 下一步

- 想了解整个系统跑起来后的数据/任务架构 → [`docs/architecture.md`](architecture.md)
- 想知道有哪些 sdkconfig 选项可调 → [`docs/configuration.md`](configuration.md)
- 想做 Pilot Kit 手机 App 的 BLE 集成 → [`docs/ble_protocol.md`](ble_protocol.md)
- 想自己改硬件接线 → [`docs/hardware/board_pinout.md`](hardware/board_pinout.md)
- 想烧 C6 启用 BLE → [`docs/hardware/c6_slave_firmware.md`](hardware/c6_slave_firmware.md)

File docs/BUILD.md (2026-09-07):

# Build And Flash Guide

Chinese version: [`BUILD-zh_CN.md`](BUILD-zh_CN.md)

This guide is for developers bringing up the Pilot Kit Box ESP32-P4 firmware from a clean machine. It covers ESP-IDF installation, repository clone, optional one-time ESP32-C6 slave flashing for BLE, ESP32-P4 build/flash, expected boot logs, and troubleshooting.

Experienced ESP-IDF users can skip to [Build](#build) after checking the prerequisites.

## Prerequisites

### Required Hardware

| Item | Notes |
|---|---|
| **Waveshare ESP32-P4-WIFI6-Touch-LCD-4.3** | Integrated P4NRW32 + C6, 4.3-inch ST7701 DSI display, GT911 touch, 32 MB flash and 32 MB PSRAM. |
| **USB-C data cable** | Used for power, flashing, and serial monitoring. Charge-only cables will not work. |
| **macOS / Linux / Windows host** | Any host that can run ESP-IDF. Commands below use macOS/Linux paths; Windows uses an ESP-IDF PowerShell and `COMx` ports. |

### Optional Hardware

| Item | Purpose |
|---|---|
| 1090 MHz source: v3/v4 RP2040 expansion board | Onboard receive chain + RP2040 decoder feeding the P4 over 921600-baud UART; the antenna connects to the expansion board's antenna port. USB RTL-SDR dongles are **not supported anymore** — that v1/v2-era path was removed from the firmware and component tree. |
| BNO085 / GY-BN008X IMU module | Attitude fusion for the PFD. |
| USB-UART adapter | Required once per fresh board to flash the ESP32-C6 hosted slave firmware for BLE. |

### Software

- Git 2.20+
- Python 3.10+
- CMake 3.16+
- Ninja
- ESP-IDF v6.0.1

## Install ESP-IDF v6.0.1

Use ESP-IDF v6.0.x. Older v5.x releases do not support the required ESP32-P4 component set, and newer major versions have not been validated for this firmware.

### macOS / Linux

The recommended path is Espressif Installation Manager:

```bash
curl -L https://dl.espressif.com/dl/eim/eim-installer.sh | bash
```

Select:

- IDF version: `v6.0.1`
- Target: `all`, or at least `esp32p4` and `esp32c6`
- Install path: the default `~/.espressif`

Activate the environment in every new shell:

```bash
source ~/.espressif/tools/activate_idf_v6.0.1.sh
```

Verify:

```bash
idf.py --version
```

Expected:

```text
ESP-IDF v6.0.1
```

### Windows

Install ESP-IDF v6.0.1 with Espressif's Windows installer, then run all `idf.py` commands inside the generated "ESP-IDF v6.0.1 PowerShell" shortcut.

## Clone The Repository

```bash
cd ~/repos
git clone --recursive https://github.com/naizhao/Pilot-Kit-Box-ESP32-P4.git
cd Pilot-Kit-Box-ESP32-P4
```

If the repository was cloned without submodules:

```bash
git submodule update --init --recursive
```

The repository currently defines no submodules. The former
`firmware/components/esp32-rtl-sdr/` submodule (the patched asynchronous
librtlsdr path used during the v1/v2 USB RTL-SDR era) was removed together
with that retired receive path; no RTL-SDR component is needed to build.

## One-Time ESP32-C6 Slave Flashing For BLE

BLE is enabled by default with `CONFIG_PK_BLE_ENABLED=y`. A new Waveshare
ESP32-P4-WIFI6-Touch-LCD-4.3 board ships with factory AT firmware on the C6,
which does not speak the ESP-Hosted / NimBLE host protocol used by the P4
firmware. Flash the C6 hosted slave image once per board before using BLE.

If you do not need BLE yet, disable it before building:

```bash
cd firmware
idf.py menuconfig
# Pilot Kit Box -> uncheck "Initialise BLE GATT server at boot"
```

For the full wiring and flashing procedure, see [`hardware/c6_slave_firmware.md`](hardware/c6_slave_firmware.md).

Required items:

- 3.3 V USB-UART adapter
- Three jumper wires for GND / RXD / TXD
- A short wire or paperclip to short C6 IO9 to board GND during boot

P1 download-header wiring:

| P1 pin | Board label | Connect to |
|---|---|---|
| 1 | C6_TXD | USB-UART RX |
| 2 | C6_RXD | USB-UART TX |
| 3 | C6_IO9 | Short to any board GND during C6 download-mode boot |
| 4 | GND | USB-UART GND |

Fast path using the prebuilt ESPHome image:

```bash
curl -L -o firmware/network_adapter_esp32c6.bin \
    https://esphome.github.io/esp-hosted-firmware/v2.12.7/network_adapter_esp32c6.bin

# Polls /dev/cu.usbserial-* once per second, validates the image,
# and flashes one board without repeatedly reopening the UART.
firmware/tools/flash_c6_hosted.sh

# For multiple boards; unplug the USB-UART after each successful write.
firmware/tools/flash_c6_hosted.sh --batch
```

The script uses the tested 115200-baud, no-reset sequence and keeps
`ESP_IDF_VERSION=6.0`. Use `--check-only` to validate the environment
and image without touching hardware.

After flashing, remove the IO9-to-GND short and power-cycle the board. A working C6 path logs:

```text
transport: Identified slave [esp32c6]
ble_gatt: advertising as "Pilot Kit Box-XXXXXX"
```

## Configure

Use the project wrapper where possible:

```bash
cd firmware
./build.sh set-target esp32p4
```

The wrapper sets the `ESP_IDF_VERSION=6.0` environment variable required by ESP-Hosted Kconfig under ESP-IDF v6.0.1 and forwards to `idf.py`.

Important defaults already live in `firmware/sdkconfig.defaults`:

- `CONFIG_IDF_TARGET="esp32p4"`
- `CONFIG_ESPTOOLPY_FLASHSIZE_32MB=y`
- custom `partitions.csv` with a 10 MiB LittleFS storage partition and optional MicroSD file backend
- ESP32-P4 v1.x silicon support for current Waveshare boards
- ESP-Hosted SDIO pins for the on-board C6
- BLE enabled by default through `CONFIG_PK_BLE_ENABLED=y`

For details, see [`configuration.md`](configuration.md).

### Select The Expansion Board Profile

This is the one option you must confirm yourself. The default is the **v4** board family;
switch it if you have a **v3** board. The choice is the family — v3.x all use the `v3`
image, v4.x all use the `v4` image; the minor number is only a revision.

```bash
./build.sh menuconfig
#   -> Pilot Kit Box -> Expansion board profile
```

Non-interactive (`sdkconfig` is gitignored, so this stays local):

```bash
sed -i '' 's/^# CONFIG_PK_BOARD_PROFILE_V3 is not set$/CONFIG_PK_BOARD_PROFILE_V3=y/' sdkconfig
sed -i '' 's/^CONFIG_PK_BOARD_PROFILE_V4=y$/# CONFIG_PK_BOARD_PROFILE_V4 is not set/' sdkconfig
```

The two families mount their sensors at different angles (U4 differs by 90 degrees, and U4 and
U5/U6 rotate in opposite directions). With the wrong profile the PFD still shows a live
attitude — rolled by 90 degrees — which is easy to miss on a bench.

Verify before flashing with `grep PK_BOARD_PROFILE build/config/sdkconfig.h`, and after
flashing with the `imu: board profile v3|v4: q_body_fix = ...` boot log line.
See [`configuration.md`](configuration.md) for the full section.

## Build

```bash
cd firmware
./build.sh build
```

The first build may take 5-15 minutes because ESP-IDF Component Manager downloads dependencies and the project compiles a large C codebase. Incremental builds are normally much faster.

Expected success output includes:

```text
Project build complete. To flash, run:
 idf.py flash
```

Main build artifacts:

| File | Purpose |
|---|---|
| `build/bootloader/bootloader.bin` | Second-stage bootloader |
| `build/partition_table/partition-table.bin` | Partition table |
| `build/pilot_kit_box.bin` | Main application |

## RP2040 Co-processor Firmware (expansion board, optional)

The RP2040 on the v3/v4 expansion boards (the 1090 MHz decoder) is a separate
chip with its own firmware — not an ESP-IDF project. Build it from
`firmware/rp2040/` with `./build.sh`; toolchain requirements, pinned
dependencies, and caveats are documented in
[`../firmware/rp2040/README.md`](../firmware/rp2040/README.md). Flashing and
recovery use BOOTSEL drag-and-drop, covered in
[`firmware_update.md`](firmware_update.md).

## Connect The Board

Use H1, the Type-C port marked `USB TO UART`. It is the CH343P bridge for P4
flashing and monitoring.

The 1090 MHz data path is UART, not USB: the v3/v4 expansion board's RP2040
decodes the pulses and feeds Mode-S frames to the P4 over UART2 at 921600
baud (P4 RX GPIO46 / TX GPIO32, J3 header). The old USB RTL-SDR path (P4
native USB 2.0 HS PHY, carrier USB-A plug or the H2 port on a bare board)
is retired — the firmware and component tree no longer carry it. P1 is the
C6 UART download header, not USB.

### Find The Serial Port

macOS:

```bash
ls -la /dev/cu.usbmodem*
```

Linux:

```bash
ls -la /dev/ttyACM* /dev/ttyUSB*
```

Windows:

Use Device Manager and look under "Ports (COM & LPT)" for the USB serial port.

## Flash And Monitor

macOS / Linux:

```bash
cd firmware
source ~/.espressif/tools/activate_idf_v6.0.1.sh
./build.sh -p /dev/cu.usbmodem5B7B0255751 flash monitor
```

Windows:

```powershell
idf.py -p COM3 flash monitor
```

Exit monitor with `Ctrl-]`.

If automatic reset fails:

1. Hold BOOT.
2. Tap RESET.
3. Release BOOT.
4. Run the flash command again.

## Expected Boot Logs

With the C6 slave already flashed and no optional peripherals attached, a healthy boot should include lines like:

```text
pilot_kit: Pilot Kit Box (ESP32-P4) boot
rec_file: LittleFS mounted at /storage
pk_sd: no microSD card at boot (will keep probing)
display: ST7701 DSI ready: logical 800x480 -> PPA 90 CW -> native 480x800, 2 DPI buffers, app framebuffer 750 KiB PSRAM
pilot_kit: IMU init failed (...) — PFD will run without attitude
pfd: pfd_task running (G1000 landscape)
transport: Identified slave [esp32c6]
ble_gatt: advertising as "Pilot Kit Box-XXXXXX"
pilot_kit: ADS-B link task spawned last (free internal heap: ...)
dsp: adsb_link_task running (UART2 rx=46 tx=32 921600 baud)
```

Optional hardware expectations:

| Action | Expected result |
|---|---|
| Fit the v3/v4 expansion board (1090 MHz) | `dsp: adsb_link_task running (UART2 rx=46 tx=32 921600 baud)` at boot; with pulses reaching the RP2040, the 1 Hz `dsp: link rx/s ...` line appears and DIAG's aircraft list populates |
| Power the integrated 4.3-inch display | 800x480 boot splash appears for at least 3 seconds, then the PFD renders |
| Wire the BNO085 IMU | `imu: rpy = ... (acc=N ...)` logs update and PFD horizon follows motion |
| Fit the GT-U8 module | GPS/BeiDou fix, satellite/SNR, antenna, and system-time rows update on DIAG |
| Fit the BMP388 | PFD and DIAG show pressure, QNH-adjusted altitude, and vertical speed |
| Insert a FAT32 MicroSD card | DIAG shows mounted capacity; select `LOG = MICROSD`, reboot, and confirm logs under `/sdcard` |
| Enable BLE with flashed C6 | BLE scanner sees `Pilot Kit Box-XXXXXX` |

## Troubleshooting

### Bootloader requires chip revision v3.1+

Current Waveshare ESP32-P4-WIFI6 boards are often ESP32-P4 v1.x silicon. Ensure `sdkconfig.defaults` includes:

```text
CONFIG_ESP32P4_SELECTS_REV_LESS_V3=y
CONFIG_ESP32P4_REV_MIN_100=y
```

Then regenerate `sdkconfig` and rebuild.

### ESP-Hosted boots as H2/SPI instead of C6/SDIO

Symptom:

```text
assert failed: spi_mempool_create spi_drv.c:141
```

Cause: ESP-IDF v6.0.1 does not export `ESP_IDF_VERSION` for ESP-Hosted Kconfig. Use `firmware/build.sh`, which sets `ESP_IDF_VERSION=6.0`.

```bash
cd firmware
./build.sh reconfigure
./build.sh build
```

### `ble_transport_ll_init` aborts

The C6 is not responding to ESP-Hosted. Flash the C6 hosted slave firmware first, or disable `CONFIG_PK_BLE_ENABLED`.

### CMD5 `sdmmc_init_ocr: send_op_cond returned 0x107`

On Waveshare ESP32-P4-WIFI6 the C6 reset polarity must be active-high from the P4 software point of view:

```text
CONFIG_ESP_HOSTED_SDIO_RESET_ACTIVE_HIGH=y
```

The C6 SDIO reset line on this board is active-high (verified on real
hardware); keep this default.

### LittleFS mount fails

The partition table may not have been flashed. Run a full erase and flash:

```bash
./build.sh -p <PORT> erase-flash
./build.sh -p <PORT> flash
```

### MicroSD is not used for logs

MicroSD selection is persisted but takes effect only at boot. Insert a
FAT32 card, set `SETTINGS -> LOG` to `MICROSD`, and reboot. If the card
is absent or cannot mount at boot, the writer falls back to LittleFS.
Use DIAG to check card capacity and the active `LOG` backend.

### No ADS-B traffic on the 1090 MHz link

The USB RTL-SDR path is retired (v1/v2-era; the firmware no longer
enumerates dongles). 1090 MHz reception requires the v3/v4 expansion
board: check that it is seated on the carrier's 2×20 header, and that
DIAG's ADS-B link card is not showing `NO_LINK` / `PROTO_MISMATCH`.

## Daily Development Loop

```bash
cd firmware
source ~/.espressif/tools/activate_idf_v6.0.1.sh
./build.sh build
./build.sh -p /dev/cu.usbmodem* flash monitor
```

For faster rebuilds, enable ccache:

```bash
export IDF_CCACHE_ENABLE=1
./build.sh build
```

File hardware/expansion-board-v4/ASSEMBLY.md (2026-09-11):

# V4.5 Manual SMT Placement List

Chinese companion: [`ASSEMBLY-zh_CN.md`](ASSEMBLY-zh_CN.md)

> Generated from the authoritative schematic sheets and PCB coordinates. Do not hand-edit.
> Place by designator and coordinate; the PCB side alone is not a variant rule.

## Assembly variant rule

- Powered variant: populate the power section, but leave R7/R8 DNP.
- Unpowered variant: omit the complete power section and populate both R7/R8.
- Never combine CH224K with R7/R8. See [VARIANTS.md](VARIANTS.md).

## Stage A: Power (39 parts)

| Designator | Value / Model | Footprint | Board position | Rotation | Manual difficulty |
|---|---|---|---|---|---|
| **L17** | 4.7uH XEL4030-472MEC | L_Coilcraft_XxL4030 | (144.8, 95.0) | -90° | ★ Routine |
| **J9** | MX1.25WT-2P BAT | MX1.25WT-2P_1x02-1MP_P1.25 | (144.8, 99.0) | 0° | ★ Routine |
| **U2** | TPS7A2033PDBVR | SOT-23-5 | (82.3, 97.8) | 90° | ★ Exposed leads; hand touch-up possible |
| **U3** | TPS7A2033PDBVR | SOT-23-5 | (89.2, 97.8) | 90° | ★ Exposed leads; hand touch-up possible |
| **RT1** | NCP18XH103F03RB 10k NTC | R_0603_1608Metric | (54.8, 100.9) | 90° | ★ Routine |
| **U1** | ME6211C33M5 | SOT-23-5 | (74.7, 97.8) | 90° | ★ Exposed leads; hand touch-up possible |
| **U18** | CH224K | CH224K_ESSOP-10 | (132.5, 68.6) | 0° | ★ Routine |
| **C77** | 22uF 16V X5R | C_1206_3216Metric | (141.2, 99.7) | -90° | ★ Routine |
| **L16** | 1uH | L_Bourns-SRN4018 | (139.7, 83.6) | -90° | ★ Routine |
| **C71** | 4.7uF(带电源版) | C_0603_1608Metric | (133.4, 79.0) | 90° | ★ Routine |
| **U19** | SY6970 | QFN-24-1EP_4x4mm_P0.5mm_EP | (134.5, 83.7) | 0° | ★★★ Exposed pad; reflow/hot air required |
| **U20** | SY7069 | TSOT-23-6 | (139.2, 95.0) | 0° | ★ Exposed leads; hand touch-up possible |
| **C80** | 1uF 25V | C_0603_1608Metric | (136.3, 74.6) | 180° | ★ Routine |
| **C76** | 22uF | C_1206_3216Metric | (134.4, 96.3) | 180° | ★ Routine |
| **C72** | 10uF | C_1206_3216Metric | (130.9, 79.2) | 90° | ★ Routine |
| **C73** | 10uF | C_0805_2012Metric | (141.3, 88.1) | -90° | ★ Routine |
| **R39** | 5.62k | R_0603_1608Metric | (136.2, 88.2) | 90° | ★ Routine |
| **R40** | 31.6k | R_0603_1608Metric | (134.6, 88.2) | -90° | ★ Routine |
| **R38** | 180R | R_0603_1608Metric | (133.1, 88.2) | -90° | ★ Routine |
| **R42** | 150k | R_0603_1608Metric | (137.4, 98.6) | -90° | ★ Routine |
| **R41** | 470k | R_0603_1608Metric | (139.1, 98.6) | 90° | ★ Routine |
| **C70** | 47nF | C_0603_1608Metric | (135.7, 80.2) | 0° | ★ Routine |
| **R48** | 0R | R_0603_1608Metric | (126.8, 67.0) | 180° | ★ Routine |
| **R49** | 0R | R_0603_1608Metric | (126.8, 69.4) | 180° | ★ Routine |
| **C1** | 10uF | C_0805_2012Metric | (70.8, 96.5) | 180° | ★ Routine |
| **C75** | 10uF | C_0805_2012Metric | (139.1, 88.1) | -90° | ★ Routine |
| **C74** | 10uF | C_0805_2012Metric | (143.3, 84.9) | 90° | ★ Routine |
| **C3** | 1uF | C_0603_1608Metric | (70.8, 98.9) | 180° | ★ Routine |
| **C79** | 1uF | C_0603_1608Metric | (130.6, 65.0) | 0° | ★ Routine |
| **C4** | 1uF | C_0603_1608Metric | (78.7, 97.8) | 0° | ★ Routine |
| **C5** | 1uF | C_0402_1005Metric | (85.9, 96.7) | 0° | ★★ 0402; use low airflow |
| **R46** | 10k | R_0603_1608Metric | (129.2, 86.5) | 180° | ★ Routine |
| **R43** | 1k | R_0603_1608Metric | (127.5, 65.0) | 180° | ★ Routine |
| **R45** | 10k | R_0603_1608Metric | (129.2, 84.0) | 180° | ★ Routine |
| **C6** | 1uF | C_0603_1608Metric | (92.1, 97.9) | 90° | ★ Routine |
| **C2** | 1uF | C_0603_1608Metric | (85.9, 99.1) | 0° | ★ Routine |
| **R37** | 0R | R_0603_1608Metric | (137.0, 66.4) | 90° | ★ Routine |
| **C78** | 1uF | C_0603_1608Metric | (134.4, 94.2) | 180° | ★ Routine |
| **R44** | 10k | R_0603_1608Metric | (137.0, 69.5) | 90° | ★ Routine |

## Stage B: MCU + Flash (29 parts)

| Designator | Value / Model | Footprint | Board position | Rotation | Manual difficulty |
|---|---|---|---|---|---|
| **J4** | USB-C_16P | USB_C_Receptacle_HRO_TYPE- | (145.8, 73.0) | 90° | ★ Routine |
| **Y1** | 12MHz CL=10pF ABM8-272-T3 | Crystal_SMD_3225-4Pin_3.2x | (85.1, 69.1) | 180° | ★ Routine |
| **U8** | RP2040 | QFN-56-1EP_7x7mm_P0.4mm_EP | (86.4, 76.9) | 180° | ★★★ Exposed pad; reflow/hot air required |
| **D4** | TPESD8L3.3 0.3pFtyp 0.5pFmax | D_0402_1005Metric | (139.3, 75.4) | 90° | ★★ 0402; use low airflow |
| **U9** | W25Q128JVSIQ | SOIC-8_5.3x5.3mm_P1.27mm | (93.7, 85.9) | 0° | ★ Exposed leads; hand touch-up possible |
| **D5** | TPESD8L3.3 0.3pFtyp 0.5pFmax | D_0402_1005Metric | (139.3, 77.8) | 0° | ★★ 0402; use low airflow |
| **C20** | 15pF C0G | C_0603_1608Metric | (79.8, 69.1) | 90° | ★ Routine |
| **C87** | 10nF C0G | C_0603_1608Metric | (83.5, 88.5) | 90° | ★ Routine |
| **C19** | 15pF C0G | C_0603_1608Metric | (88.4, 69.1) | -90° | ★ Routine |
| **C26** | 100nF | C_0603_1608Metric | (78.9, 74.6) | 180° | ★ Routine |
| **C22** | 100nF | C_0603_1608Metric | (93.2, 75.8) | 0° | ★ Routine |
| **C23** | 100nF | C_0603_1608Metric | (91.8, 81.5) | 0° | ★ Routine |
| **C27** | 100nF | C_0603_1608Metric | (77.9, 82.5) | 180° | ★ Routine |
| **C82** | 100nF | C_0603_1608Metric | (91.4, 67.5) | 0° | ★ Routine |
| **C24** | 100nF | C_0603_1608Metric | (80.9, 80.2) | 90° | ★ Routine |
| **C86** | 100nF | C_0603_1608Metric | (123.2, 89.6) | 0° | ★ Routine |
| **C85** | 100nF | C_0603_1608Metric | (113.7, 80.5) | 0° | ★ Routine |
| **C83** | 100nF | C_0603_1608Metric | (91.4, 69.8) | 0° | ★ Routine |
| **C25** | 100nF | C_0603_1608Metric | (83.2, 71.6) | 180° | ★ Routine |
| **R50** | 30k | R_0603_1608Metric | (86.5, 92.8) | 0° | ★ Routine |
| **R6** | 10k | R_0603_1608Metric | (87.9, 86.4) | 90° | ★ Routine |
| **R4** | 1k | R_0603_1608Metric | (82.0, 69.1) | 90° | ★ Routine |
| **C84** | 1uF | C_0603_1608Metric | (110.7, 80.5) | 0° | ★ Routine |
| **R9** | 27R | R_0603_1608Metric | (87.9, 83.3) | -90° | ★ Routine |
| **R10** | 27R | R_0603_1608Metric | (85.3, 83.3) | -90° | ★ Routine |
| **R51** | 10k | R_0603_1608Metric | (85.5, 88.5) | 90° | ★ Routine |
| **C28** | 1uF | C_0603_1608Metric | (83.1, 83.3) | -90° | ★ Routine |
| **R5** | 10k | R_0603_1608Metric | (80.0, 73.2) | 180° | ★ Routine |
| **C29** | 1uF | C_0603_1608Metric | (80.9, 83.3) | -90° | ★ Routine |

## Stage C: Sensors + GNSS (33 parts)

| Designator | Value / Model | Footprint | Board position | Rotation | Manual difficulty |
|---|---|---|---|---|---|
| **U7** | ATGM336H-6N-74 | ATGM336H_LCC-18 | (73.7, 89.1) | 0° | ★★★ Exposed pad; reflow/hot air required |
| **J2** | U.FL_GNSS_EXT(经尾线转SMA) | U.FL_Hirose_U.FL-R-SMT-1_V | (54.0, 75.9) | 180° | ★ Routine |
| **J8** | U.FL→内置patch | U.FL_Hirose_U.FL-R-SMT-1_V | (54.0, 69.2) | 180° | ★ Routine |
| **U4** | BNO085 | BNO085_LGA-28 | (59.7, 84.5) | 90° | ★★★ Exposed pad; reflow/hot air required |
| **U6** | QMC5883P | LGA-16_3x3mm_P0.5mm | (59.7, 96.5) | -90° | ★★★ Exposed pad; reflow/hot air required |
| **Q4** | AO3401A | SOT-23 | (63.5, 75.9) | 180° | ★ Exposed leads; hand touch-up possible |
| **Q5** | AO3401A | SOT-23 | (63.5, 69.2) | 180° | ★ Exposed leads; hand touch-up possible |
| **U17** | XA17-G4K | SOT-363_SC-70-6 | (68.6, 78.1) | 90° | ★ Exposed leads; hand touch-up possible |
| **U5** | BMP388 | BMP388_LGA-10 | (61.0, 88.9) | -90° | ★★★ Exposed pad; reflow/hot air required |
| **F5** | 6V/200mA | Fuse_0805_2012Metric | (60.3, 69.2) | -90° | ★ Routine |
| **F4** | 6V/200mA | Fuse_0805_2012Metric | (60.3, 75.9) | 90° | ★ Routine |
| **C13** | 100nF | C_0603_1608Metric | (59.1, 92.6) | 90° | ★ Routine |
| **C17** | 100nF | C_0603_1608Metric | (71.4, 81.0) | 90° | ★ Routine |
| **C11** | 100nF | C_0603_1608Metric | (64.6, 87.2) | 180° | ★ Routine |
| **C12** | 100nF | C_0603_1608Metric | (56.5, 87.7) | 180° | ★ Routine |
| **C18** | 10uF | C_0805_2012Metric | (74.4, 80.8) | 90° | ★ Routine |
| **C57** | 100pF | C_0402_1005Metric | (68.3, 81.0) | 90° | ★★ 0402; use low airflow |
| **R55** | 10k | R_0603_1608Metric | (57.4, 89.8) | 0° | ★ Routine |
| **C10** | 100nF | C_0603_1608Metric | (61.0, 92.6) | 90° | ★ Routine |
| **C14** | 100nF | C_0603_1608Metric | (64.6, 89.9) | 180° | ★ Routine |
| **C16** | 100nF | C_0603_1608Metric | (64.6, 92.5) | 180° | ★ Routine |
| **R3** | 4.7k | R_0603_1608Metric | (64.1, 95.2) | 180° | ★ Routine |
| **R2** | 4.7k | R_0603_1608Metric | (64.1, 97.8) | 180° | ★ Routine |
| **R1** | 10k | R_0603_1608Metric | (55.2, 84.5) | -90° | ★ Routine |
| **C15** | 4.7uF | C_0603_1608Metric | (59.9, 99.3) | 0° | ★ Routine |
| **R27** | 10k | R_0603_1608Metric | (67.3, 71.1) | 0° | ★ Routine |
| **R26** | 10k | R_0603_1608Metric | (67.3, 73.7) | 0° | ★ Routine |
| **C58** | 100pF | C_0402_1005Metric | (57.7, 76.5) | 0° | ★★ 0402; use low airflow |
| **C59** | 100pF | C_0402_1005Metric | (57.6, 69.8) | 0° | ★★ 0402; use low airflow |
| **R52** | 10k | R_0402_1005Metric | (64.4, 85.0) | 90° | ★★ 0402; use low airflow |
| **L15** | 33nH | L_0402_1005Metric | (57.6, 68.7) | 180° | ★★ 0402; use low airflow |
| **L2** | 33nH | L_0402_1005Metric | (57.7, 75.4) | 180° | ★★ 0402; use low airflow |
| **R53** | 10k | R_0402_1005Metric | (64.3, 83.0) | 180° | ★★ 0402; use low airflow |

## Stage D: 978 Transceiver (34 parts)

| Designator | Value / Model | Footprint | Board position | Rotation | Manual difficulty |
|---|---|---|---|---|---|
| **U10** | CC1312R1F3RGZR | QFN-48-1EP_7x7mm_P0.5mm_EP | (104.5, 92.0) | 180° | ★★★ Exposed pad; reflow/hot air required |
| **Y3** | 32.768kHz FC-135 | Crystal_SMD_3215-2Pin_3.2x | (111.6, 87.0) | 0° | ★ Routine |
| **Y2** | 48MHz ABM8W-7pF | Crystal_SMD_3225-4Pin_3.2x | (108.3, 98.3) | 90° | ★ Routine |
| **D3** | TPESD8L3.3 0.3pFtyp 0.5pFmax | D_0402_1005Metric | (117.5, 89.9) | -90° | ★★ 0402; use low airflow |
| **J5** | U.FL_978 | U.FL_Hirose_U.FL-R-SMT-1_V | (118.5, 86.3) | 90° | ★ Routine |
| **Q2** | AO3401A | SOT-23 | (121.9, 95.8) | 90° | ★ Exposed leads; hand touch-up possible |
| **F2** | 6V/200mA | Fuse_0805_2012Metric | (121.9, 92.5) | 180° | ★ Routine |
| **C61** | 100nF | C_0603_1608Metric | (102.7, 99.1) | 180° | ★ Routine |
| **C63** | 100nF | C_0603_1608Metric | (107.1, 84.6) | 90° | ★ Routine |
| **C65** | 100nF | C_0603_1608Metric | (99.0, 94.7) | -90° | ★ Routine |
| **L10** | 27nH | L_0402_1005Metric | (110.9, 95.7) | 90° | ★★ 0402; use low airflow |
| **C62** | 100nF | C_0603_1608Metric | (105.4, 98.3) | -90° | ★ Routine |
| **C60** | 22uF | C_0805_2012Metric | (99.3, 98.0) | 90° | ★ Routine |
| **C66** | 22uF | C_0805_2012Metric | (102.9, 97.2) | 180° | ★ Routine |
| **C45** | 100pF | C_0402_1005Metric | (110.7, 90.2) | 0° | ★★ 0402; use low airflow |
| **C39** | 100pF | C_0402_1005Metric | (118.2, 92.8) | 90° | ★★ 0402; use low airflow |
| **L11** | 6.8nH | L_0402_1005Metric | (118.2, 97.5) | 90° | ★★ 0402; use low airflow |
| **L12** | 6.8nH | L_0402_1005Metric | (118.2, 95.2) | 90° | ★★ 0402; use low airflow |
| **C68** | 18pF | C_0603_1608Metric | (113.2, 85.0) | 0° | ★ Routine |
| **C42** | 6.2pF | C_0402_1005Metric | (115.9, 95.2) | 90° | ★★ 0402; use low airflow |
| **C41** | 2.7pF | C_0402_1005Metric | (115.9, 97.5) | 90° | ★★ 0402; use low airflow |
| **C40** | 3.6pF | C_0402_1005Metric | (110.7, 94.2) | 0° | ★★ 0402; use low airflow |
| **R47** | 10k | R_0603_1608Metric | (98.5, 91.7) | 0° | ★ Routine |
| **L7** | 6.8uH | L_0805_2012Metric | (97.3, 94.7) | -90° | ★ Routine |
| **C64** | 100nF | C_0603_1608Metric | (100.2, 85.8) | 180° | ★ Routine |
| **L8** | 100nH | L_0402_1005Metric | (119.3, 90.3) | 180° | ★★ 0402; use low airflow |
| **R56** | 10k | R_0603_1608Metric | (98.5, 90.0) | 0° | ★ Routine |
| **C67** | 1uF | C_0603_1608Metric | (103.6, 85.8) | 0° | ★ Routine |
| **R17** | 10k | R_0603_1608Metric | (121.8, 98.7) | 180° | ★ Routine |
| **C69** | 18pF | C_0603_1608Metric | (110.1, 85.0) | 180° | ★ Routine |
| **L13** | 7.5nH | L_0402_1005Metric | (110.7, 92.2) | 180° | ★★ 0402; use low airflow |
| **L9** | 7.5nH | L_0402_1005Metric | (112.3, 94.8) | 90° | ★★ 0402; use low airflow |
| **C43** | 3pF | C_0402_1005Metric | (115.9, 92.8) | 90° | ★★ 0402; use low airflow |
| **C44** | 3.6pF | C_0402_1005Metric | (112.8, 96.5) | 0° | ★★ 0402; use low airflow |

## Stage E: 1090 Receive Chain (49 parts)

| Designator | Value / Model | Footprint | Board position | Rotation | Manual difficulty |
|---|---|---|---|---|---|
| **J6** | U.FL_1090_EXT(经尾线转SMA) | U.FL_Hirose_U.FL-R-SMT-1_V | (106.5, 67.3) | 90° | ★ Routine |
| **J7** | U.FL_IFA_TEST(π后调试口) | U.FL_Hirose_U.FL-R-SMT-1_V | (90.0, 61.3) | 90° | ★ Routine |
| **U15** | TLV3501(TOKMAS) | SOT-23-6 | (100.6, 79.5) | 180° | ★ Exposed leads; hand touch-up possible |
| **D2** | TPESD8L3.3 0.3pFtyp 0.5pFmax | D_0402_1005Metric | (101.1, 72.6) | 180° | ★★ 0402; use low airflow |
| **U11** | QPL9547TR7 | DFN-8-1EP_2x2mm_P0.5mm_EP0 | (107.7, 61.9) | 0° | ★★★ Exposed pad; reflow/hot air required |
| **U14** | AD8313ARMZ | MSOP-8_3x3mm_P0.65mm | (111.1, 73.4) | 180° | ★ Exposed leads; hand touch-up possible |
| **FL2** | TA0970A | TA0970A_SMD3838-6 | (118.4, 66.5) | 180° | ★★★ Exposed pad; reflow/hot air required |
| **L1** | 18nH 0402CS-18NXGRW | L_0402_1005Metric | (110.4, 59.8) | 90° | ★★ 0402; use low airflow |
| **FL1** | TA0970A | TA0970A_SMD3838-6 | (112.0, 65.5) | 0° | ★★★ Exposed pad; reflow/hot air required |
| **Q3** | AO3401A | SOT-23 | (95.3, 71.7) | 0° | ★ Exposed leads; hand touch-up possible |
| **C31** | 100pF C0G | C_0402_1005Metric | (111.3, 62.2) | -90° | ★★ 0402; use low airflow |
| **U16** | XA17-G4K | SOT-363_SC-70-6 | (98.0, 62.9) | 90° | ★ Exposed leads; hand touch-up possible |
| **C34** | 100pF C0G | C_0402_1005Metric | (117.1, 73.4) | -90° | ★★ 0402; use low airflow |
| **C33** | 100pF C0G | C_0402_1005Metric | (120.4, 63.2) | 0° | ★★ 0402; use low airflow |
| **C32** | 100pF C0G | C_0402_1005Metric | (114.3, 62.2) | 90° | ★★ 0402; use low airflow |
| **F3** | 6V/200mA | Fuse_0805_2012Metric | (98.3, 71.7) | 90° | ★ Routine |
| **U12** | BGA2817 | SOT-363_SC-70-6 | (117.1, 62.5) | 90° | ★ Exposed leads; hand touch-up possible |
| **C81** | 470pF C0G | C_0402_1005Metric | (115.2, 64.5) | -90° | ★★ 0402; use low airflow |
| **C35** | 100pF C0G | C_0402_1005Metric | (115.1, 71.1) | 90° | ★★ 0402; use low airflow |
| **C55** | 100pF | C_0603_1608Metric | (97.6, 66.5) | 90° | ★ Routine |
| **ZS1** | 0R 串 | L_0603_1608Metric | (81.7, 62.9) | 0° | ★ Routine |
| **L14** | 100nH | L_0402_1005Metric | (101.1, 70.6) | 0° | ★★ 0402; use low airflow |
| **C36** | 100pF | C_0402_1005Metric | (106.0, 64.3) | 90° | ★★ 0402; use low airflow |
| **C47** | 200pF | C_0603_1608Metric | (104.9, 80.4) | 0° | ★ Routine |
| **C21** | 100pF | C_0402_1005Metric | (103.6, 59.7) | 90° | ★★ 0402; use low airflow |
| **C30** | 100pF | C_0402_1005Metric | (102.8, 67.5) | 90° | ★★ 0402; use low airflow |
| **R57** | 33R | R_0603_1608Metric | (104.0, 82.5) | 0° | ★ Routine |
| **C49** | 100nF | C_0603_1608Metric | (76.7, 75.4) | -90° | ★ Routine |
| **C56** | 100pF | C_0603_1608Metric | (95.0, 66.5) | -90° | ★ Routine |
| **R18** | 10k | R_0603_1608Metric | (91.4, 71.4) | 180° | ★ Routine |
| **R31** | 1k | R_0603_1608Metric | (101.6, 75.7) | 0° | ★ Routine |
| **R34** | 10k | R_0603_1608Metric | (77.0, 73.2) | 0° | ★ Routine |
| **R35** | 10k | R_0603_1608Metric | (77.0, 78.4) | 0° | ★ Routine |
| **R22** | 0R | R_0603_1608Metric | (100.3, 66.5) | 90° | ★ Routine |
| **C46** | 3pF | C_0603_1608Metric | (104.9, 78.5) | 0° | ★ Routine |
| **R54** | 10R | R_0402_1005Metric | (116.5, 77.0) | 90° | ★★ 0402; use low airflow |
| **C52** | 100nF | C_0402_1005Metric | (99.6, 82.3) | -90° | ★★ 0402; use low airflow |
| **C54** | 100pF | C_0402_1005Metric | (103.9, 61.7) | 0° | ★★ 0402; use low airflow |
| **C38** | 100pF | C_0402_1005Metric | (111.6, 77.0) | -90° | ★★ 0402; use low airflow |
| **C53** | 100pF | C_0402_1005Metric | (93.6, 62.9) | 0° | ★★ 0402; use low airflow |
| **C37** | 100nF | C_0402_1005Metric | (113.9, 77.0) | -90° | ★★ 0402; use low airflow |
| **R33** | 100k | R_0603_1608Metric | (100.9, 82.7) | 90° | ★ Routine |
| **R19** | 52.3R | R_0402_1005Metric | (115.1, 73.4) | 90° | ★★ 0402; use low airflow |
| **R11** | 3.32k | R_0402_1005Metric | (105.1, 59.7) | 0° | ★★ 0402; use low airflow |
| **R32** | 10k | R_0603_1608Metric | (104.9, 75.7) | 180° | ★ Routine |
| **C51** | 1nF | C_0603_1608Metric | (77.0, 81.0) | 180° | ★ Routine |
| **R21** | 0R | R_0603_1608Metric | (105.0, 72.6) | 180° | ★ Routine |
| **R23** | 0R | R_0603_1608Metric | (93.2, 77.2) | 0° | ★ Routine |
| **C48** | 1uF | C_0402_1005Metric | (107.4, 64.3) | 90° | ★★ 0402; use low airflow |

## Stage F: External Interface (1 parts)

| Designator | Value / Model | Footprint | Board position | Rotation | Manual difficulty |
|---|---|---|---|---|---|
| **J1** | J3_HAT_2x20_SMD排针 | PinHeader_2x20_P2.54mm_Ver | (92.6, 106.3) | 90° | ★ Routine |

## Stage G: Airband (19 parts)

BK4819 airband receive + 26MHz TCXO + PCM1808 capture (new in V4.6, independent of the 1090/978 chains).

| Designator | Value / Model | Footprint | Board position | Rotation | Manual difficulty |
|---|---|---|---|---|---|
| **J10** | U.FL_VHF (pigtail to SMA) | U.FL_Hirose_U.FL-R-SMT-1_V | (125.8, 89.2) | 90° | ★ Routine |
| **Y4** | 26MHz TCXO <=2.5ppm | Crystal_SMD_2520-4Pin_2.5x | (132.5, 99.0) | 180° | ★ Routine |
| **U21** | BK4819QN32SC | QFN-32-1EP_4x4mm_P0.4mm_EP | (127.5, 97.6) | 180° | ★★★ Exposed pad; reflow/hot air required |
| **U22** | PCM1808PWR | TSSOP-14_4.4x5mm_P0.65mm | (122.8, 105.3) | 0° | ★ Routine |
| **D6** | TPESD8L3.3 0.3pFtyp 0.5pFmax | D_0402_1005Metric | (129.4, 89.0) | 180° | ★★ 0402 — easily blown away by hot air; lower the airflow |
| **C88** | 100pF | C_0603_1608Metric | (129.3, 91.1) | -90° | ★ Routine |
| **C95** | 100nF | C_0603_1608Metric | (120.5, 101.5) | 0° | ★ Routine |
| **C96** | 100nF | C_0603_1608Metric | (127.6, 102.2) | 90° | ★ Routine |
| **L18** | 100nH | L_0402_1005Metric | (126.0, 93.9) | 0° | ★★ 0402 — easily blown away by hot air; lower the airflow |
| **R59** | 10k | R_0603_1608Metric | (132.5, 105.6) | 0° | ★ Routine |
| **C89** | 18pF | C_0603_1608Metric | (128.7, 93.9) | 180° | ★ Routine |
| **C97** | 1uF | C_0603_1608Metric | (129.4, 102.2) | 90° | ★ Routine |
| **C98** | 100nF | C_0603_1608Metric | (131.2, 102.2) | 90° | ★ Routine |
| **C94** | 100nF | C_0603_1608Metric | (120.5, 109.4) | 0° | ★ Routine |
| **C91** | 10uF | C_0805_2012Metric | (129.0, 108.2) | 0° | ★ Routine |
| **C93** | 10uF | C_0805_2012Metric | (124.2, 109.4) | 0° | ★ Routine |
| **C92** | 10uF | C_0805_2012Metric | (136.2, 108.2) | 0° | ★ Routine |
| **R60** | 0R | R_0603_1608Metric | (124.0, 101.5) | 0° | ★ Routine |
| **R58** | 10k | R_0603_1608Metric | (132.5, 108.2) | 0° | ★ Routine |

## Not placed (22 positions)

| Designator | Reason |
|---|---|
| **ANT1** | 板载天线，PCB铜箔本身，无器件。50.0mm外包络/48.5mm中心线；V4.0装盒实测1082.5MHz、SWR 1.09 |
| **H1** | M2.5 安装孔（⌀2.7mm NPTH），不是元件 |
| **H2** | M2.5 安装孔（⌀2.7mm NPTH），不是元件 |
| **H3** | M2.5 安装孔（⌀2.7mm NPTH），不是元件 |
| **H4** | M2.5 安装孔（⌀2.7mm NPTH），不是元件 |
| **R7** | DNP，设计上默认不贴（5.1k DNP(带电源版)） |
| **R8** | DNP，设计上默认不贴（5.1k DNP(带电源版)） |
| **R24** | DNP，设计上默认不贴（0R DNP(旁路外接)） |
| **R25** | DNP，设计上默认不贴（0R DNP(旁路板载)） |
| **R30** | DNP，设计上默认不贴（1k DNP） |
| **R36** | DNP，设计上默认不贴（1k DNP） |
| **SW1** | 短接焊盘（BOOTSEL），用镊子短接，不贴件。**焊盘不占 SMT 贴装面数**，成本影响为 0 |
| **SW2** | 短接焊盘（BOOTSEL），用镊子短接，不贴件。**焊盘不占 SMT 贴装面数**，成本影响为 0 |
| **TP1** | 测试点焊盘，探针/飞线用，不贴件 |
| **TP2** | 测试点焊盘，探针/飞线用，不贴件 |
| **TP3** | 测试点焊盘，探针/飞线用，不贴件 |
| **TP4** | 测试点焊盘，探针/飞线用，不贴件 |
| **TP5** | 测试点焊盘，探针/飞线用，不贴件 |
| **TP6** | 测试点焊盘，探针/飞线用，不贴件 |
| **TP7** | 测试点焊盘，探针/飞线用，不贴件 |
| **ZP1** | DNP，设计上默认不贴（DNP 并-天线侧） |
| **ZP2** | DNP，设计上默认不贴（DNP 并-电台侧） |

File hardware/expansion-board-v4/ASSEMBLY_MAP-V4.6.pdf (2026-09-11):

# Pilot Kit Expansion Board V4.6 Assembly Map — Powered Variant (Top View)

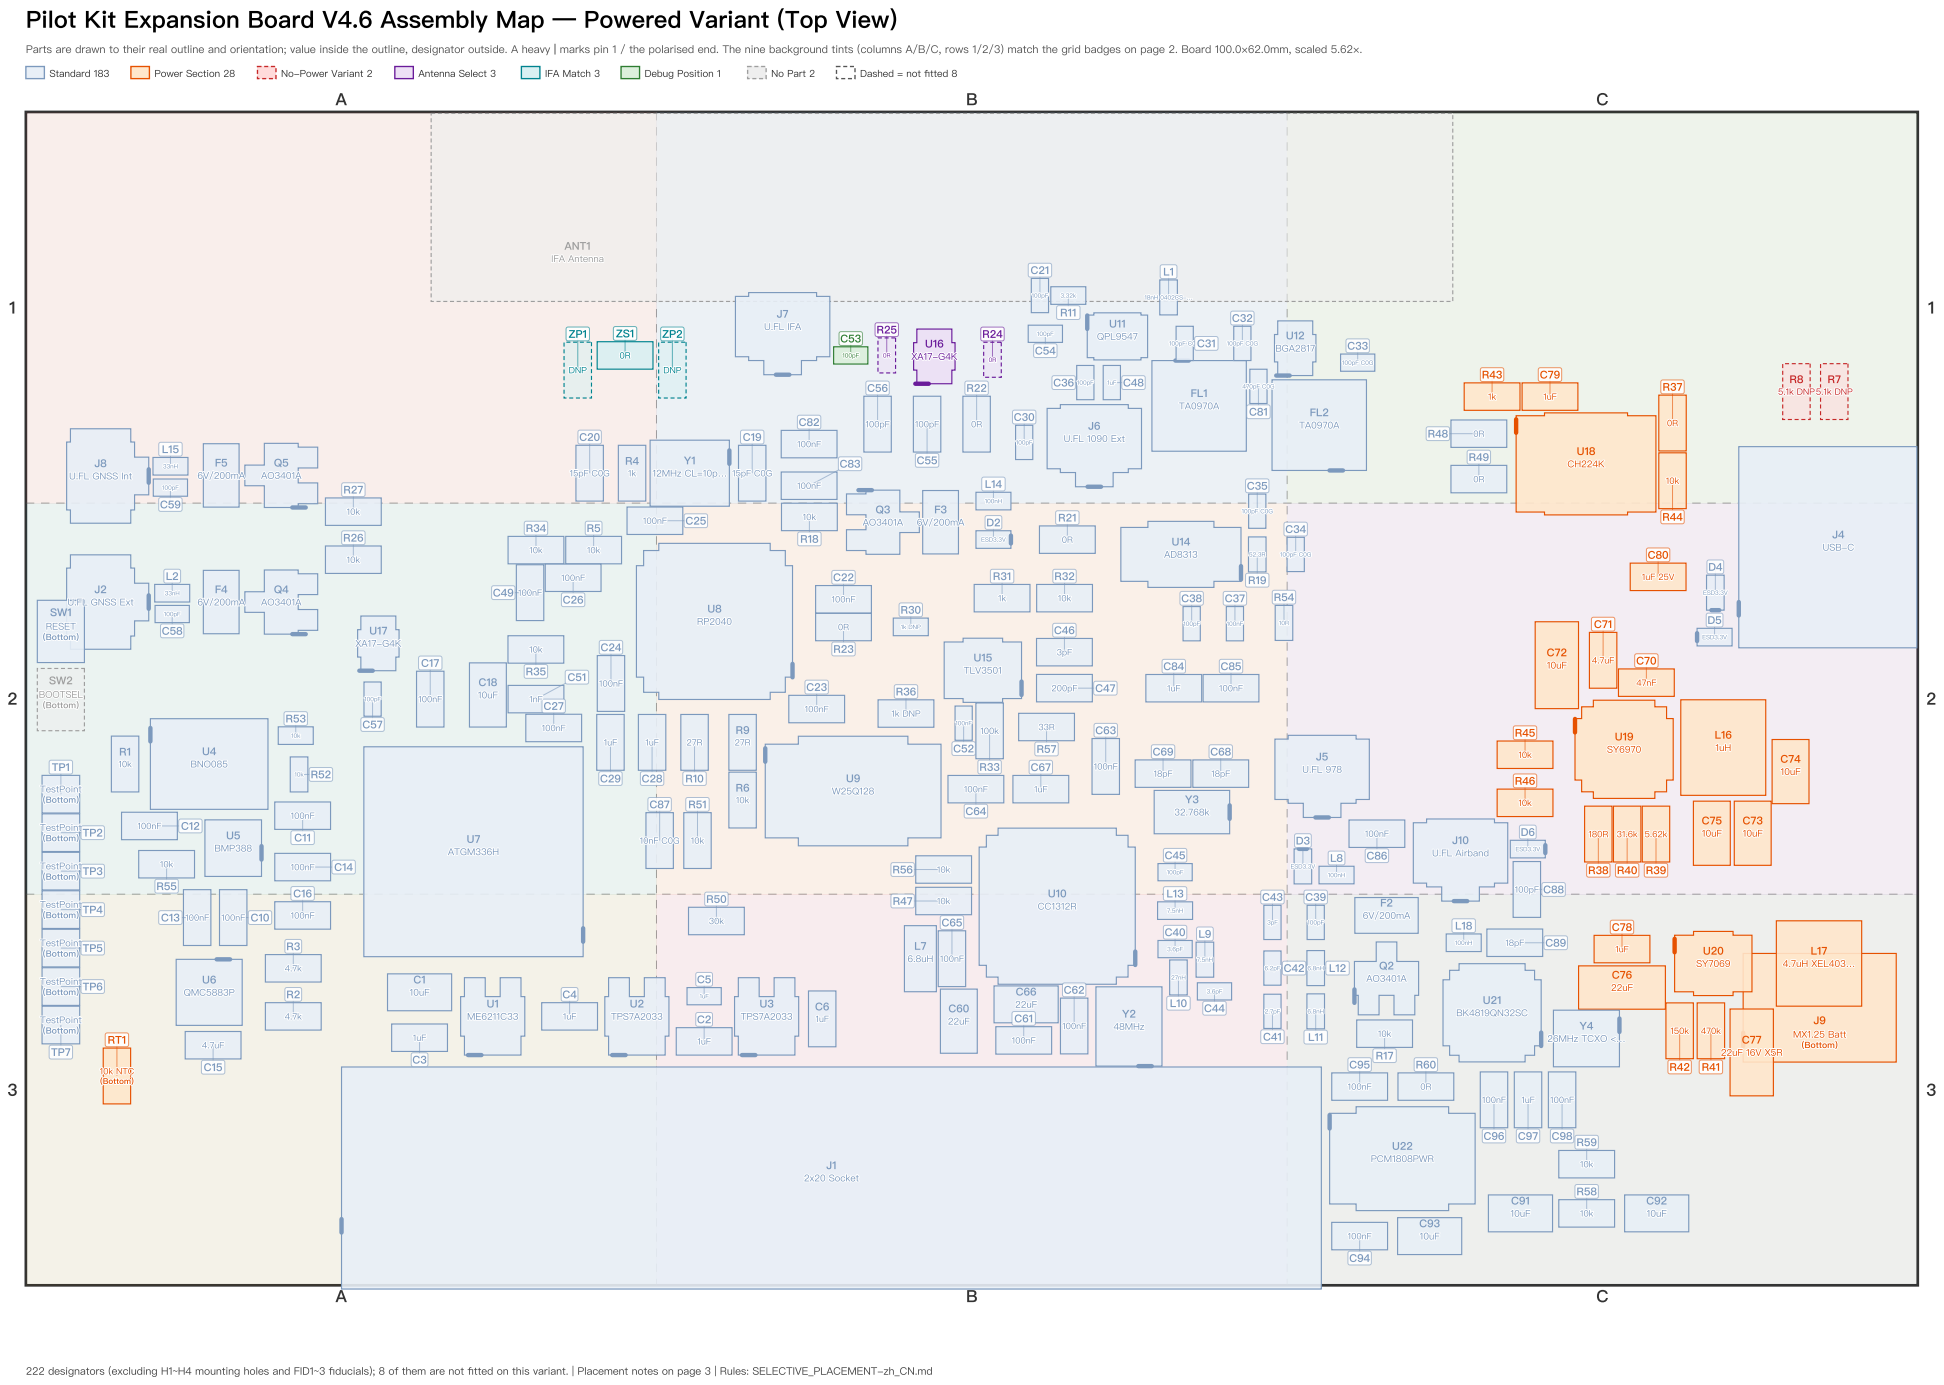
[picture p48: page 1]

Parts are drawn to their real outline and orientation; value inside the outline, designator outside. A heavy | marks pin 1 / the polarised end. The nine background tints (columns A/B/C, rows 1/2/3) match the grid badges on page 2. Board 100.0×62.0mm, scaled 5.62×.

U.FL GNSS Int

222 designators (excluding H1~H4 mounting holes and FID1~3 fiducials); 8 of them are not fitted on this variant. | Placement notes on page 3 | Rules: SELECTIVE_PLACEMENT-zh_CN.md

# Pilot Kit Expansion Board V4.6 Designator Index — Grid Reference

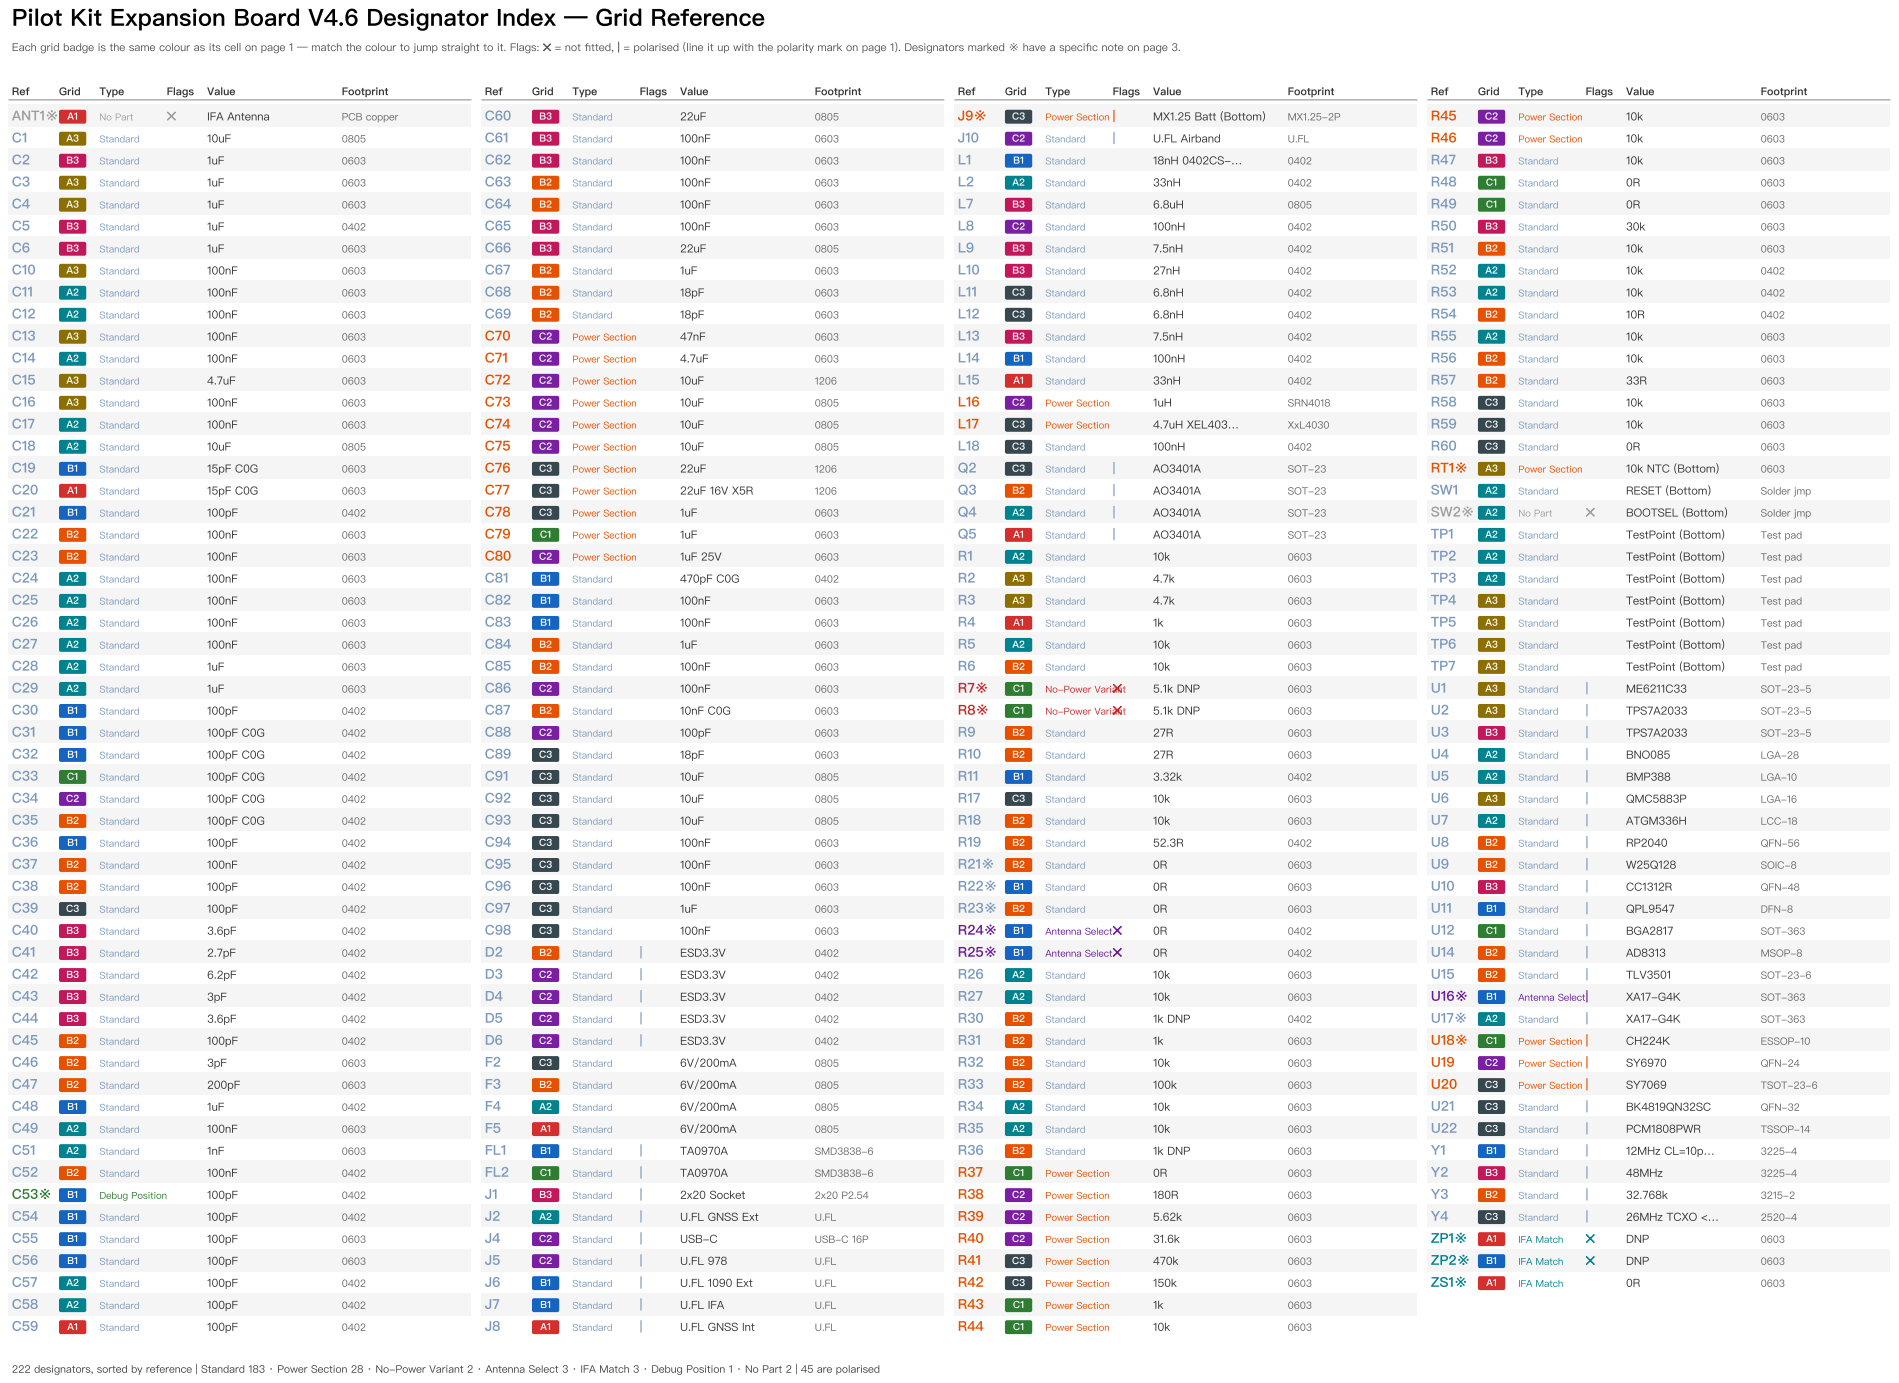
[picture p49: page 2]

Each grid badge is the same colour as its cell on page 1 — match the colour to jump straight to it. Flags: ✕ = not fitted, | = polarised (line it up with the polarity mark on page 1). Designators marked ※ have a specific note on page 3.

222 designators, sorted by reference | Standard 183 · Power Section 28 · No-Power Variant 2 · Antenna Select 3 · IFA Match 3 · Debug Position 1 · No Part 2 | 45 are polarised

# Pilot Kit Expansion Board V4.6 Selective Placement Notes

Standard parts are fitted unconditionally and are not listed here. Every class below carries a precondition; getting it wrong breaks the function or the board — full reasoning in SELECTIVE_PLACEMENT-zh_CN.md.

No-Power Variant (2 parts, default here: DNP)

5.1k CC pull-downs, fitted on the no-power variant only. Together with U18 (CH224K) they skew the CC resistance, so PD negotiation may request 9V/12V into a board designed for 5V. Both sit i nside a NO-PWR VER silkscreen box.
R7 5.1k DNP [DNP] Not fitted on this (powered) variant
R8 5.1k DNP [DNP] Not fitted on this (powered) variant

Antenna Select (3 parts, default here: See notes)

Three mutually exclusive ways to route the 1090 antenna path — fit at most one. R24+R25 together short the external antenna to the on-board IFA; U16 plus either bypass shorts a switch port. R24 0R [DNP] 0R bypass → hard-wires the external antenna; not fitted here
R25 0R [DNP] 0R bypass → hard-wires the on-board IFA; not fitted here
U16 XA17-G4K [Fit] RF switch (default option) — this is the one to fit

IFA Match (3 parts, default here: See notes)

Pi matching network for the on-board IFA. The three positions combine freely into an L or pi network and are not exclusive. The default ZS1=0R is a straight-through link, not a tuned match — final values come from a VNA sweep with the enclosure fitted.
ZP1 DNP [DNP] Shunt, antenna side; not fitted by default
ZP2 DNP [DNP] Shunt, radio side; not fitted by default. First sweep starts at 3.3pF
ZS1 0R [Fit] Series position, default 0R link; start the first sweep at 3.6nH

Debug Position (1 parts, default here: Fit)

Normally fitted; removed only for one specific measurement.
C53 100pF [Fit] Remove before sweeping the IFA through J7, otherwise the VNA sees the switch and everything behind it instead of the antenna. Refit after

Power Section (28 parts, default here: Fit)

Fitted on the powered variant only. On the no-power variant this whole group is omitted and R7/R8 are fitted instead. J9 MX1.25 Batt [Fit] Battery connector, on the bottom side
RT1 10k NTC [Fit] NTC for battery temperature sensing, on the bottom side
U18 CH224K [Fit] CH224K USB-C PD sink controller; it provides the CC pull-down internally
Others in this class: C70, C71, C72, C73, C74, C75, C76, C77, C78, C79, C80, L16, L17, R37, R38, R39, R40, R41, R42, R43, R44, R45, R46, U19, U20

No Part (2 parts, default here: —)

Bare copper or a solder-bridge jumper — there is no part to fit.
ANT1 IFA Antenna [DNP] The on-board IFA — it is the PCB copper itself
SW2 BOOTSEL [DNP] BOOTSEL solder bridge, short it with tweezers; on the bottom side

Standard (183 parts, default here: Fit)

This whole class is fitted unconditionally; only the few with an extra caveat are listed. The remaining 179 just get fitted. R21 0R [Fit] 0R link; open it to probe the AD8313 detector output on its own
R22 0R [Fit] 0R link; open it to drive the 1090 switch A pin by hand
R23 0R [Fit] 0R link; open it to drive the 1090 switch B pin by hand
U17 XA17-G4K [Fit] GNSS-side RF switch. There is no bypass resistor on this side, so leaving it out means no signal path at all
Rules: SELECTIVE_PLACEMENT-zh_CN.md | This board: powered variant

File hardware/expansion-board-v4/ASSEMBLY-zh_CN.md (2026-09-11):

# V4.6 手工贴片点位清单
> 由内部工具从原理图分页 + PCB 坐标自动生成——**不要手改这份文件**，改板后会被重新生成覆盖。

配套看图：板上位置 `render/top.png`，丝印和 pin1 `render/silk.svg`。

## ⚠️ 装配前先确认做哪个版本

同一块 PCB 出两个版本，**有一组件是「电源区不贴时才贴」的反向逻辑**，最容易装错，动手前先对一遍：

| | 电源区（U18/U19/U20/L16/L17/J9/RT1/C70-C80/R37-R46） | F 面 `R7`/`R8`（5.1k CC 下拉） |
|---|---|---|
| **带电源版** | ✅ 全贴 | ❌ **不贴** |
| **不带电源版** | ❌ 一个都不贴 | ✅ **必贴** |

**为什么是反的**：USB-C 要被主机识别，CC 脚上必须有 Rd(5.1k)。带电源版由 CH224K 内部提供，此时外挂 R7/R8 会让 CC 阻值错乱、干扰 PD 协商；不带电源版没有 CH224K，不贴 R7/R8 则 CC 悬空，**插上电脑毫无反应、没法用 UF2 刷 RP2040 固件**。

板上 `R7`/`R8` 周围印了一个丝印框，旁边标 `NO-PWR VER`——**框里的件只有不带电源版才贴**。

⚠️ 这组件**曾经整片在 B 面**，「不铺 B 面」定为原则后 26 件已搬到 F 面，只剩 `J9`(电池座) 和 `RT1`(NTC，必须贴着电池测温) 留在 B 面。旧文档里「B 面电源区」的说法已作废——别按面别找件，按位号找。

**SMT 下单面数**（B 面只剩 3 个位置，两版都能走单面）：

| 版本 | B 面贴装件 | 下单方式 |
|---|---|---|
| **不带电源版** | 0 个（`J9`/`RT1` 属电源区不贴，`SW2` 是焊盘跳线不贴料）| 单面 SMT，经济型 |
| **带电源版** | 2 个（`J9` 连接器 + `RT1` 0603）| 单面 SMT + 这 2 个手焊，比开 B 面钢网便宜；要省事也可按双面下 |

详见 [VARIANTS.md](VARIANTS.md)。

## IFA 已按V4.0实板逐刀VNA结果定型

生成器、封装库、`ifa_geom.py`和PCB内嵌ANT1已统一为48.5mm中心线/50.0mm铜箔外包络；V4.0实板由53.5mm逐刀切短、50.0mm停刀，装盒+电池在1082.5MHz测得SWR 1.09、45+j0.5Ω，拆盒读数在1080–1090MHz间漂移；同序列斜率24–25MHz/mm。taper、5.103mm馈电路径、π网络和J7保持不变；本次数据对应ZS1=0R、ZP1/ZP2=DNP直通状态。后续板材、外壳或相对位置变化仍需复测。

---

## 位号丝印自检：0 对互换（无问题 ✅）

判据是「站在元件旁边，最近的那个位号文字是不是它自己的」。
反过来按「文字找最近元件」会漏——被大芯片挡住的那几个就是这么漏掉的。

位号对调这种错**目检、DRC、Gerber 预览全都发现不了**：每个元件旁边都有位号、排版看着完全正常，只是内容张冠李戴。所以要靠这个检测。

---

## 开工前

**先做完 `BOARD_TEST.md` 的阶段 1、2。** 裸板的电源对地绝缘和内层连通性
一旦贴了片就测不了了——去耦电容和芯片会并联在电源地之间，读数不再是开路。

### 顺序原则：先大后小，先中间后外围

不管整板回流还是逐个热风吹，结论一样：

- **整板回流**——大件对位要反复调整，周围先摆了 0402 会被镊子碰歪

- **逐个热风**——吹外围时热风会掀翻已贴好的小件；大件热容大，反过来不怕

所以下面每个阶段内部**按封装面积从大到小排**，照着表从上往下贴就行。

### 几个容易吃亏的点

- **BNO085 / BMP388 / CC1312R 这类塑封件怕潮**。拆封超过一周的，贴之前 125°C 烘 4 小时，不然回流时内部水汽汽化会把封装顶裂（爆米花效应），外观完全看不出来，表现是芯片直接不工作
- **底部焊盘的件（★★★）烙铁够不着**，吹歪了只能拆下来重来，所以对位要在加热前反复确认，别指望后期补救
- **0402 风量一定调小**，标称的风量吹 0402 会直接把件吹飞，而且飞走的件常常落在别的焊盘上造成短路
- **pin1 方向以板上丝印为准**（缺角/圆点），下表的「旋转」只是参考。这块板的元件朝向前期出过错——曾经有 25 个两脚件的 pin1/pin2 方向是反的

---

## 阶段 A：电源（39 件）
3 个 LDO 加各路的输入输出电容，**这 9 件自成闭环**，贴完就能上电量电压，不用碰任何贵件。

| 位号 | 型号 | 封装 | 板上位置 | 旋转 | 手工难度 |
|---|---|---|---|---|---|
| **L17** | 4.7uH XEL4030-472MEC | L_Coilcraft_XxL4030 | (144.8, 95.0) | -90° | ★ 常规 |
| **J9** | MX1.25WT-2P BAT | MX1.25WT-2P_1x02-1MP_P1.25 | (144.8, 99.0) | 0° | ★ 常规 |
| **U3** | TPS7A2033PDBVR | SOT-23-5 | (89.2, 97.8) | 90° | ★ 引脚在外，烙铁可补焊 |
| **U2** | TPS7A2033PDBVR | SOT-23-5 | (82.3, 97.8) | 90° | ★ 引脚在外，烙铁可补焊 |
| **RT1** | NCP18XH103F03RB 10k NTC | R_0603_1608Metric | (54.8, 100.9) | 90° | ★ 常规 |
| **U1** | ME6211C33M5 | SOT-23-5 | (74.7, 97.8) | 90° | ★ 引脚在外，烙铁可补焊 |
| **U18** | CH224K | CH224K_ESSOP-10 | (132.5, 68.6) | 0° | ★ 常规 |
| **C77** | 22uF 16V X5R | C_1206_3216Metric | (141.2, 99.7) | -90° | ★ 常规 |
| **L16** | 1uH | L_Bourns-SRN4018 | (139.7, 83.6) | -90° | ★ 常规 |
| **C71** | 4.7uF(带电源版) | C_0603_1608Metric | (133.4, 79.0) | 90° | ★ 常规 |
| **U19** | SY6970 | QFN-24-1EP_4x4mm_P0.5mm_EP | (134.5, 83.7) | 0° | ★★★ 底部焊盘，只能热风，烙铁够不着 |
| **U20** | SY7069 | TSOT-23-6 | (139.2, 95.0) | 0° | ★ 引脚在外，烙铁可补焊 |
| **C80** | 1uF 25V | C_0603_1608Metric | (136.3, 74.6) | 180° | ★ 常规 |
| **C76** | 22uF | C_1206_3216Metric | (134.4, 96.3) | 180° | ★ 常规 |
| **C72** | 10uF | C_1206_3216Metric | (130.9, 79.2) | 90° | ★ 常规 |
| **C73** | 10uF | C_0805_2012Metric | (141.3, 88.1) | -90° | ★ 常规 |
| **R39** | 5.62k | R_0603_1608Metric | (136.2, 88.2) | 90° | ★ 常规 |
| **R40** | 31.6k | R_0603_1608Metric | (134.6, 88.2) | -90° | ★ 常规 |
| **R38** | 180R | R_0603_1608Metric | (133.1, 88.2) | -90° | ★ 常规 |
| **R42** | 150k | R_0603_1608Metric | (137.4, 98.6) | -90° | ★ 常规 |
| **R41** | 470k | R_0603_1608Metric | (139.1, 98.6) | 90° | ★ 常规 |
| **C70** | 47nF | C_0603_1608Metric | (135.7, 80.2) | 0° | ★ 常规 |
| **R48** | 0R | R_0603_1608Metric | (126.8, 67.0) | 180° | ★ 常规 |
| **R49** | 0R | R_0603_1608Metric | (126.8, 69.4) | 180° | ★ 常规 |
| **C1** | 10uF | C_0805_2012Metric | (70.8, 96.5) | 180° | ★ 常规 |
| **C74** | 10uF | C_0805_2012Metric | (143.3, 84.9) | 90° | ★ 常规 |
| **C75** | 10uF | C_0805_2012Metric | (139.1, 88.1) | -90° | ★ 常规 |
| **C3** | 1uF | C_0603_1608Metric | (70.8, 98.9) | 180° | ★ 常规 |
| **C79** | 1uF | C_0603_1608Metric | (130.6, 65.0) | 0° | ★ 常规 |
| **C4** | 1uF | C_0603_1608Metric | (78.7, 97.8) | 0° | ★ 常规 |
| **C5** | 1uF | C_0402_1005Metric | (85.9, 96.7) | 0° | ★★  0402，热风易吹跑，风量调小 |
| **R44** | 10k | R_0603_1608Metric | (137.0, 69.5) | 90° | ★ 常规 |
| **C78** | 1uF | C_0603_1608Metric | (134.4, 94.2) | 180° | ★ 常规 |
| **C6** | 1uF | C_0603_1608Metric | (92.1, 97.9) | 90° | ★ 常规 |
| **R37** | 0R | R_0603_1608Metric | (137.0, 66.4) | 90° | ★ 常规 |
| **R45** | 10k | R_0603_1608Metric | (129.2, 84.0) | 180° | ★ 常规 |
| **R46** | 10k | R_0603_1608Metric | (129.2, 86.5) | 180° | ★ 常规 |
| **C2** | 1uF | C_0603_1608Metric | (85.9, 99.1) | 0° | ★ 常规 |
| **R43** | 1k | R_0603_1608Metric | (127.5, 65.0) | 180° | ★ 常规 |

**贴完验证**：实验电源限流 100mA，5V 正极夹 `J1.1`、负极夹 `U10.49`（CC1312R 的 EP 大焊盘，此时还没贴件，焊盘是空的正好夹）。
  - 空载电流应该只有几 mA；一上电顶到限流就断电查 U1/U2/U3 有没有连锡
  - `U9.8` 量 3V3_DIG = 3.3V ±5%
  - `U14.1` 量 3V3_RF = 3.3V ±5%
  - `Q2.2` 量 3V3_GNSS = 3.3V ±5%
  三路都对了才往下走。这一步没过，后面贴什么都是白贴。

## 阶段 B：MCU + Flash（29 件）
RP2040 + QSPI Flash + 12MHz 晶振 + USB-C 座。

| 位号 | 型号 | 封装 | 板上位置 | 旋转 | 手工难度 |
|---|---|---|---|---|---|
| **J4** | USB-C_16P | USB_C_Receptacle_HRO_TYPE- | (145.8, 73.0) | 90° | ★ 常规 |
| **Y1** | 12MHz CL=10pF ABM8-272-T3 | Crystal_SMD_3225-4Pin_3.2x | (85.1, 69.1) | 180° | ★ 常规 |
| **U8** | RP2040 | QFN-56-1EP_7x7mm_P0.4mm_EP | (86.4, 76.9) | 180° | ★★★ 底部焊盘，只能热风，烙铁够不着 |
| **D4** | TPESD8L3.3 0.3pFtyp 0.5pFmax | D_0402_1005Metric | (139.3, 75.4) | 90° | ★★  0402，热风易吹跑，风量调小 |
| **U9** | W25Q128JVSIQ | SOIC-8_5.3x5.3mm_P1.27mm | (93.7, 85.9) | 0° | ★ 引脚在外，烙铁可补焊 |
| **D5** | TPESD8L3.3 0.3pFtyp 0.5pFmax | D_0402_1005Metric | (139.3, 77.8) | 0° | ★★  0402，热风易吹跑，风量调小 |
| **C20** | 15pF C0G | C_0603_1608Metric | (79.8, 69.1) | 90° | ★ 常规 |
| **C87** | 10nF C0G | C_0603_1608Metric | (83.5, 88.5) | 90° | ★ 常规 |
| **C19** | 15pF C0G | C_0603_1608Metric | (88.4, 69.1) | -90° | ★ 常规 |
| **C26** | 100nF | C_0603_1608Metric | (78.9, 74.6) | 180° | ★ 常规 |
| **C22** | 100nF | C_0603_1608Metric | (93.2, 75.8) | 0° | ★ 常规 |
| **C23** | 100nF | C_0603_1608Metric | (91.8, 81.5) | 0° | ★ 常规 |
| **C82** | 100nF | C_0603_1608Metric | (91.4, 67.5) | 0° | ★ 常规 |
| **C27** | 100nF | C_0603_1608Metric | (77.9, 82.5) | 180° | ★ 常规 |
| **C24** | 100nF | C_0603_1608Metric | (80.9, 80.2) | 90° | ★ 常规 |
| **C86** | 100nF | C_0603_1608Metric | (121.4, 88.1) | 0° | ★ 常规 |
| **C85** | 100nF | C_0603_1608Metric | (113.7, 80.5) | 0° | ★ 常规 |
| **C83** | 100nF | C_0603_1608Metric | (91.4, 69.8) | 0° | ★ 常规 |
| **C25** | 100nF | C_0603_1608Metric | (83.2, 71.6) | 180° | ★ 常规 |
| **R50** | 30k | R_0603_1608Metric | (86.5, 92.8) | 0° | ★ 常规 |
| **R6** | 10k | R_0603_1608Metric | (87.9, 86.4) | 90° | ★ 常规 |
| **R4** | 1k | R_0603_1608Metric | (82.0, 69.1) | 90° | ★ 常规 |
| **C84** | 1uF | C_0603_1608Metric | (110.7, 80.5) | 0° | ★ 常规 |
| **R10** | 27R | R_0603_1608Metric | (85.3, 83.3) | -90° | ★ 常规 |
| **R9** | 27R | R_0603_1608Metric | (87.9, 83.3) | -90° | ★ 常规 |
| **R5** | 10k | R_0603_1608Metric | (80.0, 73.2) | 180° | ★ 常规 |
| **R51** | 10k | R_0603_1608Metric | (85.5, 88.5) | 90° | ★ 常规 |
| **C29** | 1uF | C_0603_1608Metric | (80.9, 83.3) | -90° | ★ 常规 |
| **C28** | 1uF | C_0603_1608Metric | (83.1, 83.3) | -90° | ★ 常规 |

**贴完验证**：USB-C 插电脑，镊子短接 `SW2`(BOOTSEL) 再上电 → 电脑应出现 **RPI-RP2** U 盘。
  - 认不到 U 盘：先量 `C28.1` 上的 RP_1V1 有没有 1.1V（RP2040 内部 LDO 出的）
  - 认到了但 Flash 不识别：查 U9 的四条 QSPI 线，SOIC-8 引脚在外，烙铁能补

## 阶段 C：传感器 + GNSS（33 件）
IMU / 气压 / 磁力计 / GNSS，都是 I2C 和 UART 慢速接口。

| 位号 | 型号 | 封装 | 板上位置 | 旋转 | 手工难度 |
|---|---|---|---|---|---|
| **U7** | ATGM336H-6N-74 | ATGM336H_LCC-18 | (73.7, 89.1) | 0° | ★★★ 底部焊盘，只能热风，烙铁够不着 |
| **J2** | U.FL_GNSS_EXT(经尾线转SMA) | U.FL_Hirose_U.FL-R-SMT-1_V | (54.0, 75.9) | 180° | ★ 常规 |
| **J8** | U.FL→内置patch | U.FL_Hirose_U.FL-R-SMT-1_V | (54.0, 69.2) | 180° | ★ 常规 |
| **U4** | BNO085 | BNO085_LGA-28 | (59.7, 84.5) | 90° | ★★★ 底部焊盘，只能热风，烙铁够不着 |
| **U6** | QMC5883P | LGA-16_3x3mm_P0.5mm | (59.7, 96.5) | -90° | ★★★ 底部焊盘，只能热风，烙铁够不着 |
| **Q5** | AO3401A | SOT-23 | (63.5, 69.2) | 180° | ★ 引脚在外，烙铁可补焊 |
| **Q4** | AO3401A | SOT-23 | (63.5, 75.9) | 180° | ★ 引脚在外，烙铁可补焊 |
| **U17** | XA17-G4K | SOT-363_SC-70-6 | (68.6, 78.1) | 90° | ★★  0.65mm 间距，引脚在外但很密 |
| **U5** | BMP388 | BMP388_LGA-10 | (61.0, 88.9) | -90° | ★★★ 底部焊盘，只能热风，烙铁够不着 |
| **F4** | 6V/200mA | Fuse_0805_2012Metric | (60.3, 75.9) | 90° | ★ 常规 |
| **F5** | 6V/200mA | Fuse_0805_2012Metric | (60.3, 69.2) | -90° | ★ 常规 |
| **C13** | 100nF | C_0603_1608Metric | (59.1, 92.6) | 90° | ★ 常规 |
| **C17** | 100nF | C_0603_1608Metric | (71.4, 81.0) | 90° | ★ 常规 |
| **C11** | 100nF | C_0603_1608Metric | (64.6, 87.2) | 180° | ★ 常规 |
| **C12** | 100nF | C_0603_1608Metric | (56.5, 87.7) | 180° | ★ 常规 |
| **C18** | 10uF | C_0805_2012Metric | (74.4, 80.8) | 90° | ★ 常规 |
| **C57** | 100pF | C_0402_1005Metric | (68.3, 81.0) | 90° | ★★  0402，热风易吹跑，风量调小 |
| **R55** | 10k | R_0603_1608Metric | (57.4, 89.8) | 0° | ★ 常规 |
| **C10** | 100nF | C_0603_1608Metric | (61.0, 92.6) | 90° | ★ 常规 |
| **C16** | 100nF | C_0603_1608Metric | (64.6, 92.5) | 180° | ★ 常规 |
| **C14** | 100nF | C_0603_1608Metric | (64.6, 89.9) | 180° | ★ 常规 |
| **R2** | 4.7k | R_0603_1608Metric | (64.1, 97.8) | 180° | ★ 常规 |
| **R3** | 4.7k | R_0603_1608Metric | (64.1, 95.2) | 180° | ★ 常规 |
| **R1** | 10k | R_0603_1608Metric | (55.2, 84.5) | -90° | ★ 常规 |
| **C15** | 4.7uF | C_0603_1608Metric | (59.9, 99.3) | 0° | ★ 常规 |
| **R27** | 10k | R_0603_1608Metric | (67.3, 71.1) | 0° | ★ 常规 |
| **R26** | 10k | R_0603_1608Metric | (67.3, 73.7) | 0° | ★ 常规 |
| **C58** | 100pF | C_0402_1005Metric | (57.7, 76.5) | 0° | ★★  0402，热风易吹跑，风量调小 |
| **C59** | 100pF | C_0402_1005Metric | (57.6, 69.8) | 0° | ★★  0402，热风易吹跑，风量调小 |
| **R52** | 10k | R_0402_1005Metric | (64.4, 85.0) | 90° | ★★  0402，热风易吹跑，风量调小 |
| **L15** | 33nH | L_0402_1005Metric | (57.6, 68.7) | 180° | ★★  0402，热风易吹跑，风量调小 |
| **L2** | 33nH | L_0402_1005Metric | (57.7, 75.4) | 180° | ★★  0402，热风易吹跑，风量调小 |
| **R53** | 10k | R_0402_1005Metric | (64.3, 83.0) | 180° | ★★  0402，热风易吹跑，风量调小 |

**贴完验证**：刷个扫描固件，I2C 上逐个点名：BNO085、BMP388、QMC5883P 应各自应答。
  - GNSS 看 `U7.2`(GNSS_TXD) 有没有 NMEA 输出，**室内收不到星是正常的**，有 `$GPTXT` 和 `$GPGSV` 输出就说明模块活着

## 阶段 D：978 收发（34 件）
CC1312R 和它的 48MHz / 32.768kHz 两颗晶振。

| 位号 | 型号 | 封装 | 板上位置 | 旋转 | 手工难度 |
|---|---|---|---|---|---|
| **U10** | CC1312R1F3RGZR | QFN-48-1EP_7x7mm_P0.5mm_EP | (104.5, 92.0) | 180° | ★★★ 底部焊盘，只能热风，烙铁够不着 |
| **Y3** | 32.768kHz FC-135 | Crystal_SMD_3215-2Pin_3.2x | (111.6, 87.0) | 0° | ★ 常规 |
| **Y2** | 48MHz ABM8W-7pF | Crystal_SMD_3225-4Pin_3.2x | (108.3, 98.3) | 90° | ★ 常规 |
| **D3** | TPESD8L3.3 0.3pFtyp 0.5pFmax | D_0402_1005Metric | (117.5, 89.9) | -90° | ★★  0402，热风易吹跑，风量调小 |
| **J5** | U.FL_978 | U.FL_Hirose_U.FL-R-SMT-1_V | (118.5, 84.7) | 90° | ★ 常规 |
| **Q2** | AO3401A | SOT-23 | (121.9, 95.8) | 90° | ★ 引脚在外，烙铁可补焊 |
| **F2** | 6V/200mA | Fuse_0805_2012Metric | (121.9, 92.5) | 180° | ★ 常规 |
| **C61** | 100nF | C_0603_1608Metric | (102.7, 99.1) | 180° | ★ 常规 |
| **C63** | 100nF | C_0603_1608Metric | (107.1, 84.6) | 90° | ★ 常规 |
| **C65** | 100nF | C_0603_1608Metric | (99.0, 94.7) | -90° | ★ 常规 |
| **L10** | 27nH | L_0402_1005Metric | (110.9, 95.7) | 90° | ★★  0402，热风易吹跑，风量调小 |
| **C62** | 100nF | C_0603_1608Metric | (105.4, 98.3) | -90° | ★ 常规 |
| **C60** | 22uF | C_0805_2012Metric | (99.3, 98.0) | 90° | ★ 常规 |
| **C66** | 22uF | C_0805_2012Metric | (102.9, 97.2) | 180° | ★ 常规 |
| **C39** | 100pF | C_0402_1005Metric | (118.2, 92.8) | 90° | ★★  0402，热风易吹跑，风量调小 |
| **C45** | 100pF | C_0402_1005Metric | (110.7, 90.2) | 0° | ★★  0402，热风易吹跑，风量调小 |
| **R17** | 10k | R_0603_1608Metric | (121.8, 98.7) | 180° | ★ 常规 |
| **L12** | 6.8nH | L_0402_1005Metric | (118.2, 95.2) | 90° | ★★  0402，热风易吹跑，风量调小 |
| **L11** | 6.8nH | L_0402_1005Metric | (118.2, 97.5) | 90° | ★★  0402，热风易吹跑，风量调小 |
| **C68** | 18pF | C_0603_1608Metric | (113.2, 85.0) | 0° | ★ 常规 |
| **C41** | 2.7pF | C_0402_1005Metric | (115.9, 97.5) | 90° | ★★  0402，热风易吹跑，风量调小 |
| **C42** | 6.2pF | C_0402_1005Metric | (115.9, 95.2) | 90° | ★★  0402，热风易吹跑，风量调小 |
| **C40** | 3.6pF | C_0402_1005Metric | (110.7, 94.2) | 0° | ★★  0402，热风易吹跑，风量调小 |
| **R47** | 10k | R_0603_1608Metric | (98.5, 91.7) | 0° | ★ 常规 |
| **L7** | 6.8uH | L_0805_2012Metric | (97.3, 94.7) | -90° | ★ 常规 |
| **C64** | 100nF | C_0603_1608Metric | (100.2, 85.8) | 180° | ★ 常规 |
| **L8** | 100nH | L_0402_1005Metric | (119.3, 90.3) | 180° | ★★  0402，热风易吹跑，风量调小 |
| **R56** | 10k | R_0603_1608Metric | (98.5, 90.0) | 0° | ★ 常规 |
| **C67** | 1uF | C_0603_1608Metric | (103.6, 85.8) | 0° | ★ 常规 |
| **C69** | 18pF | C_0603_1608Metric | (110.1, 85.0) | 180° | ★ 常规 |
| **L9** | 7.5nH | L_0402_1005Metric | (112.3, 94.8) | 90° | ★★  0402，热风易吹跑，风量调小 |
| **L13** | 7.5nH | L_0402_1005Metric | (110.7, 92.2) | 180° | ★★  0402，热风易吹跑，风量调小 |
| **C43** | 3pF | C_0402_1005Metric | (115.9, 92.8) | 90° | ★★  0402，热风易吹跑，风量调小 |
| **C44** | 3.6pF | C_0402_1005Metric | (112.8, 96.5) | 0° | ★★  0402，热风易吹跑，风量调小 |

**贴完验证**：~~接调试器到 TP1/TP2~~ —— **V4 已删除 SWD 测试点**。改用以下任一：
  ① 在已打样的 v3.2 上验证同一段电路（两版此处电路逐条相同）；
  ② 从 RP2040 的 SWCLK/SWDIO 引脚（U8.24 / U8.25）飞线接调试器；
  ③ 刷入固件后由 RP2040 自己读 CC1312R 的 ID，通过 UART 打印。
  - 起不来先量 `C60.1` 的 SUBG_VDDR（内部 DC/DC 输出，约 1.7V）和 `C67.1` 的 SUBG_DCOUPL（约 1.28V）

## 阶段 E：1090 接收链（49 件）
**全板最贵的一段**（QPL9547 ¥8.5 / TA0970A ¥7.5×2 / AD8313），排最后——前面四级都验过了才让它们上板。

| 位号 | 型号 | 封装 | 板上位置 | 旋转 | 手工难度 |
|---|---|---|---|---|---|
| **J6** | U.FL_1090_EXT(经尾线转SMA) | U.FL_Hirose_U.FL-R-SMT-1_V | (106.5, 67.3) | 90° | ★ 常规 |
| **J7** | U.FL_IFA_TEST(π后调试口) | U.FL_Hirose_U.FL-R-SMT-1_V | (90.0, 61.3) | 90° | ★ 常规 |
| **U15** | TLV3501(TOKMAS) | SOT-23-6 | (100.6, 79.5) | 180° | ★ 引脚在外，烙铁可补焊 |
| **D2** | TPESD8L3.3 0.3pFtyp 0.5pFmax | D_0402_1005Metric | (101.1, 72.6) | 180° | ★★  0402，热风易吹跑，风量调小 |
| **U11** | QPL9547TR7 | DFN-8-1EP_2x2mm_P0.5mm_EP0 | (107.7, 61.9) | 0° | ★★★ 底部焊盘，只能热风，烙铁够不着 |
| **U14** | AD8313ARMZ | MSOP-8_3x3mm_P0.65mm | (111.1, 73.4) | 180° | ★ 引脚在外，烙铁可补焊 |
| **FL2** | TA0970A | TA0970A_SMD3838-6 | (118.4, 66.5) | 180° | ★★★ 底部焊盘，只能热风，烙铁够不着 |
| **L1** | 18nH 0402CS-18NXGRW | L_0402_1005Metric | (110.4, 59.8) | 90° | ★★  0402，热风易吹跑，风量调小 |
| **FL1** | TA0970A | TA0970A_SMD3838-6 | (112.0, 65.5) | 0° | ★★★ 底部焊盘，只能热风，烙铁够不着 |
| **Q3** | AO3401A | SOT-23 | (95.3, 71.7) | 0° | ★ 引脚在外，烙铁可补焊 |
| **C31** | 100pF C0G | C_0402_1005Metric | (111.3, 62.2) | -90° | ★★  0402，热风易吹跑，风量调小 |
| **U16** | XA17-G4K | SOT-363_SC-70-6 | (98.0, 62.9) | 90° | ★★  0.65mm 间距，引脚在外但很密 |
| **C34** | 100pF C0G | C_0402_1005Metric | (117.1, 73.4) | -90° | ★★  0402，热风易吹跑，风量调小 |
| **C33** | 100pF C0G | C_0402_1005Metric | (120.4, 63.2) | 0° | ★★  0402，热风易吹跑，风量调小 |
| **C32** | 100pF C0G | C_0402_1005Metric | (114.3, 62.2) | 90° | ★★  0402，热风易吹跑，风量调小 |
| **F3** | 6V/200mA | Fuse_0805_2012Metric | (98.3, 71.7) | 90° | ★ 常规 |
| **U12** | BGA2817 | SOT-363_SC-70-6 | (117.1, 62.5) | 90° | ★★  0.65mm 间距，引脚在外但很密 |
| **C81** | 470pF C0G | C_0402_1005Metric | (115.2, 64.5) | -90° | ★★  0402，热风易吹跑，风量调小 |
| **C35** | 100pF C0G | C_0402_1005Metric | (115.1, 71.1) | 90° | ★★  0402，热风易吹跑，风量调小 |
| **C55** | 100pF | C_0603_1608Metric | (97.6, 66.5) | 90° | ★ 常规 |
| **ZS1** | 0R 串 | L_0603_1608Metric | (81.7, 62.9) | 0° | ★ 常规 |
| **L14** | 100nH | L_0402_1005Metric | (101.1, 70.6) | 0° | ★★  0402，热风易吹跑，风量调小 |
| **C36** | 100pF | C_0402_1005Metric | (106.0, 64.3) | 90° | ★★  0402，热风易吹跑，风量调小 |
| **C47** | 200pF | C_0603_1608Metric | (104.9, 80.4) | 0° | ★ 常规 |
| **C21** | 100pF | C_0402_1005Metric | (103.6, 59.7) | 90° | ★★  0402，热风易吹跑，风量调小 |
| **C30** | 100pF | C_0402_1005Metric | (102.8, 67.5) | 90° | ★★  0402，热风易吹跑，风量调小 |
| **R57** | 33R | R_0603_1608Metric | (104.0, 82.5) | 0° | ★ 常规 |
| **C49** | 100nF | C_0603_1608Metric | (76.7, 75.4) | -90° | ★ 常规 |
| **C56** | 100pF | C_0603_1608Metric | (95.0, 66.5) | -90° | ★ 常规 |
| **R18** | 10k | R_0603_1608Metric | (91.4, 71.4) | 180° | ★ 常规 |
| **R31** | 1k | R_0603_1608Metric | (101.6, 75.7) | 0° | ★ 常规 |
| **R34** | 10k | R_0603_1608Metric | (77.0, 73.2) | 0° | ★ 常规 |
| **R35** | 10k | R_0603_1608Metric | (77.0, 78.4) | 0° | ★ 常规 |
| **R22** | 0R | R_0603_1608Metric | (100.3, 66.5) | 90° | ★ 常规 |
| **C46** | 3pF | C_0603_1608Metric | (104.9, 78.5) | 0° | ★ 常规 |
| **R54** | 10R | R_0402_1005Metric | (116.5, 77.0) | 90° | ★★  0402，热风易吹跑，风量调小 |
| **C54** | 100pF | C_0402_1005Metric | (103.9, 61.7) | 0° | ★★  0402，热风易吹跑，风量调小 |
| **C38** | 100pF | C_0402_1005Metric | (111.6, 77.0) | -90° | ★★  0402，热风易吹跑，风量调小 |
| **C37** | 100nF | C_0402_1005Metric | (113.9, 77.0) | -90° | ★★  0402，热风易吹跑，风量调小 |
| **C53** | 100pF | C_0402_1005Metric | (93.6, 62.9) | 0° | ★★  0402，热风易吹跑，风量调小 |
| **C52** | 100nF | C_0402_1005Metric | (99.6, 82.3) | -90° | ★★  0402，热风易吹跑，风量调小 |
| **R33** | 100k | R_0603_1608Metric | (100.9, 82.7) | 90° | ★ 常规 |
| **R19** | 52.3R | R_0402_1005Metric | (115.1, 73.4) | 90° | ★★  0402，热风易吹跑，风量调小 |
| **R11** | 3.32k | R_0402_1005Metric | (105.1, 59.7) | 0° | ★★  0402，热风易吹跑，风量调小 |
| **C51** | 1nF | C_0603_1608Metric | (77.0, 81.0) | 180° | ★ 常规 |
| **R23** | 0R | R_0603_1608Metric | (93.2, 77.2) | 0° | ★ 常规 |
| **R21** | 0R | R_0603_1608Metric | (105.0, 72.6) | 180° | ★ 常规 |
| **R32** | 10k | R_0603_1608Metric | (104.9, 75.7) | 180° | ★ 常规 |
| **C48** | 1uF | C_0402_1005Metric | (107.4, 64.3) | 90° | ★★  0402，热风易吹跑，风量调小 |

**贴完验证**：~~TP3~TP6 / TP7 接示波器~~ —— **V4 已删除这些测试点**。改用：
  ① 直接探 `U15.5`(PULSES)，SOT-23-6 引脚表笔能搭上；
  ② 软件遥测 RSSI(ADC1) / LEVEL_BIAS(ADC0)，固件通过 UART 打印读数与解码成功率；
  ③ 要看 PIO 状态机本身，在 v3.2 上做（那块板保留了全部 7 个测试点）。
  - 射频件方向错了很难看出来，贴之前对着 `render/silk.svg` 核一遍 pin1

## 阶段 F：对外接口（1 件）
2×20 排针，热容量大。

| 位号 | 型号 | 封装 | 板上位置 | 旋转 | 手工难度 |
|---|---|---|---|---|---|
| **J1** | J3_HAT_2x20_SMD排针 | PinHeader_2x20_P2.54mm_Ver | (92.6, 106.3) | 90° | ★ 常规 |

**贴完验证**：跟主板对插，量 5V 和 GND 通断。**放最后**：先贴上它，前面几阶段板子就没法平放在加热台上了。

## 阶段 G：航空波段 AIRBAND（19 件）
BK4819 航空接收 + 26MHz TCXO + PCM1808 采集（V4.6 新增，独立于 1090/978）。

| 位号 | 型号 | 封装 | 板上位置 | 旋转 | 手工难度 |
|---|---|---|---|---|---|
| **J10** | U.FL_VHF(经尾线转SMA) | U.FL_Hirose_U.FL-R-SMT-1_V | (125.8, 89.2) | 90° | ★ 常规 |
| **Y4** | 26MHz TCXO <=2.5ppm | Crystal_SMD_2520-4Pin_2.5x | (132.5, 99.0) | 180° | ★ 常规 |
| **U21** | BK4819QN32SC | QFN-32-1EP_4x4mm_P0.4mm_EP | (127.5, 97.6) | 180° | ★★★ 底部焊盘，只能热风，烙铁够不着 |
| **U22** | PCM1808PWR | TSSOP-14_4.4x5mm_P0.65mm | (122.8, 105.3) | 0° | ★ 常规 |
| **D6** | TPESD8L3.3 0.3pFtyp 0.5pFmax | D_0402_1005Metric | (129.4, 89.0) | 180° | ★★  0402，热风易吹跑，风量调小 |
| **C88** | 100pF | C_0603_1608Metric | (129.3, 91.1) | -90° | ★ 常规 |
| **C95** | 100nF | C_0603_1608Metric | (120.5, 101.5) | 0° | ★ 常规 |
| **C96** | 100nF | C_0603_1608Metric | (127.6, 102.2) | 90° | ★ 常规 |
| **L18** | 100nH | L_0402_1005Metric | (126.0, 93.9) | 0° | ★★  0402，热风易吹跑，风量调小 |
| **R59** | 10k | R_0603_1608Metric | (132.5, 105.6) | 0° | ★ 常规 |
| **C89** | 18pF | C_0603_1608Metric | (128.7, 93.9) | 180° | ★ 常规 |
| **C97** | 1uF | C_0603_1608Metric | (129.4, 102.2) | 90° | ★ 常规 |
| **C98** | 100nF | C_0603_1608Metric | (131.2, 102.2) | 90° | ★ 常规 |
| **C94** | 100nF | C_0603_1608Metric | (120.5, 109.4) | 0° | ★ 常规 |
| **C91** | 10uF | C_0805_2012Metric | (129.0, 108.2) | 0° | ★ 常规 |
| **C93** | 10uF | C_0805_2012Metric | (124.2, 109.4) | 0° | ★ 常规 |
| **C92** | 10uF | C_0805_2012Metric | (136.2, 108.2) | 0° | ★ 常规 |
| **R60** | 0R | R_0603_1608Metric | (124.0, 101.5) | 0° | ★ 常规 |
| **R58** | 10k | R_0603_1608Metric | (132.5, 108.2) | 0° | ★ 常规 |

**贴完验证**：刷固件后：① 诊断页看 BK4819 3线SPI 通信与频率锁定；② 接天线收 118–137 话音，经 PCM1808 → I2S → P4，BLE 推 app 出声；③ 108–118 VOR 需平坦模式下 P4 DSP。
  - 收不到先量 `U21.3/11` 的 3V3_RF 和 `Y4.4`；
  - 音频不出：查 `U21.8`(EARO) → `C91` → `U22.13`(VINL) 通路。

## 不贴的 22 个位置

| 位号 | 为什么不贴 |
|---|---|
| **ANT1** | 板载天线，PCB铜箔本身，无器件。50.0mm外包络/48.5mm中心线；V4.0装盒实测1082.5MHz、SWR 1.09 |
| **H1** | M2.5 安装孔（⌀2.7mm NPTH），不是元件 |
| **H2** | M2.5 安装孔（⌀2.7mm NPTH），不是元件 |
| **H3** | M2.5 安装孔（⌀2.7mm NPTH），不是元件 |
| **H4** | M2.5 安装孔（⌀2.7mm NPTH），不是元件 |
| **R7** | DNP，设计上默认不贴（5.1k DNP(带电源版)） |
| **R8** | DNP，设计上默认不贴（5.1k DNP(带电源版)） |
| **R24** | DNP，设计上默认不贴（0R DNP(旁路外接)） |
| **R25** | DNP，设计上默认不贴（0R DNP(旁路板载)） |
| **R30** | DNP，设计上默认不贴（1k DNP） |
| **R36** | DNP，设计上默认不贴（1k DNP） |
| **SW1** | 短接焊盘（BOOTSEL），用镊子短接，不贴件。**焊盘不占 SMT 贴装面数**，成本影响为 0 |
| **SW2** | 短接焊盘（BOOTSEL），用镊子短接，不贴件。**焊盘不占 SMT 贴装面数**，成本影响为 0 |
| **TP1** | 测试点焊盘，探针/飞线用，不贴件 |
| **TP2** | 测试点焊盘，探针/飞线用，不贴件 |
| **TP3** | 测试点焊盘，探针/飞线用，不贴件 |
| **TP4** | 测试点焊盘，探针/飞线用，不贴件 |
| **TP5** | 测试点焊盘，探针/飞线用，不贴件 |
| **TP6** | 测试点焊盘，探针/飞线用，不贴件 |
| **TP7** | 测试点焊盘，探针/飞线用，不贴件 |
| **ZP1** | DNP，设计上默认不贴（DNP 并-天线侧） |
| **ZP2** | DNP，设计上默认不贴（DNP 并-电台侧） |

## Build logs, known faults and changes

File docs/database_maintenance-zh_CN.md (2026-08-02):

# 航空识别数据库维护

英文版：[`database_maintenance.md`](database_maintenance.md)

本文说明 ESP32-P4 固件用到的航空识别数据库维护流程，既包括编进固件镜像的那几张表，也包括随 microSD 卡分发的机型库。这些数据库用于提升 ADS-B / Mode-S 显示质量，但它们不是航班计划、航线、时刻表、放行或实时联网数据。

## 安全边界

Pilot Kit Box 是开源态势感知和开发设备。这些数据库不能被写成或用作经过认证的航电数据、导航源或防撞数据源。

固件有意不暴露上游飞机数据库中的逐机 `flags` 字段，包括 military、VIP、PIA、LADD 等标记。刷新或替换数据源时必须保持这个边界。

## 各数据库存放在哪

| 资源 | 位置 | 来源 | 使用位置 |
|---|---|---|---|
| 飞机 ICAO24 数据库 | microSD `/sdcard/aero/pk_actdb.bin`；仓库内产物 `datafiles/data/pk_actdb.bin`；读取端 `firmware/main/aircraft_db.c`、`firmware/main/aircraft_db_reader.c`、`firmware/main/aircraft_db.h` | `wiedehopf/tar1090-db` 飞机分片，以及 Doc 8643 机型表 `db/icao_aircraft_types.js` | ADS-B LIST 机型、型号、注册号和详情面板 |
| 航司代码表 | 编进固件：`firmware/main/airline_codes.c`、`firmware/main/airline_codes.h` | Wikipedia 分字母航司代码页面，以及生成器中维护者审查过的手工补充项 | 呼号显示和运营人名称查询 |
| ICAO24 国家地址段 | 编进固件：`firmware/main/icao_country.c`、`firmware/main/icao_country.h` | tar1090 `flags.js`，来源为 ICAO 24-bit 地址分配 | ADS-B LIST 国家列和详情面板 |

搬到卡上的只有飞机 ICAO24 数据库。航司代码表和 ICAO24 国家地址段仍然是生成式 C 源码，照旧链进固件镜像；磁偏角表 `firmware/main/mag_var_table.h` 同理。

机型库文件是 64 字节 `PKACT1` 容器头（magic、cycle 戳、载荷 SHA-256）包着一份 `PKADB1` v2 载荷。它**不加密**（`enc_algo = 0`），因为 tar1090-db 是公开数据；卡上另一个文件——航空数据库 `/sdcard/aero/pk_aero.bin`——仍然是 AES-128-CTR 加密的。当前这份是 cycle `20260802`、574053 条飞机记录、1886 个机型表项、8,604,583 字节（8.21 MB）。这些数字是当前快照，不是固定协议上限。

两个文件故意分开：tar1090-db 是周更，航空数据走 28 天 AIRAC 周期，合在一起就得让其中一个等另一个。

## 用户更新模型

数据库刷新属于维护者流程，但两类数据到达设备的方式不同。

- **飞机 ICAO24 数据库**——重新生成 `pk_actdb.bin`，拷到卡上的 `/aero/pk_actdb.bin` 即可，**不涉及刷固件**。固件开机后把它懒加载进 PSRAM；没有卡或没有这个文件时盒子照常工作，ADS-B 的机型/型号/注册号字段显示为 `---`。
- **航司代码表和 ICAO24 国家地址段**——重新生成 C 源码、重新编译，随固件镜像发布。终端用户通过网页刷机或文档中的固件发布流程安装新固件来获得新数据。

SD 卡目录结构以及其余数据文件（`pk_aero.bin`、`/maps/*.pmtiles`）见 `datafiles/README.md`。

## 更新飞机 ICAO24 数据库

先获取上游 tar1090-db 分片和 ICAO Doc 8643 机型表。上游把机型表挪了位置：老地址（仓库根的 `icao_aircraft_types.json`）现在是 404，新地址 `db/icao_aircraft_types.js` 是 gzip 压缩的，所以要 gunzip 成纯 JSON 再喂给 `--types`。

```bash
mkdir -p /tmp/tar1090-db
cd /tmp/tar1090-db

curl -sL https://api.github.com/repos/wiedehopf/tar1090-db/contents/db \
  | python3 -c "import sys,json;[print(i['name']) for i in json.load(sys.stdin) if i['name'].endswith('.js')]" \
  | xargs -I {} -P 16 curl -sLO https://raw.githubusercontent.com/wiedehopf/tar1090-db/master/db/{}

curl -sL https://raw.githubusercontent.com/wiedehopf/tar1090-db/master/db/icao_aircraft_types.js \
  | gunzip > /tmp/types.json
```

重新生成卡上的文件。`--out` 默认就是 `<repo>/datafiles/data/pk_actdb.bin`，可以不写：

```bash
cd /path/to/Pilot-Kit-Box-ESP32-P4
firmware/scripts/gen_aircraft_db.py \
  --db-dir /tmp/tar1090-db \
  --types /tmp/types.json
```

然后把产物拷到卡上的 `/aero/pk_actdb.bin`。文件名必须一模一样——这个路径是编译期常量（`firmware/main/aircraft_db.c` 的 `ACTDB_PATH`）。刷新机型库不需要重新编译或重刷固件。

生成器会按设计丢弃上游 `flags` 字段。不要把这些字段重新加入输出。

## 更新航司代码表

航司生成器通过 MediaWiki API 获取 Wikipedia wikitext，把页面缓存到 `/tmp/pkb_airlines_cache`，再合并维护者审查过的 `MANUAL_ADDITIONS`，并可以直接替换仓库中的 C 表。

```bash
cd firmware
scripts/gen_airline_codes.py \
  --letters all \
  --update-source main/airline_codes.c
```

CI 或维护者自检：

```bash
cd firmware
scripts/gen_airline_codes.py \
  --letters all \
  --update-source main/airline_codes.c \
  --check
```

脚本按每秒一次请求限速。大 diff 必须人工审查，重点看航司改名、历史/停运运营人，以及手工补充项是否仍然合理。

## 更新 ICAO24 国家地址段

国家地址段生成器默认抓取 tar1090 `flags.js`，并输出 `main/icao_country.c`：

```bash
cd firmware
scripts/gen_icao_country.py --out main/icao_country.c
```

如果需要审计或离线更新，可以先下载源文件：

```bash
cd firmware
scripts/gen_icao_country.py \
  --source-file /tmp/flags.js \
  --out main/icao_country.c
```

CI 或维护者自检：

```bash
cd firmware
scripts/gen_icao_country.py --check --out main/icao_country.c
```

生成后的查询逻辑会返回最具体的匹配地址段，因此大国家段内的小属地分配会覆盖父级地址段。如果上游 flag code 不是有效的 ISO 3166-1 alpha-2 国家代码，生成器也会保留明确的 ISO 修正项。

## 构建与发布检查

任何数据库刷新后都要执行：

```bash
cd firmware
python3 -m py_compile scripts/gen_aircraft_db.py scripts/gen_airline_codes.py scripts/gen_icao_country.py
./build.sh build
```

只有航司表和国家表需要重新编译；机型库是卡上的文件，不影响固件镜像。

还需要复查：

- 如果源码名称变化，更新 `firmware/main/CMakeLists.txt`。
- 如果 SD 卡目录结构、文件名或生成器默认值变化，更新 `datafiles/README.md`。
- 如果数据库能力、路径或用户更新方式变化，更新 `README.md` 和 `docs/README.md`。
- 如果发布流程变化，更新 `docs/firmware_update.md` / `docs/firmware_update-zh_CN.md`。

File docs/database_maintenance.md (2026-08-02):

# Aviation Identity Database Maintenance

Simplified Chinese version: [`database_maintenance-zh_CN.md`](database_maintenance-zh_CN.md)

This document covers the local aviation identity databases used by the
ESP32-P4 firmware — the ones compiled into the firmware image and the
aircraft database shipped on the microSD card. These databases improve
ADS-B / Mode-S display quality, but they are not flight-plan, route,
timetable, dispatch, or live network data.

## Safety Boundary

Pilot Kit Box is an open-source situational-awareness and development
device. These databases must not be documented or used as certified
avionics data, a navigation source, or a collision-avoidance source.

The firmware deliberately does not expose per-aircraft military, VIP,
PIA, or LADD flags from the upstream aircraft database. Keep that
boundary intact when refreshing or replacing data sources.

## Where Each Database Lives

| Resource | Location | Source | Used by |
|---|---|---|---|
| Aircraft ICAO24 database | microSD `/sdcard/aero/pk_actdb.bin`; built into `datafiles/data/pk_actdb.bin`; reader `firmware/main/aircraft_db.c`, `firmware/main/aircraft_db_reader.c`, `firmware/main/aircraft_db.h` | `wiedehopf/tar1090-db` aircraft shards plus the Doc 8643 type table `db/icao_aircraft_types.js` | ADS-B LIST type, model, registration, and detail pane |
| Airline code table | Compiled into the firmware: `firmware/main/airline_codes.c`, `firmware/main/airline_codes.h` | Wikipedia per-letter airline code pages, with maintainer-reviewed manual additions in the generator | Callsign display and operator name lookup |
| ICAO24 country ranges | Compiled into the firmware: `firmware/main/icao_country.c`, `firmware/main/icao_country.h` | tar1090 `flags.js`, derived from ICAO 24-bit address allocations | ADS-B LIST country column and detail pane |

Only the aircraft ICAO24 database moved to the card. The airline code
table and the ICAO24 country ranges are generated C sources and are
still linked into the firmware image, as is the magnetic-variation
table `firmware/main/mag_var_table.h`.

The aircraft database file is a 64-byte `PKACT1` container header (magic,
cycle stamp, SHA-256 of the payload) wrapping a `PKADB1` version 2
payload. It is **not encrypted** (`enc_algo = 0`) because tar1090-db is
public data; the separate aeronautical database `/sdcard/aero/pk_aero.bin`
keeps its AES-128-CTR encryption. The current build is cycle `20260802`,
574,053 aircraft records, 1,886 type rows, 8,604,583 bytes (8.21 MB).
Treat these figures as a snapshot, not a fixed protocol limit.

The two files are deliberately separate: tar1090-db refreshes weekly
while the aeronautical data follows the 28-day AIRAC cycle, so merging
them would force one to wait on the other.

## User Update Model

Database refresh is a maintainer workflow, but the two classes of data
reach the device differently.

- **Aircraft ICAO24 database** — regenerate `pk_actdb.bin` and copy it to
  the card at `/aero/pk_actdb.bin`. No firmware reflash is involved. The
  firmware loads it lazily into PSRAM after boot; with no card or no file
  the box keeps working and ADS-B type/model/registration fields simply
  render as `---`.
- **Airline code table and ICAO24 country ranges** — regenerate the C
  sources, rebuild, and ship them inside the firmware image. Users receive
  newer data by installing a newer firmware build through the web flasher
  or the documented firmware release flow.

Card layout and the other data files (`pk_aero.bin`, `/maps/*.pmtiles`)
are documented in `datafiles/README.md`.

## Update Aircraft ICAO24 Database

Fetch the upstream tar1090-db shards and the ICAO Doc 8643 type table.
Upstream moved the type table: the old repo-root `icao_aircraft_types.json`
now 404s, and the current `db/icao_aircraft_types.js` is gzip-compressed,
so it has to be gunzipped into plain JSON for `--types`.

```bash
mkdir -p /tmp/tar1090-db
cd /tmp/tar1090-db

curl -sL https://api.github.com/repos/wiedehopf/tar1090-db/contents/db \
  | python3 -c "import sys,json;[print(i['name']) for i in json.load(sys.stdin) if i['name'].endswith('.js')]" \
  | xargs -I {} -P 16 curl -sLO https://raw.githubusercontent.com/wiedehopf/tar1090-db/master/db/{}

curl -sL https://raw.githubusercontent.com/wiedehopf/tar1090-db/master/db/icao_aircraft_types.js \
  | gunzip > /tmp/types.json
```

Regenerate the card file. `--out` defaults to
`<repo>/datafiles/data/pk_actdb.bin`, so it can be omitted:

```bash
cd /path/to/Pilot-Kit-Box-ESP32-P4
firmware/scripts/gen_aircraft_db.py \
  --db-dir /tmp/tar1090-db \
  --types /tmp/types.json
```

Then copy the result onto the card as `/aero/pk_actdb.bin`. Keep the
file name exactly — the path is a compile-time constant (`ACTDB_PATH` in
`firmware/main/aircraft_db.c`). No firmware rebuild or reflash is needed
for an aircraft-database refresh.

The generator drops upstream `flags` values by design. Do not add those
fields to the output.

## Update Airline Code Table

The airline generator fetches Wikipedia wikitext through the MediaWiki
API, caches pages under `/tmp/pkb_airlines_cache`, applies the
maintainer-reviewed `MANUAL_ADDITIONS`, and can replace the checked-in
C table directly.

```bash
cd firmware
scripts/gen_airline_codes.py \
  --letters all \
  --update-source main/airline_codes.c
```

For CI or maintainer verification:

```bash
cd firmware
scripts/gen_airline_codes.py \
  --letters all \
  --update-source main/airline_codes.c \
  --check
```

The script rate-limits requests to one fetch per second. Review large
diffs manually, especially airline renames, historic/defunct operators,
and the manual additions block.

## Update ICAO24 Country Ranges

The country generator fetches tar1090 `flags.js` by default and emits
`main/icao_country.c`:

```bash
cd firmware
scripts/gen_icao_country.py --out main/icao_country.c
```

For audited or offline updates, download the source file first:

```bash
cd firmware
scripts/gen_icao_country.py \
  --source-file /tmp/flags.js \
  --out main/icao_country.c
```

For CI or maintainer verification:

```bash
cd firmware
scripts/gen_icao_country.py --check --out main/icao_country.c
```

The generated lookup returns the most specific matching address range,
so small territory assignments inside larger country blocks override the
parent range. The generator also keeps explicit ISO code fixups when the
upstream flag code is not a valid ISO 3166-1 alpha-2 country code.

## Build And Release Checks

After any database refresh:

```bash
cd firmware
python3 -m py_compile scripts/gen_aircraft_db.py scripts/gen_airline_codes.py scripts/gen_icao_country.py
./build.sh build
```

A rebuild is only required for the airline and country tables; the
aircraft database is a card file and does not affect the image.

Also review:

- `firmware/main/CMakeLists.txt` if source names change.
- `datafiles/README.md` if the card layout, file names, or generator
  defaults change.
- `README.md` and `docs/README.md` if database capabilities, paths, or
  user-facing update behavior change.
- `docs/firmware_update.md` / `docs/firmware_update-zh_CN.md` if the
  release process changes.

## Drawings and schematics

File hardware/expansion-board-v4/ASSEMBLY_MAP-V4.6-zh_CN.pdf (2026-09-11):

## Pilot Kit 扩展板 V4.6 装配图 —— 带电源版（顶层视角）

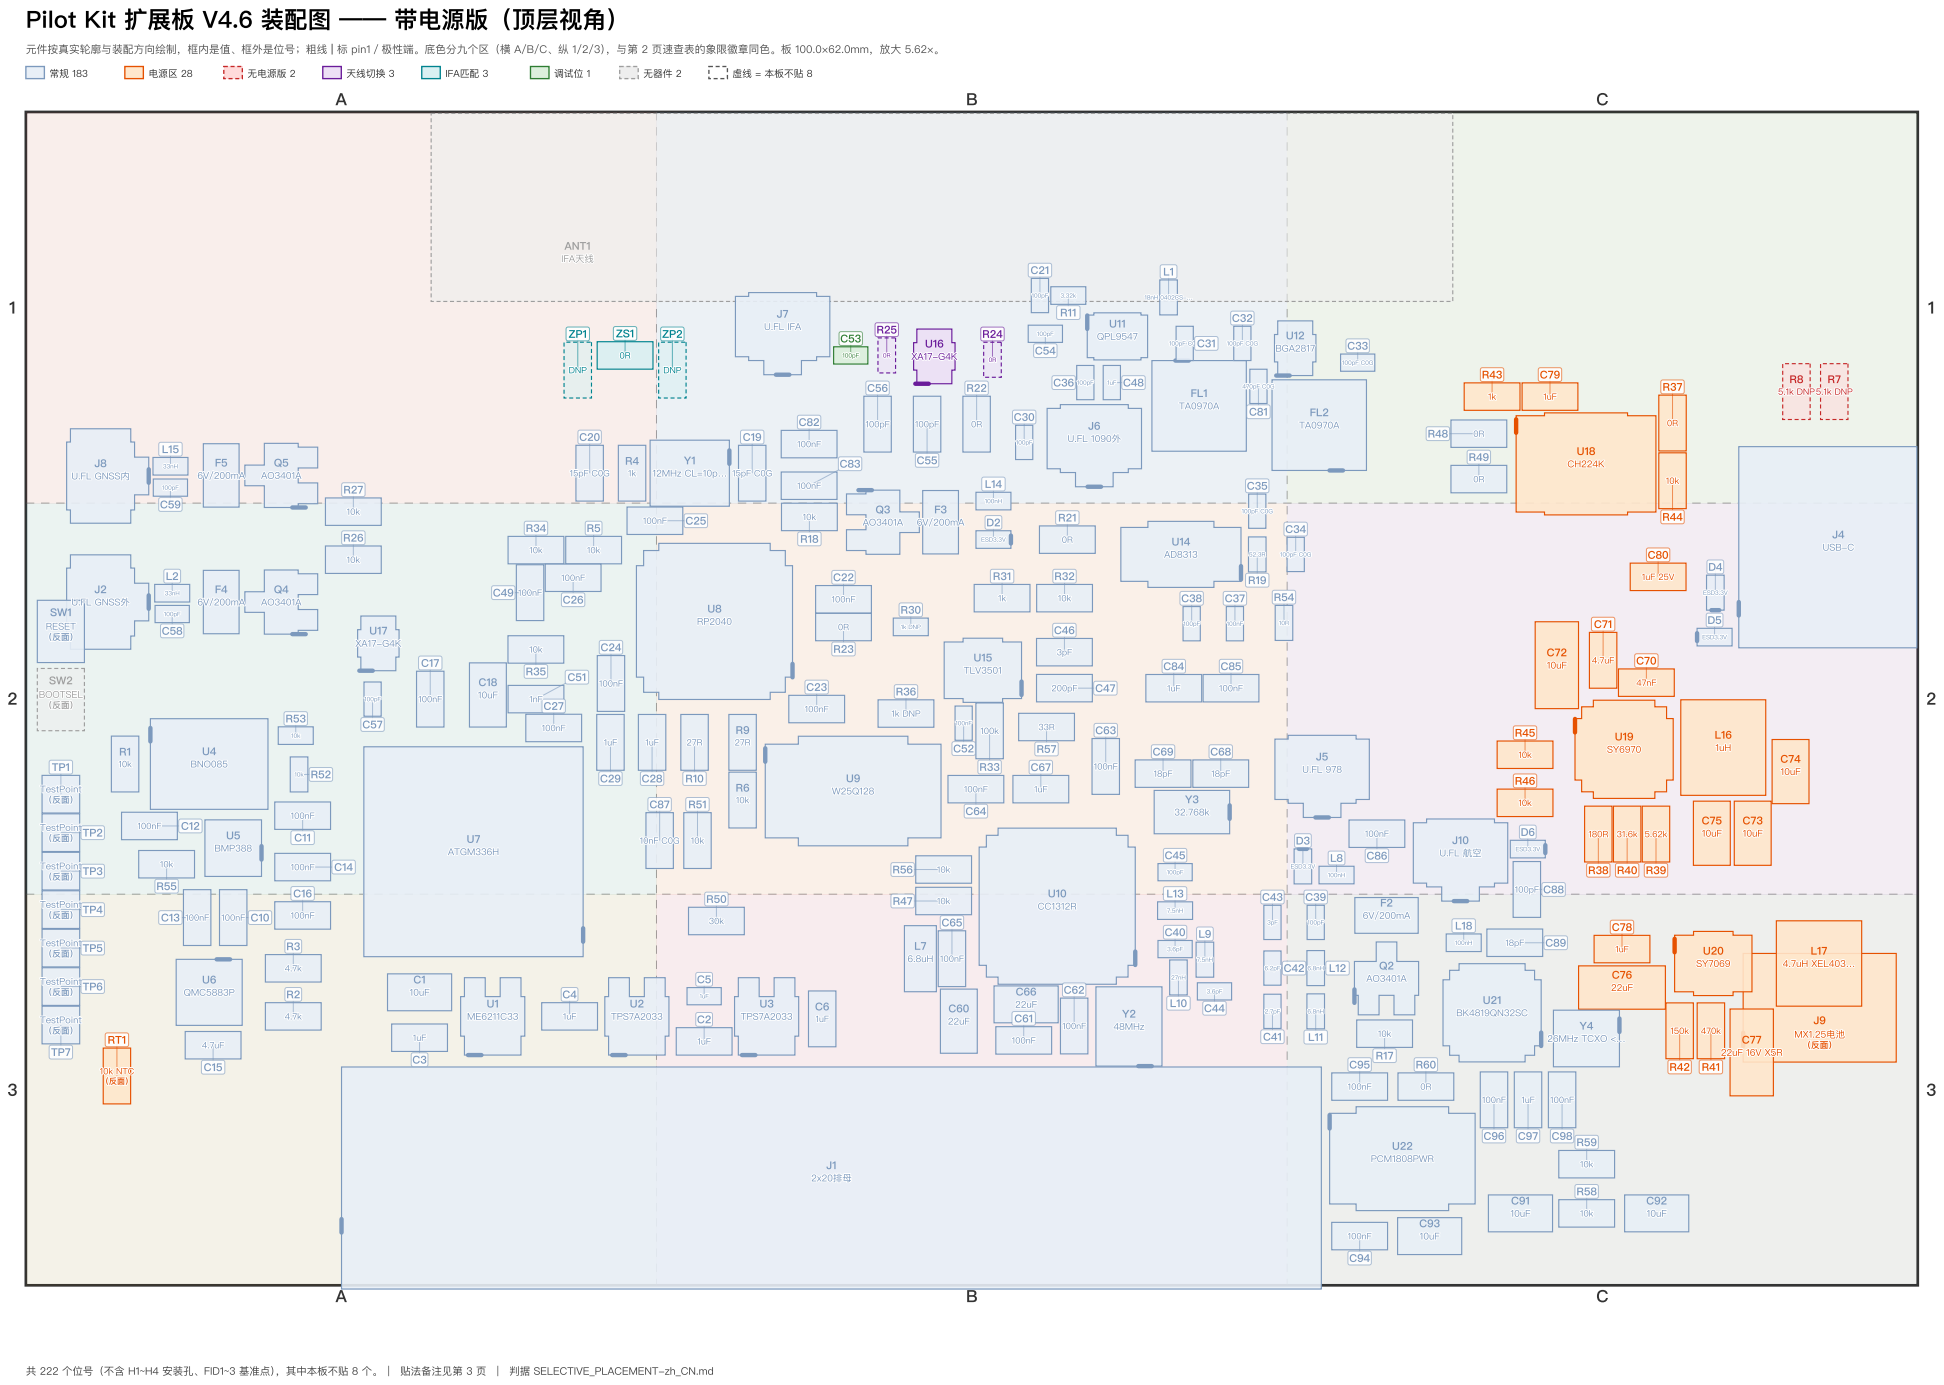
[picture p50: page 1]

元件按真实轮廓与装配方向绘制，框内是值、框外是位号；粗线 | 标 pin1／极性端。底色分九个区（横 A/B/C、纵 1/2/3），与第 2 页速查表的象限徽章同色。板 100.0×62.0mm，放大 5.62×。

## Pilot Kit 扩展板 V4.6 位号速查表 —— 象限对照

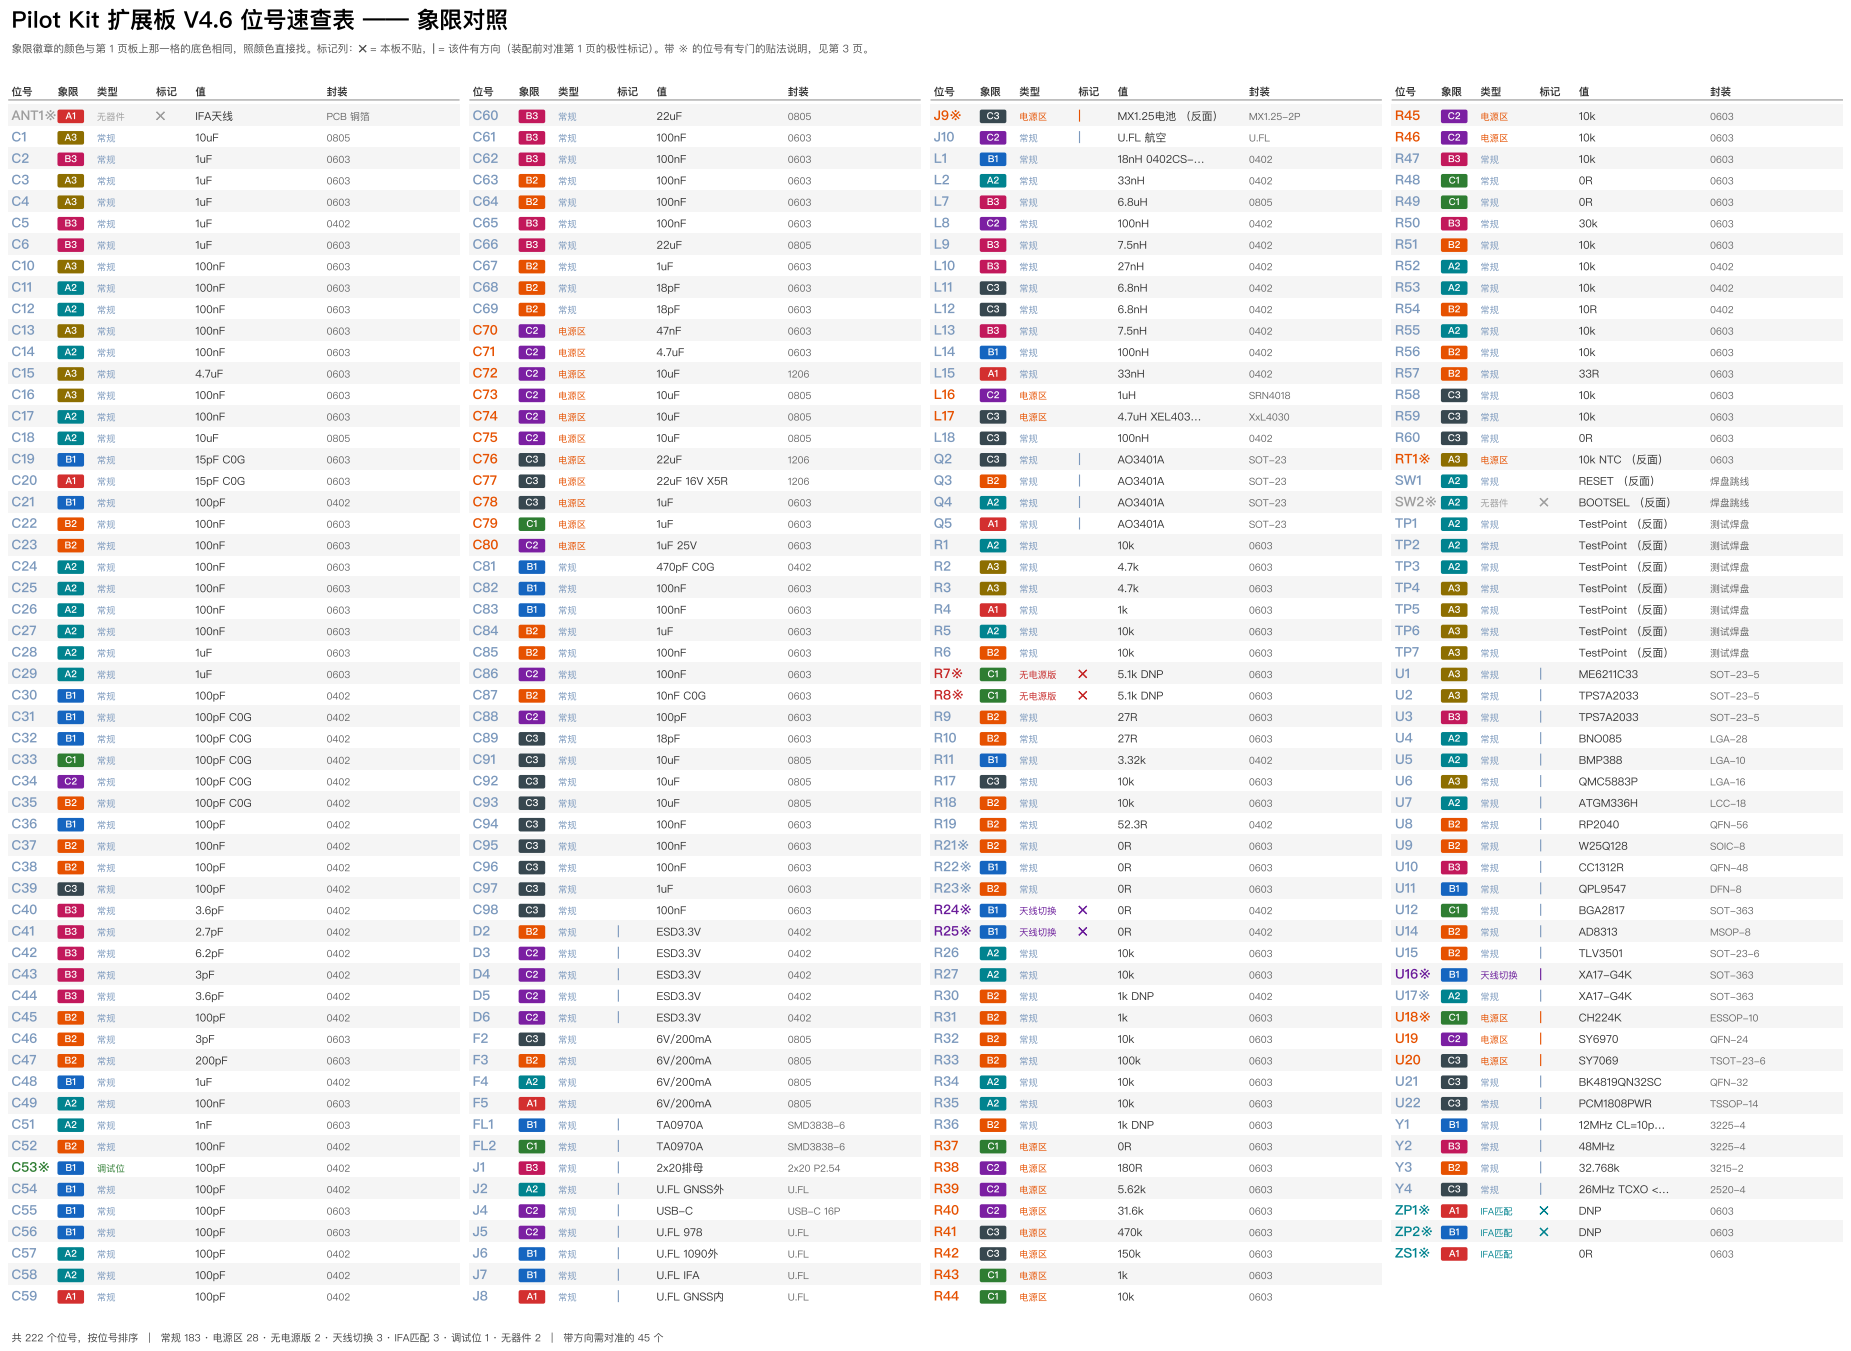
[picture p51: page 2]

象限徽章的颜色与第 1 页板上那一格的底色相同，照颜色直接找。标记列：✕ = 本板不贴，| = 该件有方向（装配前对准第 1 页的极性标记）。带 ※ 的位号有专门的贴法说明，见第 3 页。

共 222 个位号，按位号排序 | 常规 183 · 电源区 28 · 无电源版 2 · 天线切换 3 · IFA匹配 3 · 调试位 1 · 无器件 2 | 带方向需对准的 45 个

## Pilot Kit 扩展板 V4.6 特殊贴装说明

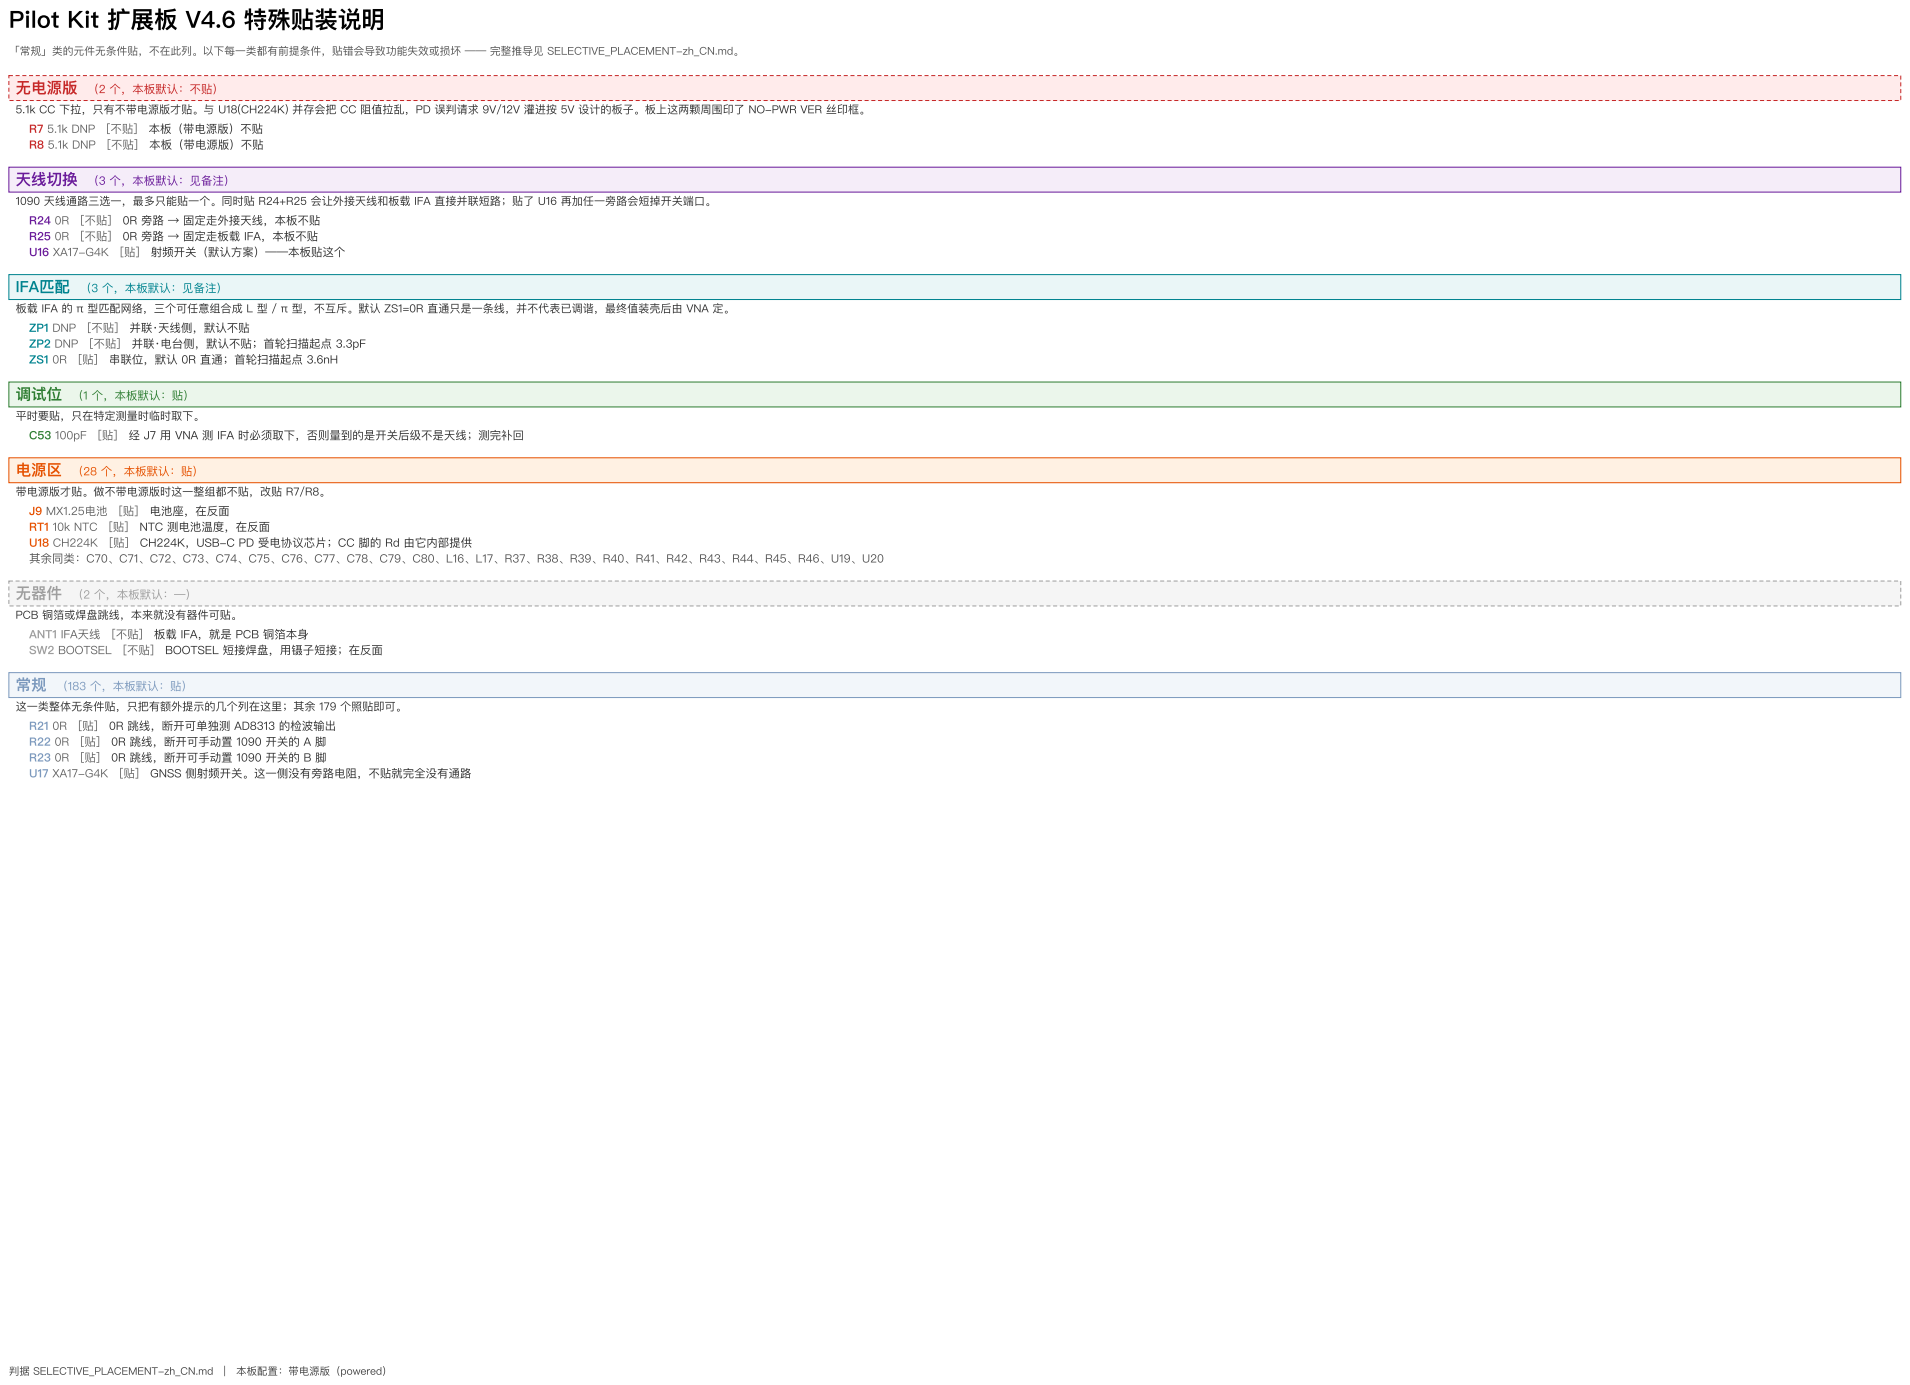
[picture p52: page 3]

5.1k CC 下拉，只有不带电源版才贴。与 U18(CH224K) 并存会把 CC 阻值拉乱，PD 误判请求 9V/12V 灌进按 5V 设计的板子。板上这两颗周围印了 NO-PWR VER 丝印框。
R7 5.1k DNP [不贴] 本板（带电源版）不贴
R8 5.1k DNP [不贴] 本板（带电源版）不贴

1090 天线通路三选一，最多只能贴一个。同时贴 R24+R25 会让外接天线和板载 IFA 直接并联短路；贴了 U16 再加任一旁路会短掉开关端口。
R24 0R [不贴] 0R 旁路 → 固定走外接天线，本板不贴
R25 0R [不贴] 0R 旁路 → 固定走板载 IFA，本板不贴
U16 XA17-G4K [贴] 射频开关（默认方案）——本板贴这个

板载 IFA 的 π 型匹配网络，三个可任意组合成 L 型 / π 型，不互斥。默认 ZS1=0R 直通只是一条线，并不代表已调谐，最终值装壳后由 VNA 定。
ZP1 DNP [不贴] 并联·天线侧，默认不贴
ZP2 DNP [不贴] 并联·电台侧，默认不贴；首轮扫描起点 3.3pF
ZS1 0R [贴] 串联位，默认 0R 直通；首轮扫描起点 3.6nH

平时要贴，只在特定测量时临时取下。
C53 100pF [贴] 经 J7 用 VNA 测 IFA 时必须取下，否则量到的是开关后级不是天线；测完补回

带电源版才贴。做不带电源版时这一整组都不贴，改贴 R7/R8。
J9 MX1.25电池 [贴] 电池座，在反面
RT1 10k NTC [贴] NTC 测电池温度，在反面
U18 CH224K [贴] CH224K，USB-C PD 受电协议芯片；CC 脚的 Rd 由它内部提供
其余同类：C70、C71、C72、C73、C74、C75、C76、C77、C78、C79、C80、L16、L17、R37、R38、R39、R40、R41、R42、R43、R44、R45、R46、U19、U20

PCB 铜箔或焊盘跳线，本来就没有器件可贴。
ANT1 IFA天线 [不贴] 板载 IFA，就是 PCB 铜箔本身
SW2 BOOTSEL [不贴] BOOTSEL 短接焊盘，用镊子短接；在反面

这一类整体无条件贴，只把有额外提示的几个列在这里；其余 179 个照贴即可。
R21 0R [贴] 0R 跳线，断开可单独测 AD8313 的检波输出
R22 0R [贴] 0R 跳线，断开可手动置 1090 开关的 A 脚
R23 0R [贴] 0R 跳线，断开可手动置 1090 开关的 B 脚
U17 XA17-G4K [贴] GNSS 侧射频开关。这一侧没有旁路电阻，不贴就完全没有通路

判据 SELECTIVE_PLACEMENT-zh_CN.md | 本板配置：带电源版（powered）

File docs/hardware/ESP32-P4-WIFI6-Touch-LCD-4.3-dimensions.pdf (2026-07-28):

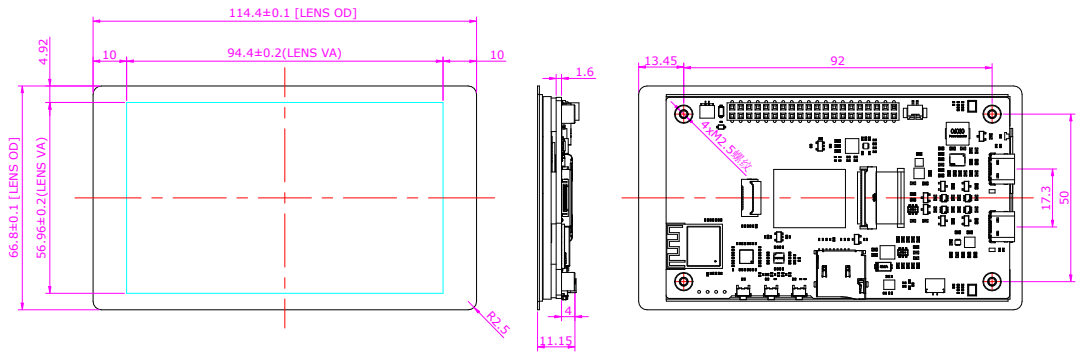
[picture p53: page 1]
56.96±0.2(LENS VA); 94.4±0.2(LENS VA); 66.8±0.1 [LENS OD]; 114.4±0.1 [LENS OD]

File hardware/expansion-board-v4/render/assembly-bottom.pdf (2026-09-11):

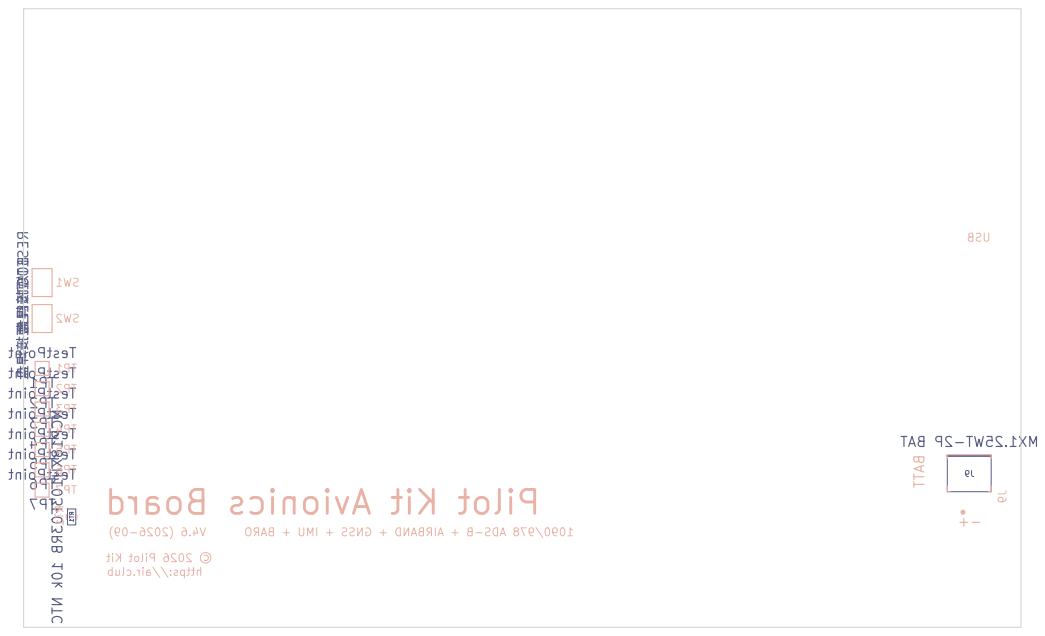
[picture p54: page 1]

Size: A4 | Rev:
KiCad E.D.A. 10.0.4 | Id: 1/1

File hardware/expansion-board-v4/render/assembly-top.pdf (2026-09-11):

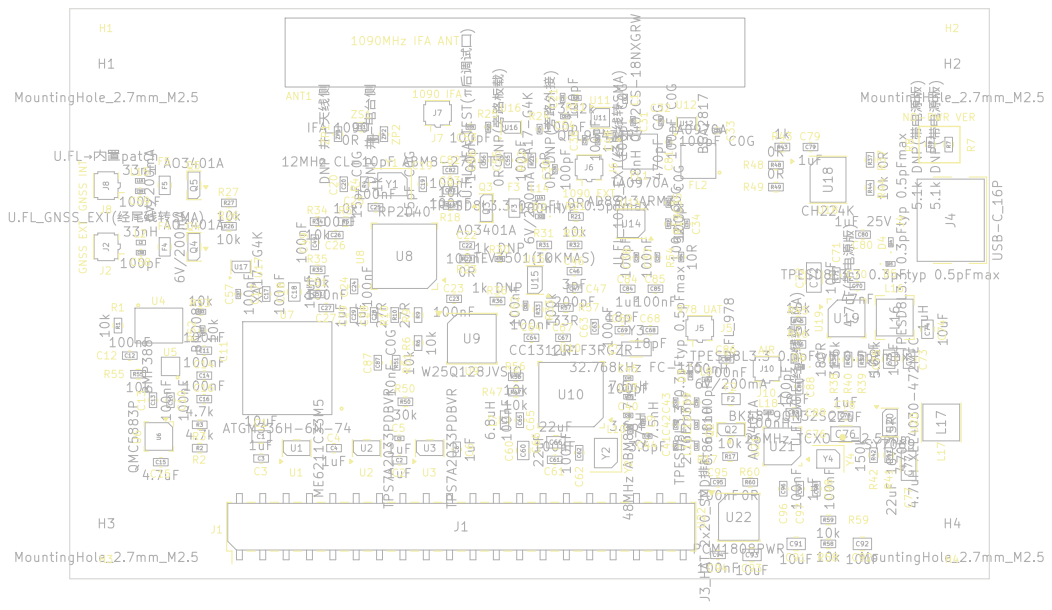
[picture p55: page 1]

Size: A4 | Rev:
KiCad E.D.A. 10.0.4 | Id: 1/1

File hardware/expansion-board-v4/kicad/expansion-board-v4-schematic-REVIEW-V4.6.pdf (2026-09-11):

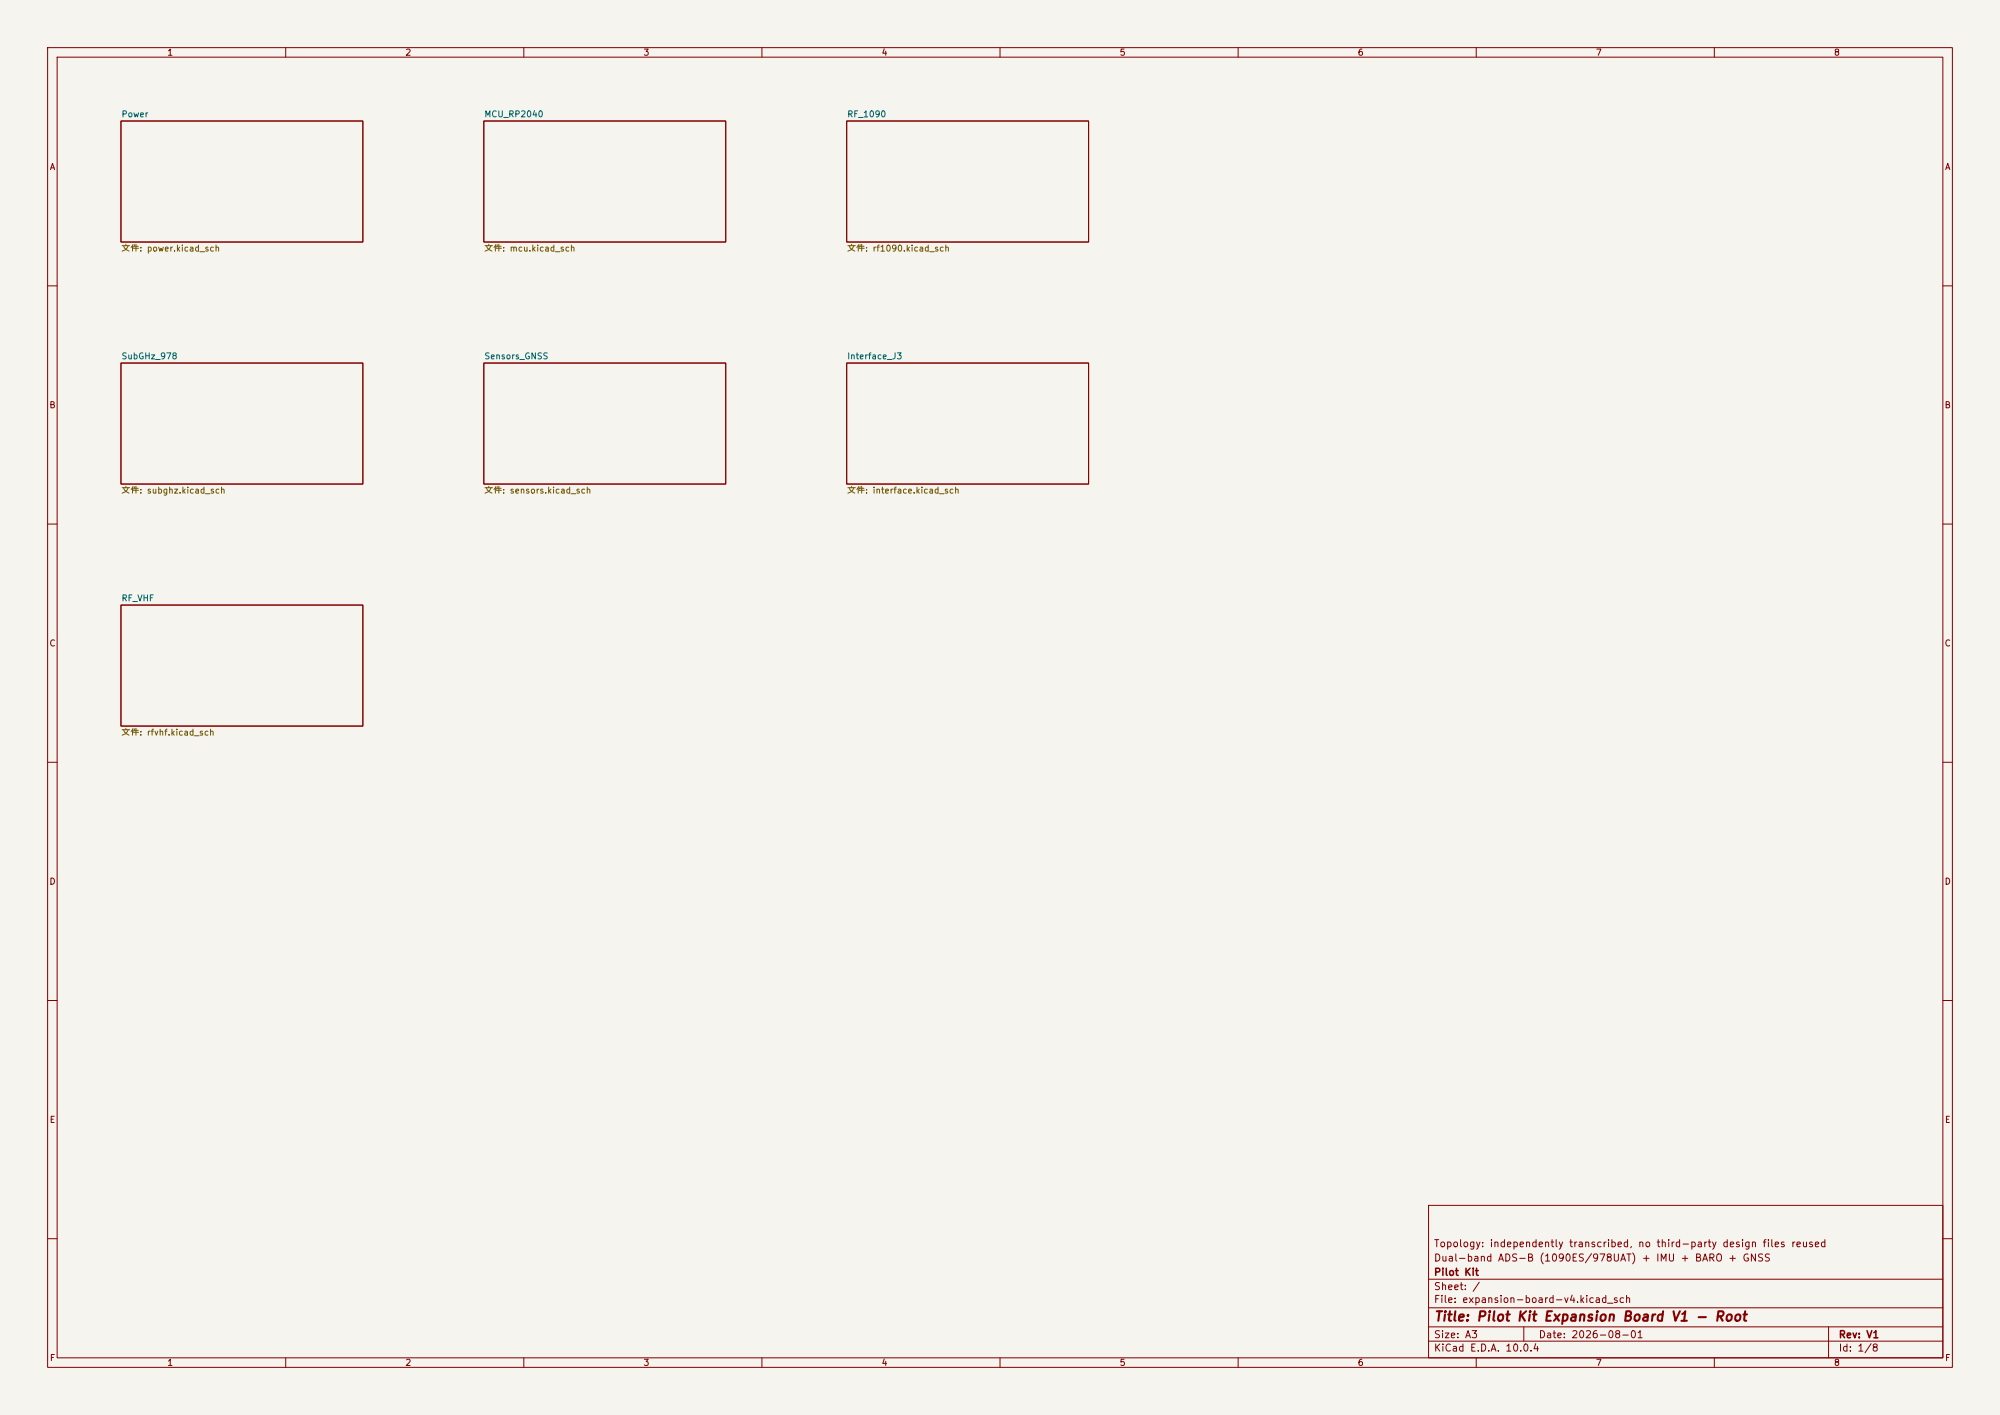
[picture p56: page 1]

Interface_J3 文件: interface.kicad_sch RF_VHF 文件: rfvhf.kicad_sch

Topology: independently transcribed, no third-party design files reused
Dual-band ADS-B (1090ES/978UAT) + IMU + BARO + GNSS
Pilot Kit
Sheet: /
File: expansion-board-v4.kicad_sch
Title: Pilot Kit Expansion Board V1 - Root

Size: A3 | Rev: V1 | F Date: 2026-08-01
KiCad E.D.A. 10.0.4 | Id: 1/8

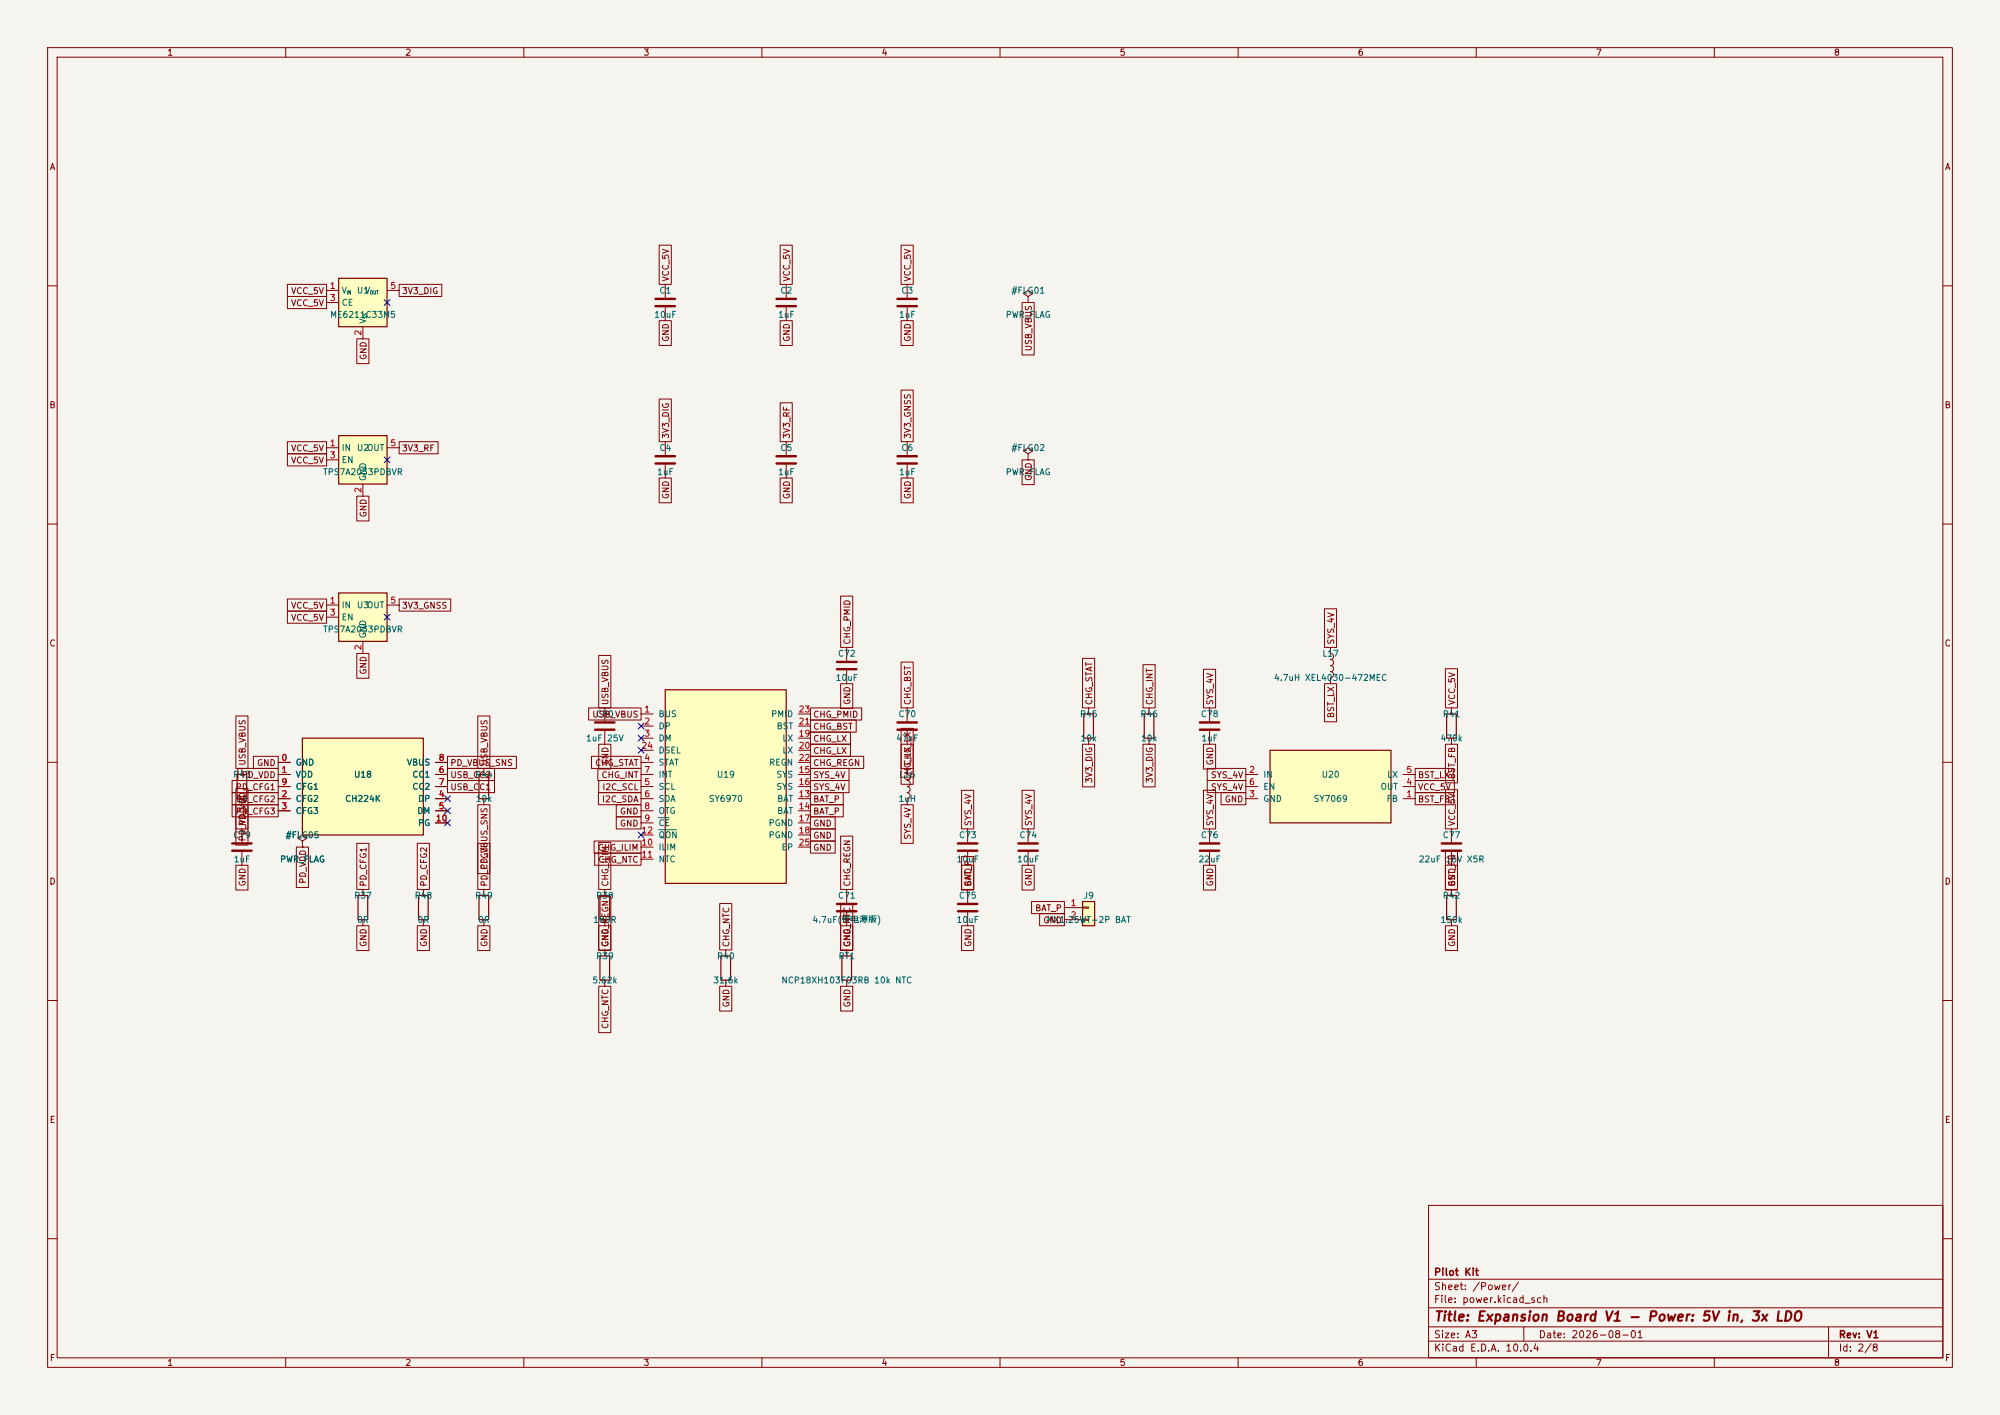
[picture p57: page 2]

LX 20 BST 21 REGN 22 PMID 23 DSEL 24

Pilot Kit
Sheet: /Power/
File: power.kicad_sch
Title: Expansion Board V1 - Power: 5V in, 3x LDO

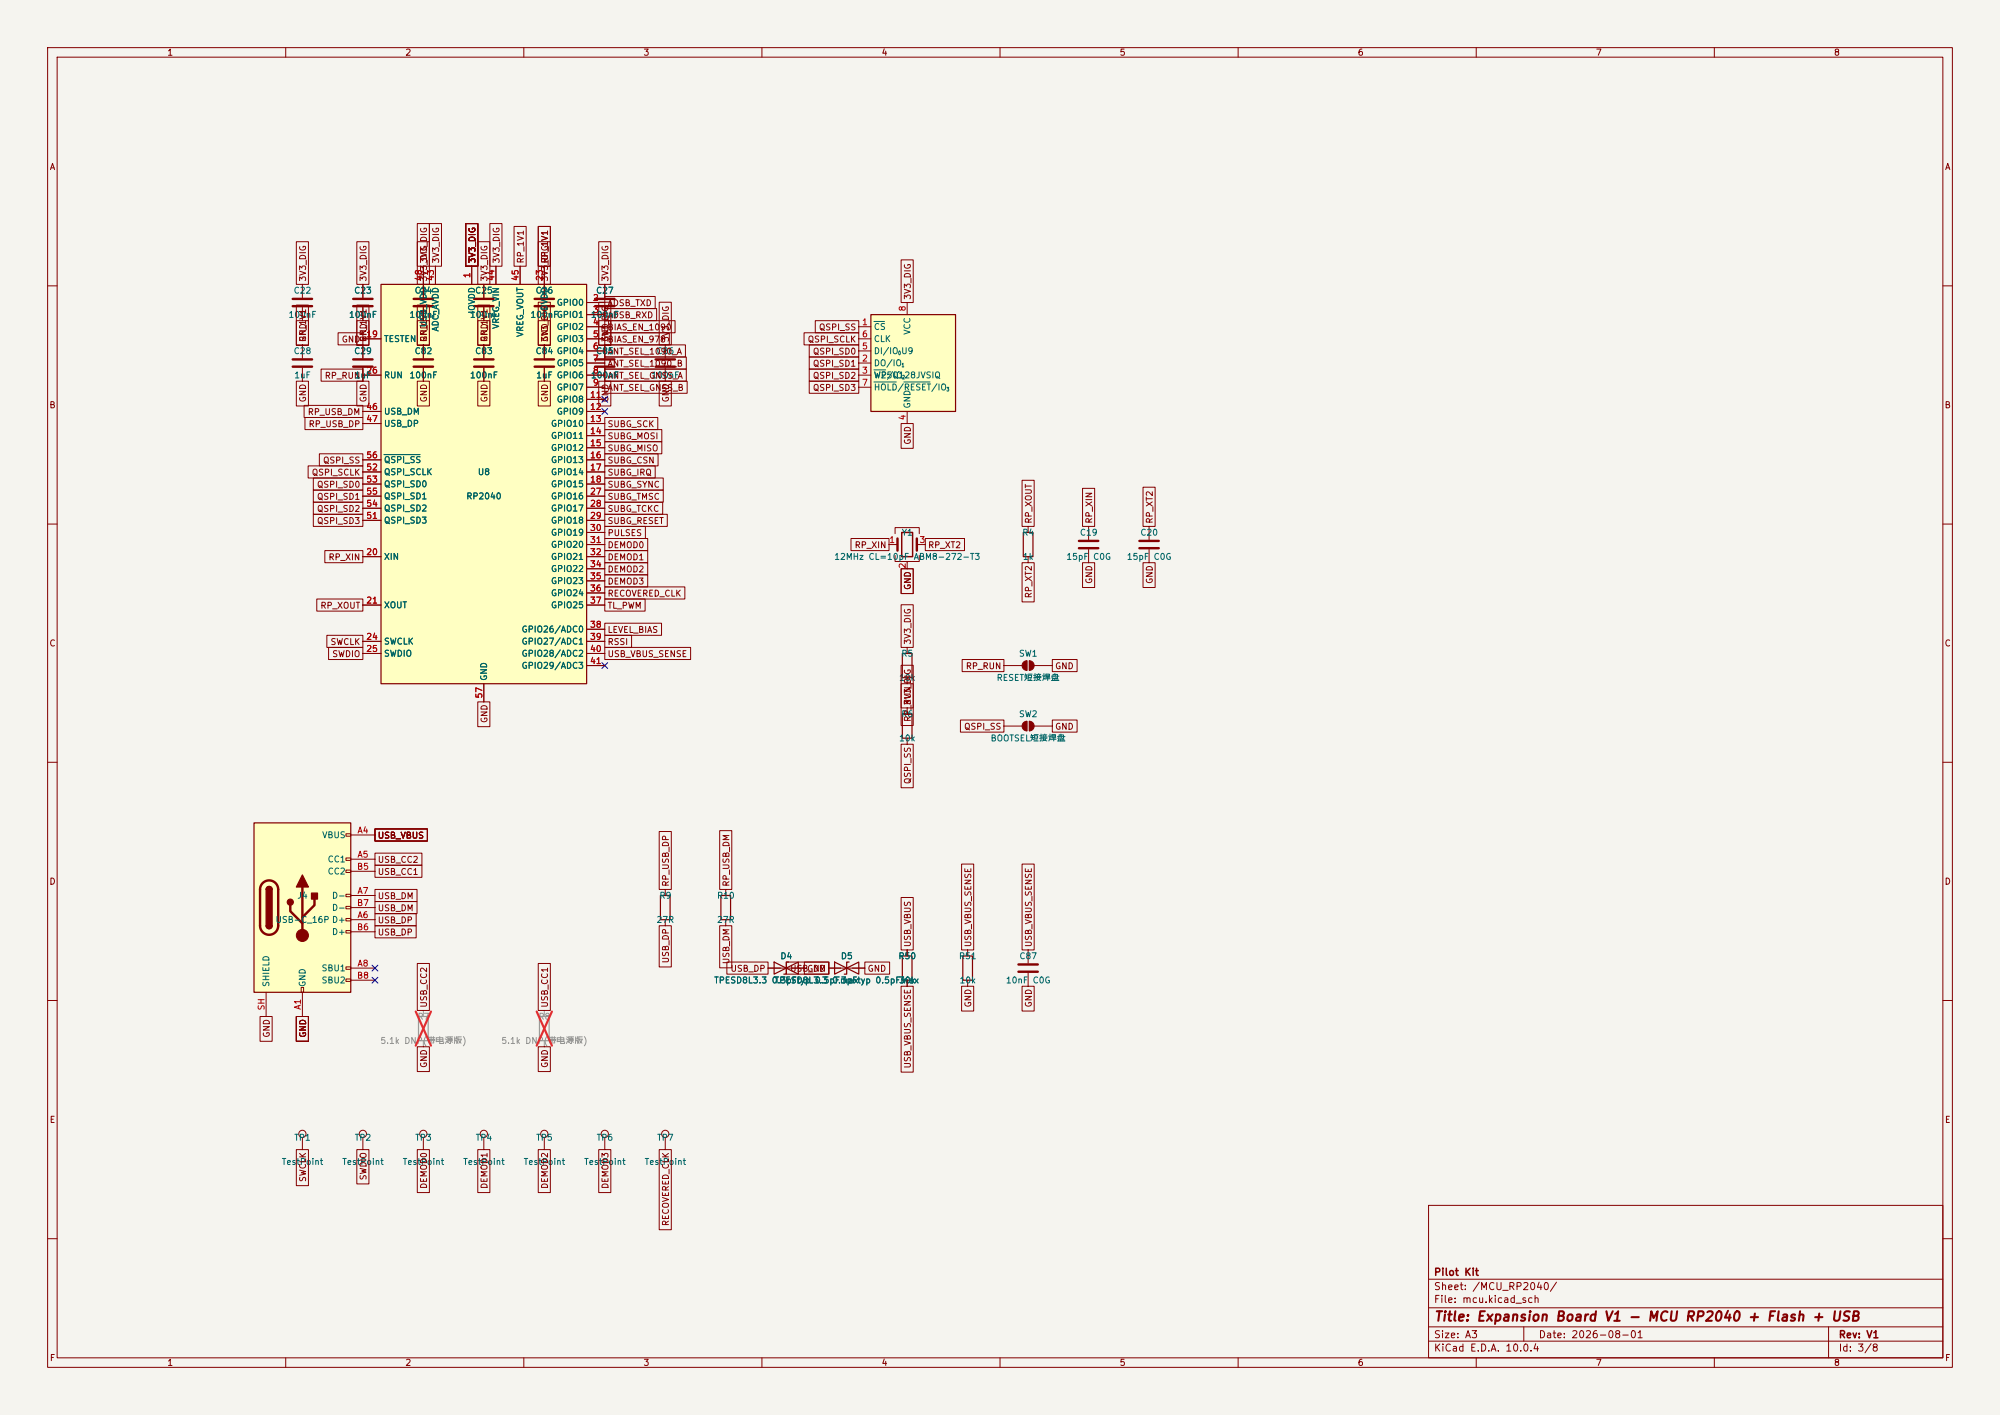
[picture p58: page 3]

Sheet: /MCU_RP2040/
File: mcu.kicad_sch
Title: Expansion Board V1 - MCU RP2040 + Flash + USB

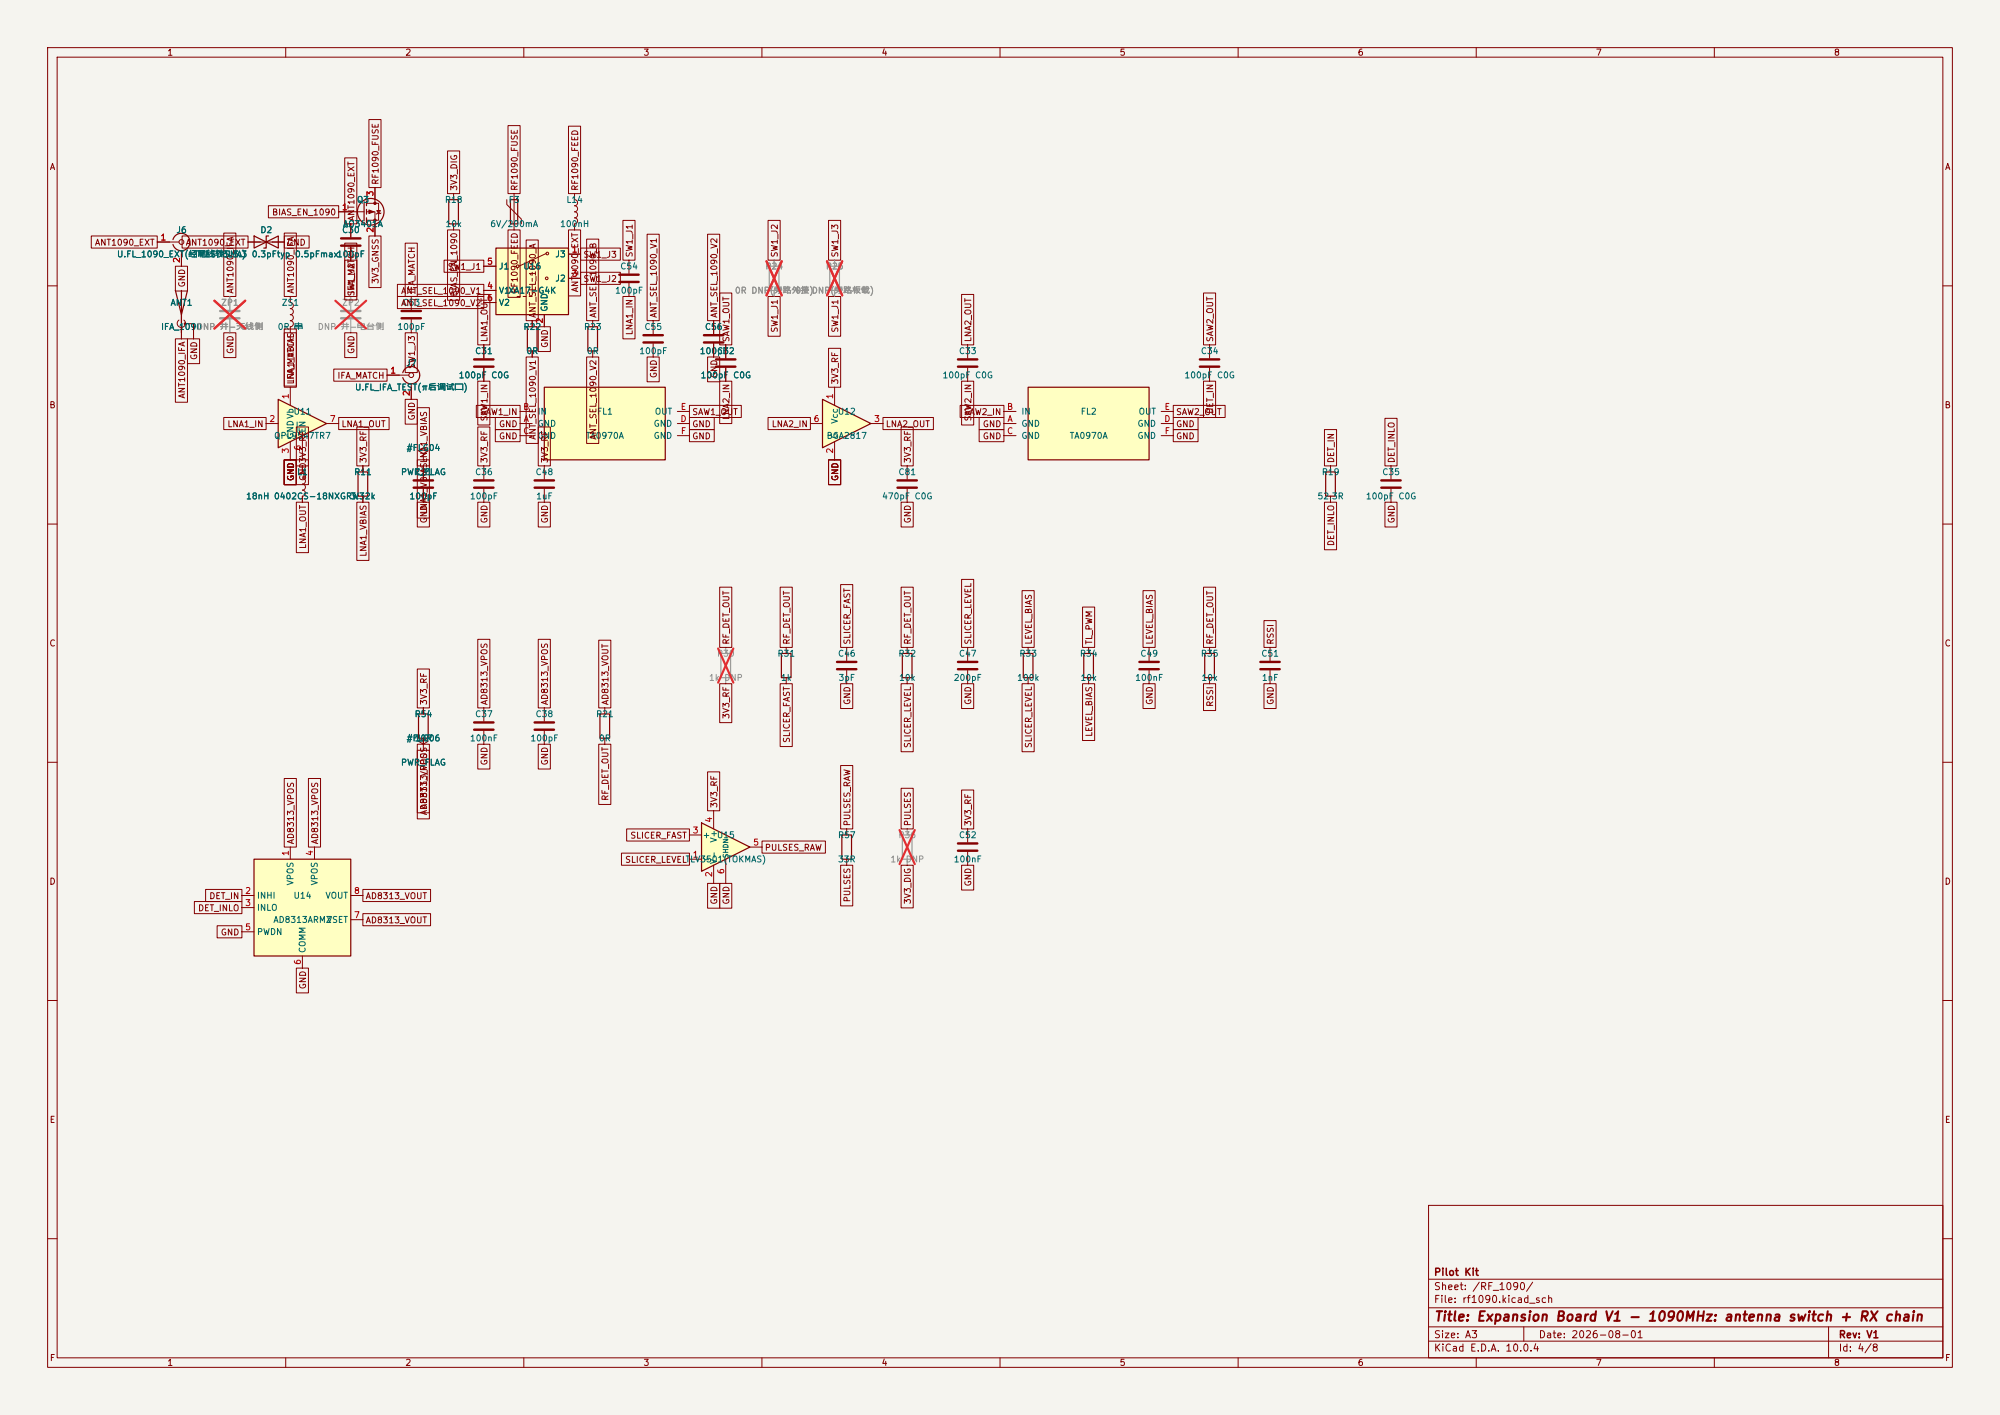
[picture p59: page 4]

Pilot Kit
Sheet: /RF_1090/
File: rf1090.kicad_sch
Title: Expansion Board V1 - 1090MHz: antenna switch + RX chain

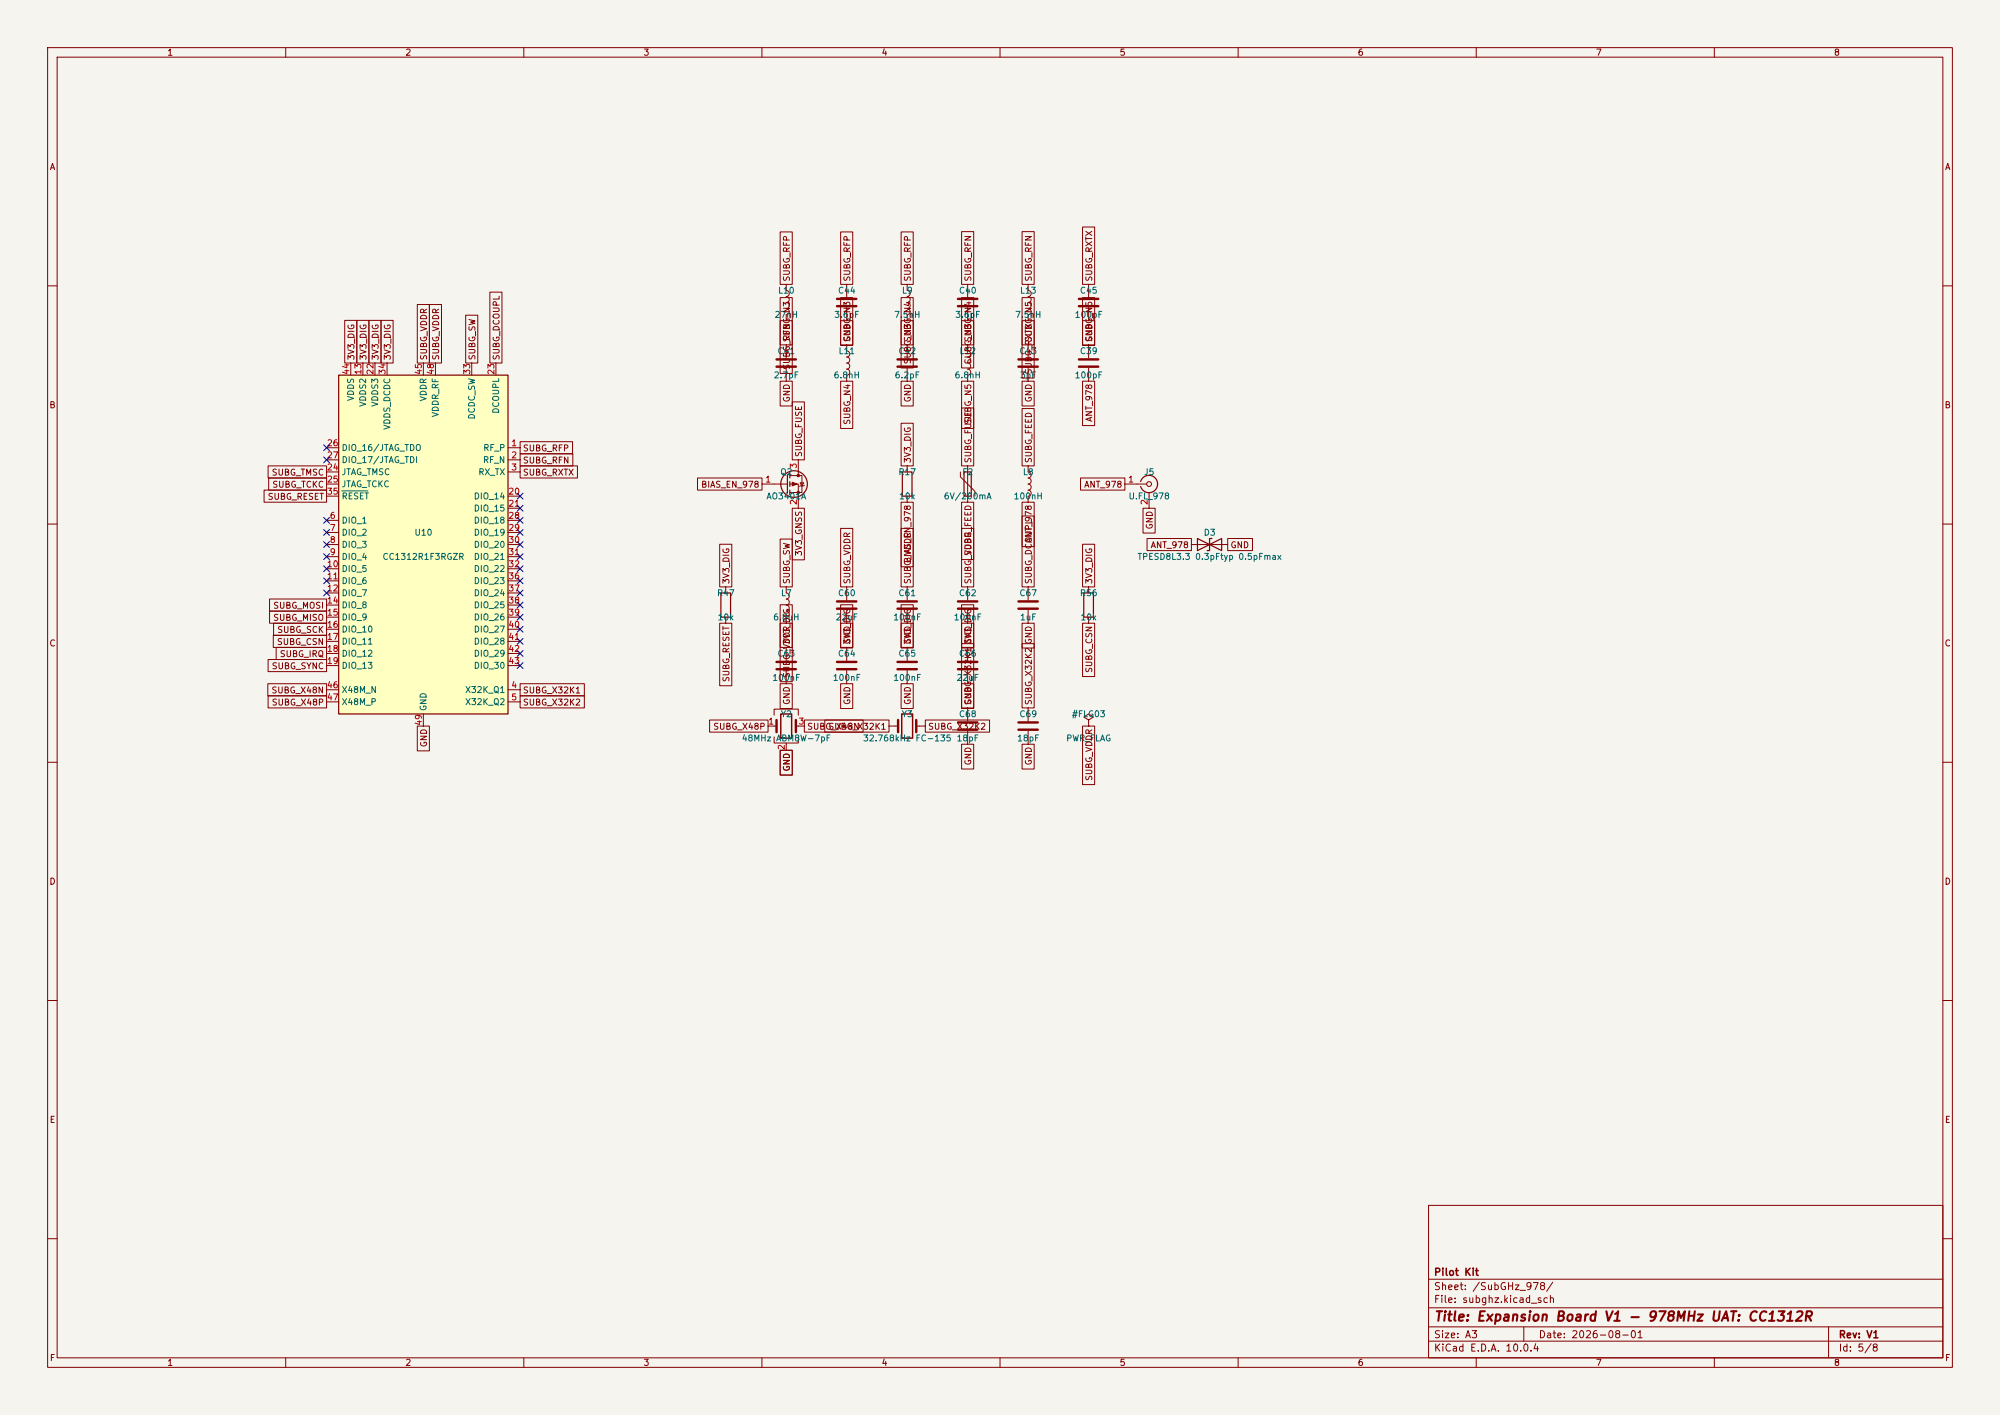
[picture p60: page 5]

Pilot Kit
Sheet: /SubGHz_978/
File: subghz.kicad_sch
Title: Expansion Board V1 - 978MHz UAT: CC1312R

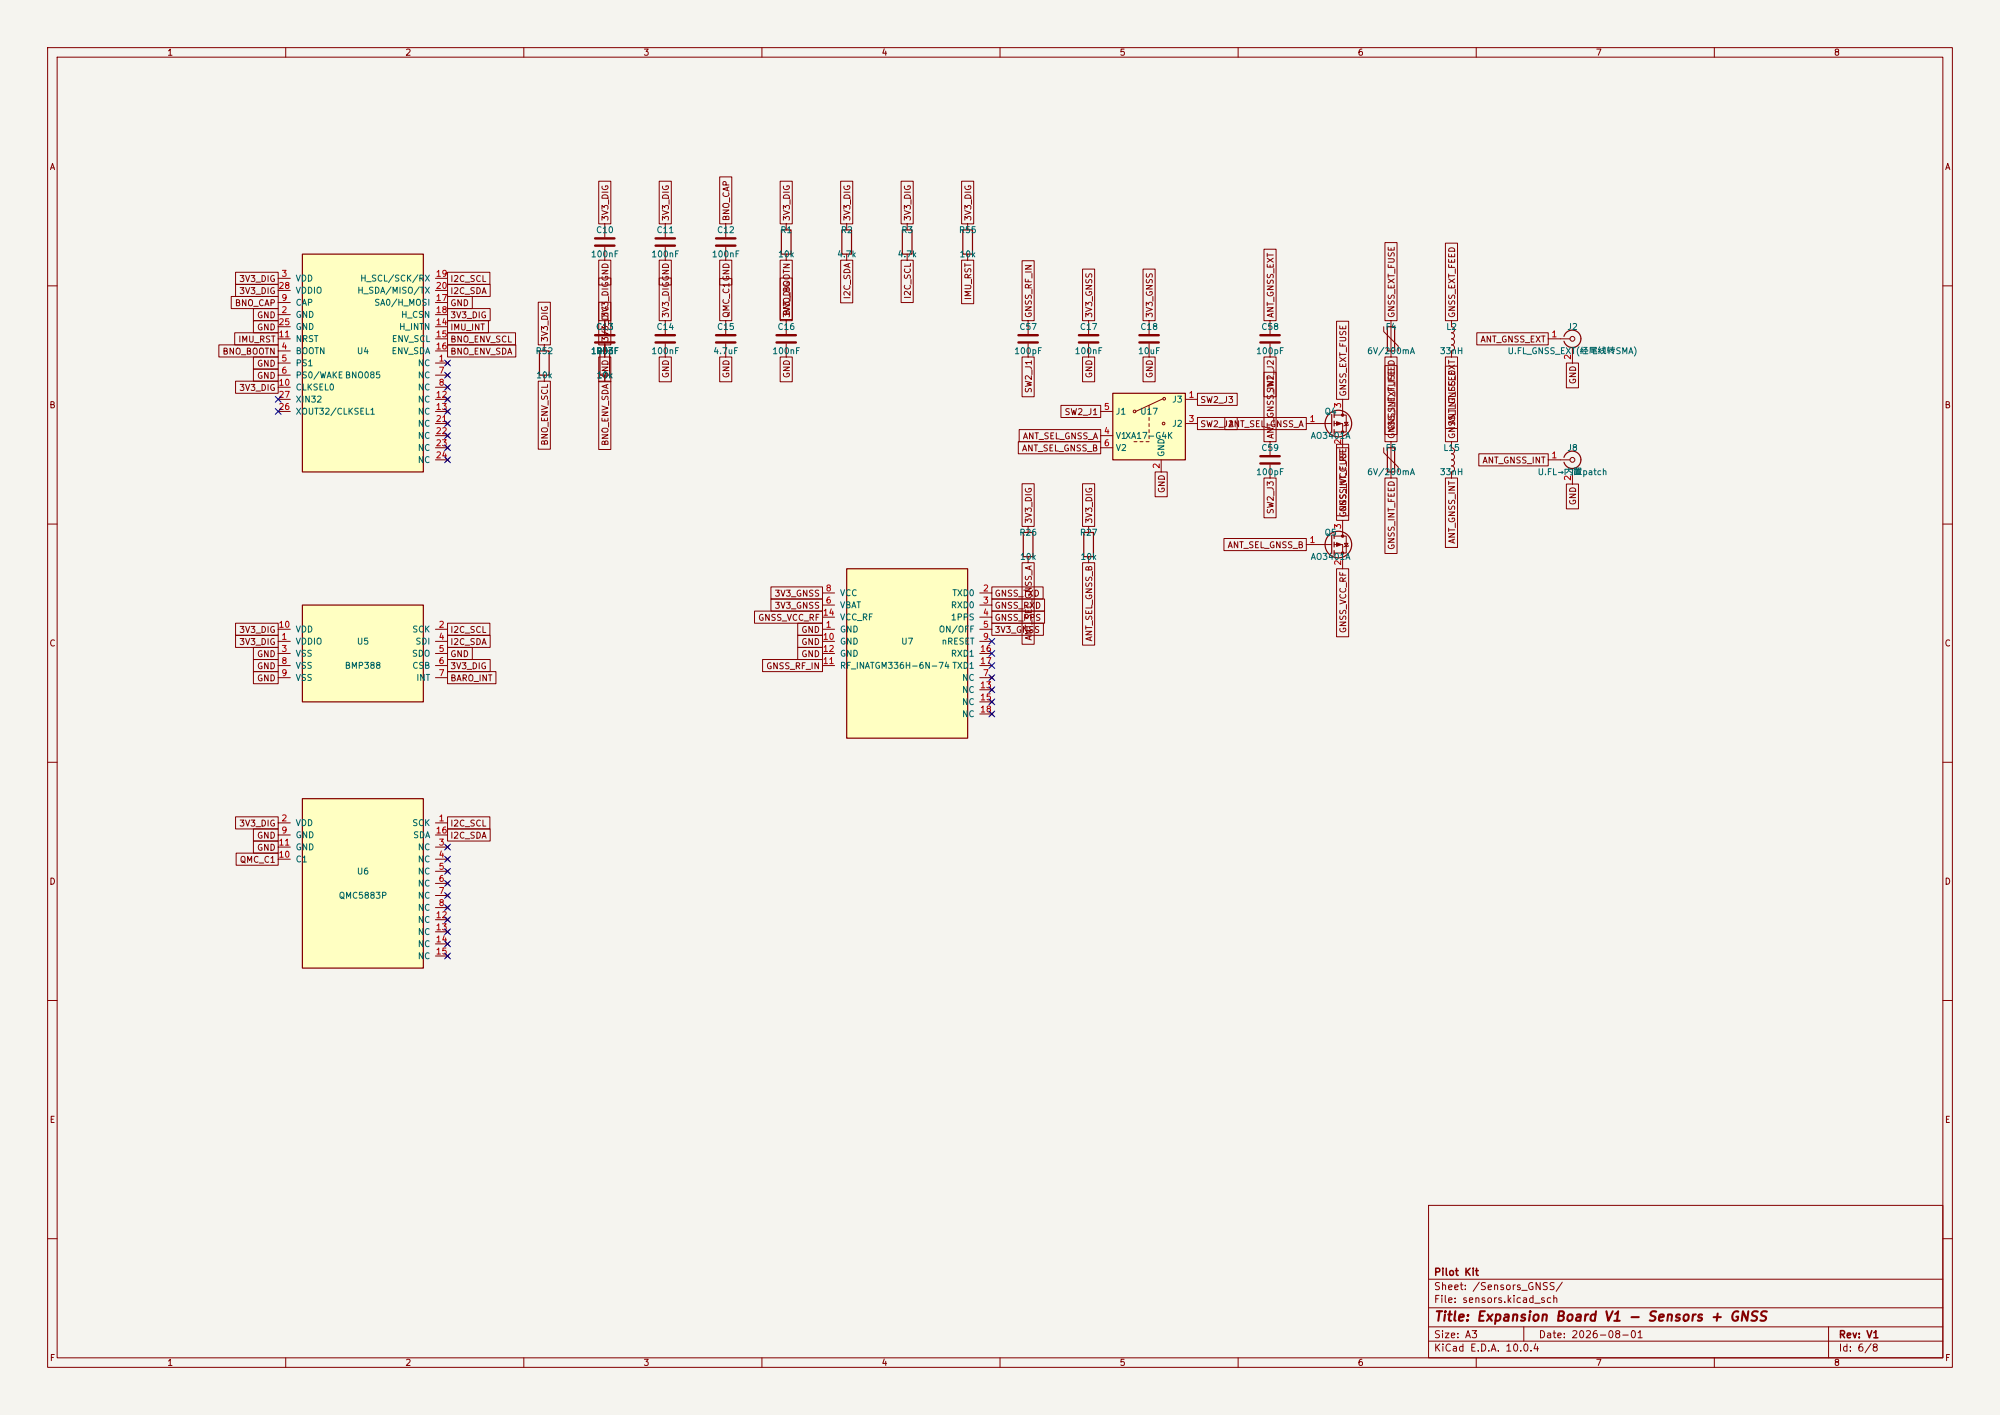
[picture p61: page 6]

SA0/H_MOSI 17 H_CSN 18 H_SCL/SCK/RX 19 H_SDA/MISO/TX 20 NC 21 NC 22 NC 23 NC 24 GND 25

Pilot Kit
Sheet: /Sensors_GNSS/
File: sensors.kicad_sch
Title: Expansion Board V1 - Sensors + GNSS


Pilot Kit
Sheet: /Interface_J3/
File: interface.kicad_sch
Title: Expansion Board V1 - Interface: J3 2x20 HAT socket


VCC 3
VRAMP 18 NC 19 NC 20 NC 21 NC 22 NC 23 NC 24
SCK 25
SCN 26
SDATA 27 GPIO0 28 GPIO1 29 GPIO2 30 GPIO3 31 GPIO4 32

Pilot Kit
Sheet: /RF_VHF/
File: rfvhf.kicad_sch
Title: Expansion Board V4.6 - VHF airband: BK4819 RX + PCM1808 capture

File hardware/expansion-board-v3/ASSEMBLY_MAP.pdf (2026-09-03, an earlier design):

# Expansion Board V3.10 Assembly Map

## Single-sided: all parts on F.Cu, back side empty; dashed = not populated


# Designator index


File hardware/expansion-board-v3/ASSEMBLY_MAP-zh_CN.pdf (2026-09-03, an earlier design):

# 扩展板 V3.10 装配图

## 单面装配：所有元件在正面 F.Cu，背面无元件；虚线框 = 不贴


# 位号速查表


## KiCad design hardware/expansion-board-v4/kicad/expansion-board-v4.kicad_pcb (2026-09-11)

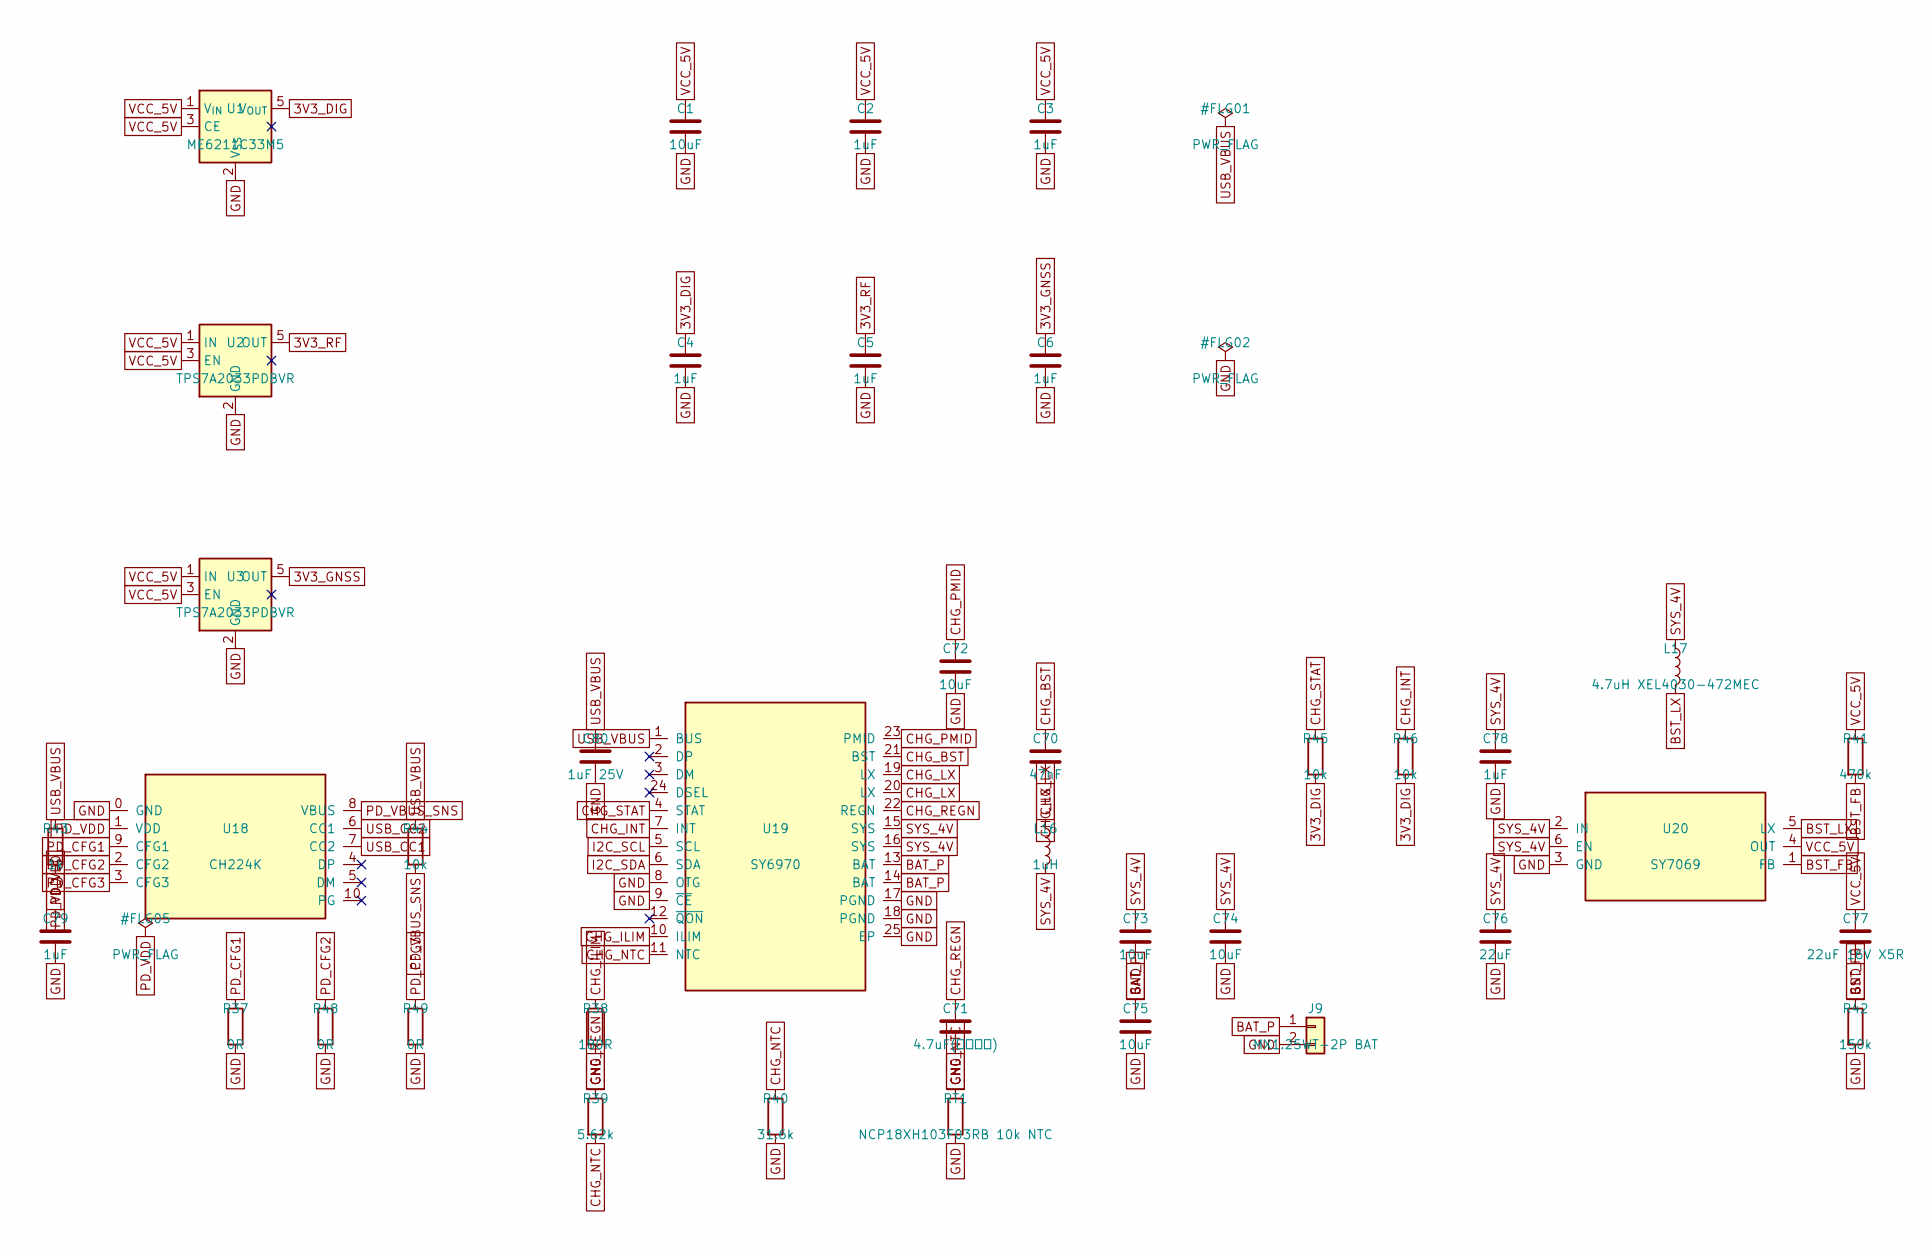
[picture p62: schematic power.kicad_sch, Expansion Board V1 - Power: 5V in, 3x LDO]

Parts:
C1, C73, C74, C75: 10uF; C_0805_2012Metric
C2, C3, C4, C6, C78, C79: 1uF; C_0603_1608Metric
C5: 1uF; C_0402_1005Metric
C70: 47nF; C_0603_1608Metric
C71: 4.7uF(带电源版); C_0603_1608Metric
C72: 10uF; C_1206_3216Metric
C76: 22uF; C_1206_3216Metric
C77: 22uF 16V X5R; C_1206_3216Metric
C80: 1uF 25V; C_0603_1608Metric
J9: MX1.25WT-2P BAT; MX1.25WT-2P_1x02-1MP_P1.25mm_Horizontal
L16: 1uH; L_Bourns-SRN4018
L17: 4.7uH XEL4030-472MEC; L_Coilcraft_XxL4030
R37, R48, R49: 0R; R_0603_1608Metric
R38: 180R; R_0603_1608Metric
R39: 5.62k; R_0603_1608Metric
R40: 31.6k; R_0603_1608Metric
R41: 470k; R_0603_1608Metric
R42: 150k; R_0603_1608Metric
R43: 1k; R_0603_1608Metric
R44, R45, R46: 10k; R_0603_1608Metric
RT1: NCP18XH103F03RB 10k NTC; R_0603_1608Metric
U1: ME6211C33M5; SOT-23-5
U2, U3: TPS7A2033PDBVR; SOT-23-5
U18: CH224K; CH224K_ESSOP-10
U19: SY6970; QFN-24-1EP_4x4mm_P0.5mm_EP2.6x2.6mm_ThermalVias
U20: SY7069; TSOT-23-6

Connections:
3V3_DIG: C4.1, R45.2, R46.2, U1.5 (V_{OUT}); also elsewhere on the board
3V3_GNSS: C6.1, U3.5 (OUT); also elsewhere on the board
3V3_RF: C5.1, U2.5 (OUT); also elsewhere on the board
BAT_P: C75.1, J9.1, U19.13 (BAT), U19.14 (BAT)
BST_FB: R41.2, R42.1, U20.1 (FB)
BST_LX: L17.2, U20.5 (LX)
CHG_BST: C70.1, U19.21 (BST)
CHG_ILIM: R38.1, U19.10 (ILIM)
CHG_INT: R46.1, U19.7 (INT)
CHG_LX: C70.2, L16.1, U19.19 (LX), U19.20 (LX)
CHG_NTC: R39.2, R40.1, RT1.1, U19.11 (NTC)
CHG_PMID: C72.1, U19.23 (PMID)
CHG_REGN: C71.1, R39.1, U19.22 (REGN)
CHG_STAT: R45.1, U19.4 (STAT)
GND: C1.2, C2.2, C3.2, C4.2, C5.2, C6.2, C71.2, C72.2, C73.2, C74.2, C75.2, C76.2, C77.2, C78.2, C79.2, C80.2, J9.2, R37.2, R38.2, R40.2, R42.2, R48.2, R49.2, RT1.2, U1.2 (V_{SS}), U2.2 (GND), U3.2 (GND), U18.0 (GND), U19.8 (OTG), U19.9 (~CE), U19.17 (PGND), U19.18 (PGND), U19.25 (EP), U20.3 (GND); also elsewhere on the board
I2C_SCL: U19.5 (SCL); also elsewhere on the board
I2C_SDA: U19.6 (SDA); also elsewhere on the board
PD_CFG1: R37.1, U18.9 (CFG1)
PD_CFG2: R48.1, U18.2 (CFG2)
PD_CFG3: R49.1, U18.3 (CFG3)
PD_VBUS_SNS: R44.2, U18.8 (VBUS)
PD_VDD: C79.1, R43.2, U18.1 (VDD)
SYS_4V: C73.1, C74.1, C76.1, C78.1, L16.2, L17.1, U19.15 (SYS), U19.16 (SYS), U20.2 (IN), U20.6 (EN)
USB_CC1: U18.7 (CC2); also elsewhere on the board
USB_CC2: U18.6 (CC1); also elsewhere on the board
USB_VBUS: C80.1, R43.1, R44.1, U19.1 (BUS); also elsewhere on the board
VCC_5V: C1.1, C2.1, C3.1, C77.1, R41.1, U1.1 (V_{IN}), U1.3 (CE), U2.1 (IN), U2.3 (EN), U3.1 (IN), U3.3 (EN), U20.4 (OUT); also elsewhere on the board

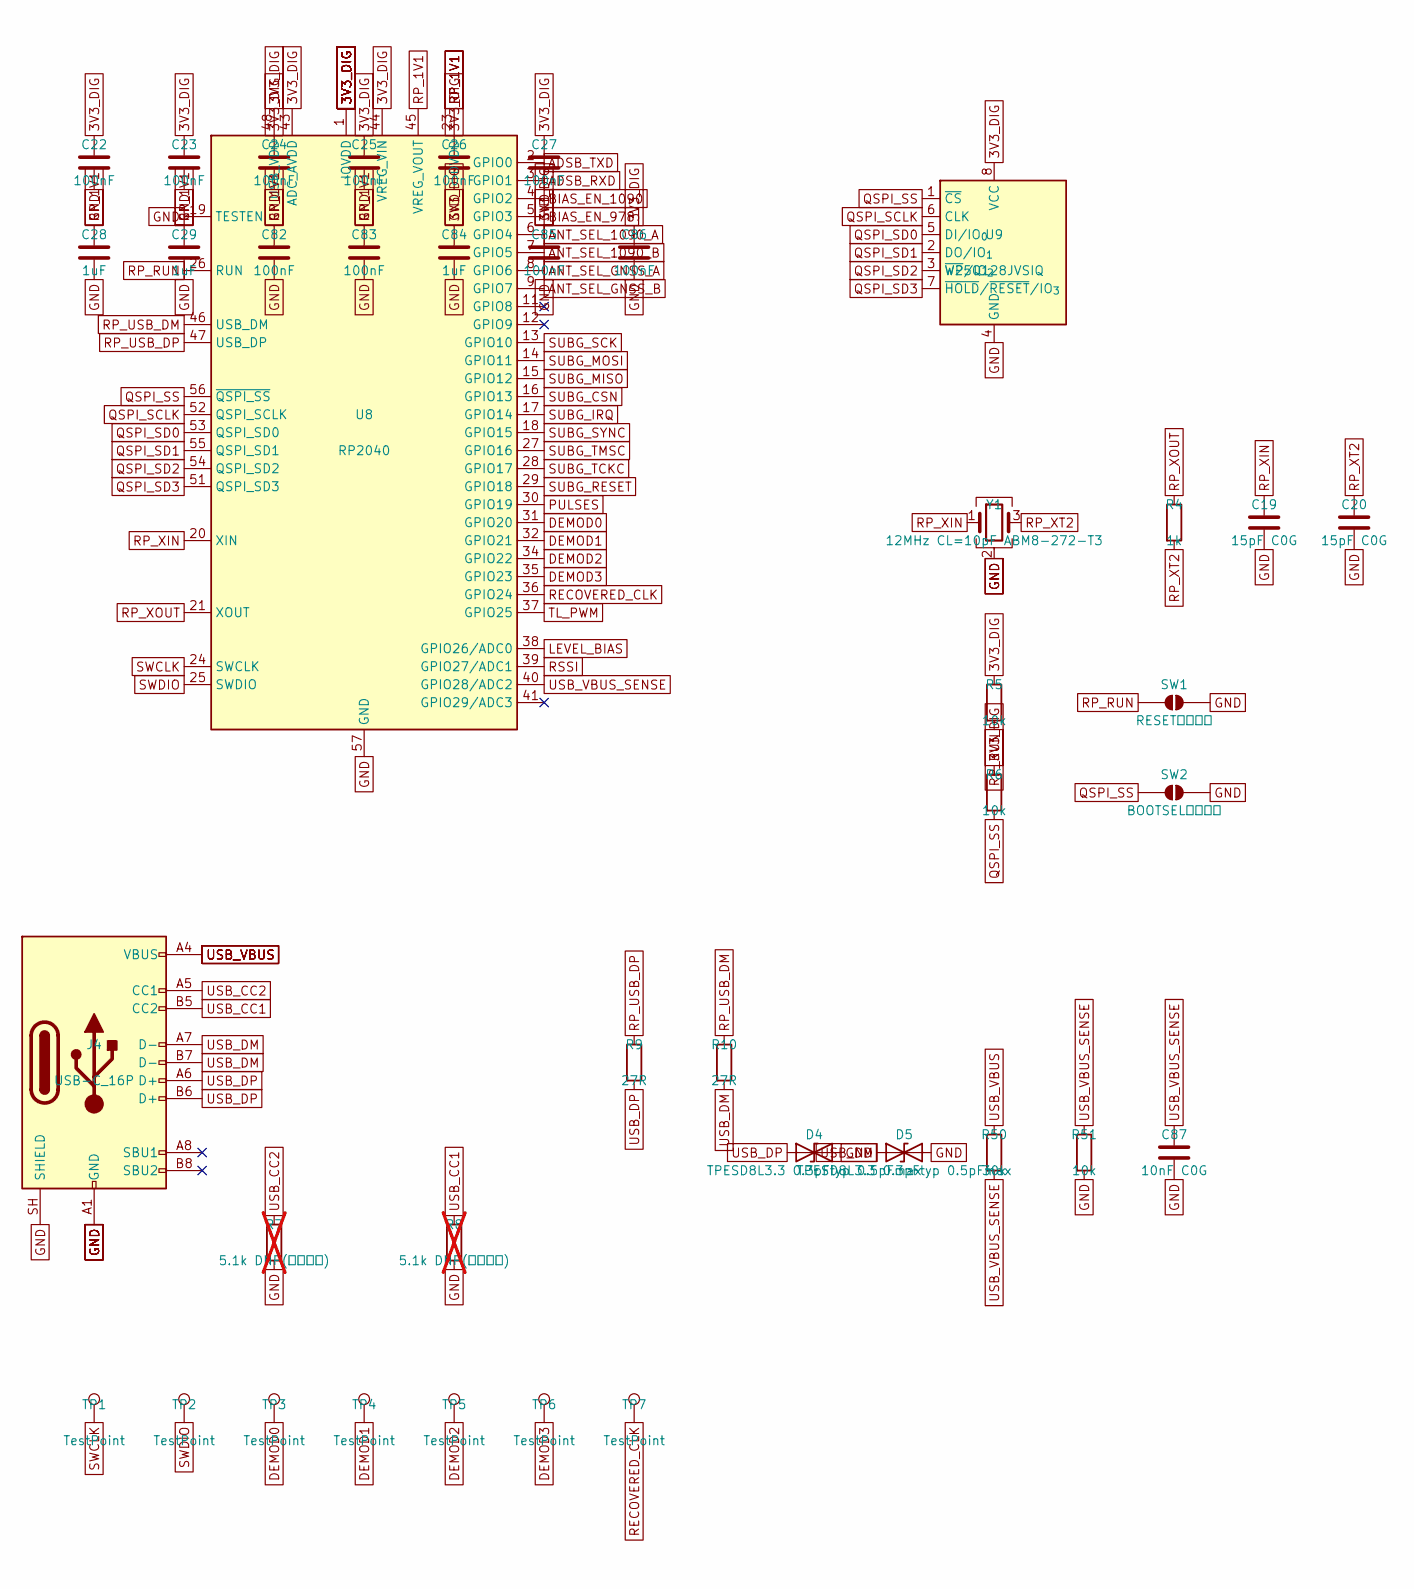
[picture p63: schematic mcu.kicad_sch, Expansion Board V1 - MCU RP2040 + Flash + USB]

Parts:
C19, C20: 15pF C0G; C_0603_1608Metric
C22, C23, C24, C25, C26, C27, C82, C83, C85, C86: 100nF; C_0603_1608Metric
C28, C29, C84: 1uF; C_0603_1608Metric
C87: 10nF C0G; C_0603_1608Metric
D4, D5: TPESD8L3.3 0.3pFtyp 0.5pFmax; D_0402_1005Metric
J4: USB-C_16P; USB_C_Receptacle_HRO_TYPE-C-31-M-12
R4: 1k; R_0603_1608Metric
R5, R6, R51: 10k; R_0603_1608Metric
R7, R8: 5.1k DNP(带电源版); R_0603_1608Metric; not fitted
R9, R10: 27R; R_0603_1608Metric
R50: 30k; R_0603_1608Metric
SW1: RESET短接焊盘; SolderJumper-2_P1.3mm_Open_Pad1.0x1.5mm
SW2: BOOTSEL短接焊盘; SolderJumper-2_P1.3mm_Open_Pad1.0x1.5mm
TP1, TP2, TP3, TP4, TP5, TP6, TP7: TestPoint; TestPoint_Pad_1.0x1.0mm
U8: RP2040; QFN-56-1EP_7x7mm_P0.4mm_EP3.2x3.2mm
U9: W25Q128JVSIQ; SOIC-8_5.3x5.3mm_P1.27mm
Y1: 12MHz CL=10pF ABM8-272-T3; Crystal_SMD_3225-4Pin_3.2x2.5mm

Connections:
3V3_DIG: C22.1, C23.1, C24.1, C25.1, C26.1, C27.1, C84.1, C85.1, C86.1, R5.1, R6.1, U8.1 (IOVDD), U8.10 (IOVDD), U8.22 (IOVDD), U8.33 (IOVDD), U8.42 (IOVDD), U8.43 (ADC_AVDD), U8.44 (VREG_VIN), U8.48 (USB_VDD), U8.49 (IOVDD), U9.8 (VCC); also elsewhere on the board
ADSB_RXD: U8.3 (GPIO1); also elsewhere on the board
ADSB_TXD: U8.2 (GPIO0); also elsewhere on the board
ANT_SEL_1090_A: U8.6 (GPIO4); also elsewhere on the board
ANT_SEL_1090_B: U8.7 (GPIO5); also elsewhere on the board
ANT_SEL_GNSS_A: U8.8 (GPIO6); also elsewhere on the board
ANT_SEL_GNSS_B: U8.9 (GPIO7); also elsewhere on the board
BIAS_EN_978: U8.5 (GPIO3); also elsewhere on the board
BIAS_EN_1090: U8.4 (GPIO2); also elsewhere on the board
DEMOD0: TP3.1, U8.31 (GPIO20)
DEMOD1: TP4.1, U8.32 (GPIO21)
DEMOD2: TP5.1, U8.34 (GPIO22)
DEMOD3: TP6.1, U8.35 (GPIO23)
GND: C19.2, C20.2, C22.2, C23.2, C24.2, C25.2, C26.2, C27.2, C28.2, C29.2, C82.2, C83.2, C84.2, C85.2, C86.2, C87.2, D4.2 (A2), D5.2 (A2), J4.A1 (GND), J4.A12 (GND), J4.B1 (GND), J4.B12 (GND), J4.SH (SHIELD), R7.2, R8.2, R51.2, SW1.2 (B), SW2.2 (B), U8.19 (TESTEN), U8.57 (GND), U9.4 (GND), Y1.2 (G), Y1.4 (G); also elsewhere on the board
LEVEL_BIAS: U8.38 (GPIO26/ADC0); also elsewhere on the board
PULSES: U8.30 (GPIO19); also elsewhere on the board
QSPI_SCLK: U8.52 (QSPI_SCLK), U9.6 (CLK)
QSPI_SD0: U8.53 (QSPI_SD0), U9.5 (DI/IO_{0})
QSPI_SD1: U8.55 (QSPI_SD1), U9.2 (DO/IO_{1})
QSPI_SD2: U8.54 (QSPI_SD2), U9.3 (~WP/IO_{2})
QSPI_SD3: U8.51 (QSPI_SD3), U9.7 (~HOLD/~RESET/IO_{3})
QSPI_SS: R6.2, SW2.1 (A), U8.56 (~QSPI_SS), U9.1 (~CS)
RECOVERED_CLK: TP7.1, U8.36 (GPIO24)
RP_1V1: C28.1, C29.1, C82.1, C83.1, U8.23 (DVDD), U8.45 (VREG_VOUT), U8.50 (DVDD)
RP_RUN: R5.2, SW1.1 (A), U8.26 (RUN)
RP_USB_DM: R10.1, U8.46 (USB_DM)
RP_USB_DP: R9.1, U8.47 (USB_DP)
RP_XIN: C19.1, U8.20 (XIN), Y1.1
RP_XOUT: R4.1, U8.21 (XOUT)
RP_XT2: C20.1, R4.2, Y1.3
RSSI: U8.39 (GPIO27/ADC1); also elsewhere on the board
SUBG_CSN: U8.16 (GPIO13); also elsewhere on the board
SUBG_IRQ: U8.17 (GPIO14); also elsewhere on the board
SUBG_MISO: U8.15 (GPIO12); also elsewhere on the board
SUBG_MOSI: U8.14 (GPIO11); also elsewhere on the board
SUBG_RESET: U8.29 (GPIO18); also elsewhere on the board
SUBG_SCK: U8.13 (GPIO10); also elsewhere on the board
SUBG_SYNC: U8.18 (GPIO15); also elsewhere on the board
SUBG_TCKC: U8.28 (GPIO17); also elsewhere on the board
SUBG_TMSC: U8.27 (GPIO16); also elsewhere on the board
SWCLK: TP1.1, U8.24 (SWCLK)
SWDIO: TP2.1, U8.25 (SWDIO)
TL_PWM: U8.37 (GPIO25); also elsewhere on the board
USB_CC1: J4.B5 (CC2), R8.1; also elsewhere on the board
USB_CC2: J4.A5 (CC1), R7.1; also elsewhere on the board
USB_DM: D5.1 (A1), J4.A7 (D-), J4.B7 (D-), R10.2
USB_DP: D4.1 (A1), J4.A6 (D+), J4.B6 (D+), R9.2
USB_VBUS: J4.A4 (VBUS), J4.A9 (VBUS), J4.B4 (VBUS), J4.B9 (VBUS), R50.1; also elsewhere on the board
USB_VBUS_SENSE: C87.1, R50.2, R51.1, U8.40 (GPIO28/ADC2)

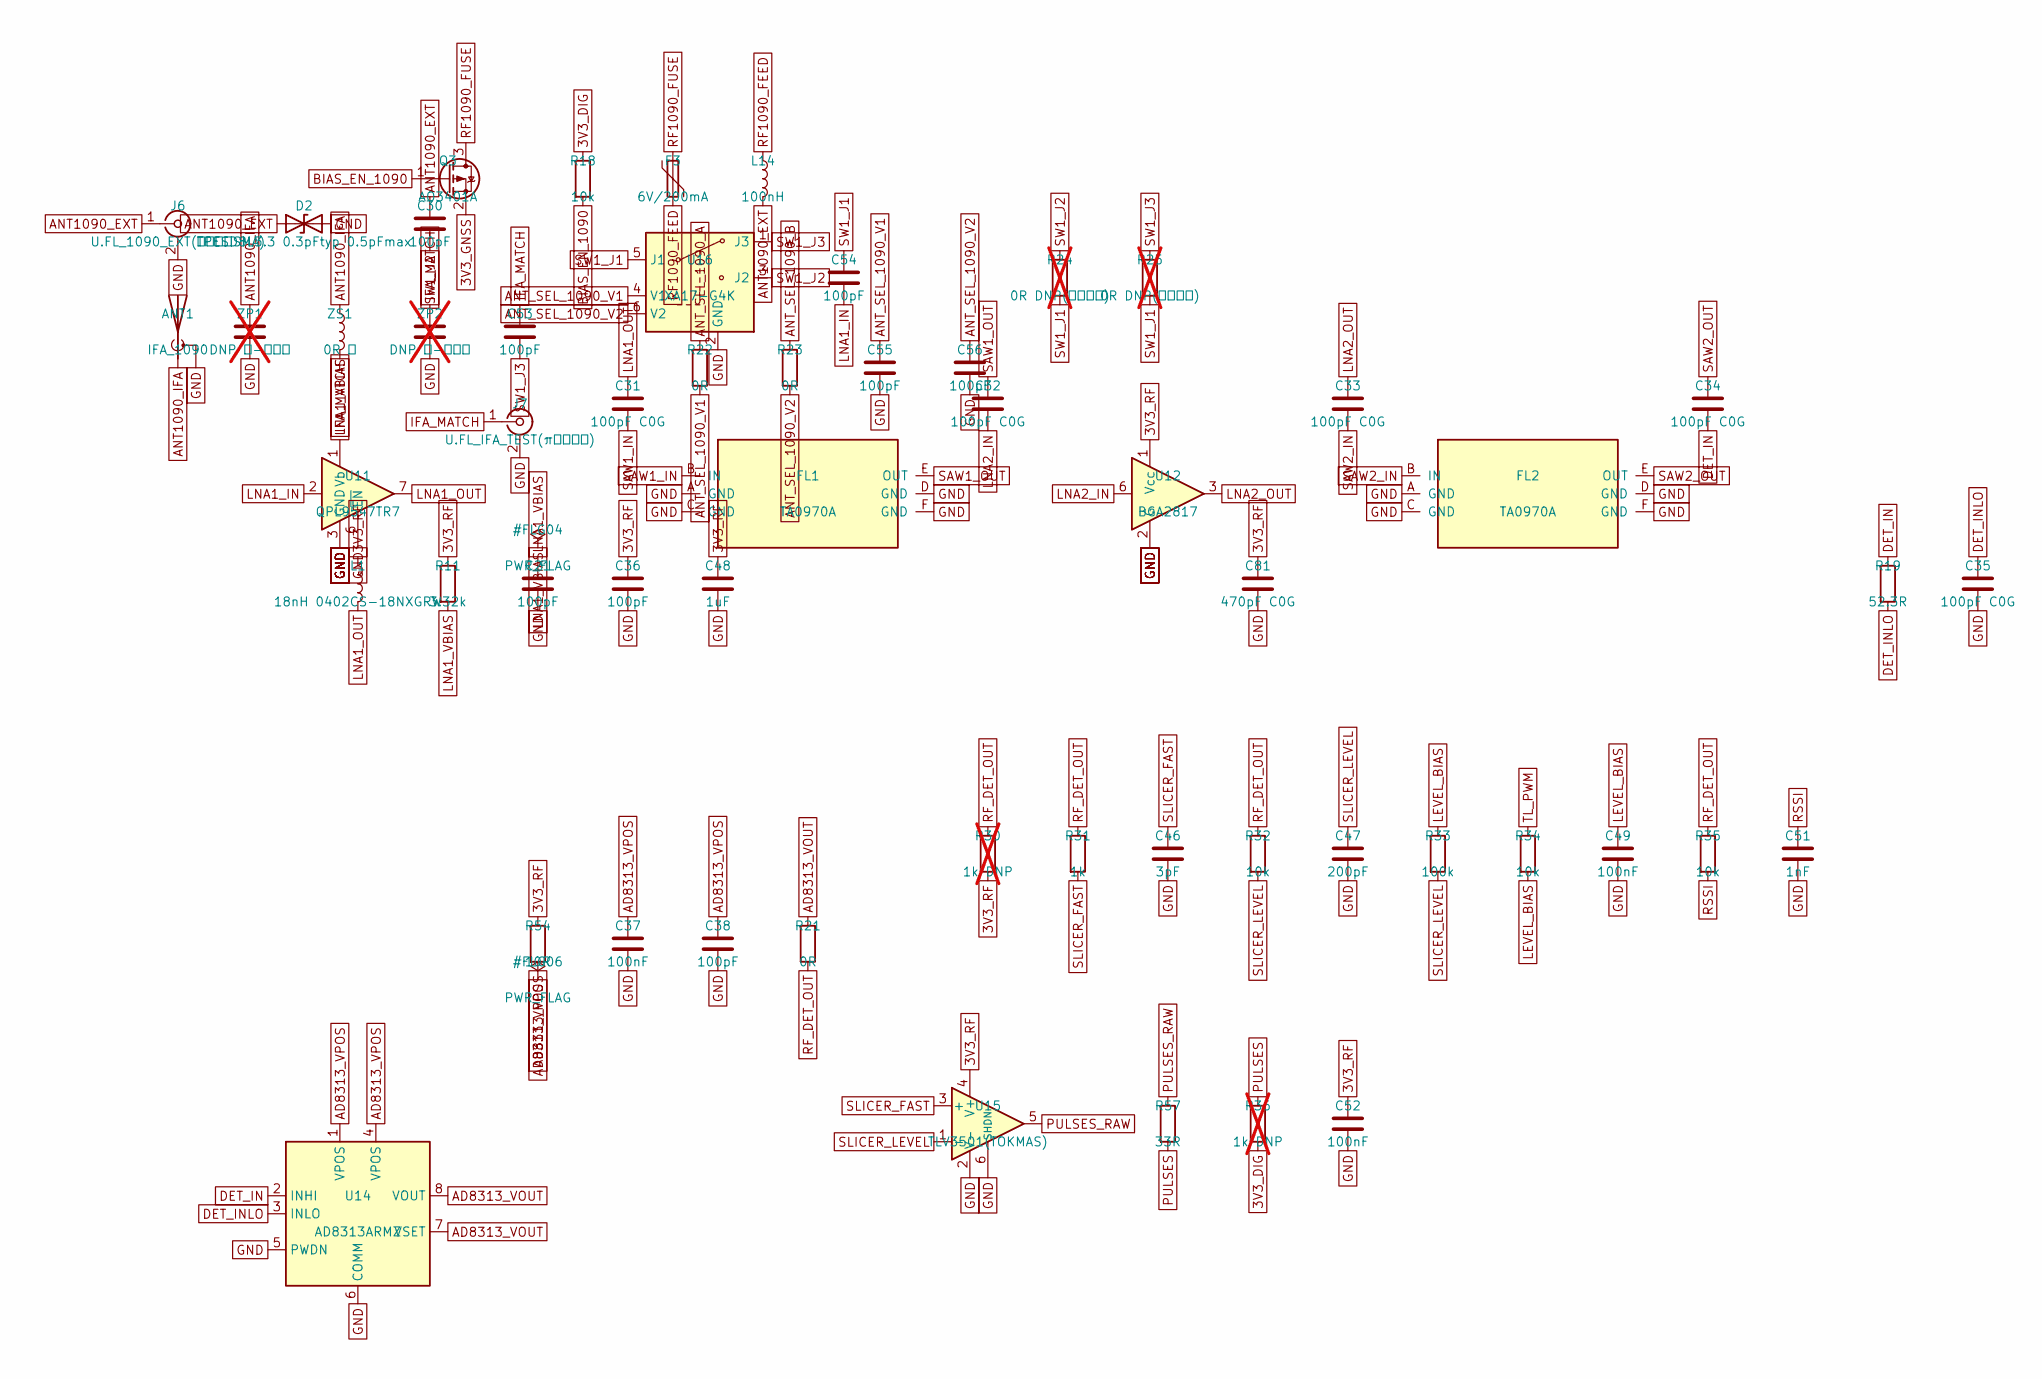
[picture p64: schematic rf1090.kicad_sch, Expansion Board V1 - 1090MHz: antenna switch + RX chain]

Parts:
ANT1: IFA_1090; ANT_IFA_1090MHz
C21, C30, C36, C38, C53, C54: 100pF; C_0402_1005Metric
C31, C32, C33, C34, C35: 100pF C0G; C_0402_1005Metric
C37, C52: 100nF; C_0402_1005Metric
C46: 3pF; C_0603_1608Metric
C47: 200pF; C_0603_1608Metric
C48: 1uF; C_0402_1005Metric
C49: 100nF; C_0603_1608Metric
C51: 1nF; C_0603_1608Metric
C55, C56: 100pF; C_0603_1608Metric
C81: 470pF C0G; C_0402_1005Metric
D2: TPESD8L3.3 0.3pFtyp 0.5pFmax; D_0402_1005Metric
F3: 6V/200mA; Fuse_0805_2012Metric
FL1, FL2: TA0970A; TA0970A_SMD3838-6
J6: U.FL_1090_EXT(经尾线转SMA); U.FL_Hirose_U.FL-R-SMT-1_Vertical
J7: U.FL_IFA_TEST(π后调试口); U.FL_Hirose_U.FL-R-SMT-1_Vertical
L1: 18nH 0402CS-18NXGRW; L_0402_1005Metric
L14: 100nH; L_0402_1005Metric
Q3: AO3401A; SOT-23
R11: 3.32k; R_0402_1005Metric
R18, R32, R34, R35: 10k; R_0603_1608Metric
R19: 52.3R; R_0402_1005Metric
R21, R22, R23: 0R; R_0603_1608Metric
R24: 0R DNP(旁路外接); R_0402_1005Metric; not fitted
R25: 0R DNP(旁路板载); R_0402_1005Metric; not fitted
R30: 1k DNP; R_0402_1005Metric; not fitted
R31: 1k; R_0603_1608Metric
R33: 100k; R_0603_1608Metric
R36: 1k DNP; R_0603_1608Metric; not fitted
R54: 10R; R_0402_1005Metric
R57: 33R; R_0603_1608Metric
U11: QPL9547TR7; DFN-8-1EP_2x2mm_P0.5mm_EP0.86x1.55mm
U12: BGA2817; SOT-363_SC-70-6
U14: AD8313ARMZ; MSOP-8_3x3mm_P0.65mm
U15: TLV3501(TOKMAS); SOT-23-6
U16: XA17-G4K; SOT-363_SC-70-6
ZP1: DNP 并-天线侧; C_0603_1608Metric; not fitted
ZP2: DNP 并-电台侧; C_0603_1608Metric; not fitted
ZS1: 0R 串; L_0603_1608Metric

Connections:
3V3_DIG: R18.1, R36.2; also elsewhere on the board
3V3_GNSS: Q3.2 (S); also elsewhere on the board
3V3_RF: C36.1, C48.1, C52.1, C81.1, L1.1, R11.1, R30.2, R54.1, U12.1 (Vcc), U15.4 (V+); also elsewhere on the board
AD8313_VOUT: R21.1, U14.7 (VSET), U14.8 (VOUT)
AD8313_VPOS: C37.1, C38.1, R54.2, U14.1 (VPOS), U14.4 (VPOS)
ANT1090_EXT: C30.1, D2.1 (A1), J6.1 (In), L14.2
ANT1090_IFA: ANT1.1 (A), ZP1.1, ZS1.1
ANT_SEL_1090_A: R22.1; also elsewhere on the board
ANT_SEL_1090_B: R23.1; also elsewhere on the board
ANT_SEL_1090_V1: C55.1, R22.2, U16.4 (V1)
ANT_SEL_1090_V2: C56.1, R23.2, U16.6 (V2)
BIAS_EN_1090: Q3.1 (G), R18.2; also elsewhere on the board
DET_IN: C34.2, R19.1, U14.2 (INHI)
DET_INLO: C35.1, R19.2, U14.3 (INLO)
GND: ANT1.2 (Shield), C21.2, C35.2, C36.2, C37.2, C38.2, C46.2, C47.2, C48.2, C49.2, C51.2, C52.2, C55.2, C56.2, C81.2, D2.2 (A2), FL1.A (GND), FL1.C (GND), FL1.D (GND), FL1.F (GND), FL2.A (GND), FL2.C (GND), FL2.D (GND), FL2.F (GND), J6.2 (Ext), J7.2 (Ext), U11.3 (GND), U11.4 (GND), U11.5 (GND), U11.6 (~EN), U11.8 (GND), U11.9 (GND), U12.2 (G), U12.4 (G), U12.5 (G), U14.5 (PWDN), U14.6 (COMM), U15.2 (V-), U15.6 (SHDN), U16.2 (GND), ZP1.2, ZP2.2; also elsewhere on the board
IFA_MATCH: C53.1, J7.1 (In), ZP2.1, ZS1.2
LEVEL_BIAS: C49.1, R33.1, R34.2; also elsewhere on the board
LNA1_IN: C54.2, U11.2
LNA1_OUT: C31.1, L1.2, U11.7
LNA1_VBIAS: C21.1, R11.2, U11.1 (Vb)
LNA2_IN: C32.2, U12.6
LNA2_OUT: C33.1, U12.3
PULSES: R36.1, R57.2; also elsewhere on the board
PULSES_RAW: R57.1, U15.5
RF1090_FEED: F3.2, L14.1
RF1090_FUSE: F3.1, Q3.3 (D)
RF_DET_OUT: R21.2, R30.1, R31.1, R32.1, R35.1
RSSI: C51.1, R35.2; also elsewhere on the board
SAW1_IN: C31.2, FL1.B (IN)
SAW1_OUT: C32.1, FL1.E (OUT)
SAW2_IN: C33.2, FL2.B (IN)
SAW2_OUT: C34.1, FL2.E (OUT)
SLICER_FAST: C46.1, R31.2, U15.3 (+)
SLICER_LEVEL: C47.1, R32.2, R33.2, U15.1 (-)
SW1_J1: C54.1, R24.2, R25.2, U16.5 (J1)
SW1_J2: C30.2, R24.1, U16.3 (J2)
SW1_J3: C53.2, R25.1, U16.1 (J3)
TL_PWM: R34.1; also elsewhere on the board

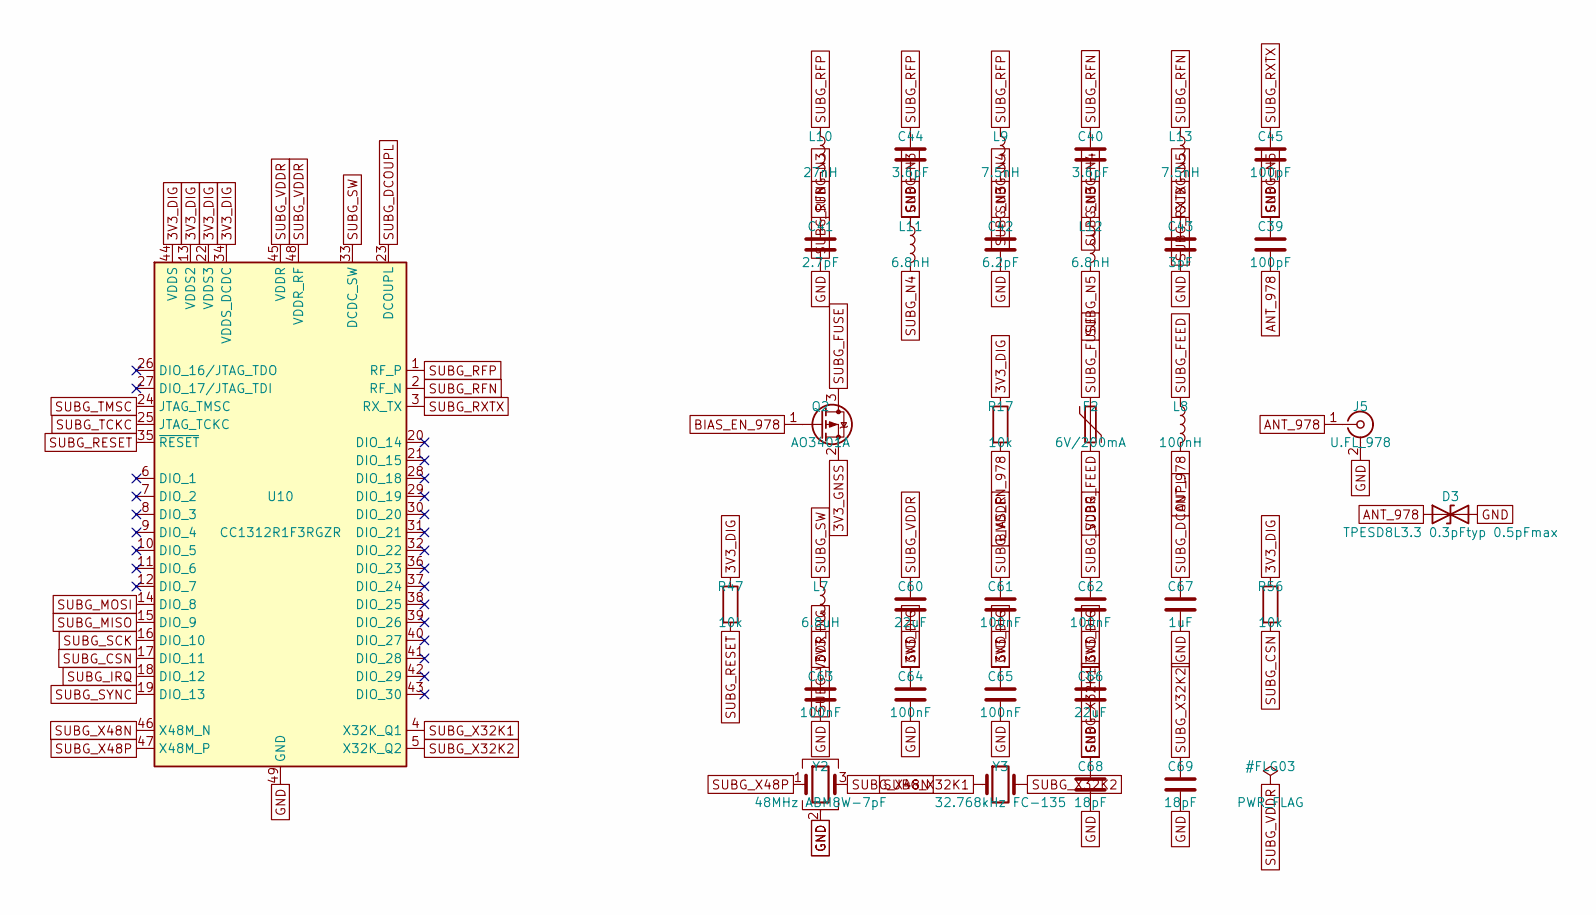
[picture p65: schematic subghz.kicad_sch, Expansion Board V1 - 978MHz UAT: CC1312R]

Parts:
C39, C45: 100pF; C_0402_1005Metric
C40, C44: 3.6pF; C_0402_1005Metric
C41: 2.7pF; C_0402_1005Metric
C42: 6.2pF; C_0402_1005Metric
C43: 3pF; C_0402_1005Metric
C60, C66: 22uF; C_0805_2012Metric
C61, C62, C63, C64, C65: 100nF; C_0603_1608Metric
C67: 1uF; C_0603_1608Metric
C68, C69: 18pF; C_0603_1608Metric
D3: TPESD8L3.3 0.3pFtyp 0.5pFmax; D_0402_1005Metric
F2: 6V/200mA; Fuse_0805_2012Metric
J5: U.FL_978; U.FL_Hirose_U.FL-R-SMT-1_Vertical
L7: 6.8uH; L_0805_2012Metric
L8: 100nH; L_0402_1005Metric
L9, L13: 7.5nH; L_0402_1005Metric
L10: 27nH; L_0402_1005Metric
L11, L12: 6.8nH; L_0402_1005Metric
Q2: AO3401A; SOT-23
R17, R47, R56: 10k; R_0603_1608Metric
U10: CC1312R1F3RGZR; QFN-48-1EP_7x7mm_P0.5mm_EP5.15x5.15mm
Y2: 48MHz ABM8W-7pF; Crystal_SMD_3225-4Pin_3.2x2.5mm
Y3: 32.768kHz FC-135; Crystal_SMD_3215-2Pin_3.2x1.5mm

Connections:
3V3_DIG: C63.1, C64.1, C65.1, C66.1, R17.1, R47.1, R56.1, U10.13 (VDDS2), U10.22 (VDDS3), U10.34 (VDDS_DCDC), U10.44 (VDDS); also elsewhere on the board
3V3_GNSS: Q2.2 (S); also elsewhere on the board
ANT_978: C39.2, D3.1 (A1), J5.1 (In), L8.2
BIAS_EN_978: Q2.1 (G), R17.2; also elsewhere on the board
GND: C41.2, C42.2, C43.2, C44.2, C45.2, C60.2, C61.2, C62.2, C63.2, C64.2, C65.2, C66.2, C67.2, C68.2, C69.2, D3.2 (A2), J5.2 (Ext), U10.49 (GND), Y2.2 (G), Y2.4 (G); also elsewhere on the board
SUBG_CSN: R56.2, U10.17 (DIO_11); also elsewhere on the board
SUBG_DCOUPL: C67.1, U10.23 (DCOUPL)
SUBG_FEED: F2.2, L8.1
SUBG_FUSE: F2.1, Q2.3 (D)
SUBG_IRQ: U10.18 (DIO_12); also elsewhere on the board
SUBG_MISO: U10.15 (DIO_9); also elsewhere on the board
SUBG_MOSI: U10.14 (DIO_8); also elsewhere on the board
SUBG_N3: C40.2, C41.1, L9.2, L11.1
SUBG_N4: C42.1, L11.2, L12.1
SUBG_N5: C39.1, C43.1, L12.2
SUBG_RESET: R47.2, U10.35 (~RESET); also elsewhere on the board
SUBG_RFN: C40.1, L10.2, L13.1, U10.2 (RF_N)
SUBG_RFP: C44.1, L9.1, L10.1, U10.1 (RF_P)
SUBG_RXTX: C45.1, L13.2, U10.3 (RX_TX)
SUBG_SCK: U10.16 (DIO_10); also elsewhere on the board
SUBG_SW: L7.1, U10.33 (DCDC_SW)
SUBG_SYNC: U10.19 (DIO_13); also elsewhere on the board
SUBG_TCKC: U10.25 (JTAG_TCKC); also elsewhere on the board
SUBG_TMSC: U10.24 (JTAG_TMSC); also elsewhere on the board
SUBG_VDDR: C60.1, C61.1, C62.1, L7.2, U10.45 (VDDR), U10.48 (VDDR_RF)
SUBG_X32K1: C68.1, U10.4 (X32K_Q1), Y3.1
SUBG_X32K2: C69.1, U10.5 (X32K_Q2), Y3.2
SUBG_X48N: U10.46 (X48M_N), Y2.3
SUBG_X48P: U10.47 (X48M_P), Y2.1

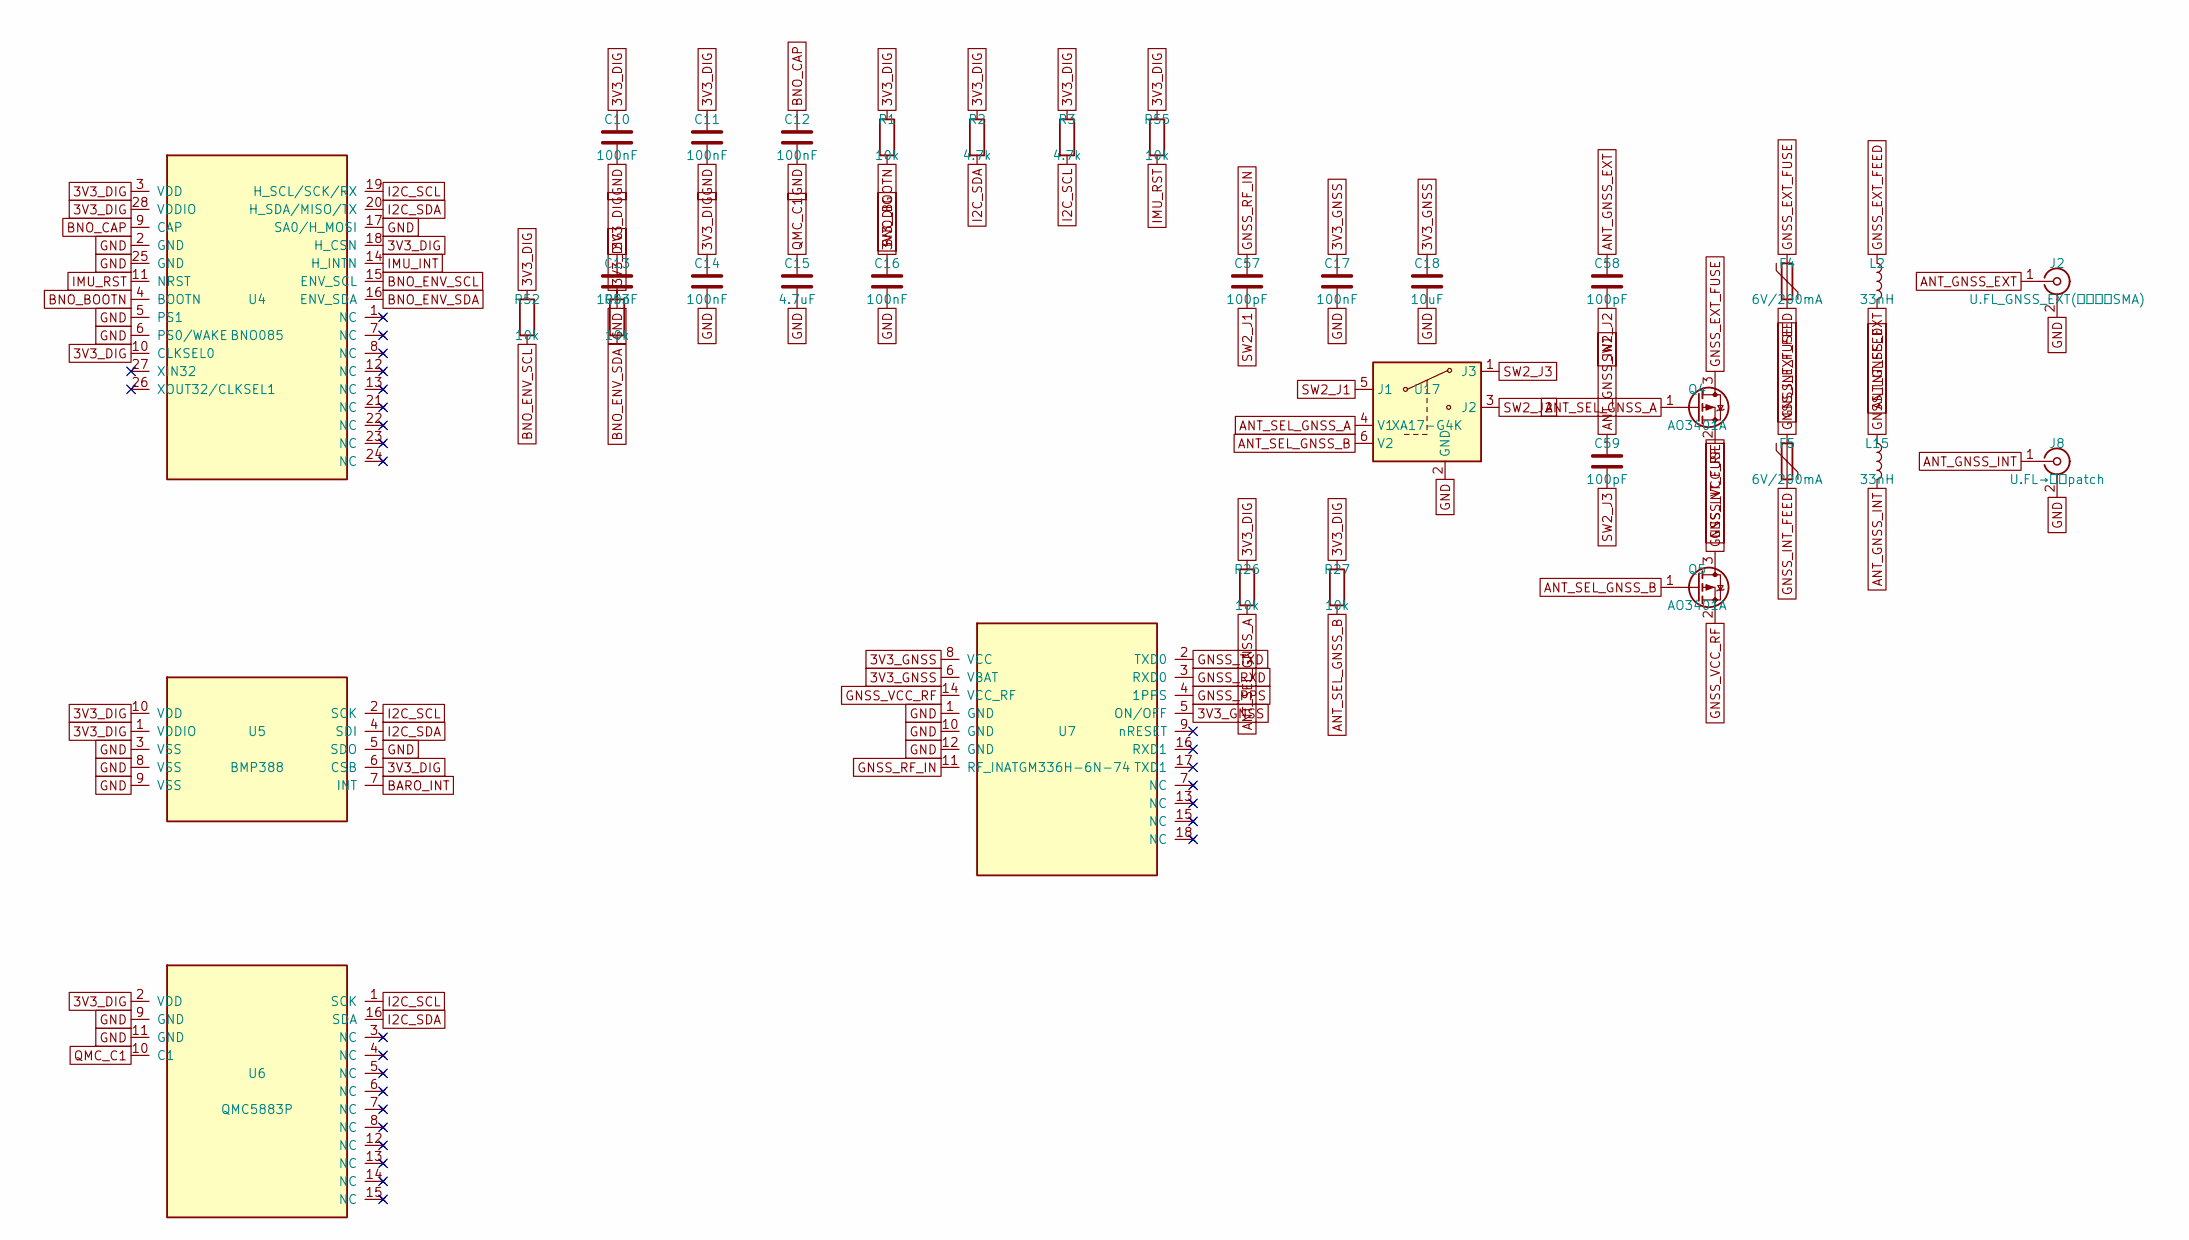
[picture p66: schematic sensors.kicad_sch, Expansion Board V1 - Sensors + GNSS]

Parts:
C10, C11, C12, C13, C14, C16, C17: 100nF; C_0603_1608Metric
C15: 4.7uF; C_0603_1608Metric
C18: 10uF; C_0805_2012Metric
C57, C58, C59: 100pF; C_0402_1005Metric
F4, F5: 6V/200mA; Fuse_0805_2012Metric
J2: U.FL_GNSS_EXT(经尾线转SMA); U.FL_Hirose_U.FL-R-SMT-1_Vertical
J8: U.FL→内置patch; U.FL_Hirose_U.FL-R-SMT-1_Vertical
L2, L15: 33nH; L_0402_1005Metric
Q4, Q5: AO3401A; SOT-23
R1, R26, R27, R55: 10k; R_0603_1608Metric
R2, R3: 4.7k; R_0603_1608Metric
R52, R53: 10k; R_0402_1005Metric
U4: BNO085; BNO085_LGA-28
U5: BMP388; BMP388_LGA-10
U6: QMC5883P; LGA-16_3x3mm_P0.5mm
U7: ATGM336H-6N-74; ATGM336H_LCC-18
U17: XA17-G4K; SOT-363_SC-70-6

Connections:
3V3_DIG: C10.1, C11.1, C13.1, C14.1, C16.1, R1.1, R2.1, R3.1, R26.1, R27.1, R52.1, R53.1, R55.1, U4.3 (VDD), U4.10 (CLKSEL0), U4.18 (H_CSN), U4.28 (VDDIO), U5.1 (VDDIO), U5.6 (CSB), U5.10 (VDD), U6.2 (VDD); also elsewhere on the board
3V3_GNSS: C17.1, C18.1, U7.5 (ON/OFF), U7.6 (VBAT), U7.8 (VCC); also elsewhere on the board
ANT_GNSS_EXT: C58.1, J2.1 (In), L2.2
ANT_GNSS_INT: C59.1, J8.1 (In), L15.2
ANT_SEL_GNSS_A: Q4.1 (G), R26.2, U17.4 (V1); also elsewhere on the board
ANT_SEL_GNSS_B: Q5.1 (G), R27.2, U17.6 (V2); also elsewhere on the board
BARO_INT: U5.7 (INT); also elsewhere on the board
BNO_BOOTN: R1.2, U4.4 (BOOTN)
BNO_CAP: C12.1, U4.9 (CAP)
BNO_ENV_SCL: R52.2, U4.15 (ENV_SCL)
BNO_ENV_SDA: R53.2, U4.16 (ENV_SDA)
GND: C10.2, C11.2, C12.2, C13.2, C14.2, C15.2, C16.2, C17.2, C18.2, J2.2 (Ext), J8.2 (Ext), U4.2 (GND), U4.5 (PS1), U4.6 (PS0/WAKE), U4.17 (SA0/H_MOSI), U4.25 (GND), U5.3 (VSS), U5.5 (SDO), U5.8 (VSS), U5.9 (VSS), U6.9 (GND), U6.11 (GND), U7.1 (GND), U7.10 (GND), U7.12 (GND), U17.2 (GND); also elsewhere on the board
GNSS_EXT_FEED: F4.2, L2.1
GNSS_EXT_FUSE: F4.1, Q4.3 (D)
GNSS_INT_FEED: F5.2, L15.1
GNSS_INT_FUSE: F5.1, Q5.3 (D)
GNSS_PPS: U7.4 (1PPS); also elsewhere on the board
GNSS_RF_IN: C57.1, U7.11 (RF_IN)
GNSS_RXD: U7.3 (RXD0); also elsewhere on the board
GNSS_TXD: U7.2 (TXD0); also elsewhere on the board
GNSS_VCC_RF: Q4.2 (S), Q5.2 (S), U7.14 (VCC_RF)
I2C_SCL: R3.2, U4.19 (H_SCL/SCK/RX), U5.2 (SCK), U6.1 (SCK); also elsewhere on the board
I2C_SDA: R2.2, U4.20 (H_SDA/MISO/TX), U5.4 (SDI), U6.16 (SDA); also elsewhere on the board
IMU_INT: U4.14 (H_INTN); also elsewhere on the board
IMU_RST: R55.2, U4.11 (NRST); also elsewhere on the board
QMC_C1: C15.1, U6.10 (C1)
SW2_J1: C57.2, U17.5 (J1)
SW2_J2: C58.2, U17.3 (J2)
SW2_J3: C59.2, U17.1 (J3)

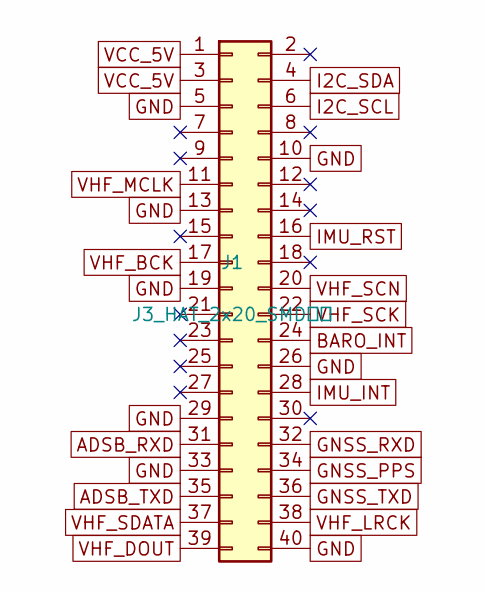
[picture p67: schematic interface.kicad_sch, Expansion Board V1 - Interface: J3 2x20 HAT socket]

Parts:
J1: J3_HAT_2x20_SMD排针; PinHeader_2x20_P2.54mm_Vertical_SMD

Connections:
ADSB_RXD: J1.31; also elsewhere on the board
ADSB_TXD: J1.35; also elsewhere on the board
BARO_INT: J1.24; also elsewhere on the board
GND: J1.5, J1.10, J1.13, J1.19, J1.26, J1.29, J1.33, J1.40; also elsewhere on the board
GNSS_PPS: J1.34; also elsewhere on the board
GNSS_RXD: J1.32; also elsewhere on the board
GNSS_TXD: J1.36; also elsewhere on the board
I2C_SCL: J1.6; also elsewhere on the board
I2C_SDA: J1.4; also elsewhere on the board
IMU_INT: J1.28; also elsewhere on the board
IMU_RST: J1.16; also elsewhere on the board
VCC_5V: J1.1, J1.3; also elsewhere on the board
VHF_BCK: J1.17; also elsewhere on the board
VHF_DOUT: J1.39; also elsewhere on the board
VHF_LRCK: J1.38; also elsewhere on the board
VHF_MCLK: J1.11; also elsewhere on the board
VHF_SCK: J1.22; also elsewhere on the board
VHF_SCN: J1.20; also elsewhere on the board
VHF_SDATA: J1.37; also elsewhere on the board

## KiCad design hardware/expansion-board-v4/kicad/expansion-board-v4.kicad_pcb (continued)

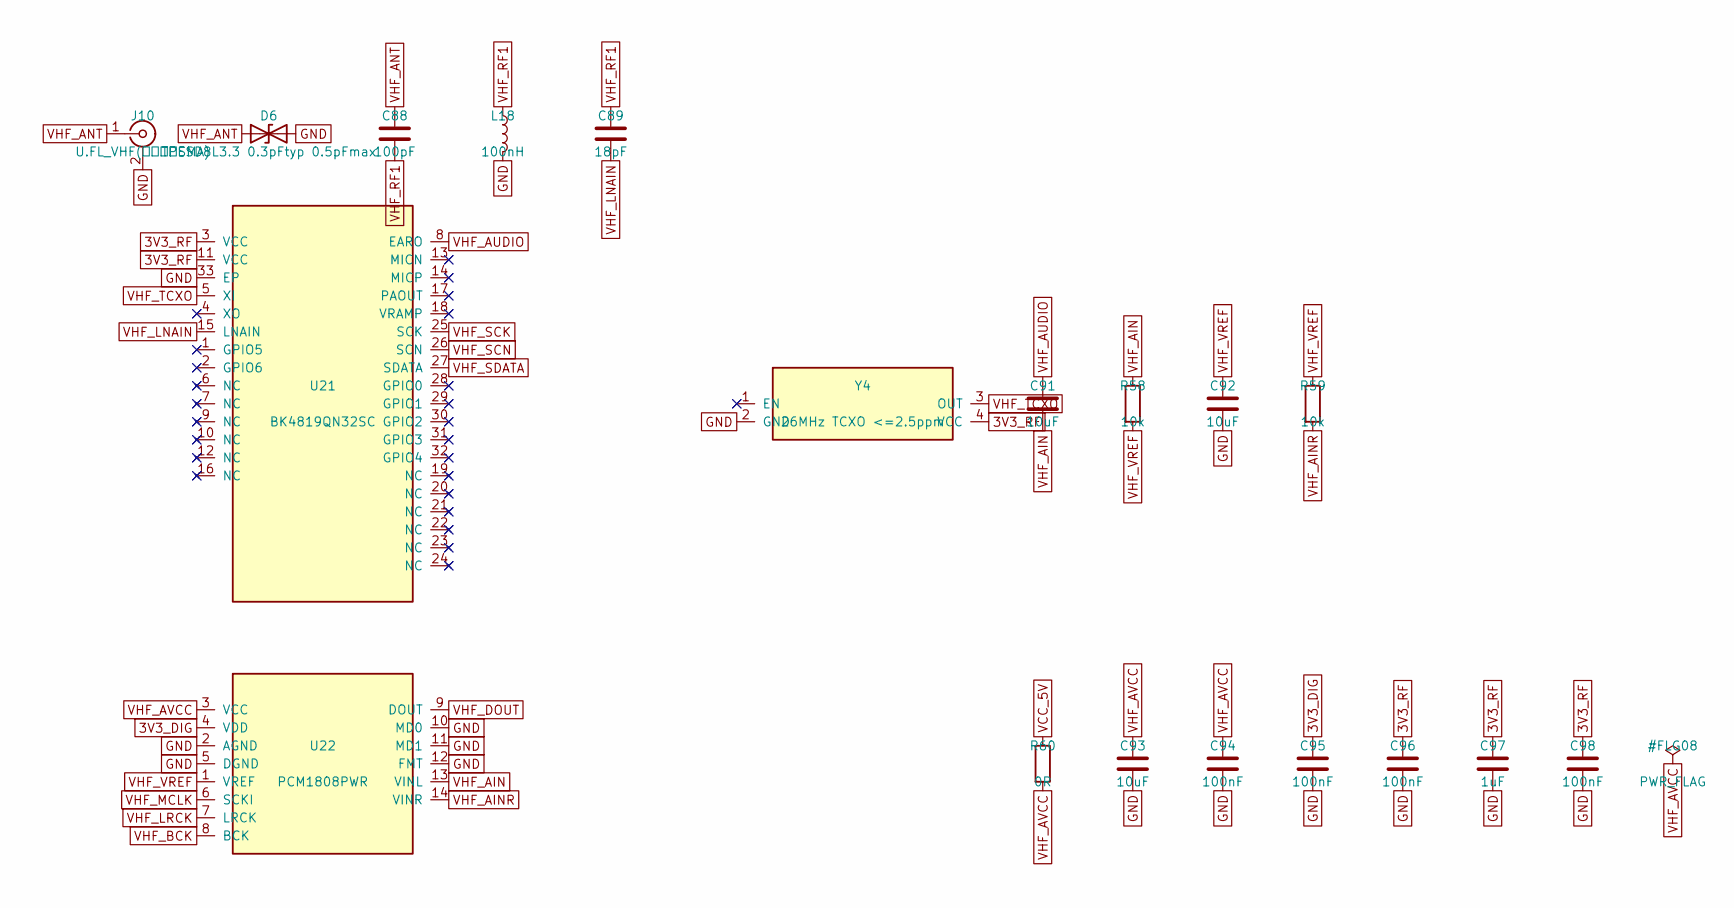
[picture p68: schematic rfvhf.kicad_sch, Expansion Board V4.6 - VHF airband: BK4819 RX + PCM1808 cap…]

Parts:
C88: 100pF; C_0603_1608Metric
C89: 18pF; C_0603_1608Metric
C91, C92, C93: 10uF; C_0805_2012Metric
C94, C95, C96, C98: 100nF; C_0603_1608Metric
C97: 1uF; C_0603_1608Metric
D6: TPESD8L3.3 0.3pFtyp 0.5pFmax; D_0402_1005Metric
J10: U.FL_VHF(经尾线转SMA); U.FL_Hirose_U.FL-R-SMT-1_Vertical
L18: 100nH; L_0402_1005Metric
R58, R59: 10k; R_0603_1608Metric
R60: 0R; R_0603_1608Metric
U21: BK4819QN32SC; QFN-32-1EP_4x4mm_P0.4mm_EP2.65x2.65mm
U22: PCM1808PWR; TSSOP-14_4.4x5mm_P0.65mm
Y4: 26MHz TCXO <=2.5ppm; Crystal_SMD_2520-4Pin_2.5x2.0mm

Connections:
3V3_DIG: C95.1, U22.4 (VDD); also elsewhere on the board
3V3_RF: C96.1, C97.1, C98.1, U21.3 (VCC), U21.11 (VCC), Y4.4 (VCC); also elsewhere on the board
GND: C92.2, C93.2, C94.2, C95.2, C96.2, C97.2, C98.2, D6.2 (A2), J10.2 (Ext), L18.2, U21.33 (EP), U22.2 (AGND), U22.5 (DGND), U22.10 (MD0), U22.11 (MD1), U22.12 (FMT), Y4.2 (GND); also elsewhere on the board
VCC_5V: R60.1; also elsewhere on the board
VHF_AIN: C91.2, R58.1, U22.13 (VINL)
VHF_AINR: R59.2, U22.14 (VINR)
VHF_ANT: C88.1, D6.1 (A1), J10.1 (In)
VHF_AUDIO: C91.1, U21.8 (EARO)
VHF_AVCC: C93.1, C94.1, R60.2, U22.3 (VCC)
VHF_BCK: U22.8 (BCK); also elsewhere on the board
VHF_DOUT: U22.9 (DOUT); also elsewhere on the board
VHF_LNAIN: C89.2, U21.15 (LNAIN)
VHF_LRCK: U22.7 (LRCK); also elsewhere on the board
VHF_MCLK: U22.6 (SCKI); also elsewhere on the board
VHF_RF1: C88.2, C89.1, L18.1
VHF_SCK: U21.25 (SCK); also elsewhere on the board
VHF_SCN: U21.26 (SCN); also elsewhere on the board
VHF_SDATA: U21.27 (SDATA); also elsewhere on the board
VHF_TCXO: U21.5 (XI), Y4.3 (OUT)
VHF_VREF: C92.1, R58.2, R59.1, U22.1 (VREF)

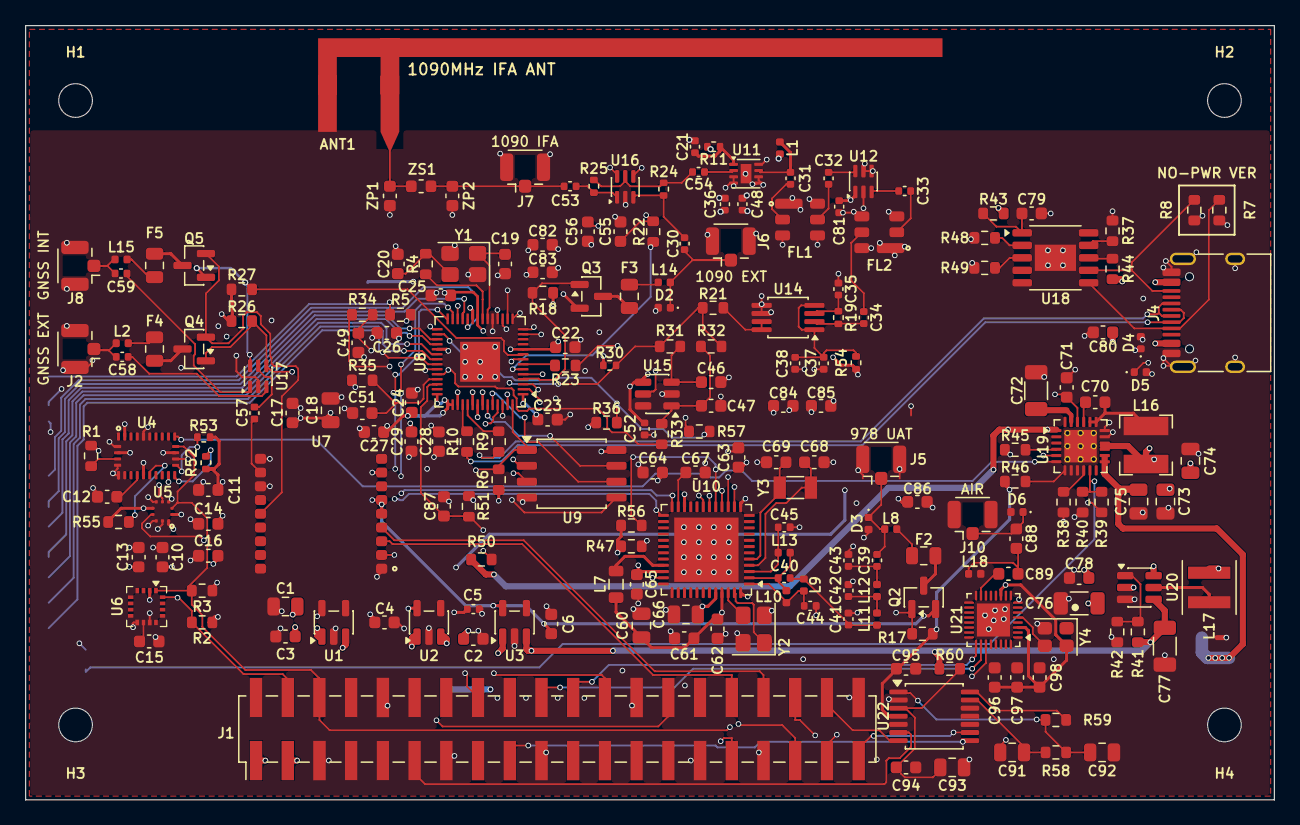
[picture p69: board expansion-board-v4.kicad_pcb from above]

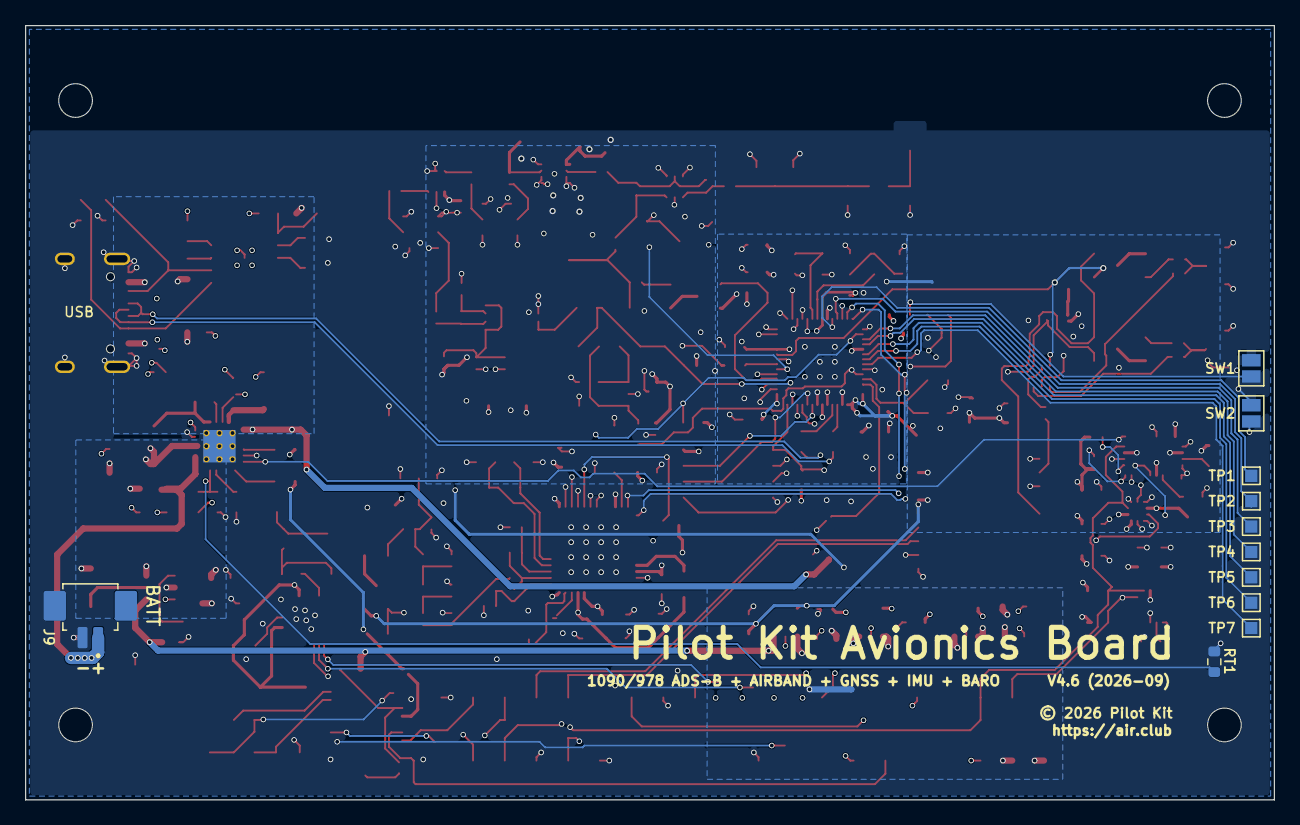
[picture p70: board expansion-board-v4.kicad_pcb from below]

Board: 6 copper layers, 100.0 x 62.0 mm, 226 parts (11 on the bottom side), 152 nets.

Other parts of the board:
H1, H2, H3, H4: MountingHole_2.7mm_M2.5

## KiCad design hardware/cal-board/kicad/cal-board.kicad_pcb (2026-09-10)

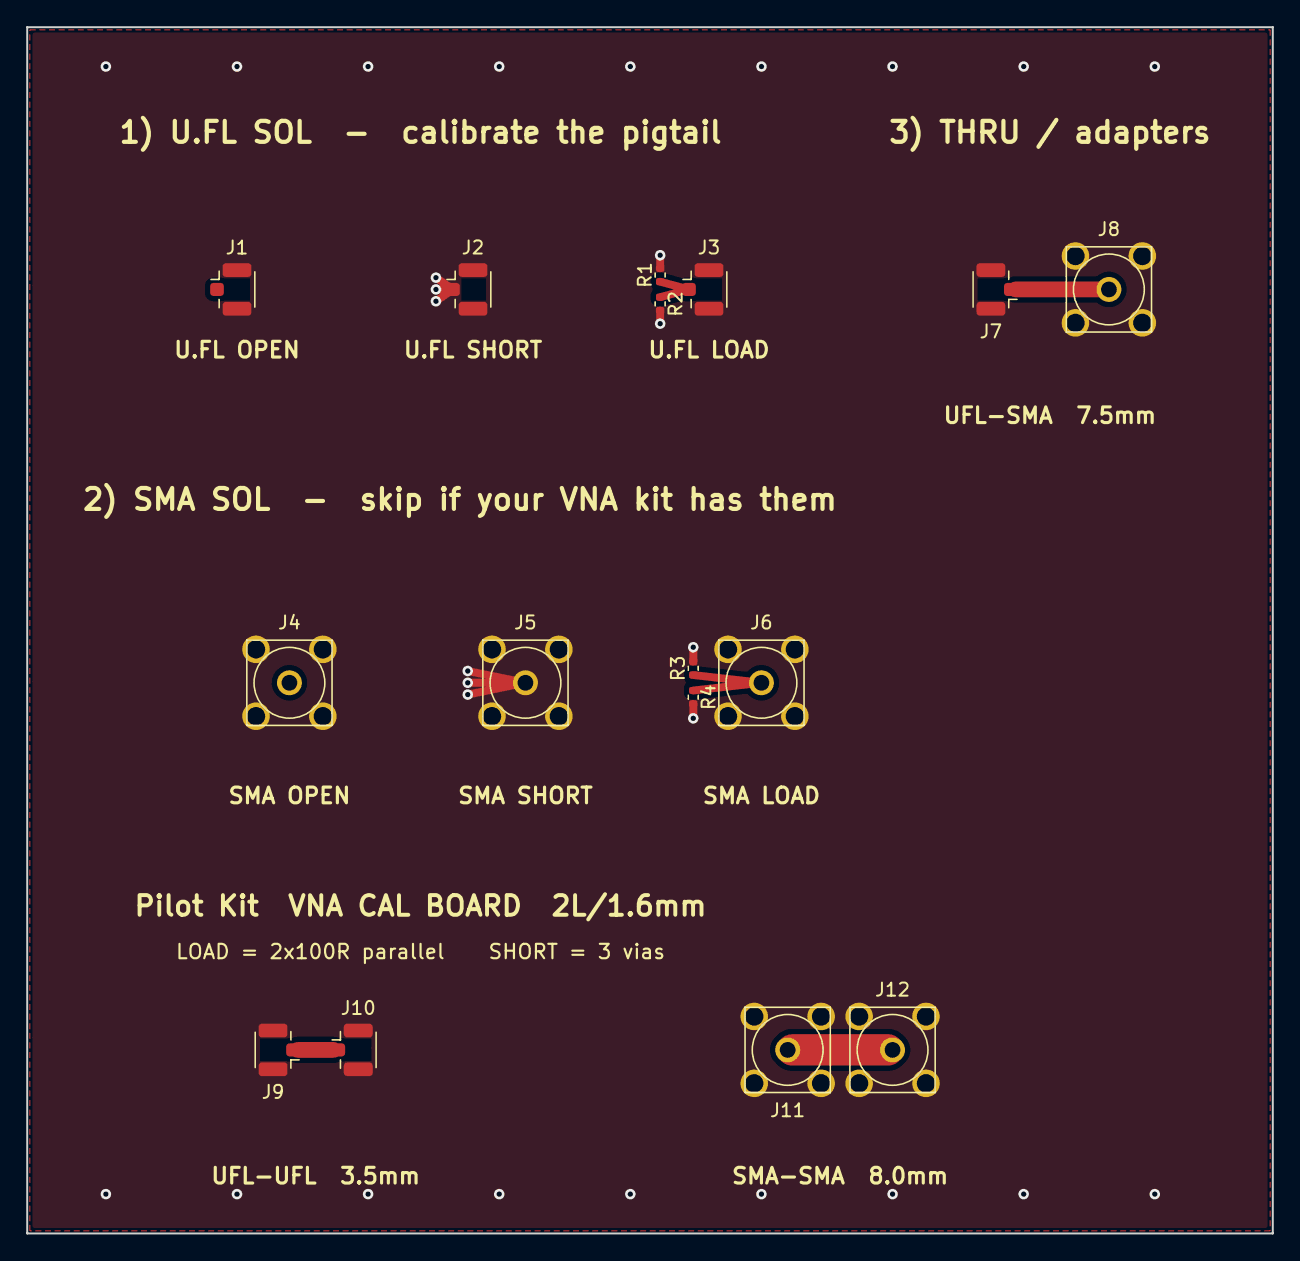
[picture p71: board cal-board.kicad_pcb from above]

Board: 2 copper layers, 95.0 x 92.0 mm, 16 parts (0 on the bottom side), 6 nets.

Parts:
J1, J2, J3, J7, J9, J10: U.FL_Hirose_U.FL-R-SMT-1_Vertical
J4, J5, J6, J8, J11, J12: SMA_KHD; SMA_KHD_Vertical_THT
R1, R2, R3, R4: 100; R_0402_1005Metric

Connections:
GND: J1.2, J2.1, J2.2, J3.2, J4.2, J5.1, J5.2, J6.2, J7.2, J8.2, J9.2, J10.2, J11.2, J12.2, R1.2, R2.2, R3.2, R4.2
SMA_LOAD: J6.1, R3.1, R4.1
THRU_SMA-SMA: J11.1, J12.1
THRU_UFL-SMA: J7.1, J8.1
THRU_UFL-UFL: J9.1, J10.1
UFL_LOAD: J3.1, R1.1, R2.1

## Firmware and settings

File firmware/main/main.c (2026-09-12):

/*
 * main.c — Pilot Kit Box (ESP32-P4) application boot strap.
 *
 *   1. Bring up storage sinks, GPS, record pipelines, and BLE.
 *   2. Bring up LCD, IMU, UI state, and PFD.
 *   3. Spawn the ADS-B link task last (RP2040 UART, adsb_link_task.c).
 *
 * app_main returns; the spawned tasks own the rest of the runtime.
 */

#include <assert.h>

#include "freertos/FreeRTOS.h"
#include "freertos/task.h"
#include "esp_log.h"
#include "esp_heap_caps.h"
#include "esp_intr_alloc.h"
#include "esp_sleep.h"
#include "esp_timer.h"
#include "nvs_flash.h"

#include "pilot_kit.h"
#include "adsb_link_task.h"
#include "aircraft_db.h"
#include "aircraft_state.h"
#include "gps.h"
#include "ble_gatt.h"
#include "boot_splash.h"
#include "config_qnh.h"
#include "config_storage.h"
#include "config_traffic.h"
#include "config_ac_category.h"
#include "config_own_icao.h"
#include "pk_aero_db.h"
#include "pk_win.h"
#include "pk_aero_layer.h"
#include "apt_detail_page.h"
#include "nav_grid_page.h"
#include "search_page.h"
#include "power_log.h"
#include "pk_sdcard.h"
#include "pk_i2c0_bus.h"   /* 板级 I²C0 总线：先于一切 I²C 器件 init 创建 */
#include "demo_track_sd.h"
#include "pk_rec_store.h"
#include "pk_rec_ingest.h"
#include "pk_own_sampler.h"
#include "pk_rec_selftest.h"
#include "pk_tile_loader.h"
#include "display.h"
#include "imu_task.h"
#include "baro.h"
#include "qmc5883p.h"
#include "power_sy6970.h"
#include "power_service.h"
#include "config_ble.h"
#include "config_demo.h"
#include "config_antenna.h"
#include "config_devname.h"
#include "i18n.h"
#include "pfd.h"
#include "record_sink.h"
#include "settings_page.h"
#include "ui_state.h"

static const char *TAG = "pilot_kit";

/* 开机把几条关键词条的 ID 和实际文案打到串口，用来验证「ID 指向的还是那句话」。
 * 平时关着（编译期整段消失）；怀疑文案错位时改成 1 重烧一次即可。
 * 背景见 firmware/scripts/i18n_ids.json 顶部的事故说明。 */
#define PK_I18N_ID_SELFTEST 0

void app_main(void)
{
    ESP_LOGI(TAG, "Pilot Kit Box (ESP32-P4) boot");

    /* Log wakeup causes + GPIO wake status. MODE sleep uses
     * esp_sleep_enable_gpio_wakeup_on_hp_periph_powerdown(), so a
     * successful MODE wake sets the ESP_SLEEP_WAKEUP_GPIO bit and
     * should include GPIO5 in gpio_status. */
    uint32_t wake_causes = esp_sleep_get_wakeup_causes();
    uint64_t gpio_status = esp_sleep_get_gpio_wakeup_status();
    ESP_LOGI(TAG, "boot wakeup_causes=0x%lx  gpio_status=0x%llx",
             (unsigned long)wake_causes, (unsigned long long)gpio_status);

    ESP_LOGI(TAG, "Free internal heap at boot: %u B",
             (unsigned)heap_caps_get_free_size(MALLOC_CAP_INTERNAL));

    /* NVS 的唯一初始化点（2026-09-10）：分区异常时**只在这里擦一次**。
     * 此前 11 个模块各自 nvs_flash_init()+nvs_flash_erase()，任一模块命中
     * NO_FREE_PAGES / NEW_VERSION_FOUND 就会把整个分区擦掉——包括 IMU 的
     * pk_imu/tare_quat，表现为"长按调平重启后不生效"。这里统一处理；各模块
     * 的 ensure_nvs() 只保留幂等 init（见 config_*.c）。 */
    {
        esp_err_t nvs_err = nvs_flash_init();
        if (nvs_err == ESP_ERR_NVS_NO_FREE_PAGES ||
            nvs_err == ESP_ERR_NVS_NEW_VERSION_FOUND) {
            ESP_LOGW(TAG, "NVS needs erase (%s) — erasing once",
                     esp_err_to_name(nvs_err));
            ESP_ERROR_CHECK(nvs_flash_erase());
            nvs_err = nvs_flash_init();
        }
        if (nvs_err != ESP_OK) {
            ESP_LOGW(TAG, "nvs_flash_init: %s — persistence degraded",
                     esp_err_to_name(nvs_err));
        }
    }

    /* ADS-B 链路任务的 UART 在 adsb_link_task 内部初始化，
     * 这里不再有 USB host 栈的启动次序约束。 */

    /* Initialise the per-aircraft fusion table before any sink can write
     * into it. */
    aircraft_state_init();
    pk_gps_start();   /* GT-U8 GPS on UART1 */

    /* Bring the ADS-B record sinks up before the producer starts. The
     * file sink mounts LittleFS and may take ~50 ms on first boot (it
     * formats the partition automatically). The UART sink is always
     * available; the BLE sink is a thin wrapper that null-guards
     * everything until ble_gatt_init() succeeds later — safe to
     * register even if BLE never comes up. */
    /* microSD 探测 + 日志存储位置设置必须先于 file sink 创建：
     * record_sink_file_create() 据此决定写 flash LittleFS 还是 /sdcard。 */
    pk_config_storage_load();
    /* I²C0 总线在这里（电源链之前）创建——从原先点屏之后的位置前移
     * （WP-D Task 4）：电源链里的 SY6970 探测需要总线已在位，而
     * pk_i2c0_bus.h 的既定时机本来就是「app_main 最前面、先于一切
     * I²C 器件 init」。失败不中止启动的深审裁定（2026-09-05）不变：
     * 探测/器件 init 各自对 NULL 总线有优雅失败路径，降级为无 IMU/baro/
     * touch/SY6970 的 1090 盒子。 */
    esp_err_t bus_err = pk_i2c0_bus_init();
    if (bus_err != ESP_OK) {
        ESP_LOGE(TAG, "I2C0 bus init failed (%s) — continuing without "
                      "IMU/baro/touch (1090 unaffected)", esp_err_to_name(bus_err));
    }

    /* 电源链（用户 2026-09-10 口径）：电池挂在扩展板，链路是
     * 「电池→扩展板 USB-C→微雪 USB-C」。SY6970 是扩展板充电芯片，
     * **唯一权威电池源**；微雪主板 BATT（ETA6098）不再读（用不上），
     * 故**不注册**——此前"两块板电池值互跳"按构造消失。
     * SY6970 探测：ACK（powered 扩展板在位）→ 注册；NACK（v3 载板 /
     * 未上电 v4 的预期路径）→ 不注册，仅 INFO。powered/unpowered 只由
     * ACK 表达，与 Kconfig 板型正交（pk_board.h:30-32）。两个调用都幂等。
     * 注：SY6970 无"电池在位"寄存器，空座检测需实板标定
     * （见 IMPLEMENTATION_PLAN.md B6）。 */
    power_sy6970_init();
    power_service_init();
    pk_sdcard_init();
    /* ADS-B / 本机数据落盘的 session 目录管理，须晚于 pk_sdcard_init()。
     * 阶段 3a：只建目录/开文件，不接数据源（ADS-B 解码链 / own_ship / 相位
     * 状态机是 3b 的事）。pre-unmount 静默复用 record_sink_file.c 的
     * sd_close_log_cb 转调，不额外占 pk_sdcard 的回调槽位。 */
    pk_rec_store_init();
    /* 电池状态长期记录（60 s/行 → /sdcard/power.csv）。须晚于
     * pk_sdcard_init()；无卡时任务照起、每拍重试，不阻塞启动。
     * 存在的理由见 power_log.h：插着 H1 调试时电池根本不放电，
     * 放电标定只能让设备自己把数据记到卡上。 */
    power_log_init();
    /* traffic.trk 生产端的非阻塞入队 + 独立写任务，须晚于 pk_rec_store_init()
     * （写任务要调 pk_rec_store_append_traffic_record()）、早于 ADS-B 链路
     * 任务起跑（下面链路任务创建之前）——链路任务的 Mode-S 解码热路径调
     * pk_rec_ingest_position/identity()，队列必须已经建好，否则
     * enqueue_or_drop() 会因 s_queue==NULL 直接丢数据（见 pk_rec_ingest.h）。 */
    pk_rec_ingest_init();
    /* 机型分类须先于 own_sampler_start()：采样任务第一拍就调
     * pk_flight_phase_reset() 用它算振动地板初值，若晚于 start() 才 load，
     * 开机头几秒会用编译期默认值而不是用户在设置页选的档位。 */
    pk_config_ac_category_load();
    /* 本机 1 Hz 航迹采样（own.trk 生产者），阶段 3b。不要求 GPS/IMU/baro
     * 已就绪——它们分别在下面才 start（GPS 已在 aircraft_state_init() 之后
     * 起了，IMU/baro 还要再等一两百行），采样器每 tick best-effort 取值。 */
    pk_own_sampler_start();
    /* pk_tile_loader_init() **故意不在这里**——它内部的 pk_map_store_scan()
     * 是同步的，实测扫 4 个 pmtiles 要 4 秒，卡在这里会把后面的 hosted 握手
     * 和点屏一起往后推，开机要 10 秒才出 logo。已挪到 app_main 末尾，见那边。 */
    /* 演示模式的自定义轨迹：SD 卡 /sdcard/demo/ 里有 .gpx 就换过去，没有就
     * 继续播编进固件的内置轨迹。只创建一次性后台任务、零 IO，须晚于
     * pk_sdcard_init()（任务靠 pk_sdcard_is_mounted() 决定何时开读）。 */
    pk_demo_track_sd_init();
    /* SD 航空数据库懒加载：只创建后台任务、零 IO（开机不加载是定案）。
     * 须晚于 pk_sdcard_init()——任务靠 pk_sdcard_is_mounted() 决定何时
     * 开始分块加载 /sdcard/aero/pk_aero.bin。 */
    pk_aero_db_init();
    /* SD 机型库（ICAO24 → 型号/注册号）懒加载，同样只建任务、零 IO。
     * 须晚于 pk_sdcard_init()；任务自带 12 s 静默期，避开 pk_aero 的加载
     * 窗口，不与它抢 SD 带宽。未就绪时查询返回 NULL，UI 显示 ICAO24。 */
    pk_aircraft_db_init();
    /* 以本机为中心的滚动窗口（W1 骨架，设计见
     * 窗口化数据架构设计（内部文档））。
     * 与 pk_aero_db 全量加载**并存**：窗口另开一个只读句柄按格区间读，
     * 老路径一个字节没动，UI 侧本轮也还没切过来。只创建后台任务、零 IO，
     * 须晚于 pk_sdcard_init()。PK_WIN_ENABLE=0 时本调用是空函数。 */
    pk_win_init();
    /* 地图页的航空数据叠加层：只创建后台快照任务，等地图页第一次渲染
     * 报出视图才开始查（pk_aero_layer.h）。须晚于 pk_aero_db_init()。 */
    pk_aero_layer_init();
    /* 搜索页的后台查询任务 + 从 NVS 读回最近搜索。同样只建任务、零 IO，
     * 须晚于 pk_aero_db_init()（它是那边的消费者）。 */
    pk_search_page_init();
    /* 全屏导航网格（点 FAB 打开的主菜单）。它没有后台任务也没有 NVS，init()
     * 只是把「开着没 / 在第几页 / 亮度 pop 开着没」摆回初值——静态量零初始化
     * 本来就与它写的一致，但生命周期得走全，不留「这一个例外不用 init」。 */
    pk_nav_grid_page_init();
    /* 机场详情页**没有**初始化：它没有后台任务也没有 NVS，打开那一刻同步
     * 取数就够（89 条记录读全是 µs 级，见 apt_detail_page.h）。这里只挂一个
     * 默认关闭的自检钩子——PK_APT_DETAIL_SMOKE=0 时它是个空函数。 */
    pk_apt_detail_smoke_init();

    const char *file_mount = record_sinks_install_defaults();
    if (file_mount != NULL) {
        ESP_LOGI(TAG, "ADS-B sinks ready (UART + file at %s)", file_mount);
    } else {
        ESP_LOGW(TAG, "ADS-B file sink unavailable — UART sink only");
    }
    /* 落盘全链路的注入式自检——默认关（PK_REC_SELFTEST=0 时是空函数）。
     * 打开后需要 record_sinks_install_defaults() 已经把 record_sink_rec_store
     * 注册好，所以排在它后面。见 pk_rec_selftest.h。 */
    pk_rec_selftest_init();

    /* ADS-B 链路任务的创建**故意排到 app_main 末尾**（PFD 起来之后），
     * 不在这里。原因见末尾启动处的注释：record sinks 与 pk_rec_ingest_init()
     * 必须先就绪，Mode-S 热路径的首批报文才不会丢进空队列。 */

    /* ESP-Hosted 握手必须排在 MIPI-DSI 之前——顺序反了整机会 26 秒一重启。
     *
     * 症状：SDIO 物理层一切正常（CMD5、CIS、Function 1 就绪位、4-bit 协商
     * 全部成功），但主机在 "Waiting for esp_hosted slave to be ready" 上死等，
     * 13 秒超时后复位从机重试，重试撞上 "failed to read registers"，最后
     * hosted 自己 "Host is resetting itself" 把整机重启。
     *
     * 定位过程：跳过 pk_display_init() 后握手在 72 ms 内完成；只跳过 PFD
     * 渲染任务（LVGL / PPA / GT911 / 温度传感器全不跑）则照旧失败——所以问题
     * 不在渲染负载，就在点屏本身。同一套 hosted 配置在 2.4″ 板上一直是好的，
     * 而那块板走 SPI 屏、根本不碰 DSI。
     *
     * 机理：DSI PHY 要独占 LDO channel 3 并把它拉到 2.5 V
     * （display.h 的 PK_LCD_DSI_PHY_LDO_CHANNEL / _MV）。这一下扰动足以让
     * 刚被 GPIO54 复位、正在启动的 C6 起不来——它的 SDIO 外设仍能应答卡层
     * 命令，但上层固件跑不到发 INIT event 那一步，于是主机永远等不到。
     *
     * 所以先让 hosted 握完手、BLE 起来，再点屏。开机多花的这一秒正好落在
     * splash 显示窗口里，用户看不出差别。
     */
    /* BLE init. Requires the on-board ESP32-C6 to have been
     * pre-flashed with the matching esp_hosted slave firmware (one-time
     * board setup, see docs/BUILD.md §3). The hosted vhci_drv.c uses
     * ESP_ERROR_CHECK() internally so if C6 doesn't respond, the whole
     * P4 firmware aborts — there's no graceful path. Default is on
     * (CONFIG_PK_BLE_ENABLED=y); turn off via menuconfig if you haven't
     * flashed C6 yet or are running CI without it. */
#if CONFIG_PK_BLE_ENABLED
    /* 用户开关（设置页，NVS）。编译期 CONFIG_PK_BLE_ENABLED 是"这台设备有没有
     * BLE"，运行期这个是"用户要不要用"，两者是与的关系。 */
    pk_config_ble_load();
    /* 自定义广播名（P2-5）。**必须排在 ble_gatt_init() 之前**：广播名在
     * NimBLE 的 on_sync() 回调里一次拼好，那个回调紧跟着 init 就会触发，
     * 晚一步读到的就是空串，第一次广播出去的还是出厂名。 */
    pk_config_devname_load();
    esp_err_t ble_err = pk_ble_enabled_get() ? ble_gatt_init() : ESP_OK;
    if (!pk_ble_enabled_get())
        ESP_LOGI(TAG, "BLE disabled by user setting — skipping ble_gatt_init()");
    if (ble_err != ESP_OK) {
        ESP_LOGW(TAG, "BLE init failed (%s) — UART + file sinks only",
                 esp_err_to_name(ble_err));
    } else {
        ESP_LOGI(TAG, "BLE GATT service up — advertised name landed in"
                      " on_sync (see 'ble_gatt: advertising as ...')");
    }
#else
    ESP_LOGI(TAG, "BLE disabled at build time (CONFIG_PK_BLE_ENABLED=n) — "
                  "UART + file sinks only. Flash C6 esp_hosted slave + "
                  "re-enable in menuconfig once you're ready.");
#endif

    /* Bring up the LCD and paint the boot splash (logo +
     * "Booting ..." text). The splash stays on screen until the PFD
     * render task starts — we time-stamp here and enforce a minimum
     * hold (PK_BOOT_SPLASH_MIN_MS) just before pk_pfd_start() below
     * so the user can read the logo + version even if init finishes
     * quickly. Init work (IMU/UI/buttons/BLE/SDR) happens during the
     * visible splash window and counts against the hold, so we only
     * sleep if init was faster than the target. */
    /* 演示模式开关与语言都必须在 splash 之前读出来：splash 上要画那条红色的
     * 「演示模式：数据均为模拟」横幅，而横幅文案走 i18n。
     *
     * i18n_init 原本排在下面（PFD 启动前），于是 splash 恒用默认语言英文——中文
     * 用户开机第一屏是英文，这条安全提示的效果先打了个折。两者都只读 NVS，
     * 此刻 NVS 早已由 config_storage / config_ble 初始化过，提前无副作用。 */
    esp_err_t i18n_err = pk_i18n_init();
    if (i18n_err != ESP_OK) {
        ESP_LOGW(TAG, "i18n init failed (%s) — default language remains English",
                 esp_err_to_name(i18n_err));
    }
#if PK_I18N_ID_SELFTEST
    /* 词条 ID ↔ 文案的开机自检（默认关，把上面的宏改成 1 才编进来）。
     *
     * 由来：2026-08 徽章显示成「(数据为模」——ID 平移 + 陈旧 .o，编译零警告、
     * 烧录校验通过、串口日志正常，完全静默。ID 现在由 scripts/i18n_ids.json
     * 钉死（见那里的说明），但下次再怀疑「屏上这句话不对」时，这段能在串口上
     * 直接给出「本固件里 ID N 到底是哪句」，不用去猜。 */
    ESP_LOGW(TAG, "i18n selftest: DEMO_BADGE id=%d text=\"%s\"",
             (int)PK_TR_DEMO_BADGE, pk_i18n_text(PK_TR_DEMO_BADGE));
    ESP_LOGW(TAG, "i18n selftest: SETTINGS_DEMO_HINT id=%d text=\"%s\"",
             (int)PK_TR_SETTINGS_DEMO_HINT, pk_i18n_text(PK_TR_SETTINGS_DEMO_HINT));
    ESP_LOGW(TAG, "i18n selftest: SETTINGS_TITLE id=%d text=\"%s\"",
             (int)PK_TR_SETTINGS_TITLE, pk_i18n_text(PK_TR_SETTINGS_TITLE));
    ESP_LOGW(TAG, "i18n selftest: ABOUT_TITLE id=%d text=\"%s\"",
             (int)PK_TR_ABOUT_TITLE, pk_i18n_text(PK_TR_ABOUT_TITLE));
    ESP_LOGW(TAG, "i18n selftest: last id=%d PK_TR_COUNT=%d text=\"%s\"",
             (int)PK_TR_COUNT - 1, (int)PK_TR_COUNT,
             pk_i18n_text((pk_tr_id_t)(PK_TR_COUNT - 1)));
#endif

    pk_config_demo_load();
    /* 天线选择：NVS 是真源，RP2040 上电只回到安全默认，等链路握手后推下去
     * （见 config_antenna.h）。必须在 pk_adsb_link_start() 之前读出来。 */
    pk_config_antenna_load();

    esp_err_t lcd_err = pk_display_init();
    int64_t splash_shown_us = 0;
    if (lcd_err != ESP_OK) {
        ESP_LOGW(TAG, "display init failed (%s) — running headless",
                 esp_err_to_name(lcd_err));
    } else {
        /* splash 第一帧就带进度条（0/3）。用户从这一刻起看到的不再是一张
         * 静止的 logo，而是"机器在干什么、还剩几步"——出 logo 到能操作之间
         * 还有 3 s，那 3 s 以前是纯白等。 */
        pk_boot_splash_progress(pk_i18n_text(PK_TR_BOOT_STAGE_START), 0, 3);
        /* 走档位而不是裸占空比：设置页的高亮读的是同一个 s_bl_step，
         * 开机点亮就必须落在某一档上，否则第一次进设置页三段全不高亮。 */
        pk_backlight_step_set(PK_BL_STEP_MID);
        splash_shown_us = esp_timer_get_time();
    }

    /* I²C0 总线的创建已前移到电源链之前（SY6970 探测需要总线，
     * 见上方电源链处的说明）。
     *
     * BNO085 IMU. Failure is non-fatal — the rest of the
     * firmware (RTL-SDR, BLE, storage) keeps working without attitude. */
    pk_boot_splash_progress(pk_i18n_text(PK_TR_BOOT_STAGE_SENSORS), 1, 3);
    esp_err_t imu_err = pk_imu_init();
    if (imu_err != ESP_OK) {
        ESP_LOGW(TAG, "IMU init failed (%s) — PFD will run without attitude",
                 esp_err_to_name(imu_err));
    } else {
        /* 别写成 "IMU online"：这里只证明任务建起来了，BNO085 回没回话要看
         * imu 任务自己那条 bring-up 日志（失败会退避重试，见 imu_task.c）。 */
        ESP_LOGI(TAG, "BNO085 IMU task started (bring-up runs in-task)");
    }
    pk_qnh_load();     /* 从 NVS 加载 QNH,供 baro_task 立即使用 */
    pk_config_traffic_load();  /* 从 NVS 加载地图朝向 + 雷达量程 */
    pk_baro_start();   /* BMP388 on shared I²C0 */

    /* QMC5883P 磁力计诊断（WP-B Task 4）：optional 器件，缺失/探测失败
     * 只在驱动里 WARN + 计数，不影响其余功能；R1——只出原始三轴诊断，
     * 不出航向。 */
    if (qmc5883p_init(pk_i2c0_bus_get()) != ESP_OK) {
        ESP_LOGW(TAG, "QMC5883P init failed — mag diagnostics disabled");
    }

    /*
     * 地图扫描放在 splash 期间 —— 这是**产品决定压过时序最优**的一处，改之前
     * 先读完这段，别照着"哪个数字小选哪个"又挪回去。
     *
     * pk_map_store_scan() 同步扫 /sdcard/maps 下 4 个 pmtiles 约 3.9 s。位置
     * 实测过四个点：
     *
     *   ① app_main 中段（最初）—— 把 hosted 握手和点屏一起往后顶，出 logo
     *      要 10.3 s，其间背光已亮（BL_EN 被 100 kΩ 上拉，上电即通），就是
     *      "亮着一块空屏"。
     *   ② app_main 最末（SDR 之后）—— 扫描的 SD I/O 撞上 RTL-SDR 的 4 MB/s
     *      IQ 流，每扫一个包丢一次、单次丢到 282 KB。
     *   ③ PFD 之后、SDR 之前 —— 时序最漂亮：PFD 8.40 s 可交互、丢包 0。
     *   ④ 这里（splash 期间）—— PFD 11.37 s、丢包 8 次，都比 ③ 差。
     *
     * 仍然选 ④，因为 ③ 有个数字之外的代价：PFD 一起来 splash 就没了，扫描
     * 退到后台，**进度条照不到它**。而这 3.9 s 恰恰是开机最长的一段等待，
     * 用户要的正是"别让我白等"。摆在进度条里的 4 s，比藏在后台的 4 s 好过。
     *
     * ④ 的两笔代价都可接受：PFD 晚 3 s，但这 3 s 屏幕上有明确进度、不是空等；
     * 丢包 8 次发生在开机瞬间，此时 ADS-B 还没有任何目标可丢。
     *
     * 依赖：只要求晚于 pk_sdcard_init()（早就调过了）。
     */
    pk_boot_splash_progress(pk_i18n_text(PK_TR_BOOT_STAGE_MAP), 2, 3);
    pk_tile_loader_init();
    pk_boot_splash_progress(pk_i18n_text(PK_TR_BOOT_STAGE_READY), 3, 3);

    /* UI state lives in its own module so the UI can flip
     * the mode without touching the render task directly. Default mode
     * is PFD; survives an IMU-init failure (you can still scroll the
     * ADS-B list with no attitude). */
    esp_err_t ui_err = pk_ui_init();
    if (ui_err != ESP_OK) {
        ESP_LOGW(TAG, "ui_state init failed (%s)", esp_err_to_name(ui_err));
    }
    /* 从 NVS 恢复本机 ICAO 绑定（用户上次在 ADS-B 列表里选的"这架是我"）。
     * 必须排在 pk_ui_init() 之后：恢复走 pk_ui_set_own_icao()，它内部
     * xSemaphoreTake(s_lock)——s_lock 在 pk_ui_init() 里才建，之前调会因
     * s_lock==NULL 静默退化（pk_ui_set_own_icao 头部的 NULL 守卫），绑定
     * 根本没恢复。sink 轮询（record_sinks_install_defaults，上面 :252）靠
     * have_last_own 标志位在首次轮询必触发，不依赖 load 的先后。 */
    pk_config_own_icao_load();

    /* pk_i18n_init() 已提前到 splash 之前，见那里的注释。 */

    /* PFD render task. Starts after the display + IMU init
     * so it can read both straight away. Survives either failing.
     *
     * Before kicking the PFD render task, make sure the boot splash
     * has been visible for at least PK_BOOT_SPLASH_MIN_MS. Init work
     * above has already used some of that budget; we only sleep for
     * the remainder. */
    if (lcd_err == ESP_OK) {
        const int64_t splash_min_ms = PK_BOOT_SPLASH_MIN_MS;
        int64_t elapsed_ms = (esp_timer_get_time() - splash_shown_us) / 1000;
        int64_t remaining_ms = splash_min_ms - elapsed_ms;
        if (remaining_ms > 0) {
            ESP_LOGI(TAG, "splash hold: init took %lld ms, sleeping %lld ms "
                          "more (target %lld ms)",
                     (long long)elapsed_ms,
                     (long long)remaining_ms,
                     (long long)splash_min_ms);
            vTaskDelay(pdMS_TO_TICKS(remaining_ms));
        } else {
            ESP_LOGI(TAG, "splash hold: init took %lld ms (≥ %lld ms target), "
                          "no extra wait",
                     (long long)elapsed_ms, (long long)splash_min_ms);
        }
        esp_err_t pfd_err = pk_pfd_start();
        if (pfd_err != ESP_OK) {
            ESP_LOGW(TAG, "PFD start failed (%s)", esp_err_to_name(pfd_err));
        } else {
            ESP_LOGI(TAG, "PFD render task running");
        }
    }

    /*
     * ADS-B 链路任务保持最后启动：record sinks 与 pk_rec_ingest_init()
     * 必须先就绪，Mode-S 热路径的首批报文才不会丢进空队列（原 dsp_task
     * 时代同样约束，见 pk_rec_ingest.h）。UART 不抢内部 DMA 堆，旧
     * RTL-SDR 时代的 92 KB URB 内存饥饿问题（2026-08-03 事故）不复存在；
     * 次序保持只为最小改动。
     */
    pk_adsb_link_start();

    ESP_LOGI(TAG, "ADS-B link task spawned last (free internal heap: %u B)",
             (unsigned)heap_caps_get_free_size(MALLOC_CAP_INTERNAL));
}

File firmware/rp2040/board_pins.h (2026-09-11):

/*
 * board_pins.h — RP2040 唯一 pin 清单。
 * 来源：hardware/expansion-board-v4/PINMAP.md §2（v3/v4 同源）。
 * 改任何一个脚都要先改 PINMAP，再改这里——顺序不能反。
 */
#pragma once

#define PIN_P4_UART_TX    0   /* UART0 TX → P4 GPIO46（J3-35）*/
#define PIN_P4_UART_RX    1   /* UART0 RX ← P4 GPIO32（J3-31）*/
#define PIN_BIAS_EN_1090  2   /* bias tee PMOS gate：低有效，10k 上拉默认关 */
#define PIN_BIAS_EN_978   3   /* 同上（978 支路）*/
#define PIN_GNSS_SEL_A    6   /* U17 V1 / Q4 gate（ECO 后配对）*/
#define PIN_GNSS_SEL_B    7   /* U17 V2 / Q5 gate */
#define PIN_ANT_SEL_1090_A 4  /* U16 SPDT V1：A=1/B=0 → J1-J3（板载 IFA）；
                               * A=0/B=1 → J1-J2（外接 J6）。默认装配，
                               * 真值表与 GNSS 开关一致（netlist U8.6/U8.7）*/
#define PIN_ANT_SEL_1090_B 5  /* U16 SPDT V2（netlist U8.7）*/
#define PIN_SUBG_SCK      10  /* CC1312R SPI1 —— WP-E 启用前不动 */
#define PIN_SUBG_MOSI     11
#define PIN_SUBG_MISO     12
#define PIN_SUBG_CSN      13
#define PIN_SUBG_IRQ      14
#define PIN_SUBG_SYNC     15
/* CC1312R 的 RESET_N（低有效，板上 R47 10k 上拉）。同一个脚此前在
 * spi_master.c 与 cjtag.h 各有一份本地 #define——新代码一律用这个名字。 */
#define PIN_SUBG_RESET    18
#define PIN_PULSES        19  /* TLV3501 → PIO 上升沿捕获 */
#define PIN_SELFTEST_OUT  24  /* 自检脉冲输出；跳线 24→19 前**先拆下 R57**
                               * （33Ω，TLV3501 输出→PULSES 的串阻：33Ω
                               * 对 1k 串阻分支约 30:1 占优，不拆则节点
                               * 跟随比较器——"串 ≥1k 电平胜出"物理不
                               * 成立，见 selftest_gen.h；拆后直连即可）。
                               * audit P1-4：原 18 是 SUBG_RESET（CC1312R），
                               * PINMAP §2 严禁挪用；24 = RECOVERED_CLK，
                               * 调试网络，空置可安全借用。落点：v4 生产板
                               * TP7 存在（kicad_pcb:38901，audit round 4
                               * 勘误；PINMAP.md:41 的"V4 已删 TP7"与 PCB
                               * 不符，归硬件侧勘误），v3 亦有 TP7 */
#define PIN_TL_PWM        25  /* 门限 PWM → R34/C49（RC≈1ms，F5）→ LEVEL_BIAS */
#define PIN_ADC_LEVEL     26  /* ADC0：门限直流回读 */
#define PIN_ADC_RSSI      27  /* ADC1：AD8313 RSSI */
/* ADC2：USB_VBUS_SENSE 分压中点（PCB 焊盘已核：U8 pad 40 → USB_VBUS_SENSE，
 * pad 39 = RSSI = GPIO27，故 pad 40 = GPIO28）。
 * ⚠ 分压比**随板型不同**：V4 = 30k/10k（4.0），V3 = 10k/10k（2.0）。
 * RP2040 是两块板共用的**单一构建**、没有板型检测，所以本侧只上报**分压
 * 中点的电压**，换算成 VBUS 由 P4 做——那边有 Kconfig 驱动的
 * pk_board_profile()。把比例放这边就得先发明一套板型检测，猜错是静默的
 * 2 倍误差（PLAN.md F6）。 */
#define PIN_ADC_VBUS      28

/* F2 默认 GNSS 天线选择：A=0/B=1 → J1-J2（外接）导通且其 bias 路径
 * 被选中（ECO 后选择线即馈电使能，PLAN.md §3.1 F2）。台架默认外接。 */
#define RF_SAFETY_DEFAULT_GNSS_A 0
#define RF_SAFETY_DEFAULT_GNSS_B 1

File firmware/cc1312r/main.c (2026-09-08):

/*
 * main.c — CC1312R UAT 接收协处理器固件骨架（WP-E T4）。
 *
 * 职责（本骨架）：SPI slave 链路层——按冻结协议 v1.0
 * （PROTOCOL_RP2040_CC1312R_SPI.md）与 RP2040 master 事务对跑。
 * 纯逻辑在 spi_slave.c（host 全测：含 master↔slave 互通）；本文件
 * 只做器件胶水：SSI0 slave mode0、IOC 映射（pinmap_978.md）、IRQ
 * GPIO、主循环的预载/收发/交付节奏。
 *
 * 明确不在本骨架（诚实边界）：
 *   - RF Core / 978 MHz PHY：结构占位，参数待台架实测（协议 §1/
 *     PLAN §5.2——不得宣称任何 RF 性能）；
 *   - SSI DMA：轮询流式收发（4 MHz 下 512 B 事务 ≈1 ms，48 MHz
 *     CPU 轮询跟得上；DMA 优化留后续任务）；
 *   - 看门狗：骨架循环不喂狗——台架前必须补（备注：CC13x2 默认
 *     看门狗在复位后不自动使能，骨架不开启，风险面为台架项）。
 */
#include <stdint.h>
#include <stdbool.h>

#include <ti/devices/DeviceFamily.h>
#include DeviceFamily_constructPath(driverlib/prcm.h)
#include DeviceFamily_constructPath(driverlib/sys_ctrl.h)
#include DeviceFamily_constructPath(driverlib/ssi.h)
#include DeviceFamily_constructPath(driverlib/ioc.h)
#include DeviceFamily_constructPath(driverlib/gpio.h)

#include "spi_slave.h"
#include "rp_cc13xx_codec.h"

/* 引脚（docs/hardware/pinmap_978.md——每条有 PDF 页码取证）：
 * DIO_10 = SSI0 SCLK（slave 输入）
 * DIO_8  = SSI0 MOSI/SSI_D0（master 出 → slave 入，即本侧 RX）
 * DIO_9  = SSI0 MISO/SSI_D1（slave 出，即本侧 TX）
 * DIO_11 = SSI0 FSS（硬件从选，RP2040 CSN）
 * DIO_12 = SUBG_IRQ（本侧输出，电平高有效） */
#define PIN_SCLK     IOID_10
#define PIN_MOSI_RX  IOID_8
#define PIN_MISO_TX  IOID_9
#define PIN_FSS      IOID_11
#define PIN_IRQ      IOID_12

#define SSI_BASE     SSI0_BASE

static cc13s_slave_t g_slave;

/* SSI slave 流式收发一个 512 B 定长事务（§2.1）。
 * 进入条件：FSS 即将拉低、TX FIFO 头 8 字节已由调用方预载（§2.2）；
 * 返回条件：整事务完成。阻塞轮询——骨架实现，时序余量见文件头注。 */
static void ssi_txn(uint8_t mosi[CC13S_TXN_LEN],
                    const uint8_t miso_pre[CC13S_TXN_LEN])
{
    size_t tx = 8, rx = 0;                  /* 头 8 字节已在 FIFO */
    while (rx < CC13S_TXN_LEN) {
        uint32_t st = SSIStatus(SSI_BASE);
        if (st & SSI_RX_NOT_EMPTY) {
            uint32_t d = 0;
            SSIDataGet(SSI_BASE, &d);
            mosi[rx++] = (uint8_t)d;
        }
        if ((st & SSI_TX_NOT_FULL) && tx < CC13S_TXN_LEN) {
            SSIDataPut(SSI_BASE, miso_pre[tx++]);
        }
    }
}

static void irq_set(bool level)
{
    GPIO_writeDio(PIN_IRQ, level ? 1 : 0);
}

int main(void)
{
    /* 时钟：SDK 启动默认 48 MHz RCOSC（骨架不调频、不进 standby）。
     *
     * 电源域/外设时钟（审计 round-WP-E-1 P1-1）：CC13x2 复位后
     * PERIPH/SERIAL 域与 GPIO/SSI0 运行时钟默认关闭，裸启动代码
     * （startup_gcc.c）只做 trim/BSS/FPU——不使能就访问 GPIO/SSI
     * 是未定义行为（实机可能首访即停）。SDK 的域就绪查询是
     * PRCMPowerDomainsAllOn()（全部就绪布尔值，非逐域状态）。 */
    PRCMPowerDomainOn(PRCM_DOMAIN_PERIPH | PRCM_DOMAIN_SERIAL);
    /* PRCMPowerDomainsAllOn 返回域状态位图（POWER_ON=0x1），须与
     * PRCM_DOMAIN_POWER_ON 比较而非当布尔用（验证轮抓过空转反例：
     * POWER_OFF=0x2 也非零，!x 恒假）。 */
    while (PRCMPowerDomainsAllOn(PRCM_DOMAIN_PERIPH | PRCM_DOMAIN_SERIAL)
           != PRCM_DOMAIN_POWER_ON) { }
    PRCMPeripheralRunEnable(PRCM_PERIPH_GPIO);
    PRCMPeripheralRunEnable(PRCM_PERIPH_SSI0);
    PRCMLoadSet();
    while (!PRCMLoadGet()) { }

    IOCPortConfigureSet(PIN_SCLK, IOC_PORT_MCU_SSI0_CLK,
                        IOC_STD_INPUT | IOC_HYST_ENABLE);
    IOCPortConfigureSet(PIN_MOSI_RX, IOC_PORT_MCU_SSI0_RX,
                        IOC_STD_INPUT | IOC_HYST_ENABLE);
    IOCPortConfigureSet(PIN_MISO_TX, IOC_PORT_MCU_SSI0_TX,
                        IOC_STD_OUTPUT);
    IOCPortConfigureSet(PIN_FSS, IOC_PORT_MCU_SSI0_FSS,
                        IOC_STD_INPUT | IOC_HYST_ENABLE);

    /* IRQ：DIO_12 输出，低（无源）。 */
    IOCPinTypeGpioOutput(PIN_IRQ);
    irq_set(false);

    /* SSI0：slave、mode 0（协议 §1）、8-bit、时钟由 master 提供。
     * bitrate 参数在 slave 模式不驱动时钟，但参与 SDK 的分频计算
     * （ssi.c 直接 ui32SSIClk/ui32BitRate——传 0 是除零，审计
     * round-WP-E-1 P1-2）；传 4 Mbps 与 master 侧一致。TI 要求
     * slave 模式 FSSI >= 12×bitrate：48 MHz/12 = 4 MHz 上限，
     * master 侧（rp2040 spi_master.c SPIM_HZ）已同步降到 4 MHz。 */
    SSIConfigSetExpClk(SSI_BASE, 48000000, SSI_FRF_MOTO_MODE_0,
                       SSI_MODE_SLAVE, 4000000, 8);
    SSIEnable(SSI_BASE);

    cc13s_init(&g_slave, CC13_FW_VER_MAJOR, CC13_FW_VER_MINOR);

    uint8_t miso[CC13S_TXN_LEN];
    uint8_t mosi[CC13S_TXN_LEN];
    for (;;) {
        /* CSN 高（事务间隙）：pending 预载 + IRQ 同步（§1 生命周期）。 */
        cc13s_pending(&g_slave, miso);
        irq_set(cc13s_irq(&g_slave));

        /* §2.2 物理合同：FSS 拉低前 MISO 字节 0 必须已在 TX FIFO——
         * 预载 8 字节 FIFO 头**先于**等待 FSS（master 的 CSN→SCK
         * 亚微秒级，事后预载必致头字节欠载/帧 magic 损坏）。 */
        for (int i = 0; i < 8 && i < CC13S_TXN_LEN; i++) {
            SSIDataPut(SSI_BASE, miso[i]);
        }

        /* 等 FSS 拉低（轮询 CSN 输入电平——FSS 已路由 SSI，此处读
         * IOC 输入状态；骨架轮询，台架后可改中断）。 */
        while (GPIO_readDio(PIN_FSS) != 0) { }

        ssi_txn(mosi, miso);                /* 512 B 全双工（阻塞） */

        /* CSN↑：交付沿清源 + 处理 MOSI + 装载下一 pending（§1/§2.3）。 */
        cc13s_txn_done(&g_slave, mosi);
    }
}

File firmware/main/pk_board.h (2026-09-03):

/*
 * pk_board.h — 显式扩展板板型 profile 与传感器安装变换。
 *
 * 这个模块回答一件事：**这颗传感器的芯片轴，在机体 NED 坐标系里指向哪。**
 *
 * profile 的粒度是**板系**，不是修订号
 * ------------------------------------
 * `v3` / `v4`（将来还有 `v5`）指的是扩展板**板系**。`V3.9` / `V4.3` 只是这两个
 * 板系当前的修订号——修订会滚动，板系不会。所以 profile 用 v3/v4，别把修订号
 * 编进标识符里，否则每出一版 V4.4 就要改一遍固件、Kconfig、发布脚本和刷机页。
 *
 * 下面这张角度表实测自 V3.9 与 V4.3（即两个板系当前的修订）。把传感器摆位当作
 * **板系级属性**是一个假设，不是白拿的：`hardware/test_firmware_board_profile_
 * contract.py` 会把本文件的角度表与两个 kicad_pcb 现场逐项对拍，哪天某个新修订
 * 转了传感器，它先变红，而不是悄悄发出去。
 *
 * 为什么必须显式选板系
 * --------------------
 * 两个板系的传感器物理方向不同（2026-09-03 产品裁定，v3 保持 0° 是最终设计，
 * 不是回灌遗漏）：
 *
 *     器件            v3      v4      固件含义
 *     U4 BNO085         0°     +90°   两个板系必须用不同的 board-to-body 变换
 *     U5 BMP388         0°     -90°   气压是标量，安装角不参与数值变换
 *     U6 QMC5883P       0°     -90°   必须有独立于 BNO085 的变换
 *     U7 ATGM336H       0°       0°   无姿态轴变换
 *
 * U4 与 U5/U6 **转向相反**，所以任何「整板统一旋转 90°」的建模都是错的。
 *
 * 板型只能来自显式配置（Kconfig `PK_BOARD_PROFILE_*`）。**禁止**用
 * SY6970 是否 ACK 来推断板型：V3 与 unpowered V4 都可能探测不到 SY6970，
 * 那个探测结果只能表达 powered variant，是与板型正交的另一个维度。
 *
 * 怎么切板系
 * ----------
 * **默认是 v4。** 手上是 v3 板就必须改，两个板系差 90°，选错了 PFD 照样出
 * 姿态、只是横滚整体偏 90°，桌上看不出来。
 *
 *   交互：  cd firmware && ./build.sh menuconfig
 *           → Pilot Kit Box → Expansion board profile → 选 v3 → S 保存 Q 退出
 *           && ./build.sh build
 *
 *   脚本：  cd firmware
 *           sed -i '' 's/^# CONFIG_PK_BOARD_PROFILE_V3 is not set$/CONFIG_PK_BOARD_PROFILE_V3=y/' sdkconfig
 *           sed -i '' 's/^CONFIG_PK_BOARD_PROFILE_V4=y$/# CONFIG_PK_BOARD_PROFILE_V4 is not set/' sdkconfig
 *           ./build.sh build
 *           （Linux 用 `sed -i`，不带那对空引号。切回 v4 把两条反过来。）
 *
 * 确认编的是哪一版：
 *   烧录前  grep PK_BOARD_PROFILE firmware/build/config/sdkconfig.h   （只会有一行）
 *   烧录后  开机日志 `imu: board profile v3|v4: q_body_fix = …`
 *           v3 = 0.7071068 0 0.7071068 0；v4 = 0.5 0.5 0.5 -0.5，两组数不一样。
 *
 * 完整说明见 docs/configuration.md 第 1 节。
 *
 * 将来加 v5 要动的地方（就这几处，都有测试盯着）：
 *   1. 本文件的 pk_board_profile_t 加 PK_BOARD_PROFILE_V5
 *   2. pk_board.c 的 FOOTPRINT_ROT_DEG 加一行（值从新板 kicad_pcb 实测）
 *      + pk_board_profile_name() 加一个 case
 *   3. Kconfig.projbuild 的 choice 加一项
 *   4. firmware/sdkconfig.defaults.v5
 *   5. tools/firmware_release/prepare_esp32p4_release.py 的 BOARD_PROFILES
 *   6. .github/workflows/release-esp32p4-firmware.yml 的 BOARD_PROFILES 默认值
 *      与 board_profile 下拉项
 *   7. web/flasher/index.html 加一个按钮
 *   8. firmware/test/test_pk_board_mount.c 按物理轴独立推导新板的期望值
 *   如果新板系的 R_板→机体（盒子里的朝向）也变了，那是第 9 处，在 pk_board.c。
 *
 * 三段式分解
 * ----------
 *     R_芯片→机体 = R_板→机体 · Rz(封装旋转) · R_封装→板0
 *
 *   ─ R_板→机体：整块 PCB 在盒子/飞机里的朝向。两个板系共用（同板框、同安装
 *     孔、同堆叠方式）。判据见 R_BOARD_TO_BODY 处的注释。
 *   ─ Rz(封装旋转)：绕板法线的封装摆放角，来自各板系 kicad_pcb 实测。**这一段
 *     是本次冻结的硬件事实**，也是两个板系唯一的差别。
 *   ─ R_封装→板0：封装旋转为 0 时，芯片敏感轴相对封装/板坐标系的指向，来自
 *     原厂手册。每颗器件各一份。
 *
 * 坐标系约定
 * ----------
 *   板坐标系 B（右手系，跟着 PCB 走）：
 *     Bx = KiCad 俯视图向右      By = KiCad 俯视图向上（= -Y_kicad）
 *     Bz = F.Cu 外法线（指向元件面外）
 *   机体坐标系 = 航空 NED：+X 前（机头）/ +Y 右 / +Z 下。
 *
 * 回归测试：firmware/test/test_pk_board_mount.c —— 它从手册轴向、封装旋转和
 * 装配朝向**独立**推导期望值，不复用本文件的任何矩阵；选错 profile 会红。
 */
#pragma once

#include <stdbool.h>

/* 当前支持的板系。v1/v2 不再兼容，已从固件中退出。
 * 同一板系的不同修订共用一个 profile：例如 V4.0 是 V4.3 的返修前身，固件层面
 * 都按 v4 处理（GNSS Gate 飞线返修不改变传感器安装方向）。 */
typedef enum {
    PK_BOARD_PROFILE_V3 = 0,
    PK_BOARD_PROFILE_V4 = 1,
    PK_BOARD_PROFILE_COUNT
} pk_board_profile_t;

/* 板上四颗与安装方向有关的器件。 */
typedef enum {
    PK_BOARD_SENSOR_IMU  = 0,   /* U4 BNO085   */
    PK_BOARD_SENSOR_BARO = 1,   /* U5 BMP388   */
    PK_BOARD_SENSOR_MAG  = 2,   /* U6 QMC5883P */
    PK_BOARD_SENSOR_GNSS = 3,   /* U7 ATGM336H */
    PK_BOARD_SENSOR_COUNT
} pk_board_sensor_t;

/*
 * 当前构建目标板型。来源是显式的 Kconfig 选择，**不是**运行时探测。
 * powered / unpowered 是另一个维度，由 PMIC 探测表达，不在这里。
 */
pk_board_profile_t pk_board_profile(void);

/* "v3" / "v4"，用于日志和诊断页。返回的是**板系**，不是修订号——固件区分不了
 * 同一板系的修订（板上没有 revision strap 或 EEPROM）。 */
const char *pk_board_profile_name(pk_board_profile_t profile);

/*
 * 封装在 PCB 上的摆放角（度，KiCad 约定：正角 = 俯视逆时针）。
 * 这是机械元数据，供诊断页和装配核对用。
 * 注意 BMP388 也有摆放角，但它是标量传感器——这个角**不参与任何数值变换**。
 */
float pk_board_footprint_rotation_deg(pk_board_profile_t profile,
                                      pk_board_sensor_t sensor);

/* ---- BNO085（U4）--------------------------------------------------- */

/*
 * q_body_fix = R_机体→芯片，供 imu_task.c 的 sandwich 右乘：
 *     q_aircraft = q_world_fix · q_bno · q_body_fix
 * 输出顺序 (w, x, y, z)。
 */
void pk_board_imu_body_fix_quat(pk_board_profile_t profile, float q[4]);

/*
 * 把 BNO085 芯片体轴向量（线加速度等）转到机体 NED。
 * 与姿态走的是不同代码路径：向量只做体轴重映射，不做 ENU→NED 的世界系修正。
 * in 与 out 可以是同一个数组。
 */
void pk_board_imu_chip_vec_to_body(pk_board_profile_t profile,
                                   const float in[3], float out[3]);

/* ---- QMC5883P（U6）------------------------------------------------- */
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

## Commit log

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2026-05-15 docs+firmware: onboarding docs, P4 v1.x silicon fix, PFD v2 polish
    Three logical changes bundled because they all surfaced during the
    first real-hardware bring-up attempt on the test board (Waveshare
    ESP32-P4-WIFI6, P4 silicon revision v1.3):
    1. P4 v1.x silicon compatibility (sdkconfig.defaults)
    IDF v6.0.1 defaults the bootloader's minimum chip revision to
    v3.1 (ECO5), which means the bootloader refuses to start on any
    board still shipping v0.x/v1.x silicon. The Waveshare boards in
    our supply chain are v1.3, so we explicitly opt into the v0/v1
    family via CONFIG_ESP32P4_SELECTS_REV_LESS_V3=y and
    CONFIG_ESP32P4_REV_MIN_100=y. NOTE: binary-incompatible with v3.x;
    if a v3 b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
    [main.c]
2026-05-15 firmware+docs: bring-up hardening for Waveshare P4 v1.3 silicon
    First clean steady-state boot on real hardware (P4 v1.3 silicon on the
    Waveshare ESP32-P4-WIFI6). Captured serial:
    I (4417) pilot_kit: PFD render task running
    I (4418) pilot_kit: BLE disabled at build time — UART + file sinks only
    I (4424) main_task: Returned from app_main()
    I (5439) pfd: PFD 32 FPS | roll=+0.00 pitch=+0.00 yaw=0.00 ...
    I (5644) dsp: stream 0.00 MB/s | msgs/s 0 | aircraft 0
    ... (periodic 1 Hz heartbeats sustained)
    Five distinct boot-time crashes had to be unwound to get here, all on
    the path between __libc_init_array() and app_main(). Each one is now
    papered ove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
    [main.c]
2026-05-15 firmware+docs: BLE end-to-end on Waveshare ESP32-P4-WIFI6
    Brings the BLE GATT service up on a brand-new Waveshare board after
    the one-time C6 hosted slave firmware flash. Console steady state:
    I (xxxx) transport: Identified slave [esp32c6]
    I (xxxx) vhci_drv: Host BT Support: Enabled
    I (xxxx) ble_gatt: NimBLE host task running
    I (xxxx) ble_gatt: BLE address 8c:fd:49:0b:5a:8a type=0
    I (xxxx) ble_gatt: advertising as "Pilot Kit Box-0B5A8A"
    `Pilot Kit Box-XXXXXX` is the human-readable advertisement name with
    a per-board MAC suffix (last 3 bytes of the C6 efuse BLE address,
    uppercase hex). Stable across reboots, distinct across boards — so
    multiple Pilot Kit Boxes in the same hangar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
    [main.c]
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2026-05-15 display: switch to TK024F3036 vendor driver + raise TWDT to 15s
    The Holocene TK024F3036 transflective IPS panel uses the ST7789
    driver IC but ships from the factory expecting a specific init
    sequence (porch control 0xB2, VGH/VGL 0xB7, VCOM 0xBB, gamma curves
    0xE0/0xE1, etc.) that the generic esp_lcd_panel_st7789 driver does
    not emit. With the generic driver the chip accepts every SPI
    command we send but never drives the TFT properly — the symptom is
    "backlight on, no content."
    Bring in the supplier's reference panel driver as a local component
    (components/lcd_tk024f3036, Apache 2.0, copied from the vendor's
    ESP32-S3 LVGL demo) and swap display.c to call
    esp_lcd_new_panel_TK024F3036 instea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
    [LCD_TK024F3036.c]
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2026-05-16 firmware+docs: per-subsystem watchdogs, BTN1 tare/cage, LCD on SPI2 IO_MUX direct
    Multi-area hardening pass that turns three previously fragile
    subsystems into ones that recover gracefully on their own, fixes
    several real-hardware bring-up blockers, and adds the first tact
    button (Tare/cage for the BNO085 IMU).
    Bring-up correctness fixes
    --------------------------
    * display: swap from esp_lcd_new_panel_st7789 (generic) to the
    vendor-specific esp_lcd_new_panel_TK024F3036 from
    firmware/components/lcd_tk024f3036. The TK024F3036's transflective
    IPS panel needs porch/VCOM/VGH/VGL/gamma values the upstream ST7789
    driver never emits — without them the chip ACKs SPI commands but
    the TFT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
    [main.c]
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2026-05-20 imu: software tare + ENU→NED sandwich; 3-level TARE gesture
    Mounting/frame fix
    - Sandwich transform: q_aircraft = q_world_fix · q_bno · q_body_fix.
    q_world_fix = (0, √2/2, √2/2, 0) reframes BNO's ENU world reference
    to the aerospace NED that quat_to_euler expects; q_body_fix =
    (0, √2/2, 0, -√2/2) maps chip body axes onto aircraft body for the
    current mounting (chip +X up, +Y user-left, +Z toward-pilot).
    Software tare replaces BNO SH-2 Tare
    - BNO Tare gimbal-locked the displayed quaternion at pitch = -90° when
    composed with the sandwich (raw identity → q_world_fix · q_body_fix,
    not identity). New tare is a left-mul of conj(q_aircraft_at_tare)
    onto the live q_air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
    [main.c]
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2026-05-21 pfd+ui: runtime own-ship binding via TARE in ADS-B list
    User wanted to bind the highlighted aircraft as own-ship on demand
    for debug — much faster iteration than rebuilding with a new
    CONFIG_PK_OWN_ICAO each time. New gesture:
    1. MODE → cycle to ADS-B list view
    2. UP/DOWN → highlight the target aircraft
    3. TARE short-press → bind it as own-ship
    4. MODE → back to PFD; ALT/VS/GS now drive off that ICAO
    Re-pressing TARE on another aircraft replaces the binding; power
    cycle clears it (no NVS write).
    Implementation:
    - ui_state: new pk_ui_set_own_icao / pk_ui_get_own_icao with a
    s_own_icao_set flag distinguishing 'user bound' from 'use Kconfig
    default'. Lock-protected like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
    [main.c]
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2026-05-21 ui_state+adsb_list: track list selection by ICAO, sort snapshot
    Two coupled changes to keep the highlight stuck to the same aircraft
    across refreshes:
    - aircraft_state_snapshot() now qsorts the output by ICAO24. The hash
    table's scan order shuffled whenever an aircraft entered or left the
    trailing-60s window, so the row at index N was a different aircraft
    on successive frames and a user reading "row N's altitude" would see
    it appear to jump between unrelated planes' altitudes.
    - ui_state's list cursor moves from index-based to ICAO-based.
    pk_ui_list_scroll() now buffers a pending delta; the renderer calls
    pk_ui_list_resolve_row(icaos, n) once per frame, which:
    1. locates th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
    [main.c]
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2026-05-31 feat(gps): GT-U8 positioning + own-ship GPS fallback + GDL90 ownship
    Add gps_task (UART1 @9600, minimal RMC/GGA NMEA parser) and own_ship
    resolver (manual ADS-B binding > GPS fix > none). PFD and ADS-B LIST
    read own-ship through the resolver so an unbound device uses real GPS
    position for relative bearing/distance. ble_gatt emitter now sends a
    GDL90 Ownship Report (0x0A) and reflects real GPS state in Heartbeat
    gps_valid. Builds clean; runtime/serial verification pending hardware.
    [main.c]
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2026-06-09 feat(settings): adjustable QNH + NVS, feed baro altitude (plan Task 9)
    - New config_qnh.{h,c}: pk_qnh_get/set/load, NVS blob under pkbox/qnh,
    clamped [950,1050] hPa, volatile float for lock-free baro reads
    - settings_page.c: two-row UI (Language / QNH) with cursor highlight;
    selected row shows bright-cyan edge strip, unselected shows dim strip
    - settings_page.h: expose pk_settings_cursor_next / pk_settings_cursor_row
    - main.c: TARE→cursor_next; UP/DOWN drive lang-toggle or QNH±0.25 hPa
    depending on cursor row; pk_qnh_load() called before pk_baro_start()
    - baro_task.c: replace static QNH_PA=101325 with pk_qnh_get()*100 each loop
    - CMakeLists.txt: add config_qnh.c to SRCS
    [baro_task.c, main.c]
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2026-06-09 fix: bug-review fixes — GPS VS masking, uninit own-ship, vs_ema reset, cross-task races, NVS init guard
    [baro_task.c]
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2026-06-10 feat(traffic_page): UP/DOWN 选目标 + 底部机型/高度详情条
    - 目标按距离排序, 复用 pk_ui_list_scroll/resolve_row 按 ICAO 跟踪选中
    - 选中白色高亮 + 呼号; 与 ADSB_LIST 共用同一 selection
    - detail bar: 机型(code+desc) + 注册 + 绝对高度/地速/距离/磁方位(照 adsb_list)
    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
    [main.c]
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2026-06-10 fix(baro): VS jitter — float-altitude differentiation + deadband + 50fpm step
    实物验证发现 baro VS 一直乱跳。根因:alt_ft 量化到整数后微分,单 ft
    量化抖动 ÷0.1s = ±600fpm 噪声,EMA(0.2) 压不住。修:
    - 改用浮点高度 alt_ft_f 微分(消除整数量化噪声,最大元凶)
    - EMA 0.2→0.1(更强平滑,时间常数 ~1s)
    - deadband 50fpm(平飞显 0,不微抖)
    - 显示量化到 50fpm 步进(不末位跳)
    [baro_task.c]
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2026-06-10 fix(baro): enable BMP388 IIR filter (root cause) + altitude LPF/hysteresis
    实物高度在 363↔364 跳的根因:BMP388 CONFIG 寄存器(0x1F)从未配置 →
    IIR 滤波默认 bypass → 输出未滤波的原始气压噪声。气压链路上零滤波。
    defense-in-depth 三层(同根因):
    - BMP388 硬件 IIR coef 15(CONFIG=0x08):传感器层抑制气压噪声(根因修复)
    - 软件高度低通 EMA(alpha 0.2):补充
    - 显示滞回(偏离 ≥1ft 才跳档):消除整数量化边界来回抖
    - VS 改用平滑高度微分,不再微分噪声
    上一版只给 VS 加 EMA/deadband 是治标:VS 微分的高度本身仍是噪声。
    [baro_task.c]
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2026-06-10 feat(diag): 诊断页可滚动 + GPS 多行/SNR柱状图/系统时间
    照抄 about_page 的滚动机制给诊断页加 UP/DOWN 翻页(切到 DIAG 自动归零)，
    不再受单屏行数限制。
    - GPS 区扩为多行：fix/HDOP、可见星+最强SNR+天线状态(着色)、坐标
    - 每颗可见星的 SNR 柱状图(绿≥35 / 黄25-34 / 红<25 dB)
    - TIME 行接系统墙钟：UTC(Zulu) + 本地(UTC+8) + 来源(GPS/GPS~/BLE/iOS)，
    替换原来写死的占位符
    [main.c]
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2026-06-11 feat: add transient toast UI for TARE and own-ship binding status with localized strings
    [main.c]
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2026-07-28 feat(ui): Toast 迁到控件层，脱离旧 CJK 位图字库
    此前 toast 是在 framebuffer 上自己画一个框（pk_pfd_fill_rect + 旧 CJK 位图
    字体），与 PFD 同层。两个问题：
    1. **会被 dock、FAB 盖住**——而 toast 恰恰是最该盖住别人的东西。现在画在
    控件层并 move_foreground，dock 展开时弹出的提示也看得见。
    2. 它是 text_font_cjk*.c（190 KB 那批）的调用点之一。旧字库的退役就卡在这类
    零散调用点上，逐个迁完才能删——本次迁走后 pfd.c 已不再引用 text.h /
    text_font_cjk.h，两个 include 一并删掉。
    生命周期仍归 ui_state 的 pk_ui_toast_get()：它带时间戳且线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
    [main.c]
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2026-07-28 feat(touch): 接入 GT911——在此之前这台机器一个输入设备都没注册过
    dock、FAB、二级页面的三条退路在真机上全是死的：pk_ui_nav.c 里那些
    lv_indev_active() / lv_indev_get_vect() 取的是「当前正在上报的输入设备」，
    而 lv_indev_create() 从来没被调用过。上一个 commit 把回调接上了，但没有
    输入源，回调永远等不到事件。
    按实物原理图（docs/hardware/board_pinout-zh_CN.md §GT911）：SDA GPIO7 /
    SCL GPIO8 与 BNO085、BMP388 共用 I²C0（走既有的 pk_i2c0_bus_get()），
    RESET GPIO23，INT GPIO2 但 **R35 默认不贴**。
    INT 不贴带来两个非可选的后果：
    1. 只能轮询，不能中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
    [baro_task.c, main.c]
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2026-07-28 fix(hosted): 握手排到点屏之前——DSI PHY 抢 LDO 会让 C6 起不来
    4.3″ 屏迁移后整机 26 秒一重启。症状极具误导性：SDIO 物理层全好——CMD5、
    CIS、Function 1 就绪位 IOR=0x06、块大小 512、4-bit 协商 BUS_WIDTH=0x42
    一个不缺——但主机在 "Waiting for esp_hosted slave to be ready" 上死等，
    13 秒超时后复位重试，撞上 failed to read registers，hosted 自己把整机重启。
    看起来像 C6 没烧固件，其实固件好好的：应答卡层命令的是 SDIO **外设**，
    它早就绪了；跑不起来的是上层固件，所以永远发不出 INIT event。
    排除法，每一步实测：
    esp_hosted 2.12.11 → 2.12.7（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
    [main.c]
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2026-07-29 fix(diag): 详情页顶栏空成一片黑；把诊断页纳入模拟器（本该一开始就做）
    罩哥问"难道你不会用模拟器抓图对比吗"——问到点子上了：**诊断页从来没进过
    模拟器**。前面几页都是截图对比着改的，唯独这页我连着四轮全靠猜几何，
    猜错三次（BACKBAR_H 猜成 36、标题横着躲、标题挪到 backbar 下方），还删过
    一次 render 函数。
    纳入模拟器后一张图就看清了：详情页**不画顶栏**，而 backbar 浮在 y=54，
    于是 0..48 那条整个空着——真机上就是罩哥说的"title 上面有大量 padding"。
    改法：子系统名画回顶栏，位置与总览页的 "DIAGNOSTICS"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
    [main.c]
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2026-07-31 fix(display): 点亮度 LOW 直接关屏；档位与高亮各说各话
    罩哥真机实测「点击背光亮度设置的时候，整个屏幕灭了」。查出来是两个 bug 叠在
    一起，根子都是**同一个量被当成两种语义**。
    **其一：段序号被当亮度值。** pk_display_set_brightness() 收的是 0..255 线性
    亮度（display.c:152，duty = level*1023/255），而设置页把分段控件的段序号
    （0..3）直接传了进去——点 LOW(v=0) 就是 level=0，而 power.c:83 正是用 0 关屏
    实现软关机的。（顺带确认：背光 PWM 的 output_invert=1 是硬件侧低有效的补偿，
    API 语义没被绕反，0 就是灭。）
    **其二：读回来的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
    [main.c]
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2026-07-31 fix(ui): 中文偏小的两个根因；交通页标签防遮挡；关于页可滚；删小屏字体
    ## 中文比英文偏小——原注释观察对，推论反了
    gen_pfd_aa_font.py 里 CJK_PT_RATIO=0.92 的理由写着「pt21 时 B612 的 A 高 17px、
    Noto 的『调』高 19px，汉字字面更大，同 pointsize 混排会显得大一圈」。观察没错，
    但那个高度差**正是两款字体被设计成能同尺寸混排的方式**——实测 B612 Mono cap
    ≈0.75–0.87 em、Noto Sans SC 汉字字面 ≈0.89–0.91 em，同 em 混排时汉字本就该比拉丁
    cap 高 16–18%。压到齐平，中文就整体小一档。与上一轮 backbar 那次同源：
    **标称 px 在不同字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
    [main.c]
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2026-07-31 fix(ui): 无数据态系统性排查——PFD 无 IMU 竟在画一幅完美地平线
    罩哥真机发现「无本机位置」几个字被挡住，并给出一条准则：
    > 你在测试截图的时候，除了做"极端的大数据"外，还要做"极端的无数据"
    照做之后挖出的东西比那句话被挡严重得多。
    ## 最严重：PFD 无 IMU 时照常画水平地平线
    valid=false 原来只是把 roll/pitch 取 0，然后**正常渲染**——于是屏上是一幅完美
    水平的姿态仪，底部罗盘还把 N 摆在机头正上方。这不是"看起来像坏了"，是反过来的
    "看起来好好的、其实什么都不知道"。航空设备上这会害人：瞥一眼平的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
    [main.c]
2026-07-31 fix(traffic)+feat(settings): 目标机头方向修正；设备名可改；PFD 标签去缩写
    两个 agent 并行完成，文件范围分开，共享的 i18n catalog 双方 key 已确认共存。
    ## 交通页目标剪影朝向恒为 0——防撞信息一直是错的
    draw_target() 写的是 heading_deg - (screen - rel_bearing)，而该分支中
    screen ≡ rel_bearing，减法恒为 0。而 pfd_hsi_traffic.c:201 **本来就是对的**
    （rot = (heading_deg - mag_var) - yaw，注释里有正确推导）。所以同一架飞机在两页上
    机头差 74.6°：实测 CSN9999 真航迹 175°，PFD 罗盘画朝右偏下（对），交通页画朝正下（错）。
    目标朝向是判断「迎面/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
    [main.c]
2026-07-31 fix(ble): 用户改了名就不留 MAC 尾巴；上限 10 → 26
    罩哥验收：「用户既然选择了改名字，那就让用户彻底把名字改掉，你总留个小尾巴算什么
    意思？对于该放宽长度，那就放好了」。
    原来无条件拼 `-AABBCC`。MAC 后缀只解决「所有设备同名」这一种情况，而那正是**出厂
    默认名**的处境；用户一旦自己命名，唯一性已由他保证。且 BLE 连接认地址不认名字，
    扫描结果本来就带 MAC——后缀在自定义名下纯属把用户的名字挤到一边。
    未设置 Pilot Kit Box-AABBCC 保留后缀（逐字节与本功能上线前一致）
    设了名 <用户输入>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
    [main.c]
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2026-08-01 feat(aero): SD 卡航空数据库——加密 bin 懒加载 + 诊断页状态卡
    开机零阻塞是定案：init 只建 prio2 后台任务，SD 挂稳 + 5s 静默期后
    才分块 fread + PSA 流式 AES-CTR 解密 + SHA-256 校验（9.88 MB 实测
    7.7s，被 PFD 压着是不挡渲染的代价）。reader 为纯 C11 零堆分配实现，
    已与 Python 生成器 1200 ICAO / 1100 nearest / 550 FIX 用例对拍 100%，
    真机 ZGGG 自检 10 跑道/63 频率 PASS。
    nearest 只暴露 approx 粗排（exact 东京最坏区 46ms 会卡帧，approx
    14.3ms）；ERROR 态不反复重读坏文件，拔卡重插才重试；dev key 拆分
    异或存放，量产强度靠 flash encryption（另行决定）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
    [main.c]
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2026-08-01 fix(ui+touch): 列表页右侧空白，连带挖出的三个根因
    「列表页右侧一大块空白」顺着改下去连爆三个问题。它们是一条因果链，
    每修掉一个才暴露下一个，拆开任何一半都不成立。
    1) 右侧 76 px 常驻空白 = 版面在给 FAB 让位
    CONTENT_R 退到 716（FAB 左缘 728 再让 12），于是左 8 右 76 的不对称
    版面。而 FAB 只有 56×56、纵向只压得住一行，为它牺牲的却是全屏高度
    × 76 px。产品决策：FAB 就是浮在内容之上的，页面不为它调整版面。
    右缘改回 PK_DISPLAY_W - PAD_L = 784，收回的 68 px 均摊给八个格子
    （列间距 8 px → 8~22 px）。列的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
    [main.c]
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2026-08-02 feat(aero): 地图叠加机场/导航台/FIX——分色符号 + 罗盘玫瑰 + 标签避让
    渲染禁止碰 pk_aero_db：nearest 最坏 16 ms 而每帧只有 33 ms 预算。后台
    任务查好写进 PSRAM 双缓冲快照，render 无锁读；视图坐标用 1e-7 定点传，
    RV32 上 double 两条访存会撕裂成上半新下半旧的假坐标。
    符号与标签分两趟夹住 ADS-B——符号垫在飞机下（层级），标签排在呼号后
    （优先级）。这个顺序是从截图倒推出来的：原来一趟画完，机场标签把 5 个
    呼号全挤没了。交通信息优先于机场位置，机场标签丢了符号还在。符号本身
    也登记进占位池，但只能在标签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
    [main.c]
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2026-08-02 feat(search): 航空数据搜索页——代码/名称查机场导航台FIX，点结果跳地图
    模态层而非 pk_ui_mode_t：dock 第 8 个页签会撑到 852px 超屏宽，导航也只有
    两层。键盘的弱符号回调改成函数指针——原来把"只可能从设置页打开"这个当时
    的事实写死进了分派，搜索页从地图页打开就再也覆盖不到。
    分桶：ICAO 精确 → 机场 key 前缀 → 导航台 ident → FIX ident（全是 µs 级
    二分）→ 子串。**桶 5 只在前 4 桶零结果时才跑**：设计阶段按 Mac 外推估
    65ms，真机实测最坏 1088ms，差一个数量级；不收紧的话敲 ZGGG 明明微秒级
    命中还要再等一秒。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
    [main.c]
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2026-08-02 feat(map): 点地图机场符号进详情页 + 搜索结果方向箭头
    命中测试的候选来自图层已发布的快照，不查库——nearest 最坏 16 ms，而
    触摸回调跑在 pfd 任务上。容差 28 px 取 App 那套 20–28 的上限（GT911
    抖动比手机大），规则是"先在容差内找机场取最近，一个机场都没有才看导航台
    和 FIX"——密集区想点机场却中了旁边航路点是最烦的。
    放在 touch_up 而不是 touch：FAB 放行、s_press_active、按钮命中这三处
    闸门都在 touch() 里够不着，按压归属那一行一个字没动。
    栈是这里的设计约束而不是内存：触摸 read_cb 跑在 pfd 的 6 KB 栈上，
    第一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
    [main.c]
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2026-08-02 fix(i18n): 词条 ID 改由台账永久钉死——修真机徽标显示成别条文案
    事故：演示模式徽标在屏幕上显示成「(数据为模」，而它该显示「⚠ 演示」。
    因果链——给 catalog 中间插词条会让后面的枚举整体后移（实测
    DEMO_BADGE 62→63）；而两个 session 共用 firmware/build/ 并行构建，
    ninja 依赖跟踪失准、pk_ui_nav.c.o 没重编，仍按旧 ID 62 取文案，字符串表
    却已是新的（62 号变成了 SETTINGS_DEMO_HINT）。于是徽标拿到「(数据为模拟)」，
    再被 32 字节缓冲截断。
    **编译零警告、烧录校验通过、串口日志正常，全程静默**——是用户肉眼在屏幕上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
    [main.c]
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2026-08-02 fix(sim): 固定 esp_timer 桩 + 修正 DIAG_OK 场景的 GPS 新鲜度语义
    a2d9d58 冻的是墙钟，单调时钟这一路漏了：compat/esp_timer.h 把
    esp_timer_get_time() 实现成 CLOCK_MONOTONIC，也就是这台 Mac 开机至今
    （实测约 1574399 s），每次跑都不同。两个后果：
    1. 截图不确定。nav_grid_page.c 的截图钩子 sim_setup() 先记
    s_press_us = now - 长按时长*70%，render 再算 now - s_press_us，两次取
    now 之间隔着 LVGL 初始化，这段耗时每次不同，调平填充的边界就在整数像素
    上抖。实测 ui-4.3-menu-level.png 与 HEAD 差 2×87 px @ (186,393)——正是
    填充右缘那两列，反推出 HEAD 那张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
    [main.c]
2026-08-02 feat(rec): ADS-B 与本机数据落盘——按机可检索 + 1Hz 航迹 + 注入式自检
    设计稿 内部设计文档（评审拍板：
    单文件+按机索引 / 1Hz 合并本机航迹 / 开机即录+相位标记 / 自检与单测都要 /
    文件挪出 SD 根目录）。分三阶段落地：
    阶段1 纯 C 可测层
    - pk_rec_format: 32B 文件头 + traffic.trk(32B 位置/身份) + traffic.idx(40B)
    + own.trk(48B 采样/时间修正)。逐字节手拼小端，全程无结构体 cast——P4 是
    RISC-V，非对齐访问会 panic；单测用手写期望字节数组 memcmp，把偏移表焊进测试
    - pk_flight_phase: 6 态状态机 + 60s 位移窗口 + 5 类机型阈值。推出不能只看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
    [main.c]
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2026-08-03 feat(hw): 4.3″ 罗盘校准页可用化 + I²C0 总线级恢复 + SDR 内存修复
    扩展板接上后的一轮真机联调，三件事互相牵连，拆开会做出编译不过的中间态。
    ## 罗盘校准页（4.3″ 适配 + 终于能退出了）
    cal_wizard.c 还是 320×240 时代的硬编码坐标，在 800×480 上全挤在上半屏。
    按 about/diag 两页的栅格重排，字体从只剩它一个用户的 text.h 位图字迁到
    pfd_aa_text；图 8 半径由「顶栏下沿→说明文字上沿」倒推得 R≈180。
    更要紧的是它**退不出去**：ui_state.c 只要看到 acc=0 连续 10 s 就强制切进
    这一页，进入后计时器清零、acc 仍是 0 就重新计时。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
    [baro_task.c, main.c]
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2026-08-03 fix(ui): 罗盘校准别再反复弹——闸门加滞回 + 相位门控 + 磁干扰识别
    真机在机场那种强磁环境里，校准向导约 13 秒就把用户拽回去一次，点「稍后
    再说」也没用。根因不是阈值调得紧，是 ui_state.c 的这条判据在抖动信号上
    根本不成立：
    } else if (valid && accuracy >= UI_CAL_WIZARD_EXIT_ACCURACY) {
    s_cal_auto_suppressed = false; // 单帧 acc>=2 就解除闸门
    而 pfd.c 每帧都调 tick（30+ FPS）。accuracy 取自 BNO085 Rotation Vector
    报文的 status 位，机坪/机库/GPU 电源车附近它会在 0↔1↔2 反复跳——抖到 2
    一帧，用户刚按下的「稍后再说」当场作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
    [main.c]
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2026-08-07 feat(hw): 扩展板 v3.1 — 4层→6层转换，解决 DCR/GND 老问题
    从 expansion-board-v1 HEAD 33e6b9c 干净基线拷贝独立工程到
    hardware/expansion-board-v3.1/，不动 3.0 与 v3-layout-only。
    叠层改为 SIG-GND-SIG-SIG-GND-SIG（F.Cu / In1.Cu完整GND / In2.Cu信号 /
    In3.Cu信号+3V3_DIG / In4.Cu完整GND / B.Cu），4 走线层 + 双 GND 平面。
    JLC06161H-7628 六层 50Ω 微带 ≈0.35mm，与四层 0.34mm 基本一致。
    规则修复（codex/claude 两段 session 查明的历史 bug）：
    - min_via_annular_width 0.1→0.15（嘉立创绝对下限，原值让 DRC 查不出）
    - zone min_clearance 0.5→0.15（GND 接不上覆铜的真因，比规则严 3 倍）
    - D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
    [expansion-board-v1.kicad_pcb, expansion-board-v1.kicad_sch, interface.kicad_sch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]
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2026-08-08 fix(hw): 修掉会把短路写进板子的碰撞判定 bug；In3 锁电源平面，3V3 未连通 6→0
    ## 一、碰撞判定漏判交叉 —— 会真的短路，最要紧
    route_fix 判两条走线冲突用的是"四端点到对方线段距离取最小"。这个公式对
    **交叉**的线段返回正值：两条线真穿过彼此时，四个端点离对方线段都可能很远。
    实测它布出来的 SWDIO：
    SWDIO (104.890,91.253)→(104.890,92.353) 垂直
    SUBG_CSN (122.332,91.980)→(103.615,91.980) 水平
    交点 (104.890,91.980) 落在两段内 —— 真短路
    公式却算出 0.3733mm、余量 +0.07mm，判为合规
    seg_seg_dist 加叉积跨越判定，相交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
    [expansion-board-v1.kicad_pcb]
2026-08-09 fix(hw): 射频精修补两个漏判；试"射频先布"流程，结论是不如 plain（17 vs 16）
    ## 两个真 bug（跟流程选择无关，必须修）
    1. **漏了 U.FL 自带禁布区**。route_rf_manual 自建局部占用图，只收了
    pads/trks/vias——而 snap_obstacles() 不返回 footprint 的 Zones
    （route_fix 只在建全局图时处理，见 route_fix.py:216「谁都不许走」）。
    结果射频线直接从天线口连接器身上压过去：实测 4 条 items_not_allowed +
    3 条 solder_mask_bridge，全在 J2/J6/J8 三个 U.FL 上。补上后
    ANT1090_EXT 那段从直穿 4.15mm 变成绕行 7.55mm。
    2. **一条网络只布一个缺口就收工**。射频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
    [expansion-board-v1.kicad_pcb]
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2026-08-09 feat(hw): 两脚元件按"最近引脚"定朝向——真缺线 12→4，RF 残线 6→2
    评审看图指出的：很多问题不是走线本身，是 L/C 摆放时两个脚的朝向根本没考虑要连
    到哪儿去，"很随意就摆了"。结果本该最短的连接反而绕远，还把旁边通道堵死。
    查证属实：PLACEMENT.py 里几乎所有 0402 都是 0°，从来没排过朝向。
    ## orient_opt.py
    两脚无极性件（R/L/C）转 180° 电气上等价，但朝向决定走线是短直还是绕过元件本体
    再拐回来。判据就是"最近引脚"：
    当前成本 = |pin1 → net1 最近的外部焊盘| + |pin2 → net2 最近的外部焊盘|
    翻转成本 = |pin2位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
    [expansion-board-v3.1.kicad_pcb]
2026-08-09 feat(hw): 飞线体检工具；未连通 12→11、真缺线 4、铜层 DRC 仅剩 1 项非致命
    产品要求："电路板讲求流水，能否通畅就看水管走向歪没歪。原先脚本把所有元件按网格排，
    但画 PCB 不是网格是血管，讲求头对脚、脚对头，网格式的头对头脚对脚除了好看一无是处。"
    ## ratsnest_diag.py —— 把"歪没歪"量化
    布线**之前**只看布局，算两个指标：
    · 飞线长度：每个网络的最小生成树总长。某条 MST 边特别长 = 这两个焊盘该靠近却
    离得老远，是位置摆错（不是朝向问题，朝向最多差一个元件长）
    · 飞线交叉：不同网络的 MST 边互相穿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
    [expansion-board-v3.1.kicad_pcb]
2026-08-10 fix(hw): 挡路的是 GND 缝合过孔不是信号线——删 2 个，I2C_SDA 通了，真缺线 4→3
    评审看图判断"还是可解的"，查证属实，但可解的原因和我先前判断的不一样。
    ## 挡路者盘点（route_fix 点名 + 连续几何算余量）
    SUBG_X48N 缺口 11.80mm 挡：SUBG_VDDR 走线 余量 **+0.227mm**
    I2C_SDA 缺口 6.68mm 挡：GND 走线/过孔 余量 **+0.114mm**
    DEMOD3 缺口 28.19mm 挡：DEMOD2 过孔 余量 **+0.067mm**
    SUBG_RXTX 缺口 7.51mm 挡：SUBG_RFN 走线 余量 **-0.181mm**
    前三条余量是**正的**——几何上过得去，是 route_fix 的 0.15mm 栅格抓不住
    0.07~0.23mm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
    [expansion-board-v3.1.kicad_pcb]
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2026-08-11 fix(hw): 查明 GND 未连通真身是 EP 没打散热过孔；FL1/FL2/U13 已补，U8/U10/U11 被内层走线堵死
    ## 那两条查不出来的 GND 未连通
    DRC 报 "Zone[GND] on F.Cu ↔ Zone[GND] on F.Cu"（**同一个 uuid 出现两次**，
    是 zone 内部两块铜不连通）和 "F.Cu ↔ In4.Cu"。查了几轮：
    · 加 325 个网格缝合过孔 → 没解决，还引入 4 条禁布区违例（工具漏检 U.FL keepout），已回退
    · 逐块查"有没有 GND 焊盘" → 0 块孤岛，方向错了
    真身：**SMD 焊盘不穿层**。F.Cu 上有两块 GND 铜只connect 到 SMD 焊盘、没有任何通孔，
    所以既连不到同层其他铜、也连不到 In4 地平面。位置一查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
    [expansion-board-v3.1.kicad_pcb]
2026-08-11 fix(hw): IFA 天线下方 In3/In4 满铺铜 — 4→6层转换漏掉的禁铜层，天线本来会失效
    ## 评审提问"IFA 的 GND 要不要大面积接地和打孔"，查出来一个真缺陷
    IFA 辐射体铜箔**正下方**采样 1541 点，逐层看有没有铜：
    In1.Cu 5.8% ✅ In2.Cu 0.0% ✅ B.Cu 5.8% ✅
    In3.Cu 100.0% ❌ 满铺 3V3_DIG 电源平面
    In4.Cu 100.0% ❌ 满铺 GND 平面
    天线正下方铺地/铺电源，等于把辐射短路掉 —— IFA 基本不工作。
    根因：ANT1 封装自带的禁铜区只写了 `F.Cu / In1.Cu / In2.Cu / B.Cu` 四层。
    **这个封装是 4 层板时代画的**（那时正好就这 4 层），9117b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
    [expansion-board-v3.1.kicad_pcb]
2026-08-11 feat(hw): EP 散热过孔 8→54 个 —— 挡路的一半是内层走线，另一半是我把锡膏当成了铜
    评审质疑"U8/U10 是板上最大的芯片，打 4、5 个孔都没问题"。**他是对的，而且
    我上一版给出的理由只对了一半。** 两个独立原因叠在一起：
    ## 真因①：内层走线从 EP 底下横穿（已修，export_dsn 加 EP keepout）
    散热过孔是**通孔，穿透全部 6 层**，而之前从没给 EP 在内层留过地方。
    freerouting 于是把 In2/B.Cu 的线直接从 EP 底下穿过去。
    修法与射频 keepout 同一机制：EP 焊盘 bbox 外扩 0.05mm，在 **In2/B.Cu 生成禁布区**。
    不锁 F.Cu——EP 四周的引脚要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
    [expansion-board-v3.1.kicad_pcb]
2026-08-11 fix(hw): route_fix 三个错判 —— 真缺线被当碎铜、过孔尺寸写死、障碍过孔按常量算
    未连通 8 → 5，铜层 DRC 回到 0 致命项（仅剩 1 项 starved_thermal 非致命）。
    三个 bug 是查上一条 commit 留下的"未连通 3→8"时挖出来的，彼此独立。
    ## ① 真缺线被误判成"孤立碎铜"，永远没人去布
    load_jobs 原来的分类判据是「DRC 报的两端里有没有 Pad」：
    (need if "Pad" in kinds else orphan).append(...)
    于是 Track↔Track、Via↔Track 一律归为 orphan（该删的断头铜）。
    实测漏判：**3V3_RF 有两处缺口跨 26mm 和 10.7mm**，两端各自都连着一大片铜和
    焊盘——那是"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
    [expansion-board-v3.1.kicad_pcb]
2026-08-12 fix(hw): EP 禁布区按孔阵反算而非整块铺 —— 未连通 5→2，铜层 DRC 归零
    评审提问"几个 U 的禁布需要这么大面积吗"。**不需要，我没论证过就按整个 EP 铺了。**
    查了业界通行做法（Microchip AN4498 / Infineon AN72845 / TI SLOA122 口径一致）：
    QFN 的 EP 用 9–25 个 Ø0.3–0.33mm 孔，间距 1.0–1.2mm
    而我打的是 U10 **33 个、间距 0.8mm** —— 孔数超上限、间距也比推荐密。
    0.8mm 是"物理上最密能排多少"，不是"该排多少"。热需求这边：CC1312R 发射态
    约 82mW、RP2040 满载约 100mW，这个量级下 16 个孔和 33 个孔的热阻差别没有工程
    意义；密排反而在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
    [expansion-board-v3.1.kicad_pcb]
2026-08-12 fix(case): 凸字改凹字达标 + admesh 修法线消「反向三角面」
    JLC 人工审核反馈凸字壁厚太薄（凸起0.4/笔画0.36，要求树脂≥0.8）。
    同时 JLC 自动校验报「反向三角面」阻塞下单。
    真因定位（实测，非推测）：
    - 「反向三角面」根因是 OpenSCAD CGAL 导出 STL 时 93 个 facet normal
    值与几何法线方向不一致（凸字/凹字版均93，模型固有，非字体引入）。
    非零面积退化三角形（admesh 不认，无实际影响）。
    - admesh 是 JLC 同款校验引擎，--normal-directions --normal-values
    修后幂等检查=0，即 JLC 校验可过。
    改动：
    - scad：labels() 凸字(emb_h0.4/sz1.8) →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
    [pilot-kit-box-43-base.scad, pilot-kit-box-43-base_v2.obj, pilot-kit-box-43-base_v2.stl]
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2026-08-13 feat(hw): 手工布通全板 —— 未连通 0 / 铜层 DRC 0，并修复丝印丢失
    评审重新布了一次线并做了美观度调整，把我补不了的四处全解决了：
    BIAS_EN_1090 48mm ／ SUBG_MISO 41mm ／ DET_INLO 24.7mm(射频，不能换层)
    RP_1V1 那个被 DEMOD3 横穿封死的 B.Cu 覆铜裂口
    走线 1399 段（+71）/ 过孔 453 个 F.Cu 956 In2.Cu 293 B.Cu 150
    射频 164 段全 F.Cu、0 过孔，In1 参考面完整
    飞线总长 2677.9mm（zero 2798.7） ERC 28 项、致命 0
    ## 顺带查出一条流程漏洞：板级丝印每跑一次流程就丢一次
    评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
    [expansion-board-v3.1.kicad_pcb]
2026-08-13 fix(hw): 固化工具在"固化"时改了数据 —— 修完才第一次做到 100% 复现
    手工重排了 82 个位号，要求固化。一固化就暴露出这条链上**四个**漏洞，
    每一个都会让人工调整悄悄消失。修完之后 rebuild 复现比对：
    走线 1399/1399 ✅ 过孔 453/453 ✅ 板级文字 11/11 ✅
    位号坐标不一致 0 ✅ 元件坐标不一致 0 ✅
    未连通 0 / 铜层 DRC 0
    丝印 overlap 38 → 2，over_copper 35 → 1 ← 评审手排的效果
    ## 漏洞一：PLACEMENT.py 存了位号坐标，gen_pcb 从来没读
    `PLACEMENT.py` 一直有两张表：`PLACEMENT`（元件）和 `SILK_REF`（位号），
    `export_placement.py`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
    [expansion-board-v3.1.kicad_pcb]
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2026-08-13 fix(hw): BOM 重做成真正的购物清单 —— 39 项，已买的全部剔除
    评审否掉第一版："你出的这个文件更加像是给我内部看的，而不是给淘宝卖家的。
    你里面备注太详细了，用在什么地方、必买之类的，根本不需要给卖家。
    这不是一份购物清单。"
    他说得对。第一版有采购等级、用途分类、位号、板上用量 vs 建议采购的对照、
    避坑说明的来龙去脉——**那是设计视角**，卖家看到只会看不懂或者报错价。
    ## 现在只剩卖家报价需要的五列
    型号/规格 | 封装 | 数量 | 立创料号（参考） | 规格要求
    「规格要求」压到一句话，只留*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
    [BOM_采购清单.xlsx, BOM_采购表.xlsx]
2026-08-13 fix(hw): 板子版本号 V1 → V1.0，重出 Gerber
    产品要求：「板子的版本号是 1.0，改过来，然后重新生成 Gerber」。
    改了三处，缺一处版本号就会不一致：
    tools/gen_silk.py BOARD_REV 离线排版工具
    tools/gen_brand_silk.py BOARD_REV 流程里补品牌丝印用
    tools/SILK.json 'V1 2026-08' → 'V1.0 2026-08'
    **SILK.json 才是板子的真正来源**——rebuild 从它复现板级文字，
    只改两个脚本的常量而不改它，跑一次 rebuild 版本号又变回 V1。
    验证：rebuild 后板上 B.Silkscreen (100.0,80.0) 是 'V1.0 2026-08' ✅
    未连通 0 / 铜层 DRC 0 / 丝印 1+1+2（与改版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
    [expansion-board-v3.1.kicad_pcb]
2026-08-13 fix(hw): 板子版本号改为 V3.1（上一版写成 1.0 是错的）
    板子从工程名到目录名都是 v3.1，丝印上写 V1.0 对不上。
    改的还是那三处（缺一处，跑一次 rebuild 就退回去）：
    tools/gen_silk.py BOARD_REV
    tools/gen_brand_silk.py BOARD_REV
    tools/SILK.json ← 这个才是板子的来源，rebuild 从它复现板级文字
    验证：板上 B.Silkscreen (100.0,80.0) = 'V3.1 2026-08'
    未连通 0 / 铜层 DRC 0 / 丝印 1+1+2（与改动前一致）
    Gerber 已重出。
    [expansion-board-v3.1.kicad_pcb]
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

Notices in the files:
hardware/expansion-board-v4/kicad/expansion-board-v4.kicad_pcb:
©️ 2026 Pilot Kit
